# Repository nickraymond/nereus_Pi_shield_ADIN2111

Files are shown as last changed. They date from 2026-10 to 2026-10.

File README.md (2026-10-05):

# nereus_Pi_shield_ADIN2111

A Raspberry Pi Zero 2W shield built from a copy of the Sofar Bristlemouth mote:
ADIN2111 two-port 10BASE-T1L with PoDL, powered from the bus, 5 V for the Pi,
a 24 V payload port, and the Sofar mote's power path unchanged except the payload load switch (D17) (~20 W absolute
max, 890 mA per port inductor at 24 V; 50 W in a later revision). Potted.

Claude Code does the schematic capture, up to a design-review package. Nick
reviews, lays out, routes and brings up the board.

## Folders

```
nereus_Pi_shield_ADIN2111/   live KiCad 9 project — open the .kicad_pro
docs/                        spec, tracker, design log, power-path study
docs/design-review/          ERC, netlist, PDF and the review package
KiCAD_reference_designs/     BM mote 000639-AB, UrchinCam (read-only)
Archive/                     earlier iterations, junction fix (read-only)
pi-shield-checklist.html     shared visual view of docs/TRACKER.md (open in a browser)
```

## Working on it

- Agents: start with `CLAUDE.md`, then `/agent-entry`.
- People: `docs/TRACKER.md` shows where things stand; `docs/SPEC.md` says what
  we're building and why.
- Close KiCad before an agent edits the project.

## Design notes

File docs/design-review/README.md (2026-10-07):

# Design-review package — nereus Pi shield (ADIN2111)

**Board:** nereus_Pi_shield_ADIN2111 · **Part number:** PCB-000001-AA · **Rev:** AA
**Based on:** Sofar Bristlemouth mote 000639-AB (KiCad copy of the Altium design), PoDL / ADIN2111 front end and power
path kept as Sofar designed them (DESIGN D12). **Package assembled:** 2026-10-06 (Sprint S6).

## Status at a glance

| Check | Result | Where |
|---|---|---|
| ERC | **0 errors**, 494 warnings (cosmetic import leftovers: 481 off-grid, 11 duplicate net names, 2 dangling wire ends on Sofar's PoDL sheet). 18 errors excluded, each with its reason | `erc_justifications.csv`, DESIGN "ERC / net-check results" |
| Connectivity vs the mote's copper | **51/51** copper nets match; 0 opens, 0 shorts. Every net touching a new part is listed | `netcheck.md` |
| BOM | 51 lines; Sofar's part, our planned part (with the reason) and backups side by side | `bom.csv` |
| Footprints | all 43 `Vault` footprints have a type and a courtyard; pads identical to the mote board | `footprints.md` |
| Schematic | rev AA, all 7 sheets; the tidy (S6.d) changed positions and text only, no connection | `schematic.pdf` |
| Independent review | every change reviewed by a separate read-only QE session before merging | `qe/` |

## Read in this order

| # | What | File |
|---|---|---|
| 1 | **What changed from Sofar's mote, and why** (one row per change) | `sofar_brief.md` |
| 2 | The schematic, all sheets (rev AA) | `schematic.pdf` |
| 3 | Every schematic edit, sprint by sprint | `changelog.md` |
| 4 | Connectivity check: kept nets vs the mote's copper, and every new net with its pins | `netcheck.md` |
| 5 | Pi header pin map (`~{…}` = active low, drawn with an overbar, D30); ADIN power-up order and back-power cases | `../DESIGN.md` → "Pi header pin map", "ADIN power and boot" |
| 6 | Power budget: bus power, 5 V converter, Pi supply, payload port | `power_budget.md` |
| 7 | BOM: `bom.pdf` to read (one row per line: Sofar's part, planned part and why, backups, sourcing; changed lines highlighted); `bom.csv` is the data (Value = Sofar's part, Planned = what we'd build with); lifecycle and stock check; alternates and the planned-part table | `bom.pdf`, `bom.csv`, `bom_lifecycle.md`, `bom_alternates.md` |
| 8 | Footprint types and courtyards (source of each) | `footprints.md` |
| 9 | ERC exclusions and their reasons | `erc_justifications.csv` |
| 10 | Decision log (D1–D29) | `../DESIGN.md` → "Decision log" |
| 11 | Open questions and proposed values (below) | `../SOFAR_QUESTIONS.md`, `../SPEC.md` → "Open questions" |
| 12 | QE review reports, sprint by sprint | `qe/S2.md` … `qe/S6.md` |

Note on the BOM's Mfr column: it mixes Sofar's spellings (e.g. "Yageo / Phycomp", "Wurth Elektronik") with the names in
our lifecycle table ("Yageo", "Würth Elektronik"), because Sofar's fields were left untouched (QE S6.a N1).

## Open questions and proposed values

**For Sofar** (`../SOFAR_QUESTIONS.md`, to send — Nick):
- **Q6** How the PoDL bus should connect to the threaded inserts MP1–MP4 (the front-side copper arc on 000639-AB).
- **Q7** D1's source: ST SMA6F33A is obsolete; is the Vishay SMA6F33A-M3/H your preferred replacement? (Planned in the BOM.)
- **Q2** Is R11 fitted on production motes? (Context only: R11 is DNP on the shield, D17.)
- **The planned parts** (10 BOM lines, `bom.csv` Planned columns): LCSC-stocked equivalents of parts LCSC doesn't stock.
  Nothing is adopted without your review (D26/D27).

**For the design review** (`../SPEC.md` → "Open questions"; the bring-up items below are from there too):
- Effective capacitance of C56/C57 (GRM21BR61C226ME44, 22 µF 16 V 0805) at 5 V DC bias: unmeasured; TI SLUSEF4A Eq. 14
  wants ≥ 22 µF effective.
- U10's input capacitance copies U5's (2.2 µF + 100 nF); TI SLUSEF4A §9.2.2.6 suggests ≥ 4.7 µF, its own Figure 9-1 uses
  2.2 µF. Field-proven on U5; U10 draws more input current.
- ADIN2111 power at 2.4 V p-p: the power budget carries a 0.30 W allowance at U5's input (ADI: 77 mW typical at 1.0 V
  p-p, dual supply) until the full datasheet is read.
- Murata's product pages list "undersea equipment" among applications they don't warrant for these consumer/industrial
  MLCCs; this applies equally to the mote's existing Murata parts (C29, C32, C33, …).

**For Nick (bring-up):**
- U10/L6/L1 heat: ΔTj ≈ 42–57 °C at the 1 A Pi target, indicative only (TI's RθJA is for comparison; potted RθJA
  unknown). Measure T_top at bring-up: Tj ≈ T_top + 9.3 °C/W · P_U10 (`power_budget.md` §3).
- Whether the Pi's data-port USB VBUS also feeds its 5 V rail is unconfirmed (not shown in the Zero 2 W reduced
  schematic; primary source needed). Until then the D14 bench rule stands: never connect a USB 5 V source to a
  bridged board's Pi.

**For Nick (layout and release):**
- J1's socket part number (height, once the board spacing is known).
- pcbnew → Tools → Update Footprints from Library, to pick up the S6.c types and courtyards (check its keep-text options).
- Grounding of the mounting holes MTG1–4 (no net, as on the mote).
- Not done in the tidy (more than minor): moving J1 so every interconnect sits on the right of the Top-Level sheet.
- Optional layout notes from the S6.d QE review: the two 3V3 symbols beside R26/R27 (2.54 mm apart) draw as one bar;
  the ADIN_VDDIO symbols under R3/R5 point down; MP1–MP4 reference text overlaps their bodies; TP5/TP7 labels crowd.
  U2/U3's courtyard is tight (0.05 mm past the 0.9 mm body; Sofar's outline).

## Regenerate

Every command below runs **from the repository root** (the folder holding `tools/` and `nereus_Pi_shield_ADIN2111/`).
From anywhere else kicad-cli answers "Schematic file does not exist or is not accessible". Change into your checkout
first, for example:

```bash
cd ~/Documents/GitHub/nereus_Pi_shield_ADIN2111
```

```bash
tools/check.sh
```

ERC, netlist, PDF (`out/`), BOM (`bom.csv`), ERC exclusions check, mid-wire check and the net check (`netcheck.md`).
Expected: `ERC messages: 494  Errors 0  Warnings 494`, `ercexclude: 18 errors justified, 0 unjustified, 0 stale / 0
missing exclusions`, `midwire: 0`, `netcheck: 51/51 … 0 opens, 0 shorts`, exit 0.

`schematic.pdf` and `bom.pdf` here are reviewed snapshots, not rebuilt by `check.sh`: rebuild them after any schematic or
BOM change (`bom.pdf`'s header carries the build date).

```bash
python3 tools/bompdf.py
```

```bash
/Applications/KiCad/KiCad.app/Contents/MacOS/kicad-cli sch export pdf -o docs/design-review/schematic.pdf nereus_Pi_shield_ADIN2111/nereus_Pi_shield_ADIN2111.kicad_sch
```

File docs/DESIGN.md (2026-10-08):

# DESIGN.md — Architecture & Decisions (as-built)

*What the schematic is and why. Agents append; never silently rewrite history.*
*Last updated: 2026-10-04*

## Sheet hierarchy

```
nereus_Pi_shield_ADIN2111.kicad_sch     root
└── BM_Mote_1_Master                    Top-Level
    ├── BM_Mote_1_Power                 U5 3.3 V buck, U6 1.8 V
    ├── BM_Mote_1_ADIN2111              ADIN2111 + AP22913 switches
    ├── BM_Mote_1_PoDL                  L1/L2 PoDL magnetics, D1/D2 protection
    │   └── BM_Mote_1_PowerMon          INA232 + R8 shunt
    └── BM_Mote_1_Load                  U11 24 V payload switch (TPS26621, D18)

Not referenced by any sheet (files deleted in S1): BM_Mote_1_Processor, BM_Mote_1_USB
```

## Key designs

**Pi header pin map** *(names since S6.g, D30: `~{…}` = active low, drawn with an overbar; as built, S5.b: each signal pin has a short stub and a same-name label on the Top-Level sheet; every other GPIO pin has a no-connect flag)*

| Pi pin | GPIO | Signal |
|---|---|---|
| 19 / 21 / 23 / 24 | 10 / 9 / 11 / 8 | ADIN_MOSI / ADIN_MISO / ADIN_SCK / **~{ADIN_CS}** (SPI chip select, active low; was ADIN_NSS) |
| 22 | 25 | **~{ADIN_INT}** (interrupt, active low) |
| 18 | 24 | **~{ADIN_RST}** (reset, active low; no external pull: ADIN internal pull-up; the Pi must drive GPIO24 low to hold reset, see boot order) |
| 16 | 23 | ADIN_PWR (active high; **R43 100 kΩ pull-down**, beside the ADIN block's HW_EN pin since S6.g: ADIN off unless the Pi drives it high, D21) |
| 3 / 5 | 2 / 3 | I2C1_SDA / I2C1_SCL (**R27/R26 4.7 kΩ to shield 3V3**, plus the Pi's own 1.8 kΩ to Pi 3V3, D20) |
| 36 | 16 | **PAYLOAD_EN** (was SW_EN; **high = payload on**; R42 pull-down keeps it off, D18); TP19 test pad on this net (R10 removed, D22) |
| 38 | 20 | **~{PAYLOAD_FAULT}** (was SW_FLAGB; U11 FLT, open drain, R35 pull-up: low = fault) |
| 2 / 4 | — | `PI_5V`, joined to `5V_PI` by JP1 (bridged link; cut to isolate, D14) |
| 6, 9, 14, 20, 25, 30, 34, 39 | — | GND |
| 1, 17 | — | **unconnected** (Pi 3.3 V) |

Reserved: 26 (CE1), 29, 32, 33 (motor). Free: 40 (SW_PGOOD dropped, D18). Avoid: 27, 28 (HAT EEPROM), 8, 10 (console).
All 17 unused GPIO pins (7, 8, 10–13, 15, 26–29, 31–33, 35, 37, 40) carry no-connect flags; remove the flag when a pin is used.
Pull resistors on these nets: S5.c (D20, D21). None on MISO (SDO is the SPI_CFG0 strap, see below) or on RST.

**ADIN power and boot** *(S5.c; Sofar's circuit, unchanged)*

U2 (1V8 → ADIN_AVDD) and U3 (3V3 → ADIN_VDDIO), both AP22913, share one ON net, ADIN_PWR (TP8). Sofar's sheet note:
the load switches cut ADIN power for "<10mW mote operation". ADIN_VDDIO ≈ 3.32 V when on (U5: 0.6 V × (1 + 100/22.1);
U3 ≈ 56 mΩ), 0 V when off (U3 output discharge). The ADIN needs no supply order and holds itself in reset until its
supplies are good (ADIN2111 Rev. B Table 3 note, "Power-On Reset").

Hardware configuration straps, read at power-up / reset release (Table 8, Tables 18–22; all on ADIN_VDDIO or GND, so
only valid with the ADIN powered):

| ADIN pin | Chip default (internal pull) | Sofar's resistor (overrides) | Reads | Result |
|---|---|---|---|---|
| 19 P1_LED_0 / SPI_CFG1 | pull-up → 1 | R2 4.7 kΩ to GND | 0 | with SPI_CFG0 = 0: OPEN Alliance SPI with protection (Table 22) |
| 43 SDO / SPI_CFG0 | pull-down → 0 | none | 0 | (Pi GPIO9's default pull-down agrees) |
| 41 TEST_0 / P1_SWPD_EN | pull-down → 0 (port 1 asleep) | R6 4.7 kΩ to ADIN_VDDIO | 1 | port 1 active after reset, links up |
| 47 P2_LED_0 / P2_SWPD_EN | pull-up → 1 (port 2 active) | R4 4.7 kΩ to GND | 0 | port 2 in software power-down |
| 21 / 48 Px_LED_1 / Px_TX2P4_EN | pull-down → 0 (2.4 V p-p allowed) | R3 / R5 4.7 kΩ to ADIN_VDDIO | 1 | 1.0 V p-p only, locked (pins 21 / 48 also drive D9 / D10, D25). **Required**: AVDD is 1.8 V, and 2.4 V p-p needs 3.3 V AVDD_H "otherwise, the device cannot start up" |
| 39 INT | pull-up | R1 1.5 kΩ to ADIN_VDDIO | — | the datasheet requires 1.5 kΩ to VDDIO |
| 20 RESET | pull-up | none | — | may float; hold low > 10 µs to reset; < 1 µs pulses ignored |

**Boot order (Pi software, D21):**
1. Firmware, before the kernel: `config.txt` lines `gpio=24=op,dl` (drive ADIN_RST low) and `gpio=23=op,dh` (drive
   ADIN_PWR high). Firmware applies these a few seconds after power-up (the ADIN is held off by R43 until then), and the
   kernel or user space can still change the pins later
   (Raspberry Pi documentation, config.txt "GPIO control"). GPIO24 must be **driven** low: once ADIN_VDDIO is up, the
   ADIN's internal RESET pull-up fights the Pi's weak default pull-down (neither value is published), so the default
   alone doesn't hold reset (QE S5.c F1).
2. Wait ≥ 40 ms (supply ramp, Table 3).
3. Release ADIN_RST (drive GPIO24 high, or a > 10 µs low pulse later for a deliberate reset).
4. Wait for INT to go low. It asserts after any reset; SPI is accessible ≤ 90 ms after RESET is released ("Hardware Reset").
5. Configure over SPI.

Even if step 1 is missed, the ADIN's power-on reset resets it when ADIN_PWR comes up, and the straps read correctly
(Pi GPIO9's default pull-down agrees with SDO's). The software then issues a deliberate RST pulse after the SPI driver
loads.

**Rule:** never leave CS, RST, SCK or MOSI high while ADIN_PWR is off. The ADIN's SPI/RESET/LED pins are rated −0.3 V to
VDDIO + 0.3 V (Table 5), so a high pin back-powers the unpowered chip through its clamps. U3's reverse blocking keeps
this off the shield's 3V3, but not off ADIN_VDDIO. Power the ADIN early in boot, before the SPI driver loads (CS idles
high), with the `config.txt` lines in step 1, and keep it on while SPI0 is enabled (Option 1, Nick 2026-10-05; no series
resistors). If the ADIN is ever switched off at runtime, drive CS, RST, SCK and MOSI low first.

**Back-power cases** (Pi 3V3 and shield 3V3 are separate rails; they only differ when JP1 is cut):

| Case | Path | Size | Handling |
|---|---|---|---|
| Pi booting, ADIN off | GPIO8 (CE0) defaults to pull-up (BCM2835 §6.2) → ADIN CS clamp | weak internal pull (value not given in the BCM2835 manual): small | power the ADIN early (rule above) |
| Pi running, ADIN off | spidev idles CS high, driven | mA-level through the clamp | not allowed by the rule |
| Pi off, shield on | INT: R1 1.5 kΩ from ADIN_VDDIO into GPIO25 | ≈ 1.8 mA if the ADIN were on | R43 keeps the ADIN off when the Pi doesn't drive GPIO23 |
| Pi off, shield on | R26/R27 4.7 kΩ into GPIO2/3; R35 100 kΩ into GPIO20 | ≈ 0.6 mA / line; ≈ 33 µA | accepted (small); only with JP1 cut |
| Pi on, shield off | the Pi's 1.8 kΩ I²C pull-ups into U4 (INA232) | — | exists without R26/R27; only with JP1 cut |

**Sheet layout rule (Nick, 2026-10-06; revised 2026-10-07):** a connector is drawn beside the circuit that drives it,
wired to it: J5 (payload power) sits against the Load Switch block on the VBUS_OUT wire. Placement on the right of the
Top-Level sheet (PoDL inserts MP1–MP4) matters less than that.

**Label rules:** labels copied with a block get a new prefix (`3V3_*` → `5V_*`);
two local labels with the same name silently join their nets.

**Net-check method** (`tools/netcheck.py`, run by `tools/check.sh`):
- **Truth:** pad-to-net assignments in the mote board
  `KiCAD_reference_designs/20250409_BM_Mote_000639-AB/BM_Mote_000639-AB.kicad_pcb`
  (read-only).
- **Candidate:** the kicadsexpr netlist exported from our schematic.
- **Compare connectivity, not names** (the import renamed nets). Only parts
  present in both are compared; nodes are `REF.PIN` = `REF.PAD`.
- **Reports:** opens (a copper net split across schematic nets), shorts (a
  schematic net joining copper nets), unpaired pins/pads on shared parts,
  removed and new parts. Exit 0 only if there are no opens, shorts or unpaired pins.
- **Validated:** unit tests on fixtures; the TP22→VBUS open was confirmed by hand
  in both files; the untouched reference schematic shows 38 opens against its
  own copper, so the opens come from the import, not the tool.
- ERC reports aren't deterministic run to run (same violations, different
  example labels), so compare ERC by counts and types.
- Parts scheduled for deletion are listed in `docs/design-review/excluded_parts.txt`
  and treated as already removed.
- `tools/midwire.py` (also run by check.sh) flags any pin whose end sits mid-wire;
  KiCad needs the wire split there, a junction alone isn't enough (measured).
- Copper can't verify nets whose other end was a removed part: e.g. the ADIN SPI
  went to the STM32. Those are checked from the netlist: `ADIN_MISO/MOSI/SCK/NSS/RST/INT`
  each reach the Top-Level sheet from U1 (verified 2026-10-05), ready for S5.

## Decision log

| # | Date | Decision | Rationale |
|---|---|---|---|
| D1 | 2026-10-04 | Agents own schematic capture up to the design-review package; Nick owns review, board and bring-up | Clear boundary; the board is Nick's |
| D2 | 2026-10-04 | TRACKER.md is the single source of truth. `pi-shield-checklist.html` is the shared visual view of it: agents keep it in sync every PR, and finished work is marked in its data (`done`), not only in the browser (revised same day at Nick's request) | Nick and colleagues use the HTML; ticks stored only in a browser are invisible to agents and other viewers |
| D3 | 2026-10-04 | Live project folder is `nereus_Pi_shield_ADIN2111/` (renamed from `_002` in S0.1) | One stable name; git keeps the history |
| D4 | 2026-10-04 | 5 V for the Pi: copy of the LMR51430 (U5) set to 5 V, fed from VBUS | Reuses a proven block (checklist Option A) |
| D5 | 2026-10-04 | **Superseded by D14.** 5V_PI reaches Pi pins 2/4 through an open solder jumper | Must stay open whenever the Pi has its own USB power |
| D6 | 2026-10-04 | Plain 2×20 female socket header, no stacking header | Shield plugs onto the Pi's male pins |
| D7 | 2026-10-04 | **Superseded by D12 for this board.** Target ~50 W with two-winding PoDL inductors, one per port; selection in POWER_PATH.md | Commercial mote magnetics limit it to ~20 W |
| D8 | 2026-10-04 | **Superseded by D12 for this board.** Rating (P1): ~50 W **absolute max** = 2.083 A per port inductor at 24 V, defined like Sofar's 20 W. Margin comes from choosing larger magnetics (MSD1514-class, fit pending) | Same basis as the mote's rating; potting removes thermal headroom |
| D9 | 2026-10-04 | Electronics are potted. Sofar-vetted parts are kept as-is (including the C22/C23 electrolytics). Newly sourced parts: no aluminium electrolytics, no PPTCs, other risky parts flagged (SPEC constraint 8) | Vetted design is trusted; electrolytics vent or deform under pressure; PPTC trip behaviour changes when encapsulated |
| D10 | 2026-10-05 | Every PR gets an independent, read-only Quality Engineer review in a separate Code session, one standing session per sprint (never a sub-agent; `.claude/agents/quality-engineer.md`, Opus 5.5, high effort) before Nick's KiCad review; merge needs both | A second pair of eyes on every claim; QE never edits, so it can't collide with Nick or the design agent |
| D11 | 2026-10-05 | The shield provides I2C pull-ups on I2C1_SDA/SCL (S5), reusing the mote's R26/R27: 4.7 kΩ ERJ-2RKF4701X to 3V3 | Nick: the Pi needs them; the mote's pull-ups were on the removed STM32 sheet |
| D12 | 2026-10-05 | This first board keeps the Sofar mote's power path unchanged (exception: the payload load switch, D17): L1/L2 stay SRF1260-101M and every other path part stays as vetted. Rating = the mote's ~20 W absolute max, 890 mA per port inductor at 24 V (Sofar, More Power Delivery). 50 W (D7/D8, POWER_PATH.md) is deferred until after this board is in production | Nick: reduce technical risk on the first board and reuse Sofar's work, so the board is a new layout of proven hardware. The design has been in the field for years, and Nick already powers his cameras from the mote's power electronics, so it's known to work; no derating question goes to Sofar. The 50 W revision gets scoped with the future motor load |
| D13 | 2026-10-05 | 5 V for the Pi (S4.a): U10 LMR51430YDDCR, a copy of U5 with new refs above the mote board's highest. Changed from U5: R38 = 13.7 kΩ (5 V, TI's own example), output caps C56/C57 22 µF 16 V 0805 + C58 4.7 µF 10 V 0402 (U5's are 6.3 V). Kept: L6 = PA5432.822NLT 8.2 µH (same as L3), input caps, bootstrap cap, its own 1.82 MΩ/200 kΩ enable divider | Reuse the proven block (D4, D12). Ripple (16–32 V in, nominal L): 8.2 µH gives 12.7–15.6 % of 3 A at 5 V, below TI's 20–60 % guideline (§9.2.2.4) but above the 9.7–10.9 % the field-proven 3.3 V converter runs at; Nick chose it over 4.7 µH. TI Table 9-2 (1.1 MHz) suggests 3.3 µH for 5 V and 2.2 µH for 3.3 V, so L6 is 2.5× and U5's L3 3.7× TI's value; low ripple weakens the peak-current comparator's signal-to-noise (§9.2.2.4), so bring-up checks the SW node for jitter at full and light load. Output capacitance from TI Eq. 14 (≥ 22 µF effective at 1.1 MHz, 1.5 A step, 5 %). Vout 4.98 V nominal, 4.82–5.14 V worst case (VREF ±1.5 %, 1 % resistors). Own enable divider keeps the 5 V watchdog idea open |
| D14 | 2026-10-05 | The shield powers the Pi by default. JP1, a bridged link (project footprint `nereus:SolderJumper-2_R1210_Bridged_NetTie`: Sofar R11's 1210 pads joined by a 1.0 mm copper net tie, no BOM part), joins `5V_PI` to `PI_5V` (Pi pins 2/4). Battery- or USB-powered Pi: cut the bridge before potting; reconnect by fitting a 0 Ω 1210 (CRCW12100000Z0EA, as R11). Revises D5 | Nick: the usual case is the shield as the Pi's only supply; no DNP part wanted. Copper is repeatable at fab with no assembly step; a 0 Ω resistor fits the pads if a cut ever needs undoing. Bridge current rating checked in S4.c. **Known risk, accepted with a bench rule (QE S4.b F1; Nick re-confirmed 2026-10-05):** with JP1 bridged, any other 5 V on the Pi's rail is tied to 5V_PI. The Pi Zero 2 W's power micro-USB feeds its 5 V rail directly, as do header pins 2/4 (Raspberry Pi Zero 2 W reduced schematic, J1/J8); the data port isn't shown there (unconfirmed). With the shield unpowered, that 5 V back-feeds through L6 and U10's high-side MOSFET body diode onto VBUS (≈ 4.4 V on the bus side via L1, and on the payload port via R11 as captured, or through U9 when SW_EN has it on once R11 is DNP per D17); with the shield powered, the two supplies fight. Mitigation (Nick): procedure only — on a bridged board never connect a USB 5 V *source* to the Pi (charger, PC/laptop host, self-powered hub that back-feeds), shield powered or not; USB peripherals the Pi powers are fine (they count toward the S4.c budget). Hardware guard left for a later revision |
| D15 | 2026-10-05 | Continuous Pi load target ≤ 1 A at 5V_PI (Pi + its USB devices), short peaks above; generous copper at U10; measure U10's case temperature at bring-up (P-S4c-1) | U10's temperature is the binding limit: ≈ 42–57 °C junction rise at 1 A vs 90–121 °C at 2 A (indicative, `docs/design-review/power_budget.md` §3). Typical Pi + camera + GPIO ≈ 650 mA (RPi docs) |
| D16 | 2026-10-05 | R38 stays 13.7 kΩ: U10 at 4.98 V nominal, 4.82–5.14 V worst case (P-S4c-2) | Every corner inside USB's 4.75–5.25 V for the Pi's peripherals; no cable/fuse drop to the Pi's rail; the Zero range has no undervoltage detector (RPi docs). 13.5 kΩ (5.04 V) is the drop-in fix if bring-up shows 5V_PI < 4.75 V at J1 |
| D17 | 2026-10-05 | Payload port: switched by the Pi (SW_EN) and current-limited by the load switch (R34 → ≈ 0.74 A typical, FPF2700 datasheet), with **R11 DNP** (S5). As captured from Sofar, R11 (0 Ω across U9) was fitted, which bypassed U9 entirely. U9 FPF2700MX is obsolete, so S5 replaces it with a part JLC can source, matching the function (36 V class, ≈ 0.74 A limit, active-low ON, FLAGB/PGOOD) | Amends SPEC constraint 7 (Nick, 2026-10-05). Nick: payloads are small devices (e.g. another sensor to switch on), none runs near the limit; he wants the switch and limit active (QE S4.c F4 found R11 fitted). Digi-Key lists FPF2700MX as no longer manufactured (2026-10-05) |
| D18 | 2026-10-05 | U9 FPF2700MX → **U11 TI TPS26621DRCR** (JLC C1848341; TI status ACTIVE). R34 → 9.09 kΩ (I_LIM = 6.636/R = 0.73 A, SLVSDT4F Eq. 3; ≈ −6/+4 %); new R41 1 MΩ IN→UVLO and OVP→GND (UV/OV cut-off unused, Fig. 10-14); dVdT open (internal 24 V/660 µs ramp). SHDN is active low, so the SW_ON pull-up R32 becomes a **10 kΩ pull-down R42** (RMCF0402FT10K0): worst-case SHDN source current 10 µA → 0.1 V, below V(SHUTF) min 0.9 V; the Pi's 3.3 V high is above V(SHUTR) max 1.8 V (SLVSDT4F §7.5; 100 kΩ had no worst-case margin, QE S5.a F2). Payload off by default, Pi drives SW_EN high. No PGOOD: SW_PGOOD, R33, TP34 and the sheet pin removed (Pi pin 40 freed); FLT keeps SW_FLAGB. R11 DNP (D17). **RTN = GND** (with GND and the PowerPAD): reverse-input protection isn't used — VBUS is internal behind D1, and the FPF2700 had none (§12.1 allows it; §10.4's "don't" applies only when reverse protection is wanted). R_ON 478 mΩ vs FPF2700's 88 mΩ: ≈ 0.35 V drop and ≈ 0.25 W at 0.73 A. Hard short / output caps (closes QE S4.c N6): C_OUT ≥ 0.01 µF (ROC), start-up into a short is current-limited (Fig. 9-12), fast-trip 1.6 A typ / 220 ns, thermal shutdown 155 °C with 512 ms auto-retry, D3 is TI's recommended output Schottky (§11). Floating dVdT ramps at ≈ 36 V/ms, so a payload input capacitance above ≈ 20 µF charges in current limit (≈ C·V/0.73 A, e.g. 4.4 ms for 100 µF at 32 V, well inside tCL(dly) 512 ms); auto-retry only if thermal shutdown trips. New project symbol `nereus:TPS26621DRCR`; footprint `Package_SON:Texas_DRC0010J` (stock) | Nick: JLC-sourceable replacement for the obsolete part, payload switched and limited; the three sub-choices (part, pull-down, drop PGOOD) approved 2026-10-05. Tracked for Sofar in `docs/design-review/sofar_brief.md` |
| D19 | 2026-10-05 | Footprints from the mote come from a project library `mote.pretty`, nickname **`Vault`** (matching the board's `Vault:` IDs): the 43 footprints the schematic uses, extracted read-only from the reference board with KiCad's own pcbnew 9.0.6 (`tools/fpextract.py`; back-side instances flipped to the front, position/rotation zeroed, nets cleared). Every bare footprint field is now `Vault:<name>`; new parts keep their stock/`nereus` libraries | With IDs identical to the board's, Nick's F8 re-links by reference without replacing any kept footprint. `fpextract --verify` checks every board instance: pad numbers, sizes, pad-to-pad distances and exact pad centres after placing the library footprint like the instance, flipped for back-side ones (0 problems; it catches a moved, resized or mirrored pad set). **Expect ≈ 58 graphics-only "footprint doesn't match library" DRC warnings** (QE S4.d F1): the Altium import varies Fab/User-layer graphics and text between instances of one footprint, and Hole_M3's keepouts serialise differently; pads are identical. Don't run "Update Footprints from Library" on kept parts unless graphics-only changes are acceptable. The import also left no SMD/THT attributes and no courtyards (pre-existing, for layout/S6) |
| D20 | 2026-10-05 | I²C pull-ups **fitted**: R26 (I2C1_SCL) and R27 (I2C1_SDA) = Sofar's 4.7 kΩ ERJ-2RKF4701X to the shield's 3V3, same refs, footprint (`Vault:RESC1005X40X25LL05T05`) and fields as on the mote's Processor sheet, so netcheck verifies them against the copper. With the Pi's own pull-ups (Pi Zero 2 W reduced schematic: R23/R24 1.8 kΩ 1 % to the Pi's 3V3 on GPIO2/3) the bus sees ≈ 1.30 kΩ: ≥ R_P(min) 967 Ω at 3.3 V (V_OL ≤ 0.4 V at 3 mA, standard/fast mode; TI SLVA689 Table 1 / Eq. 1), ≈ 2.2 mA at V_OL. Rise time at 1.30 kΩ allows ≤ 272 pF (fast mode, SLVA689 Eq. 2) | Nick: the shield should work with another MCU on the bench, not only the Pi. Back-power with JP1 cut: ≈ 0.6 mA per line into an unpowered Pi (accepted) |
| D21 | 2026-10-05 | **R43 100 kΩ pull-down on ADIN_PWR** (RMCF0402FT100K, R21's part). AP22913 ON has no internal pull-down: input leakage ≤ 1 µA, so R43 holds ≤ 0.1 V, below V_IL 0.4 V (V_IN 1.4–3.6 V); the Pi's 3.3 V high clears V_IH 1.1 V at 33 µA (Diodes DS41203 Rev. 6-2). No resistor on ADIN_RST (the ADIN has an internal pull-up; floating is allowed, Rev. B Table 8) or MISO (SPI_CFG0 strap). CS/RST back-power handled in Pi software, not hardware (Option 1): boot order and rule in "ADIN power and boot" | The mote relied on STM32 firmware to drive ADIN_PWR; R43 keeps the ADIN off whenever the Pi is booting, absent or off, so its straps are read only on a deliberate power-up and INT can't feed an unpowered Pi. Option 1 chosen by Nick 2026-10-05 (Option 2, 1 kΩ series on CS/RST, not taken) |
| D22 | 2026-10-05 | **R10 removed**; TP19 tied straight to SW_EN. On the mote R10 (0 Ω) linked STM32 pin 19 (and, via R9, the mezzanine) to SW_ON, choosing the load-switch controller; R9 went with the mezzanine in S2 | Nick: the Pi header is the only controller; fewer parts, simpler to build. TP19 kept as a bench pad to probe or force SW_EN. **Layout:** route TP19 to SW_EN where R10's footprint was; netcheck can't check this (QE S5.c N1) |
| D23 | 2026-10-05 | **Payload power out on J5, JST GH 2-pin** SM02B-GHS-TB (LCSC C189893), stock footprint `Connector_JST:JST_GH_SM02B-GHS-TB_1x02-1MP_P1.25mm_Horizontal`: pin 1 VBUS_OUT, pin 2 GND (the UrchinCam's J4/J6 order: pin 1 power, pin 2 GND). Rated 1.0 A per contact with AWG #26, 50 V, −40…+105 °C (JST GH datasheet): ≥ the 890 mA requirement (D12) and above U11's ≈ 0.73 A limit; 50 V > the 16–32 V bus. Symbol copied from the UrchinCam into `nereus.kicad_sym` (`nereus:SM02B-GHS`); placed on the **right side of the Top-Level sheet, under the PoDL inserts MP1–MP4**, with a note. **Stock:** LCSC showed C189893 out of stock on 2026-10-06 (QE S5.d F1); recheck in S5.e. **Layout:** silkscreen "VBUS 16–32 V" next to J5 — the same GH 2-pin carries 5 V on the UrchinCam (J6), so a 5 V payload's cable would fit (QE S5.d N2) | On the mote, VBUS_OUT left through mezzanine P1 pins 14/16/18 (removed in S2), so the payload had no exit. Nick: GH series, part and footprint from his UrchinCam design; the 2-pin variant for now (4-pin with paired contacts considered); on the Top-Level sheet for awareness. Mate the cable before potting |
| D24 | 2026-10-06 | **Vault footprint fixes, 3D only** (pads unchanged, so D19's exact-copy check still holds: `fpextract --verify` 0 problems). (1) PoDL threaded inserts MP1–MP4 (Würth 78614015360, WA-SMSI M3; schematic MP1 BM1_P, MP2 BM1_N, MP3 BM2_P, MP4 BM2_N): the embedded model `FST-000629.STEP` had `opacity 0` (invisible); now 1. Model geometry: M3 bore Ø3.0, body Ø6.0 × **1.5 mm** above the board, Ø4.2 × 1.4 mm locating spigot into the Ø4.4 hole. (2) KiCad stock 3D models on footprints that had none: CAPC1608X100X20ML10 (C31) → C_0603_1608Metric; CAPC2013X145X50LL20T25 (C19, C27) → C_0805_2012Metric; CRCW08057R50FKEAHP (R15, R16) → R_0805_2012Metric; RESC1005X40X25LL05T10 (R22, R34, R40), …ML05T10 (R1) and …NL05T10 (R10's, unused, kept for a refit) → R_0402_1005Metric; RESC1608X60X55ML20T10 (R8) → R_0603_1608Metric. All offset 0, rotation 0. **Orientation:** all non-polarised (MLCCs, chip resistors), pads at ±x about the origin, stock models centred with the long axis on x (STEP extents), so model and pads line up. **Heights are generic** (QE S5.g N1): C_0805 1.25 mm vs the footprint's 1.45 mm class, C_0603 0.8 mm vs 1.0 mm; use datasheet heights for potting-depth checks. U2/U3 (AP22913 X1-WLB0909-4, 0.9 mm, 0.5 mm pitch) get **no model**: KiCad has none; footprint and pin map match the datasheet top view (A1 VOUT pin-1 top-left, A2 VIN, B1 GND, B2 ON). **Insert contact (no change, Sofar Q6):** on the mote the inserts sit on B.Cu with unnumbered, net-less pads; the bus reaches each insert position through a **front F.Cu C-shaped arc** on the bus track (~290°, 1.2 mm wide, radius 3.03 mm around the Ø4.4 hole), presumably under the screwed lug (no hardware in the files). So schematic pin 1 of MP1–MP4 has no matching pad, as on Sofar's files. How the new layout should make this contact (copy the ring, net the insert pad, or a ring pad in the footprint) is asked of Sofar first | Nick (2026-10-06): fix the inserts' invisible model; keep R10's footprint; stock models for the others, orientation checked; don't change the insert contact yet, ask Sofar (Q6). An earlier draft numbered the insert pad "1" on the wrong premise that the bus feed went through it (QE S5.g F1); reverted. **Confirmed by Nick in KiCad's 3D viewer (2026-10-06):** the insert model sits body-up on its pad with the spigot in the hole, and the stock models check out (the model is drawn on its Y axis, rotated −90° about X) |
| D25 | 2026-10-06 | **ADIN status LEDs** (ADIN sheet). ADIN_VDDIO → **JP2** (bridged net tie, JP1's footprint `nereus:SolderJumper-2_R1210_Bridged_NetTie`, not in BOM; cut to disable both) → net ADIN_LED_VDD → R44 1.5 kΩ → **D8 red KT-0603R** (Hubei KENTO, LCSC C2286) → GND: lit whenever the ADIN is powered. ADIN_LED_VDD → R45 1.5 kΩ → **D9 yellow-green KT-0603YG** (KENTO, C2289) → ADIN pin 21 (P1_LED_1), active low per ADIN2111 Rev. B Fig. 24, with R3 (4.7 kΩ to ADIN_VDDIO) as the recommended pull-up, so the P1_TX2P4_EN strap still reads high (1.0 V p-p, required with AVDD at 1.8 V). **Port 2 twin (Nick, 2026-10-06):** ADIN_LED_VDD → R46 1.5 kΩ → **D10 KT-0603YG** → ADIN pin 48 (P2_LED_1), with Sofar's R5 as its pull-up (P2_TX2P4_EN strap unchanged); port 2 is in software power-down after reset (R4 strap), so D10 stays dark until the Pi wakes port 2 and enables its LED_1. In a daisy chain D9 and D10 both blink (the internal switch forwards pass-through frames); as a leaf only the cabled port's LED does. Resistors reuse R1's RC0402FR-071K5L. Currents ≈ (3.3 − ~1.9) / 1.5 k ≈ 0.9 mA red, (3.3 − ~2.0 − ~0.1) / 1.5 k ≈ 0.8 mA green (pin sinks up to 8 mA, Table 1): ≈ 6 mW for D8 + D9; while D9 (or D10) is lit its pin also sinks R3's (R5's) ≈ 0.7 mA, so ≈ 1.5 mA at the pin (inside Table 1's 2 mA V_OL test point): ≈ 8 mW with port 1 activity, ≈ 13 mW with both ports active. The green is ≈ 10× dimmer (30–42 mcd vs 300 mcd at 20 mA, scaled linearly; indicative). The feed is ADIN_VDDIO, never the always-on 3V3 (an LED from 3V3 would back-power pins 21 / 48 with the ADIN off); cutting JP2 doesn't touch the straps. LED_1 is disabled by default: the Pi enables it over SPI (DIGIO_LED1_PINMUX, LED1_EN; polarity autosense sees R3 → active low; default function TXRX_ACTIVITY, Table 15). Symbols `Device:LED` (pin 1 K, pin 2 A), footprint `LED_SMD:LED_0603_1608Metric` (pad 1 = cathode); KENTO marks the cathode green (KT-0603R spec sheet). R3 and R5 were redrawn in the LED group (connections unchanged) and U1 pins 21 / 48 got stubs + labels `ADIN_P1_LED1` / `ADIN_P2_LED1` | Nick (2026-10-05/06): red "ADIN powered" + green link/activity, one shared cut jumper to save power, option (a) both 1.5 kΩ. Not pin 19 (P1_LED_0/SPI_CFG1: "use without LED" in OPEN Alliance mode). Not KT-0603G (3.1 V emerald green: too little headroom from 3.3 V). Open: visible after potting? (if not, cut JP2 before potting) |
| D26 | 2026-10-06 | **Sourcing policy for the first build (20 boards).** Critical parts are bought as specified through **JLC global sourcing**: U1, U2/U3, L3/L6, Y1, D1–D3, MP1–MP4, J5 (D1 via Sofar's listed second source Vishay SMA6F33A-M3/H, pending Sofar Q7). Passives keep the specified part on the schematic; generic, pin-compatible, LCSC-stocked alternates are recorded as hidden `ALT…` fields beside it (S5.h) as proposals for Sofar's design review, **at most 3 per part, the best by match and availability** (Nick, 2026-10-06: don't bog reviewers down; Sofar's own listed alternates, e.g. R8's 7, stay in their original fields, outside the BOM). Adopting an alternate for a Sofar part needs constraint 8 (and 7 for power-path parts) amended; bespoke PoDL/power-path parts (R8, R15/R16, C22/C23) are marked "Sofar review". **For the first build every flagged passive is also bought exact via JLC global sourcing** (or consigned) until an alternate is approved, so the order can be placed (**amended by D27**: the first build buys the planned parts after Sofar's review) | Nick: treat it as a design review so Sofar's engineers can weigh in; JLC buys the critical parts, we do the legwork on resistors and capacitors. QE S5.e F1: substitutions of Sofar parts are not allowed under constraints 7/8 without an amendment |
| D27 | 2026-10-06 | **Planned part per BOM line** (S5.i). Every purchased part carries hidden `PLANNED MPN/MFR/LCSC` + `PLANNED NOTE` (why): the part we intend to build with at JLC, beside Sofar's specified part (`Value`, unchanged), so Sofar reviews one diff column. 10 lines change (R34, R20/R39, R21/R35/R37/R43, C31, C17/C26, C21, C16/C18/C24/C25, C19/C27, R14/R18 to LCSC-stocked equivalents; D1 to Sofar's listed Vishay second source); J1 TBD; everything else planned as specified, with its LCSC number. R8 stays as specified: ROHM PMR03's 0.35 mm electrodes fit the UR73D1J pads (0.55 mm electrodes) but ROHM gives no land pattern and the pads reach 0.35 mm under its body. The **first build buys the planned parts after Sofar's review** (amends D26's "exact until approved"); ALT1/ALT2 stay as backups. View "Sofar review (planned parts)" = `bom.csv` | Nick: a single column for Sofar to check the diff, with the why; "your chance to replace the part with what we should use" |
| D28 | 2026-10-06 | **ERC clean by fix or justified exclusion** (S6.b). Title block: name = file name, rev AA, part number PCB-000001-AA (text variables + title-block rev). The 18 remaining errors (FID/MTG pins with no net on the mote board; regulator switch/bootstrap pins and inductor-fed rails the imported symbols type as power input; ADIN_VDDIO driven by U3's passive-typed VOUT) are KiCad ERC exclusions whose comment is the reason. Exclusion keys include the item's position, so `tools/ercexclude.py` regenerates them from `erc_justifications.csv` and `check.sh` fails if they go stale | Nick: S6 "ERC clean, or every remaining item justified"; Sofar's symbols and sheets left as they are (no PWR_FLAGs or pin-type edits) |
| D29 | 2026-10-06 | **Footprint type + courtyard for fab** (S6.c). All 43 `Vault` footprints get a type (KiCad stock conventions: `smd`; fiducial `smd exclude_from_bom`; test pad / mounting hole `exclude_from_pos_files exclude_from_bom`) and an F.CrtYd rectangle taken from Sofar's own outline where one exists (8 courtyard rectangles, 31 outer outlines on the Altium mechanical/User layers), else pads ∪ silk ∪ fab + 0.25 mm (4). Text inserts only; pads verified against the mote board. Board pick-up is Nick's (Update Footprints from Library). Record: `docs/design-review/footprints.md` | QE S4.d N3: JLC's SMD-only position file would drop untyped parts; no courtyard = no overlap DRC. Reuse Sofar's outlines before computing |
| D30 | 2026-10-07 | **Signal names show polarity** (S6.g). KiCad's overbar (`~{…}`) marks every active-low label: ~{ADIN_RST}, ~{ADIN_INT}, ~{ADIN_CS} (was ADIN_NSS), ~{ADIN_P1_LED1}, ~{ADIN_P2_LED1}. The payload switch's signals are named for what they do: SW_EN → **PAYLOAD_EN** (active high), SW_FLAGB → **~{PAYLOAD_FAULT}** (Load Switch sheet labels, hierarchical labels and sheet pins too; its internal SW_ON label joins PAYLOAD_EN). ADIN_PWR stays (active high). Pin connections unchanged | Nick: show active high / low on the schematic for debugging; "SW" clashed with the buck converters' SW (switch-node) pins; NSS/FLAGB already meant "not", so a bar on top would say it twice |
| D31 | 2026-10-07 | **Layout experiment 01 (S7)**: an agent (Fable 5.1, high effort) ports Sofar's mote copper onto the shield block by block, per `experiments/fable_layout_01/BRIEF.md`. **Scoped exception** to "no agent writes a `.kicad_pcb`" (CLAUDE.md, SPEC constraint 1, TRACKER rules 8/9): the run writes only its own board inside `experiments/fable_layout_01/` on branch `experiment/fable-layout-01`, never the live project, the reference designs or `Archive/`, and is never merged. **Mechanical envelope** (proposed as the target for the real layout): 46 × 65 mm (south edge may grow ≤ 2 mm), Pi Zero portrait under the shield (SD north, header east, camera south); 40-pin stacking header (socket below, tails up; the experiment's assumption: D6's plain socket stands until Nick picks J1); bus inserts MP1–MP4 down the west wall, port 2 north / port 1 south, 2 mm between rings and from the edge; PoDL inductor envelopes 15.5 × 15.5 mm + 2 mm (room for the 50 W MSD1514, POWER_PATH); payload J5 as Micro-Fit 3.0 2-pin right angle on the south edge facing south (**experiment only**: the live schematic keeps the JST GH until a separate change); 4 M3 housing holes outboard of the Pi's 4 M2.5 holes; status LEDs between the insert pairs; bottom-side parts ≤ 3 mm; Sofar's open items (R12/R13/R17/R19 fitted, plane slots and islands) copied as drawn. Later variant: OpenMV N6 in place of the Pi, same outline, camera looking out on the side opposite the inductors, staggered ≈ 4.2 mm east with L1 moved east | Nick: a bounded, known-good starting design should port better than a fresh layout; 20 W now, 50 W later, so the form factor is set for 50 W parts now; one housing for the Pi and N6 versions. Area check: top-side part envelopes fill 46 % of the usable top (Sofar's mote: 69 %), bottom 28 % (46 %); U1's 9.12 mm courtyard needs the west pocket between the insert pairs or the 2 mm growth |

## ERC / net-check results

| Date | Sprint | ERC errors / warnings | Net diff vs copper | Notes |
|---|---|---|---|---|
| 2026-10-04 | S0.1 | 90 / 578 before and after the rename | Netlist identical apart from the library path | Rename confirmed safe; not the S0.4 baseline |
| 2026-10-05 | S0.4 | 90 / 578 | 42/68 matched; **26 opens**, 0 shorts, 0 unpaired; 43 parts removed, 4 new | **Baseline.** Details in `docs/design-review/netcheck.md`. S1 target: 0 opens |
| 2026-10-05 | S1 | 65 / 590 | **53/53 matched, 0 opens, 0 shorts** (14 S2-deletion parts excluded); midwire 0 | Import fixed. Edits in `docs/design-review/changelog.md` |
| 2026-10-05 | S2 | 76 / 562 | 53/53, 0 opens, 0 shorts, **0 excluded**; J1 GND 8/8 on GND | Mezzanine gone, J1 placed. Errors −27 (12 TPs, 13 mezzanine labels, U5 VIN, U6 GND) / +38 (29 J1 pins, 8 I2C1/SCL/SDA labels now one-pin, J1.2) |
| 2026-10-05 | S3 | 76 / 562 | 53/53, 0 opens, 0 shorts, 0 excluded | No schematic change: power path kept as Sofar's (D12) |
| 2026-10-05 | S4.a | 78 / 629 | 53/53, 0 opens, 0 shorts, 0 excluded; 13 new parts; existing parts' connections identical | 5 V converter U10 (copy of U5): +2 errors (U10 CB/SW, like U5), +57 off-grid, +10 footprint links. New nets 5V_PI, 5V_Buck_SW, 5V_FB, 5V_UVLO, U10 CB; VBUS and GND gain only the new parts |
| 2026-10-05 | S4.b | 76 / 629 | 53/53, 0 opens, 0 shorts, 0 excluded; 1 new part (JP1); existing connections identical | JP1 bridged link 5V_PI → PI_5V (J1.2/J1.4), #FLG03 on PI_5V: −2 errors (J1 pin 2 not connected / not driven). midwire now sees J1's 40 pins (tool fix); still 0 |
| 2026-10-05 | S4.c | 76 / 629 | unchanged (docs only) | Power budget in `docs/design-review/power_budget.md`; D15 (Pi ≤ 1 A), D16 (R38 13.7 kΩ), D17 (payload switched/limited by U9, R11 DNP and U9 replacement in S5) |
| 2026-10-05 | S5.a | 74 / 626 | 50/50, 0 opens, 0 shorts, 0 excluded; kept parts' connections identical; U9/R32/R33/TP34 removed, U11/R41/R42 new | Load switch replaced (D18), R11 DNP: −2 errors (SW_PGOOD sheet pin, U9.8), −3 footprint-link warnings. Copper nets 53 → 50: three nets now hold only removed parts |
| 2026-10-05 | S4.d | 74 / 508 | 50/50, 0 opens, 0 shorts; netlist identical except 117 footprint fields (bare → `Vault:`) | Footprint library `Vault` (D19): −118 footprint-link warnings |
| 2026-10-05 | S5.b | 27 / 508 | 50/50, 0 opens, 0 shorts, 0 excluded; 11 nets each gain exactly one J1 pin, nothing else changes | Pi header wired: −29 pin_not_connected (28 J1 GPIO, SW_FLAGB sheet pin), −18 label_dangling (every one-pin I2C1/ADIN net now has the Pi pin). Net names: `Load Switch/SW_ON` → `SW_EN`, `Load Switch/SW_FLAGB` → `SW_FLAGB` (new top-level labels) |
| 2026-10-05 | S5.c | 27 / 508 | **51/51**, 0 opens, 0 shorts, 0 excluded; kept parts' connections identical except TP19 (D22). netcheck can't see TP19's move: its copper net is now TP19 alone, and copper SW_ON has no shared parts left | R26/R27 → I2C1_SCL/SDA + 3V3 (restoring their copper connections: copper nets 50 → 51), R43 ADIN_PWR → GND, R10 removed and TP19 moved onto SW_EN; nothing else changed. ERC counts and types unchanged |
| 2026-10-05 | S5.d | 27 / 508 | 51/51, 0 opens, 0 shorts, 0 excluded; J5 new | J5 added: VBUS_OUT + J5.1, GND + J5.2, nothing else. ERC counts and types unchanged |
| 2026-10-06 | S5.g | 27 / 508 | 51/51 (unchanged; library only) | 8 Vault footprints: 3D models only (D24), pads unchanged; `fpextract --verify` 0 problems |
| 2026-10-06 | S5.f | 27 / 504 | 51/51, 0 opens, 0 shorts, 0 excluded; R3 and R5 keep their connections | LEDs added (D25): new nets ADIN_LED_VDD, Net-(D8-A), Net-(D9-A), Net-(D10-A); the pin-21 / pin-48 nets are now named ADIN_P1_LED1 / ADIN_P2_LED1 and gain D9.K / D10.K; ADIN_VDDIO + JP2.1, GND + D8.K. ERC errors unchanged; warnings −4 (−3 each for the R3 and R5 groups now on grid, +1 each for the pin-21 / pin-48 stubs on U1's off-grid y) |
| 2026-10-06 | S5.e | 27 / 504 | unchanged (docs only) | Lifecycle + stock check of all 50 BOM parts (20 boards) → `docs/design-review/bom_lifecycle.md`; sourcing decisions open |
| 2026-10-06 | S5.h | 27 / 504 | 51/51, 0 opens, 0 shorts; netlist identical except 208 new hidden fields | BOM alternates (D26): `ALT…` + `SOURCING` fields on 24 flagged passives, `SOURCING` on the critical parts; tracked `bom.csv` from `tools/check.sh`. ERC items identical (only `multiple_net_names` cites a different copy of a repeated label; KiCad varies it run to run) |
| 2026-10-06 | S5.i | 27 / 504 | 51/51, 0 opens, 0 shorts; netlist identical except 428 new PLANNED fields and 19 SOURCING values | Planned parts (D27). ERC items identical with locations stripped |
| 2026-10-06 | S6.a | 27 / 504 | 51/51; netlist + 26 exclude_from_bom markers + MANUFACTURER fields only | BOM hygiene: TP/FID/MTG out of the BOM; Mfr filled; bom.csv 51 rows |
| 2026-10-06 | S6.b | **0** / 504 | 51/51; netlist: title-block revs + 3 text variables only | ERC clean (D28): 9 title-block errors fixed, 18 excluded with reasons; warnings item-for-item unchanged |
| 2026-10-06 | S6.c | 0 / 504 | 51/51 (unchanged; library only) | 43 Vault footprints: type + F.CrtYd added (D29); `fpextract --verify` 0 problems |
| 2026-10-06 | S6.d | 0 / 495 | 51/51; netlist identical (nets and pins) | Minor tidy: positions, text, notes, 9 dangling wire ends removed (warnings −9, no new items); #PWR34's exclusion key regenerated (reason unchanged) |
| 2026-10-06 | S6.e | 0 / 495 | 51/51; netlist identical except 5 Description values | Review package: README, schematic.pdf, new-nets table in netcheck.md; jumper descriptions fixed |
| 2026-10-07 | S6.g | 0 / 494 | 51/51; identical pin partition; 7 nets renamed (D30) | Presentation (Nick's list): blocks spaced with headers, title blocks, cover page; −3 warnings (2 off-grid wires of the old I²C runs, the SW_ON/SW_EN duplicate name), then +2 off-grid for the jogged stub on U1's off-grid pin 48 (QE N1 fix); 8 exclusion keys regenerated (moved parts), reasons unchanged |

**ERC errors after S6.b: 0** (D28). The 9 title-block `unresolved_variable` errors are fixed (text variables
`PCBPARTNAME` = nereus_Pi_shield_ADIN2111, `PCBPARTNUMBER` = PCB-000001-AA, `PROJECTREVISION` = AA; title-block rev AA on
all 7 sheets; Nick, 2026-10-06). The other 18 are KiCad ERC exclusions, each with its reason as the exclusion comment
(visible in KiCad's ERC dialog), generated from `docs/design-review/erc_justifications.csv` by `tools/ercexclude.py`:

| Type | # | What | Reason |
|---|---|---|---|
| pin_not_connected | 6 | FID1–6 hidden NC pin | fiducial copper mark, no net on the mote board |
| pin_not_connected | 4 | MTG1–4 pin | M3 plated hole, no net on the mote board |
| power_pin_not_driven | 1 | #PWR34 ADIN_VDDIO | driven by U3 VOUT, typed passive in the imported symbol |
| power_pin_not_driven | 5 | U5/U10 SW + CB, U6 SW | switch node / bootstrap, driven by the regulator itself |
| power_pin_not_driven | 2 | U6 VIN (3V3), VOS (1V8) | rails fed through inductors L3/L4 (passive pins) |

History: 27 errors after S5.b (pin_not_connected 10, power_pin_not_driven 8, unresolved_variable 9).
S2's PWR_FLAGs cleared U5 VIN (VBUS) and U6 GND.

Warnings (508) are cosmetic import leftovers: 485 off-grid endpoints (Altium
coordinates such as `…0.0022`; +2 in S2 where the trimmed I2C1 wires end on
off-grid label anchors; +57 in S4.a, the U10 copy keeps U5's off-grid offset),
0 footprint-library links (all 118 cleared in S4.d: every footprint field now
names a real library), 11 dangling wire ends
(all pre-existing), 12 duplicate net names (e.g. `PHY1_P`/`BM1_P` on the same wire).

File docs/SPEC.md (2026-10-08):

# SPEC.md — nereus_Pi_shield_ADIN2111

*What Nick wants. Stable reference — agents skim this; changes require Nick's approval.*
*Last updated: 2026-10-05*

## Goal

A Raspberry Pi Zero 2W shield made from a copy of the Sofar Bristlemouth mote
(000639-AB): ADIN2111 two-port 10BASE-T1L with PoDL, powered from the bus,
5 V for the Pi, a 24 V payload port, and **the mote's power path kept exactly
as Sofar built it (except the payload load switch, D17): ~20 W absolute max (890 mA
per port inductor at 24 V)**,
fully potted. This first board is a new layout of Sofar's vetted hardware; 50 W
waits for a later revision (DESIGN D12).
Done = a design-review package in `docs/design-review/` that Nick can review
with colleagues: ERC clean (or every item justified), kept nets matching the
mote's copper, every new net listed, schematic PDF, change log, BOM changes,
and open questions with datasheet citations. Nick owns layout from there.

## Background

The mote design was imported from Altium. The import left pins touching wire
midpoints unconnected; a 33-junction fix (`Archive/shield_junction_fix.zip`)
is applied. The STM32 processor and USB go away; the Pi drives the ADIN2111
over SPI. The commercial mote's PoDL magnetics limit it to ~20 W. Reaching
50 W means re-selecting the inductors and re-rating the whole power path; that
trade study is in `docs/POWER_PATH.md`, deferred until after this board is in
production (DESIGN D12).

## Inventory / environment

| Item | Location | Role |
|---|---|---|
| Live KiCad project | `nereus_Pi_shield_ADIN2111/` (renamed from `_002` in S0.1) | The design. The only thing agents edit. |
| Mote reference | `KiCAD_reference_designs/20250409_BM_Mote_000639-AB/` | Its `.kicad_pcb` copper is the truth for kept nets. Read-only. |
| UrchinCam | `KiCAD_reference_designs/UrchinCam-main/` | Prior art for a Pi shield. Read-only. |
| Archive | `Archive/` | Earlier iterations and the junction fix. Read-only. |
| KiCad 9.0.6 + kicad-cli | `/Applications/KiCad/KiCad.app/Contents/MacOS/kicad-cli` | ERC, netlist export, PDF export |
| Checklist | `pi-shield-checklist.html` | Shared visual view of TRACKER.md; agents keep it in sync. |
| Sofar 50 W/100 W guide | [Component Selection & Circuit Design Guide](https://manual.sofarocean.com/50W-100W-Bristlemouth-Mote-Component-Selection-Circuit-Design-Guide-f78b6124579340ba88ac8631a784dd88) | Inductor and power-path selection (from Evan) |
| Sofar BM power roadmap | [Bristlemouth Evolution — More Power Delivery](https://manual.sofarocean.com/bristlemouth-evolution-more-power-delivery) | Context, Jetpack and Dev Kit precedents (from Evan) |

## Confirmed facts (verified, with sources)

- kicad-cli 9.0.6 is installed at the path above. *(measured 2026-10-04)*
- PoDL magnetics today are L1 and L2, both Bourns SRF1260-101M.
  *(`BM_Mote_1_PoDL.kicad_sch`)*
- The 3.3 V buck is U5, an LMR51430YDDCR; the load switch is U11, a TPS26621DRCR
  (was U9 FPF2700MX, replaced in S5.a, D18); R34 is 9.09 kΩ (RC0402FR-079K09L, was
  374 kΩ); R11 is a 0 Ω 1210 jumper, DNP (D17); the R8 shunt is a UR73D1JTTD10L0F.
  *(live schematic sheets)*
- The commercial mote's absolute maximum BM current is 890 mA (~20 W),
  limited by its PoDL inductors, and it has no through-current protection.
  *(Sofar, More Power Delivery)*
- Bristlemouth v1 spec: a module draws ≤ 12 W from a nominal 24 V bus and must
  run from 16 V to 32 V. *(Sofar, More Power Delivery)*
- 50 W is 2.083 A at 24 V and 3.125 A at 16 V. *(arithmetic; matches the Sofar guide)*
- SRF1260-101M in series mode: 400 µH, Irms 0.892 A (40 °C rise), Isat 1.1 A
  (30 % drop), DCR 0.656 Ω max. That's where the mote's 20 W comes from.
  *(Bourns SRF1260 datasheet)*
- C22 and C23 are EEEFT1H470AP 47 µF/50 V aluminium electrolytics in the PoDL
  damping network. *(`BM_Mote_1_PoDL.kicad_sch`)*
- LMR51430YDDCR (U5, U10) is the 1.1 MHz PFM variant; VIN 4.5–36 V, absolute
  max 38 V; VREF 0.591 / 0.6 / 0.609 V; 70 ns minimum on-time; 5 V example uses
  RFBT 100 kΩ / RFBB 13.7 kΩ. *(TI LMR51430 datasheet SLUSEF4A, §1, §5, §7.1,
  §7.5, §9.2.2.2)*
- PA5432.822NLT (L3, L6): 8.2 µH ±20 %, Isat 8.4 A (~30 % drop), heating current
  8 A (ΔT ≈ 40 °C), DCR 24.0 / 26.4 mΩ typ/max, composite, −55 to +155 °C.
  *(Pulse P890.B, 01/22)*
- GRM21BR61C226ME44 (C56, C57): 22 µF ±20 %, 16 V, X5R, 0805; GRM155R61A475MEAA
  (C58): 4.7 µF ±20 %, 10 V, X5R, 0402; both in production. *(Murata product
  pages, read 2026-10-05)*
- RC0402FR-0713K7L (R38): Yageo 13.7 kΩ ±1 %, 1/16 W, 0402, thick film.
  *(Digi-Key product listing 311-13.7KLRCT-ND, 2026-10-05)*
- TI's own LMR51430 application circuit uses C_IN = 2.2 µF and, at 1.1 MHz,
  suggests L = 3.3 µH (5 V) / 2.2 µH (3.3 V) with 2 × 10 µF / 25 V output caps.
  *(SLUSEF4A Figure 9-1, Table 9-2)*
- *Historical (U9 removed in S5.a):* FPF2700: 2.8–36 V, 88 mΩ typical; R_SET (kΩ) = 277.5 / I_LIM(TYP) (A), ±20 %;
  short-circuit limit 0.75 × I_LIM; FPF2700 turns off after 0.5 ms blanking and
  retries after 127.5 ms; thermal shutdown 140 °C. With R34 = 374 kΩ, I_LIM ≈ 0.74 A
  typical. *(Fairchild FPF2700/1/2 datasheet Rev. 1.0.3, Eq. 1)*
- Pi Zero 2 W: recommended PSU 2 A, typical bare-board active 350 mA, Camera Module
  250 mA; all models require a 5.1 V supply; no low-voltage detector on the Zero range.
  *(Raspberry Pi documentation, "Power supply")* Input power 5 V DC 2.5 A; operating
  temperature −20 °C to +70 °C. *(Zero 2 W product brief, April 2024)*
- TPS26621DRCR (U11): 4.5–60 V (62 V abs max), 478 mΩ, current limit
  R_ILIM (kΩ) = 6.636 / I_LIM (A), I(OL) 0.757/0.80/0.827 A at 8.25 kΩ, auto-retry,
  FLT open drain, no PGOOD; SHDN low = shutdown (≈ 2 µA internal pull-up); dVdT may
  float (24 V/660 µs); UVLO to IN via ≥ 1 MΩ and OVP to RTN when unused; status ACTIVE.
  SHDN: I(SHDN) −2.4 µA typ / −10 µA max at 0.4 V, V(SHUTF) min 0.9 V, V(SHUTR) max 1.8 V;
  fast-trip 1.6 A typ / 220 ns; thermal shutdown 155 °C, retry 512 ms; §12.1 allows RTN,
  GND and PowerPAD together when reverse-input protection isn't needed (RTN = GND here).
  *(TI SLVSDT4F Rev. F; ti.com part page 2026-10-05)* JLC/LCSC C1848341.
- ADIN2111 (U1): no supply sequencing required; supply ramp ≤ 40 ms; internal power good 20–43 ms after the
  last supply; SPI active ≤ 50 ms (Table 3). Built-in power-on reset holds the chip in reset until supplies are
  good. RESET: active low, internal pull-up, may float, hold low > 10 µs, < 1 µs rejected; SPI accessible ≤ 90 ms
  after release. INT: open drain, active low, requires 1.5 kΩ to VDDIO; asserts after any reset. SPI, INT, LED and
  RESET pins rated −0.3 V to VDDIO + 0.3 V. Straps (internal pull): SPI_CFG1 pin 19 PU, SDO/SPI_CFG0 PD,
  P1_SWPD_EN pin 41 PD, P2_SWPD_EN pin 47 PU, Px_TX2P4_EN pins 21/48 PD; SPI_CFG1/0 = 0/0 → OPEN Alliance with
  protection (Table 22); 2.4 V p-p needs AVDD_H 3.3 V. VDDIO 1.71 V min (1.8/2.5/3.3 V typ); digital V_IL 0.8 V /
  V_IH 2.0 V at VDDIO 3.3 V; LED pins 8 mA at 3.3 V. *(ADIN2111 Rev. B datasheet, Tables 1, 3, 5, 8, 22,
  "Reset Operations"; PDF supplied by Nick, SHA-256 10b6521e7b7fabeaedf7afee6b15a058a923c72ed6e401ad4de53911201b2fba)*
- PoDL bus contact on the mote: threaded inserts MP1–MP4 (Würth 78614015360) sit on B.Cu with unnumbered,
  net-less pads (an SMD ring and the Ø4.4 NPTH); the bus nets reach each insert position through a front F.Cu arc
  on the bus track, C-shaped (~290°, not a closed ring), width 1.2 mm, radius 3.03 mm (copper ≈ 2.4–3.6 mm from centre): MP1 BM1_P, MP2 BM1_N, MP3 BM2_P
  (two arcs), MP4 BM2_N. Seven 0.6 mm vias of the bus net sit on r 3.0 mm under each arc and land inside the bottom ring
  pad (r 2.2–3.69 mm), so the insert is on the bus net through them; the inner planes stop 3.85 mm (MP2, MP4) to 4.78 mm (MP1, MP3) from each insert
  centre. *(reference .kicad_pcb, read 2026-10-06 (QE S5.g F1); vias and plane pullback measured 2026-10-07 with pcbnew,
  correcting the earlier "no vias within 3.5 mm")* Giving the pad a net in our footprint: Sofar Q6.
- AP22913 (U2, U3): ON active high, no internal pull-down; ON input leakage ≤ 1 µA; V_IH 1.1 V min; V_IL 0.4 V max
  (V_IN 1.4–3.6 V) / 0.6 V (3.6–5.5 V); output discharge when off; reverse-current blocking always active; R_ON
  56 mΩ typ at 3.3 V (X1-WLB0909-4 = "CN4": 0.9 × 0.9 mm, 0.5 mm ball pitch; top view A1 VOUT (pin-1 dot) and A2 VIN
  on the top row, B1 GND and B2 ON on the bottom row). *(Diodes DS41203 Rev. 6-2, p. 1 "Pin Assignments")*
- Pi Zero 2 W I²C1: R23/R24 1.8 kΩ 1 % pull-ups from GPIO2/GPIO3 to the Pi's 3V3. *(Raspberry Pi Zero 2 W reduced
  schematics, datasheets.raspberrypi.com/rpizero2/raspberry-pi-zero-2-w-reduced-schematics.pdf)*
- Pi GPIO reset-default pulls: GPIO0–8 pull up (incl. GPIO8 = CE0), GPIO9–27 pull down (incl. GPIO9 MISO,
  GPIO16, 20, 23, 24, 25). *(BCM2835 ARM Peripherals §6.2 p. 102; assumed to apply to the Zero 2 W's BCM2710A1 (in the RP3A0,
  product brief), not separately verified)*
- I²C standard/fast mode: V_OL ≤ 0.4 V at 3 mA sink, so R_P(min) = (3.3 − 0.4) / 3 mA = 967 Ω at 3.3 V; R_P(max) =
  t_r / (0.8473 · C_b) with t_r 1000 ns / 300 ns. *(TI SLVA689, Table 1 from the I²C specification; Eq. 1–2)*
- JST GH (1.25 mm): current rating 1.0 A AC/DC per contact (AWG #26), voltage rating 50 V AC/DC, −40 °C to +105 °C
  incl. temperature rise, contact resistance 30 mΩ max initial; wire AWG #30–#26. SM02B-GHS-TB is the 2-pin SMD
  right-angle header. *(JST GH connector datasheet, eGH.pdf)* JLC part C189893 for SM02B-GHS. *(Nick's UrchinCam BOM,
  UrchinCam_0v1_BOM_20260121.csv)* LCSC C189893 = SM02B-GHS-TB(LF)(SN), shown out of stock on 2026-10-06
  *(lcsc.com, QE S5.d)*; recheck in S5.e.
- Status LEDs (S5.f): Hubei KENTO KT-0603R, 0603 red, 615–630 nm, V_F 1.8–2.4 V at 20 mA, 300 mcd, LCSC C2286 (stock
  ≈ 2.6 M on 2026-10-06); KT-0603YG, 0603 yellow-green, 567–573 nm, V_F 2.0–2.2 V at 20 mA, 30–42 mcd, LCSC C2289
  (stock ≈ 24 k; JLC extended part). *(lcsc.com product pages, 2026-10-06; JLC part page for C2289)* KENTO marks the
  cathode with a green mark. *(KENTO KT-0603R specification, distributor copy rcscomponents.kiev.ua)* KiCad
  `Device:LED` pin 1 = K, pin 2 = A; `LED_SMD:LED_0603_1608Metric` pad 1 = cathode. *(KiCad 9.0.6 libraries)*
- There is no fuse, PTC or e-fuse anywhere in the schematic.
  *(live schematic sheets, 2026-10-04)*
- The Altium import breaks connectivity: the untouched reference mote
  schematic shows 38 opens against its own copper. Our project, with the
  junction fix, still shows 26. *(tools/netcheck.py, 2026-10-05)*
- In KiCad 9.0.6, a pin whose end sits mid-wire is unconnected, and a junction
  loaded from file at that point connects the pin but can disconnect a
  neighbouring pin on the same wire. Splitting the wire at the pin works.
  *(measured one junction at a time, 2026-10-05)*
- kicad-cli ERC output isn't deterministic: two runs on the same file can name
  different example labels for the same violation. Compare ERC by counts and
  types, and do net checks on the exported netlist. *(measured 2026-10-04)*

## Safety / hard constraints (non-negotiable)

1. Agents never write any `.kicad_pcb`. Reading it is fine (for net checks
   and footprint extraction). Board, layout and routing belong to Nick.
   *Exception (Nick, 2026-10-07, D31): a layout experiment writes its own board inside `experiments/<name>/`
   on its own branch; it never touches the live project, the reference designs or `Archive/`, and is never merged.*
2. KiCad stays closed while an agent edits project files. The agent confirms
   this with Nick before its first edit of each session.
3. Every net the design keeps must match the mote's copper, proven by a
   netlist diff, not by eye.
4. Never connect the Pi's 3.3 V pins (1, 17) to the shield's 3.3 V.
5. Every part value, pin number and rating carries a datasheet citation. No
   citation, no part: it goes in Open questions instead.
6. `KiCAD_reference_designs/` and `Archive/` are read-only.
7. The power path stays exactly as in the Sofar mote, except the payload load
   switch: R11 is DNP and U9 (obsolete) is replaced by a function-equivalent part,
   with R34/R33/R35 re-derived as needed (D17). L1/L2, D1–D3, R8, C22/C23/R15/R16
   etc. stay unchanged. *(Amended by Nick, 2026-10-05, QE S4.c F5.)* The rating is the mote's: ~20 W absolute max = 890 mA per port inductor at
   24 V *(Sofar, More Power Delivery)*; anything new on the bus (the S4 5 V
   converter, the payload connector) is checked against it. *(Nick, 2026-10-05; DESIGN D12)*
8. **The electronics are potted.** Parts kept from the Sofar mote design are
   vetted and stay as they are, unchanged (e.g. C22/C23). These rules apply
   only to **newly sourced** parts *(Nick, 2026-10-04)*:
   - **No aluminium electrolytic capacitors.** *(Nick, 2026-10-04)*
   - **No PPTC resettable fuses**; their trip behaviour changes when
     encapsulated. *(Sofar 50W/100W guide)*
   - Flag for Nick: any part with internal voids, vents or moving parts
     (trimmers, switches, relays); large MLCCs (1210 and up; prefer
     flexible-termination parts); ferrite magnetics (check vendor potting
     guidance).
   - Thermal ratings assume free air; potted parts need derating.
     *(Sofar 50W/100W guide)*

## Success criteria by sprint

See TRACKER.md — every sprint ends with a demo Nick can run.

## Non-goals (this project)

- Board outline, placement, routing, fabrication outputs (Nick); layout experiments in `experiments/` excepted (D31)
- Firmware or Pi software, beyond documenting the ADIN power-up order
- A 50 W power path on this board (deferred to a later revision, DESIGN D12)
- A 100 W variant; a Bristlemouth power-delivery protocol
- HAT ID EEPROM
- The shared nereus-lib (icebox)

## Open questions (flag, don't guess)

- Questions for Sofar (R11, R34/U9, mezzanine control, e-fuse, …) live in
  `docs/SOFAR_QUESTIONS.md`.
- ~~FPF2700 current limit~~ answered (Fairchild datasheet Rev. 1.0.3, supplied by Nick;
  power_budget §1): R34 = 374 kΩ → ≈ 0.74 A typical (0.59–0.89 A). As captured, R11 was
  fitted and bypassed U9; Nick: R11 DNP so the switch and limit work (D17, S5).
- ~~U9 (FPF2700MX) obsolete~~ done (S5.a, D18): replaced by TPS26621DRCR (U11). Still
  open: lifecycle-check every BOM part before S6. — done in S5.e (`docs/design-review/bom_lifecycle.md`); the sourcing
  decisions per flagged part and J1's part number (socket height) are open, for Nick.
- ~~R11's description field (Altium import) reads "RES SMD 205K OHM 1% 1/2W 1992" for a
  0 Ω CRCW1210 jumper: stale import data to clean in S6.~~ done in S6.e for all five CRCW1210 jumpers (R11–R13, R17, R19).
- Effective capacitance of C56/C57 (GRM21BR61C226ME44) at 5 V DC bias. Murata's
  SimSurfing tool needs its licence accepted first, so it's unmeasured; TI's
  Eq. 14 wants ≥ 22 µF effective (≈ 1.5 A step, 5 %). — S4.c / S6 (Nick or a
  datasheet curve)
- U10's input caps copy U5's 2.2 µF (C55) + 100 nF. TI's text suggests ≥ 4.7 µF
  (SLUSEF4A §9.2.2.6), though its own Figure 9-1 uses 2.2 µF; field-proven on
  U5, but U10 draws more input current. — S6 review
- ~~JP1 bridge current~~ answered (S4.c, `docs/design-review/power_budget.md` §4):
  IPC-2221, 1 oz assumed, 2.4 A at ΔT 10 °C / 3.2 A at 20 °C; 2 mV drop at 2.5 A.
- ~~Pi undervoltage threshold~~ answered (power_budget §5): the Zero range has **no**
  low-voltage detector (Raspberry Pi documentation, "Power supply warnings"); the
  bench check is 5V_PI ≥ 4.75 V at J1 (USB 2.0 VBUS minimum). R38 stays 13.7 kΩ
  (D16); 13.5 kΩ is the drop-in fix if the bench check fails.
- With JP1 bridged, the Pi must never also have a USB cable plugged in. Its power
  micro-USB feeds the 5 V rail directly (Raspberry Pi Zero 2 W reduced schematic,
  J1 → 5V); whether the data port's VBUS does too is unconfirmed (not shown in the
  reduced schematic). Failure modes: shield unpowered → USB 5 V back-feeds through L6
  and U10's high-side body diode onto VBUS (bus side via L1, payload port through U11 when SW_EN has it on; R11 is DNP);
  shield powered → two supplies fight. **Decided (Nick, 2026-10-05, D14): bench rule
  only** — never connect a USB 5 V source (charger, PC host, self-powered hub that
  back-feeds) to a bridged board's Pi, shield powered or not; Pi-powered USB
  peripherals are fine and count toward the S4.c budget. Open part: the data port's
  VBUS wiring (primary source).
- U10/L6/L1 heat (power_budget §3): ΔTj ≈ 42–57 °C at the D15 target (1 A), indicative
  only (TI's RθJA is for comparison; 25 °C efficiency). Potted RθJA unknown; measure
  T_top at bring-up (Tj ≈ T_top + 9.3 °C/W · P_U10).
- ADIN2111 power at 2.4 V p-p and the other 3.3 V loads: the budget uses a 0.30 W
  allowance at U5's input (ADI: 77 mW typical at 1.0 V p-p, dual supply) until the
  full datasheet is read. — S6
- Murata's product pages list "undersea equipment" among applications they
  don't warrant for these consumer/industrial MLCCs. Applies equally to the
  mote's existing Murata parts (C29, C32, C33, …). — note for S6 review
- ~~Bus power budget~~ done (power_budget §2): against the 12 W v1 module limit a 1 A
  Pi leaves ≈ 6.2 W for the payload; against 890 mA it leaves 645 mA at 24 V for
  payload + pass-through (VBUS behind L1's 0.656 Ω included).

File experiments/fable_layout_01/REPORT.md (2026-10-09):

# REPORT — layout experiment 01 (Fable port of the mote layout)

*Branch `experiment/fable-layout-01`, 2026-10-07/08; revised after QE rounds 1 and 2 (S7.b, 2026-10-08, `qe/S7b_round1.md`, `qe/S7b_round2.md`). Never merge. Everything here was produced by the scripts in
`tools/` (run `tools/build_all.sh` to rebuild the board from the schematic); the numbers below are read from the
check outputs in `out/`, not typed in. Board frame: KiCad coordinates = the brief's frame (Pi NW corner (0, 0).*

## 1. Result in one paragraph

The board is built, placed and routed: 138 footprints, every §3 position within 0.001 mm, every copied block
reproduced on the mote's geometry to within 0.001 mm (blockcheck: pads 242/242, tracks 641/744, arcs 4/4, vias 153/176, zones 6/6; copper items 930; **0 missing**; matched except
126 copied items trimmed after routing because KiCad's DRC called them dangling, listed in `out/m3/blockcheck.md`;
414 "extra" items = new routing inside the block regions), planes filled, 216 open connections brought down to **1**:
J1's pins 1/17, which the schematic puts on one no-connect net and which must stay open (SPEC constraint 4). The R8
shunt's Kelvin sense traces to U4 are copied whole and proven pad-to-pad by tracks alone (QE R2-F1). kicad-cli DRC
reports **111 errors: 110 in the table of Sofar-copied features below** (insert contact, transformer footprint,
courtyards) **and 1 declared item of the new copper** (1V8 0.225 mm from a port-1 bus-leg via, routed under the Default 0.15 mm rule, §6
#16), and **0 copper-defect warnings** (no dangling track or via, no hole-to-hole or co-located holes). The bus
nets' 0.35 mm clearance is a board design rule that kicad-cli enforces (§4; QE R2-F2). 3 of the 4 ADIN pairs are
within the mote's length, port 2's N is 2.1 mm over. The pass criteria of BRIEF §8 are scored in §9. The honest
headline: the port of Sofar's *blocks* worked very well; fitting Sofar's *arrangement* into this outline did not —
the blocks had to be split, and the ADIN pocket is the layout's weak spot.

## 2. Final board size and why

**46 × 65 mm, unchanged** (x −7.5…38.5, y 0…65, r 3 corners). Option (a) of §4 was used for U1: the ADIN block sits
in the west pocket, rotated 90°, so no growth was needed. One allowance: the ADIN block is 0.3 mm east of the brief's
pocket (U1's courtyard 1.79 mm from the L1 envelope instead of 2.0; its body 2.1 mm) because Sofar's U1 fan-out on the
west side needs 10.3 mm, not 10.0, to keep its copper 0.5 mm from the edge.

Stack: 6 copper layers in the mote's order and roles; a generic 1.6 mm build (35 µm ×6, prepreg 0.21 ×3, core 0.38
×2) written into the board file — an assumption (Sofar Q11).

## 3. Blocks: transforms and fidelity

Translate + rotate by multiples of 90° only, same side as the mote, proven by pads (`tools/blockcheck.py`,
`out/m3/blockcheck.md`). "Transform" is p' = R(rot)·(p − src) + dst with src = the anchor part's mote position.

| Block | Parts | Transform (mote mm → board mm, rotation) | Pads | Tracks | Arcs | Vias | Zones | Trimmed | Missing | Extra |
|---|---|---|---|---|---|---|---|---|---|---|
| RING_MP3 | MP1 | (176.001, 120.004) → (-1.81, 12.0), 0° | 0/0 | 0/0 | 1/1 | 7/7 | 0/0 | 0 | 0 | 0 |
| RING_MP4 | MP1 | (176.001, 120.004) → (-1.81, 21.4), 0° | 0/0 | 0/0 | 1/1 | 7/7 | 0/0 | 0 | 0 | 0 |
| RING_MP1 | MP1 | (176.001, 120.004) → (-1.81, 43.6), 0° | 0/0 | 0/0 | 1/1 | 7/7 | 0/0 | 0 | 0 | 0 |
| RING_MP2 | MP1 | (176.001, 120.004) → (-1.81, 53.0), 0° | 0/0 | 0/0 | 1/1 | 7/7 | 0/0 | 0 | 0 | 0 |
| ADIN | U1, U2, U3, Y1, C1, C2, C3, C4, C5, C6, C7, C8, C9, C10, C11, C12, C13, C14, R1, R2, R3, R4, R5, R6, TP1, TP2 | (154.001, 113.004) → (-1.4, 32.8), 90° | 103/103 | 234/267 | 0/0 | 50/50 | 2/2 | 33 | 0 | 241 |
| P1L | L1, D4, R12, R13, TP3, TP5, C17, D2 | (165.501, 108.754) → (12.74, 44.25), 90° | 16/16 | 37/48 | 0/0 | 12/19 | 0/0 | 18 | 0 | 18 |
| P1T | T1, C16, C18, C19, R14 | (161.601, 117.504) → (8.7, 28.4), 0° | 15/15 | 20/27 | 0/0 | 5/5 | 0/0 | 7 | 0 | 40 |
| P2L | L2, D5, R17, R19, TP7, TP13 | (131.679, 108.279) → (12.74, 16.75), 90° | 12/12 | 22/28 | 0/0 | 12/18 | 0/0 | 12 | 0 | 17 |
| P2T | T2, C24, C25, C27, R18 | (135.501, 117.504) → (16.0, 32.3), 180° | 15/15 | 33/34 | 0/0 | 5/6 | 0/0 | 2 | 0 | 19 |
| B33 | U5, C30, L3, C28, C29, R20, R21, R22, R23 | (140.501, 115.054) → (31.551, 17.704), 0° | 22/22 | 84/88 | 0/0 | 15/19 | 2/2 | 8 | 0 | 13 |
| B5V | U10, C55, L6, C53, C54, R39, R37, R40, R38 | (140.501, 115.054) → (31.551, 31.4), 0° | 22/22 | 85/88 | 0/0 | 14/19 | 2/2 | 8 | 0 | 19 |
| SENSE | U4, R8, R7, C15, TP22 | (146.351, 115.704) → (19.8, 15.0), 0° | 15/15 | 65/77 | 0/0 | 5/5 | 0/0 | 12 | 0 | 18 |
| DAMP3 | C23 | (146.001, 116.904) → (33.5, 40.0), 0° | 2/2 | 0/0 | 0/0 | 0/0 | 0/0 | 0 | 0 | 0 |
| DAMP1 | C21, C20, TP23 | (154.201, 119.204) → (8.9, 57.5), 90° | 5/5 | 8/8 | 0/0 | 0/0 | 0/0 | 0 | 0 | 2 |
| DAMP2 | C22 | (151.301, 103.604) → (33.9, 48.2), 0° | 2/2 | 17/36 | 0/0 | 7/7 | 0/0 | 19 | 0 | 7 |
| B18 | U6, L4, C32, C33, TP21 | (144.501, 110.329) → (20.7, 47.2), 90° | 13/13 | 36/43 | 0/0 | 0/0 | 0/0 | 7 | 0 | 20 |

Blocks as the brief listed them vs what was copied:

| Brief block | What happened | Why |
|---|---|---|
| SENSE (Kelvin) | R8 + U4 with Sofar's sense routing; the SENSE region has a third rect (Bottom only, mote x 143.6–144.4) for the west detour of the two 0.2032 mm Kelvin traces U4.1–R8.2 and U4.2–R8.1, which the first regions clipped (QE R2-F1); the traces and U4's sense pads are excluded from routing starts and stitching; `check_rules.py` proves both links pad-to-pad by tracks alone | the shunt is sensed at its pads, as on the mote |
| PORT1 / PORT2 | split: inductor + the bottom-side parts Sofar put under it (P1L/P2L) and the transformer cluster (P1T/P2T) | the transformer sits 9.6 mm from the inductor's centre on the mote, inside the 50 W envelope + 2 mm; the insert feeds are new routing anyway (the inserts moved) |
| SPINE | split: SENSE (R8, U4, R7, C15, TP22: Sofar's sense routing intact), DAMP1 (C21, C20, TP23), DAMP2 (C22), DAMP3 (C23); C17/D2 ride under L1, C26 moved out; D1, R15, R16 placed fresh | the mote's spine spans 22 × 21 mm across the whole board; no strip of this outline holds it |
| ADIN | whole, rotated 90°, in the west pocket | the brief's option (a) |
| BUCK3V3 | whole except C31 (B33) | with C31 the cell is 9.65 mm wide, the strip east of J1 is 8.9 |
| BUCK5V | B5V = the same cell copied again with parts mapped by function (U10, C55, L6, C53, C54, R39, R37, R40, R38) | D13; C56/C57/C58/TP38 beside it |
| BUCK1V8 | whole (B18), rotated 90°, east of L1 beside J1 | all bottom-side |
| LOAD | placed fresh around U11 (R34/R41 on the top beside it, R35 bottom) | the brief: U11 is new |
| Insert copper | Sofar's MP1 ring (arc r 3.03 × 1.2 mm, 290°, seven 0.6/0.254 vias at r 3.0) translated to each insert | §3 |

Copper **not** copied although inside a block's region: the ADIN pairs and T1/T2's pair stubs (new routing per §6),
Sofar's 2 mm BM1_N stub from L1 pad 2 toward the old insert (the inserts moved), and the big GND / VBUS / 3V3 / P_IN
planes (rebuilt on the new geometry, §4 below). **Trimmed after routing** (`tools/dangling.py`, every item recorded in
`blocks.json` "trimmed"): copper KiCad's DRC reports as dangling is shortened back to the last copper it joins (a
clipped stub keeps the part that carries a via or a pad) or deleted when nothing touches it: 23 vias deleted
(5V_PI 1, GND 20, VBUS 2: Sofar's pour-stitching vias, which had a pour on the mote and only a plane here), 74 track
segments deleted (14 mm, clipped stubs and the router's own tails), 90 shortened. Port 2's 2 mm BM2_N stub
(QE F1) is one of the shortened: it keeps the part under L2's pad 2 and Sofar's via.

## 4. Planes and routing

- **GND (In2):** near-solid, 0.5 mm from the edge, pulled back 4.8 mm from each insert; one 0.5 mm slot on the band
  side and one on the outer side of each inductor island (x −7.5…22.7; port 2 at y 6.5–7.0 / 26.2–26.7, port 1 at
  39.0–39.5 / 54.0–54.5) so each island joins the plane only on its east, far side. Mapping of the mote's two slots:
  the mote isolates the inductor + insert region from the plane on the transformer side and joins it on the far side;
  here "far" is east, toward J1. The port-1 slot sits 2.5 mm into L1's envelope so the port-2 pair (which crosses at
  y ≈ 38) does not cross it. The plane is one island (2,134 mm²) and passes between J1's pins: along x = 26.5
  (between the two pin columns) every sampled point from y 7 to 58 is copper; along each pin column the gaps between
  the pads are copper (345 and 351 of 2,551 sample points; the rest are the pads themselves). QE F2: the first M5 had
  the planes at 0.35 mm from everything, which closed these gaps.
- **PWR (In4):** VBUS = the strip east of J1 (full height), the whole west half from y 26 down, and port 2's east
  (x 16.8–23.2); P_IN island under port 2's west/centre (x 11–16.6, y 8–25.7; R8 straddles the boundary as on the mote);
  3V3 island at the 3.3 V buck output (x 33.4–38, y 8–23); the copied ADIN islands (priority 7); Sofar's two
  unconnected islands reproduced as 6 × 6.5 mm no-net islands between each port's inserts and inductor (Q10). VBUS is
  one island (1,534 mm²) and passes between J1's pins like GND. Plane clearance 0.25 mm (power class). **Bus rule
  (QE R2-F2):** `board/nereus_Pi_shield_ADIN2111.kicad_dru` — bus nets keep 0.35 mm from every other net (`A.NetClass ==
  'bus' && B.NetClass != 'bus'`); the `bus` netclass (priority 0, clearance 0.15) only names the four BM nets, so the
  P and N legs of one port keep Sofar's 0.2 mm spacing and T1/T2's pads 6/7 (0.24 apart) stay as drawn. The Python
  fill honours it (measured on a scratch copy: 0.351 mm to a BM via, 0.251 to a 1V8 via) and kicad-cli enforces it
  (with the rule and the committed copper: 0 clearance errors between bus and non-bus copper apart from the declared
  1V8 item, §6 #16). Inner planes stop 0.25 / 0.35 mm from the hole walls of the Pi standoffs and
  the M3 holes (QE N5): the brief's r 3.0 / 3.5 "both sides" is applied to the outer layers only.
- **Cross-class clearance in the router:** the brief's clearance is a property of both items, so the grid keeps a
  second map of copper *kinds* (bus / power-class / other): a 0.15 mm-class route keeps 0.35 from bus copper and 0.25
  from power-class copper, and a bus route keeps 0.35 from everything that is not a bus net and, as the `busleg` class, 0.35 from the opposite leg too (QE R3-F2; a leg may enter its own T1/T2 pad by an orthogonal step without the clearance test, since pad 7 sits 0.24 mm from pad 6). Power-class nets fall
  back to narrower widths at the same 0.25 clearance before the 0.15 "thin" last resort (declared, #11). Every
  plane net's lonely pads get their stitching via before the signals are routed (GND 25, VBUS 7, 3V3 4, P_IN 1).
- **5V_PI:** a bottom-side pour x 29.7–38, y 7.5–26.5 from L6 to JP1 (§6 "≥ 1.0 mm or a pour"), joined to the
  U10 cell by a 0.5 mm track where the cell's copper split it.
- **Bus feeds:** insert ring → inductor bus pad, 1.5 mm on Top, by hand (8 segments).
- **Everything else:** `tools/router.py`, a 0.1 mm grid A* on Top / Internal 1 / Internal 2 / Bottom with the brief's
  classes, per-class dilated obstacle maps, exact edge distance, fan-out at 0.15 mm where needed; GND pads stitched
  with a via within 1.2 mm; plane-net clusters stitched into their planes (69 vias, 37 of them before the signals, spots chosen inside the plane's
  *filled* copper deflated 0.15 mm, and never closer than 0.25 mm hole-to-hole to any other hole; QE F1). Two links
  laid by hand where the grid could not: U11 pin 7 → R34 and U11 pin 1 → a VBUS via. **U3's 3V3 escape** (QE F4):
  from Sofar's copied via at (−5.5, 38.65) west of U3, the router lays a 0.15 mm track on Internal 2 east to
  (2.5, 38.0) *before* the pocket's signals are routed (9.0 mm); the plane-leftovers step then joins it to the 3V3
  island by track. In the first M5 the lookup radius for that via was too small, so the escape was never laid — the
  "(2.5, 38.0) on Internal 2" of the old §7 did not exist; the QE's reading of the board was right.

## 5. DRC summary (kicad-cli, `--schematic-parity --severity-all`)

| Item | Count | Status |
|---|---|---|
| errors | 111 | 110 Sofar-copied features in the exclusion table below + 1 declared item of the new copper (1V8 vs the BM1_P leg via at (11.94, 43.88), 0.225 mm on Internal 2, routed under the Default 0.15 mm rule; §6 #16) |
| unconnected | 1 | J1 pins 1/17 on one no-connect net (must stay open, SPEC 4) |
| schematic parity | 4 | MP1–MP4 "no pad for pin 1": Sofar's insert footprint has no numbered pad (Q6) |
| courtyard overlaps | 12 | in the table |
| warnings | 258 | text_height 112, silk_over_copper 46, silk_overlap 44, padstack 38, lib_footprint_mismatch 8, silk_edge_clearance 4, text_thickness 4, nonmirrored_text_on_back_layer 2 — silk and text from the imported footprints, not reviewed. **Copper-defect warnings: 0** (track_dangling, via_dangling, hole_to_hole, holes_co_located; the first M5 had 50 / 23 / 14 / 3, QE F1) |

kicad-cli could not be given the exclusions: KiCad stores them keyed by the marker position, which the CLI's JSON
report does not contain (keys built from the items' positions are ignored; tested). They are therefore a reviewed
table, generated by `tools/drcexclude.py` from the table of reasons in the script, for Nick to apply in KiCad's DRC
dialog:

| Type | # | Reason |
|---|---|---|
| clearance | 1 | 1V8's only lane from the 1.8 V buck to U2 passes the port-1 bus legs at the Default 0.15 mm, not the bus rule's 0.35 (REPORT §6; the legs, not the feeds) |
| clearance | 2 | Sofar's transformer footprint: the copied vias of pads 3/4's nets sit beside the unnumbered no-net pads, as on the mote |
| clearance | 4 | Sofar's transformer footprint: two unnumbered no-net pads overlap pads 3/4 (identical on the mote board) |
| courtyards_overlap | 2 | BRIEF §3 positions: the M3 housing hole's ±4.25 mm courtyard overlaps the Pi standoff hole's courtyard by 0.25 mm (7 mm centres); screw head and standoff clear |
| courtyards_overlap | 10 | Sofar's placement inside a copied block (rigid, BRIEF rule 5); the courtyards were added in S6.c and overlap where Sofar packed parts tighter |
| hole_clearance | 36 | Sofar's insert contact copied as drawn: the ring pad vs the 7 via holes (28), the NPTH vs the ring pad (4) and the arc/vias vs the 4.4 mm hole (4), as on the mote (Sofar Q6) |
| padstack_invalid | 4 | Sofar's insert footprint (Altium import): the NPTH pad has no copper size; hole 4.4 mm (DESIGN D19/D24) |
| shorting_items | 28 | Sofar's insert contact copied as drawn (BRIEF §3): bus vias land in the insert's net-less ring pad (Sofar Q6) |
| shorting_items | 6 | Sofar's transformer footprint: tracks to pads 3/4 cross the unnumbered no-net pads, as on the mote |
| solder_mask_bridge | 8 | Sofar's insert contact copied as drawn: the ring pad's mask opening spans the bus vias (Sofar Q6) |
| solder_mask_bridge | 10 | Sofar's transformer footprint: the unnumbered no-net pads' mask openings touch pads 3/4, as on the mote |

kicad-cli DRC: 111 errors, 111 with a reason above, 0 without; 1 unconnected, 4 parity items (the 4 parity items are MP1–4 pin 1, Sofar Q6).

## 6. Deviations from the mote and the brief, and why

| # | Deviation | Why |
|---|---|---|
| 1 | Blocks split as in §3 | the fixed items leave three strips (8.9 mm east of J1, the 8 mm band, the 10 mm pocket); no whole block but ADIN fits |
| 2 | 2 mm envelope clearance applied to top-side parts only; bottom-side parts sit under the inductors as Sofar placed them | otherwise the port blocks could not be copied at all; the 50 W part is a top-side volume (for Nick to confirm) |
| 3 | ADIN block 0.3 mm east of the pocket (U1 courtyard 1.79 mm from the L1 envelope) | Sofar's U1 west fan-out |
| 4 | J5 stays the JST GH (no Molex, no schematic edit) | Nick, 2026-10-07 |
| 5 | JP1 on the bottom beside J1 pins 2/4 | no top-side room left in the strip; cut it before stacking |
| 6 | R35 on the bottom (south-west), R34/R41 on the top beside U11, R15 beside C22, C26 moved out of port 2 | fresh placements, moved to free U11's pins and the strip's bottom |
| 7 | LEDs in a column at the band's east end (x 21.5), not on the west wall | the pocket holds U1 (brief: "the LEDs move") |
| 8 | ADIN pair BM2_DATA_N 23.4 mm vs the mote's 21.3 (BM2_DATA_P 21.3, BM1 7.9 / 9.4 within) | the pair leaves U1's south pins and reaches T2 around U1's south-east; P took the inner lane |
| 9 | Pair tracks 0.15 mm (fan-out class) along their length, routed independently (not as a coupled pair); BM1_DATA_N and BM2_DATA_P run on Top only with 0 vias, the other two Top + Internal 1 with 2 vias as the mote (QE N1) | the router has no pair mode; fewer vias is no electrical loss |
| 10 | 10 new segments narrower than their class (`out/m5/rules.md`): 5V_PI links of 0.5 / 0.3 mm (pour + short links), one 0.15 mm VBUS link into U11 pin 1, 3 payload (VBUS_OUT) segments of 0.5 mm at U11's output instead of 0.6 (QE F5) | fallback classes where the full width found no path |
| 11 | 1 class-clearance item on new copper below the brief's 0.25 (≥ the 0.15 default, not a DRC error): payload VBUS_OUT vs ~{PAYLOAD_FAULT} on Top Layer at (34.10, 53.00) | U11's 0.5 mm pitch: the VBUS_OUT track leaving pad 10 passes pad 9 |
| 12 | Stitching vias everywhere instead of Sofar's via placement for GND | new geometry |
| 13 | The U1 fan-out's copied vias in the mote's DNC pads are kept as Sofar drew them | fidelity |
| 14 | 13 links routed whole at 0.15 mm (the fan-out width) instead of their 0.2 mm class (QE N2): 3V3 9.2 mm; ADIN_MOSI 35.1 mm; ADIN_PWR 4.3 mm; BM1_DATA_N 7.9 mm; BM1_DATA_P 9.4 mm; BM2_DATA_N 23.4 mm; BM2_DATA_P 21.3 mm; ISET 2.8 mm; Net-(U11-UVLO) 5.1 mm; PAYLOAD_EN 4.9 mm; ~{ADIN_CS} 39.8 mm; ~{ADIN_P2_LED1} 34.9 mm; ~{PAYLOAD_FAULT} 16.0 mm | the thin class was the only one that found a path (the ADIN pocket, U11's west side, the pairs per #9) |
| 15 | 126 copied copper items trimmed after routing (§3: clipped stubs, Sofar's pour-stitching vias) | KiCad's DRC calls them dangling here; every one is listed in `out/m3/blockcheck.md` and `blocks.json` |
| 16 | 1V8 (buck B18 → U2) passes the port-1 bus-leg via at (11.94, 43.88) at 0.225 mm on Internal 2 (routed under the Default 0.15 mm rule), not the bus rule's 0.35: 1 DRC error, in the exclusion table with this reason | at 0.35 there is no lane from the 1.8 V buck to the ADIN pocket (the router tried 0.35 first; the leg vias, not the feeds, are what it passes) |
| 17 | The bus rule is bus vs non-bus (§4): Sofar's copied P/N legs and T1/T2's pads 6/7 (0.24 mm apart) keep Sofar's spacing. New bus copper keeps 0.35 mm from the opposite leg as well (the `busleg` class, QE R3-F2), except the last 0.1 mm of a leg entering T1/T2 pad 6 or 7, which passes the neighbouring pad at Sofar's spacing (`check_rules.py` exempts only those pads) | the brief's bus class describes the insert feeds; Sofar's leg geometry is copied as drawn; a leg has to reach its pad |

## 7. Open after M5

1. BM2_DATA_N 2.1 mm over the mote's length (deviation 8).
2. J1 pins 1/17 (Pi 3V3) unconnected by design.
3. The §6 declarations: narrower fallback links (#10), 1 clearance item (#11), 13 thin links (#14), the 1V8 lane (#16).

(U3's 3V3 feed, open in the first M5, is closed: §4.)

## 8. What was hard, where I guessed, what I would do with more time

Rebuilding: `tools/build_all.sh` reproduces the board DRC-for-DRC but not byte-for-byte (the router's tie-breaking
depends on Python set order; QE N4). The committed board is the output of one run of M0–M3 and the M4 step from the
M3 snapshot (`START=m4`), followed by a second pass of `tools/dangling.py` after the "delete on the second flag" rule
was added (LOG, S7.b round 1).

- Hard: fitting rigid blocks into strips 8–9 mm wide; the ADIN pocket's exits; KiCad's silent re-netting of copper
  that lands on a pad of another net (blockcheck caught every case); the grid router's conservatism against
  off-grid copied vias (fixed by inflating pre-existing copper by half a cell diagonal, which then blocks the 0.15 mm
  threading between U1's 1.27 mm thermal vias).
- Guessed / interpreted: the envelope clearance for bottom-side parts (deviation 2); the GND slot mapping (§4); the
  no-net islands' size and place; the stackup; the pull-back applied to copper of other nets only; bottom-part
  heights from datasheet maxima (`heights.json`).
- With more time: a pair-aware router (route N and P together); rip-up that targets one lane, not a region (my
  rip-up rounds thrashed); a 0.05 mm grid near fine-pitch parts; a second look at the ADIN pocket — rotating the
  block 270° (port-2 pins north) or moving the LEDs' resistors would free the south strip; silk clean-up.

## 9. Pass criteria (BRIEF §8)

| # | Criterion | Result |
|---|---|---|
| 1 | DRC: 0 errors, 0 unconnected, 0 parity (exclusions with reasons) | **Partial**: 111 errors, all in the exclusion table with reasons (110 Sofar features + 1 declared 1V8 item; not applied: CLI limitation); 1 unconnected (J1's no-connect pair, by design); 4 parity items (Q6, documented); 0 copper-defect warnings; the bus rule enforced by kicad-cli |
| 2 | §3 positions ±0.05; J1 pin 1 at (25.23, 8.37) from the top | **Pass** (`check_fixed.py`: every position within 0.001; pins 1/2/39/40 proven) |
| 3 | §4 keep-outs, 2 mm around both envelopes, bottom ≤ 3 mm | **Pass with one allowance**: U1 1.79 mm (recorded); bottom parts ≤ 1.5 mm; holes clear (parts); inserts: no other-net copper within r 4.8 on any layer (`check_fixed.py`, QE F6) |
| 4 | blockcheck 100 % | **Pass with trimming declared**: 0 missing on every block; 126 copied items trimmed after routing (listed); 414 extra = new routing in the block regions (`out/m3/blockcheck.md`) |
| 5 | §6 widths on new routing; pairs no longer than the mote's; R8 sense identical; rings identical | **Partial**: feeds 1.5 mm, payload 0.6 (3 segments 0.5), pairs 3/4 within (BM2 N +2.1 mm), 10 fallback segments narrower than their class, 13 thin links, 1 clearance item (table 6), 1V8 at 0.225 from a bus-leg via (#16); R8/U4 Kelvin links pad-to-pad by tracks alone (U4.1 ↔ R8.2 (P_IN) yes, U4.2 ↔ R8.1 (VBUS) yes); rings 100 % |
| 6 | R35 on the bottom (south-west), R34/R41 on the top beside U11, R15 beside C22, C26 moved out of port 2 | fresh placements, moved to free U11's pins and the strip's bottom |
| 7 | LEDs in a column at the band's east end (x 21.5), not on the west wall | the pocket holds U1 (brief: "the LEDs move") |
| 8 | ADIN pair BM2_DATA_N 23.4 mm vs the mote's 21.3 (BM2_DATA_P 21.3, BM1 7.9 / 9.4 within) | the pair leaves U1's south pins and reaches T2 around U1's south-east; P took the inner lane |
| 9 | Pair tracks 0.15 mm (fan-out class) along their length, routed independently (not as a coupled pair); BM1_DATA_N and BM2_DATA_P run on Top only with 0 vias, the other two Top + Internal 1 with 2 vias as the mote (QE N1) | the router has no pair mode; fewer vias is no electrical loss |
| 10 | 10 new segments narrower than their class (`out/m5/rules.md`): 5V_PI links of 0.5 / 0.3 mm (pour + short links), one 0.15 mm VBUS link into U11 pin 1, 3 payload (VBUS_OUT) segments of 0.5 mm at U11's output instead of 0.6 (QE F5) | fallback classes where the full width found no path |
| 11 | 1 class-clearance item on new copper below the brief's 0.25 (≥ the 0.15 default, not a DRC error): payload VBUS_OUT vs ~{PAYLOAD_FAULT} on Top Layer at (34.10, 53.00) | U11's 0.5 mm pitch: the VBUS_OUT track leaving pad 10 passes pad 9 |
| 12 | Stitching vias everywhere instead of Sofar's via placement for GND | new geometry |
| 13 | The U1 fan-out's copied vias in the mote's DNC pads are kept as Sofar drew them | fidelity |
| 14 | 13 links routed whole at 0.15 mm (the fan-out width) instead of their 0.2 mm class (QE N2): 3V3 9.2 mm; ADIN_MOSI 35.1 mm; ADIN_PWR 4.3 mm; BM1_DATA_N 7.9 mm; BM1_DATA_P 9.4 mm; BM2_DATA_N 23.4 mm; BM2_DATA_P 21.3 mm; ISET 2.8 mm; Net-(U11-UVLO) 5.1 mm; PAYLOAD_EN 4.9 mm; ~{ADIN_CS} 39.8 mm; ~{ADIN_P2_LED1} 34.9 mm; ~{PAYLOAD_FAULT} 16.0 mm | the thin class was the only one that found a path (the ADIN pocket, U11's west side, the pairs per #9) |
| 15 | 126 copied copper items trimmed after routing (§3: clipped stubs, Sofar's pour-stitching vias) | KiCad's DRC calls them dangling here; every one is listed in `out/m3/blockcheck.md` and `blocks.json` |
| 16 | 1V8 (buck B18 → U2) passes the port-1 bus-leg via at (11.94, 43.88) at 0.225 mm on Internal 2 (routed under the Default 0.15 mm rule), not the bus rule's 0.35: 1 DRC error, in the exclusion table with this reason | at 0.35 there is no lane from the 1.8 V buck to the ADIN pocket (the router tried 0.35 first; the leg vias, not the feeds, are what it passes) |
| 17 | The bus rule is bus vs non-bus (§4): Sofar's copied P/N legs and T1/T2's pads 6/7 (0.24 mm apart) keep Sofar's spacing. New bus copper keeps 0.35 mm from the opposite leg as well (the `busleg` class, QE R3-F2), except the last 0.1 mm of a leg entering T1/T2 pad 6 or 7, which passes the neighbouring pad at Sofar's spacing (`check_rules.py` exempts only those pads) | the brief's bus class describes the insert feeds; Sofar's leg geometry is copied as drawn; a leg has to reach its pad |

## 10. Questions

**For Nick**
1. Deviation 2 (bottom parts under the envelopes) — acceptable for the 50 W part?
2. The 0.3 mm pocket allowance for U1, or should U1 sit 0.3 mm further west with Sofar's fan-out re-routed?
3. JP1 on the bottom (cut before stacking) — or drop JP1 to the top by moving C31 again?
4. Is the J1 3V3 pair's DRC item acceptable, or should the two pins be tied with a track (harmless, both are the Pi's rail)?
5. BM2_DATA_N: accept +2.1 mm, or re-route the pair by hand in KiCad?

**For Sofar** (add to `docs/SOFAR_QUESTIONS.md` if useful)
1. Q6: the insert contact — is the net-less ring pad + bus vias intentional, or should the pad carry the net?
2. Q9: R12/R13/R17/R19 across the inductor windings are copied fitted.
3. Q10: the two unconnected In4 islands — purpose? They are reproduced as floating copper here.
4. Q11: the stack-up (this board uses a generic 1.6 mm 6-layer build).
5. The GND slot past each inductor: what is it for, so the mapping in §4 can be checked?

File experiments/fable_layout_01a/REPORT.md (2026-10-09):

# REPORT — layout experiment 1.a (fit everything at the proper widths by moving blocks, then a JLCPCB DFM sweep)

*Branch `experiment/fable-layout-01a`, 2026-10-08. The board never goes into the live project (D31); the folder is what Nick merges
to track the record. QE: round 1 CHANGES REQUESTED, round 2 APPROVED WITH NITS, round 3 CHANGES REQUESTED (fixed), round 4
**APPROVED WITH NITS** (`qe/S7b_01a_round4.md`, nits fixed). Session 1 ran M0–M2 and stopped on Nick's instruction; session 2
brought **M2 to its bar** (QE round 2: APPROVED WITH NITS, `qe/S7b_01a_round2.md`); **session 2.b** (this report) did Nick's
wind-down list (LESSONS §3/§4) in order: JLCPCB's limits fetched and encoded first (**M3**, `DFM.md`), the board grown to
**49 × 68**, the inserts moved, U1 in the centre of the band tried against U1 in the pocket through M2 on scratch copies (OPTIONS
addendum), the router made to emit 45° runs as single segments with a pair-length margin, the SPI routed first on a reserved
Internal 2 lane, the cut jumpers on top at the north edge, then a rebuild from M0 with every check, the renders and the review
pages. Everything here was produced by the scripts in `tools/` (`tools/build_all.sh`, `VARIANT=pocket` by default); the numbers
are read from `out/m4/summary.json` and the check outputs in `out/m4/`, `out/m5/`, not typed in. Board frame: KiCad coordinates =
the brief's frame (Pi NW corner (0, 0), mm). The session-2.b record is LOG.md "Session 2.b"; the design review is
`out/review/index.html`, the before / after page `out/before_after/index.html`.*

## 1. Result in one paragraph

The board is **49 × 68 mm** (x −10.5 … 38.5, y 0 … 68; the width went west, the height south into the band between the inductor
envelopes, which is 11 mm now), the inserts 1.5 mm nearer the west wall, the port-1 side 2.5–3 mm south. **U1 stays in the west
pocket** (3 mm taller than before): the centre of the band, Nick's preferred answer, was tried first in eight routed trials and
cannot meet the pairs' bar with this pair emitter (§3, OPTIONS addendum A3: 9.7–10.0 mm for port 1 at the rotation that faces
the SPI toward J1; 19–47 mm at the mote's own rotation, where the swap figure finds no straight run). The routing is complete at
the brief's widths and clearances: **0 open links but J1's no-connect pair, 0 new segments below their class width, 0 links at
0.15 mm beyond a pad field, 0 class-clearance items**, the Kelvin links pad-to-pad by tracks, **all four pair legs within the
mote's length (9.39 / 8.77 / 19.93 / 20.61 mm vs 9.5 / 9.5 / 21.3 / 21.3)**, checked on the board for P–N clearance (0.15 mm), their
45° runs single segments (**15 / 15 / 24 / 24 segments per leg**, session 2: 25 / 25 / 40 / 40). The SPI goes from U1 straight east
to J1 on its Internal 2 lane, routed first: **31 / 32 / 38 / 39 mm** of new track (session 2: 66.5 / 67.6 down the west edge). DRC:
**109 errors, all Sofar-copied features with a reason each, 0 of new copper; 68 warnings**, none a copper defect. **DFM: 30 of 31
rows pass** against JLCPCB's published limits, the one fail declared (the 0.23–0.24 mm pads of U6, U2, U3 and U11, per footprint).
**No new via sits in a solder pad** (QE round 3 F1: the router forbids it; DFM row 30 is measured; 7 new vias in the inductors' and
C23's large pads are listed, QE round 4 N2). After the first rebuild Nick
asked for two more changes from the renders (OPTIONS A6): the fitted **20 W inductors' courtyards + 2 mm are the keep-out**, not the
50 W envelope (the band is 12.9 mm), and **U1 is 3 mm further from the west edge** (8.8 mm; Sofar's ~{ADIN_INT} via is inside the
board again, no hand via). 138 footprints, every §3 position within 0.001 mm, `check_fixed.py` 0 failures, blockcheck 0 missing /
128 trimmed (listed), 0 of Sofar's pad-to-pad paths cut. Board md5 23e5e8f939e6bf5e0c6b609e6c7ee14d (QE round 4: APPROVED WITH NITS; the nits are fixed
in this board: the stock SOT-23-THIN's '*' on B.Fab under U5 / U10 is mirrored now, `tools/dfm_fix.py` mirrors every back-layer
footprint text, and the DRC summary is run last, on the saved file; 68 warnings on a clean copy as well).

## 2. Final board size and stack

**49 × 68 mm** (Nick, 2026-10-08: 3 mm wider, 3 mm taller; supersedes the brief's 2 mm south allowance), r 3 corners. Six copper
layers in the mote's order with **JLCPCB's JLC06161H-3313 stackup** written into the board (DFM.md row 21: outer 1 oz, inner
0.5 oz, 3313 / 0.55 core / 2116 / 0.55 core / 3313, 1.538 mm of material, 1.6 mm nominal). Where the 3 + 3 mm went and why:
OPTIONS addendum A1 (the first trial with the width on the east gained nothing in the strip and failed on the west).

## 3. Block moves (OPTIONS §3 + addendum, as built; `VARIANT=pocket`)

| Block | session 2: dst, rot | 2.b: dst, rot | Why |
|---|---|---|---|
| frame | 46 × 65, x −7.5 … 38.5 | **49 × 68, x −10.5 … 38.5, y 0 … 68** | A1 |
| MP3 / MP4 / MP1 / MP2 (rings) | x −1.81; y 12.0 / 21.4 / 43.6 / 53.0 | **x −6.31; y 12.0 / 21.4 / 46.1 / 55.5** | 1.5 mm nearer the wall (A2); port 1 2.5 mm south (3 put MP2 2.91 mm from H3's keep-out) |
| MTG1–4 | (−3.5, 3.5) (34.5, 3.5) (−3.5, 61.5) (34.5, 61.5) | **(−6.5, 3.5) (34.5, 3.5) (−6.5, 64.5) (34.5, 64.5)** | with the corners; the MTG/H courtyard overlaps are gone |
| inductor keep-outs | 50 W envelope 15.5 × 15.5 + 2 mm: L2 y 9.0–24.5, L1 y 36.5–52.0 | **the SRF1260's courtyard 13.1 × 13.6 + 2 mm: L2 (6.19, 9.95, 19.29, 23.55), L1 (6.19, 40.45, 19.29, 54.05)**; L1 (12.74, 47.25) | Nick, 2026-10-08: only the 20 W inductors for this board (OPTIONS A6); L1's centre 3 mm south: the band y 25.55 … 38.45 |
| ADIN | (−1.7, 32.5), 90° | **(−1.7, 33.75), 90°** | 8.8 mm from the new west edge (Nick: "too close to the edge, move it east"); centred in the taller pocket (26.2 … 41.3); the mote's full region (107.5), Sofar's ~{ADIN_INT} via at x −7.2 is inside: no hand via |
| P1T (T1, C16, C18) | (6.7, 28.4) | **(6.7, 29.45)** | session 2's relation to U1 but 0.2 mm north: at the exact relation BM1_DATA_P came out 9.59 (trial 3) |
| P1C (C19, R14) | in P1T | **(8.95, 26.05)** | the mote's spot relative to T1, as its own rigid piece (the split exists for the centre variant) |
| P2T | (13.7, 32.5), 180° | **(13.7, 33.75), 180°** | session 2's relation to U1 |
| B18 | (19.0, 31.4), 90° | **(19.0, 32.9), 90°** | with U1's latitude |
| DAMP1 / D1 / R11 / TP36 / FID5 / FID6 / J5 | y 57.5 / 59.0 / 58.0 / 62.3 / 55.6 / 55.6 / 61.8 | **+3.0 mm** | with the south band |
| JP1 | (32.05, 9.45) top, strip's north end | **(20.4, 2.2) top, north band** | Nick: on top at an edge, no tall part beside (A4) |
| JP2 | (15.0, 4.3) bottom under the LEDs | **(12.5, 5.2) top, north band** | same |
| D10 / D8 / D9 | (11.6 / 15.0 / 18.4, 1.4) | **(8.1 / 11.5 / 14.9, 1.4)** | room for JP1 at the band's east end |
| R46 / R44 / R45 | (10.8 / 18.0 / 19.4, 4.2) bottom | **(8.1 / 11.5 / 14.9, 3.0) bottom** | under their LEDs |
| FID3 / FID4 (top), FID1 / FID2 (bottom) | (21.5 / 8.0, 2.5) | **(17.0, 5.3) / (7.8, 5.0)** | JLCPCB: pad edge ≥ 3.35 mm from the edge (DFM row 26) |
| R43 / TP8 | (7.5 / 9.8, 36.3) bottom | **(7.5 / 9.8, 37.8) bottom** | with U1's latitude |
| B5V, B33, DAMP3, DAMP2, SENSE, P2L, U11 cell, C56–C58, TP20/24/38, R26/R27, R15/R16, C26, the Pi holes, J1 | unchanged | unchanged | |
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

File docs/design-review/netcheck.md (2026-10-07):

# Net check — schematic vs mote copper

*Copper: `KiCAD_reference_designs/20250409_BM_Mote_000639-AB/BM_Mote_000639-AB.kicad_pcb` · Schematic netlist: `docs/design-review/out/netlist.net`*

Generated by `tools/netcheck.py`; don't edit by hand.

| Result | Count |
|---|---|
| Copper nets (2+ pins on shared parts) | 51 |
| Matched exactly | 51 |
| Opens (copper net split in schematic) | 0 |
| Shorts (schematic joins copper nets) | 0 |
| Schematic pins with no copper pad | 0 |
| Copper pads with no schematic pin | 0 |
| Parts only in copper (removed) | 60 |
| Parts only in schematic (new) | 31 |
| Parts excluded (scheduled for deletion) | 0 |

**Status: MATCH**

## Parts only in copper (removed)

C34, C35, C36, C37, C38, C39, C40, C41, C42, C43, C44, C45, C46, C47, C48, C51, C52, D6, D7, J3, J4, L5, P1, R9, R10, R24, R25, R28, R29, R30, R31, R32, R33, R36, TP4, TP6, TP9, TP10, TP11, TP12, TP14, TP15, TP16, TP17, TP18, TP25, TP26, TP27, TP28, TP29, TP30, TP31, TP32, TP33, TP34, TP37, U7, U8, U9, Y2

## Parts only in schematic (new)

C53, C54, C55, C56, C57, C58, D8, D9, D10, J1, J5, JP1, JP2, L6, MP1, MP2, MP3, MP4, R37, R38, R39, R40, R41, R42, R43, R44, R45, R46, TP38, U10, U11
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

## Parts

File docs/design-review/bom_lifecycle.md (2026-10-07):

# BOM lifecycle and stock check (S5.e)

*Checked 2026-10-06 against main `e62d974` (all parts on the schematic). Stock figures change daily: recheck before
ordering. Part of the S6 design-review package.*

**Scope:** 50 unique parts, 105 placements, from the exported netlist. Excluded: test points, fiducials, mounting holes,
R11 (DNP), JP1/JP2 (copper links, not in the BOM).

**Build size:** 20 boards (Nick). A part is flagged when LCSC stock is below 20 × its per-board quantity, when it has no
LCSC listing, when it has no real part number, or when it is not Active.

**Sources:**
- **Lifecycle:** Digi-Key "Product Status" unless marked. The TI parts are from ti.com. Most other manufacturer sites
  refused automated access (403, time-outs, JavaScript-only pages).
- **Stock:** lcsc.com product pages read on 2026-10-06.
- **JLC Basic/Extended:** the label on jlcpcb.com part pages. Almost everything is Extended, so expect a per-part-type
  setup fee.
- **Caveat:** "None found" means no LCSC listing turned up in web searches restricted to lcsc.com/jlcpcb.com. LCSC's own
  search can't be queried automatically, so it isn't proof the part is absent; confirm in a browser before deciding.
- **Method:** the research was split across four read-only research agents. The design agent spot-checked their
  results: the SMA6F33A obsolete status on Digi-Key, LMR51430YDDCR stock on LCSC, and D1/R8's second-source fields in
  the netlist.

## Summary

| Result | Parts |
|---|---|
| OK (Active, LCSC stock ≥ 20 boards) | 29 (the KENTO LEDs' lifecycle is unverified: no manufacturer page) |
| **Obsolete** | 1: D1 SMA6F33A (ST). Sofar's own fields name second sources |
| **No real part number** | 1: J1 (open decision: socket height) |
| **Low stock** | 1: U2/U3 AP22913CN4-7 (30 < 40) |
| **Out of stock at LCSC** | 6: J5, R21/R35/R37/R43, C17/C26, C21, C22/C23, C31 |
| **No LCSC listing found** | 12: U1, MP1–MP4, L3/L6, Y1, D2/D3, R34, C16/C18/C24/C25, C19/C27, R14/R18, R15/R16, R8, R20/R39 |

**Every flagged part except J1 is Active and in stock at Digi-Key or Mouser.** The issue is JLC/LCSC availability, not
lifecycle (apart from D1).

**Constraints (SPEC hard constraints 7 and 8):** every Sofar part stays exactly as specified. Buying the exact part
(JLC global sourcing or consigned) keeps both constraints. Substituting any Sofar part would need Nick to amend
constraint 8, and constraint 7 as well for power-path parts (D1–D3, R8, R15/R16, C22/C23, L1/L2 …). Only these may
change without an amendment:
- Sofar's own listed alternates (D1, R8).
- The parts we sourced ourselves (J1, J5, R34, the LEDs, …).

**Sourcing policy (Nick, 2026-10-06; DESIGN D26):**
- **Critical parts:** buy the exact part through **JLC global sourcing**. This covers U1, U2/U3, L3/L6, Y1, D1–D3,
  MP1–MP4 and J5.
- **Passives:** the specified part stays on the schematic. Pin-compatible, generic, LCSC-stocked alternates are recorded
  as hidden `ALT…` fields next to it (S5.h), as **proposals for Sofar's design review**.
- Adopting any alternate for a Sofar part is a later decision, made with Sofar, that needs a constraint amendment. The
  bespoke PoDL/power-path parts (R8, R15/R16, C22/C23) are flagged "Sofar review".
- **First build:** every flagged passive is also bought exact through JLC global sourcing (or consigned) until an
  alternate is approved, so the 20-board order can be placed.
- **Done in S5.h:** the alternates are now hidden symbol fields (`ALT1 MPN/MFR/LCSC`, `ALT2 MPN/MFR/LCSC`, `ALT NOTE`)
  on the 24 flagged passives, and `SOURCING` is set on those and on every critical part. `tools/check.sh` exports them
  to the tracked `docs/design-review/bom.csv`: Sofar's specified part stays in the `Value (MPN)` column, alternates sit
  beside it. Values and their LCSC check: `docs/design-review/bom_alternates.md`. In KiCad: Tools → Edit Symbol Fields.
- **Done in S6.a:** test points, fiducials and mounting holes are out of the BOM (`in_bom no`), and `MANUFACTURER` is
  filled from this table on the 75 BOM parts that had none (J1 open). `bom.csv` now lists only purchased parts (51 rows).
- **Done in S5.i (D27):** every purchased part has a planned part (`PLANNED MPN/MFR/LCSC` + `PLANNED NOTE`) right after
  the specified part: 10 lines change, the rest are planned as specified. The first build buys the planned parts after
  Sofar's review (amends the first-build rule above).

## Decisions needed (proposed, not applied; rows marked † need a constraint amendment)

| Part (refs) | Problem | Suggested route | Why |
|---|---|---|---|
| J1 Pi socket | no part number | choose height later (Nick); candidates ZHOURI C2977589 / Megastar C7499354, both 8.5 mm | open until the board-to-board spacing is known |
| D1 SMA6F33A (bus TVS) | ST part obsolete | Sofar's second source **Vishay SMA6F33A-M3/H** (same DO-221AC, 600 W, 33 V; Vishay datasheet 89458) via global sourcing | already Sofar-approved in the part fields |
| U1 ADIN2111BCPZ | no LCSC listing | global sourcing or consign (DK 120) | no equivalent part |
| MP1–MP4 Würth 78614015360 | no LCSC listing | JLC global sourcing (DK 7,835) | the LCSC insert found needs a footprint change; JLC lists taller Würth M3 inserts (3.0 / 4.0 mm) if a taller insert were acceptable |
| L3/L6 PA5432.822NLT | no LCSC listing | global sourcing or consign | vetted power-path inductor; XAL6060 is not a confirmed drop-in |
| Y1 ABM11W 25 MHz | no LCSC listing | JLC global sourcing (DK 87) | LCSC same-family crystals aren't drop-ins (one −20…+70 °C vs −40…+125 °C, one 8 pF load); others need an ADIN2111 crystal-spec check |
| C22/C23 EEEFT1H470AP | out of stock | global sourcing (DK 78,606) | a newly sourced replacement must be potting-safe, so not another electrolytic |
| U2/U3 AP22913CN4-7 | 30 in stock, need 40 | JLC global sourcing for all 40 (simplest), or LCSC 30 + DK balance | no drop-in |
| J5 SM02B-GHS-TB | out of stock | global sourcing (DK 10,839) | GH lookalikes' land patterns unchecked |
| R15/R16 CRCW08057R50FKEAHP | no LCSC listing | global sourcing (Sofar review) | pulse-proof PoDL damping part; Yageo SR0805 alternate† has unverified pulse rating and ±200 vs ±100 ppm/°C |
| D2/D3 RB058LAM-60TFTR | no LCSC listing | **JLC global sourcing** (policy). Alternate for review†: RB088LAM-60TFTR (same family/package, higher current) | constraint 7 (power path) |
| R8 UR73D1JTTD10L0F | no LCSC listing | one of Sofar's 7 listed alternates (no amendment needed; none found at LCSC) or global sourcing; ROHM/Vishay 10 mΩ 0603 for review† (Sofar review) | Sofar-approved list exists |
| Commodity R/C: R34, R20/R39, R14/R18, R21/R35/R37/R43, C16/C18/C24/C25, C19/C27, C17/C26, C21, C31 | no listing / out of stock | specified parts stay; LCSC alternates recorded as `ALT…` fields (S5.h) for Sofar review† (R34 is ours: no amendment) | value-for-value; R21 group's UNI-ROYAL part is JLC Basic |

**Watch items (no action now):**
- L1/L2 SRF1260-101M: LCSC 137 (thin margin). Bourns PCN IC25029 changes assembly only, not EOL.
- T1/T2 Würth 74930000: LCSC 295; Digi-Key has 0, with a 37-week lead time.
- C30/C55 UMK107BBJ225KA-T has been renamed MSASU168BB5225KTNA01 by Taiyo Yuden.
- KYOCERA AVX is renumbering its MLCCs (distributor notice).
- L4's footprint is named DFE201612C, but the part is the E series; the land patterns haven't been compared.
- D4/D5: LCSC also lists a same-named ElecSuper part. Order the Bourns one.
- The KENTO LEDs have no published lifecycle.

## Full table

| MPN | Mfr | Refs | Qty / 20 boards | Lifecycle | LCSC | LCSC stock | JLC | Status | Notes / alternates |
|---|---|---|---|---|---|---|---|---|---|
| Raspberry_Pi_2_3 | — | J1 | 1 / 20 | — | — | — | — | NO MPN | Generic 2×20 female socket footprint only; part to choose (height open). Candidates: ZHOURI 2.54-2*20 C2977589 (32,515; 8.5 mm insulator; Ext), Megastar ZX-PM2.54-2-20PY C7499354 (10,148; 8.5 mm, gold; Ext). UrchinCam's Amphenol 95157-440LF is a male SMD header: not usable |
| SM02B-GHS-TB | JST | J5 | 1 / 20 | Active (DK) | C189893 | 0 (out of stock) | Ext | OUT OF STOCK | DK 10,839. LCSC GH-type lookalikes (land pattern unchecked): HCTL HC-GH-2PWT C2845397 (1,400), JUSHUO GH125-S02DCA-00 C2886765 (10,670) |
| 78614015360 | Würth Elektronik | MP1, MP2, MP3, MP4 | 4 / 80 | Active (DK) | none found | — | — | NO LCSC LISTING | DK 7,835 (M3, 1.5 mm, OD 6.0). Würth 9774015360R has the same dimensions (no LCSC). LCSC Sinhoo SMTSO3015CTJ C2915632 is Ø5.56 mm: needs a footprint change |
| ERJ-2RKF4701X | Panasonic | R2, R3, R4, R5, R6, R26, R27 | 7 / 140 | Active (DK) | C400631 | 184,700 | Ext | OK |  |
| RMCF0402FT100K | Stackpole | R21, R35, R37, R43 | 4 / 80 | Active (DK; AEC-Q200) | C7055151 | 0 (out of stock) | — | OUT OF STOCK | UNI-ROYAL 0402WGF1003TCE C25741 (2,432,700; **JLC Basic**); Yageo RC0402FR-07100KL C60491 (8,367,900). Same value/tol/power/TCR; AEC-Q200 not stated |
| CL05A104KA5NNNC | Samsung | C1, C3, C9, C10, C11, C12, C13, C14, C15, C28, C53 | 11 / 220 | Active (DK) | C100072 | 2,632,100 | Ext | OK |  |
| CL05A105KP5NNNC | Samsung | C2, C4 | 2 / 40 | Active (DK) | C14445 | 924,800 | Ext | OK |  |
| CC0402KRX5R6BB684 | Yageo | C5, C6 | 2 / 40 | Active (DK) | C113784 | 142,800 | Ext (probable) | OK |  |
| CC0402JRNPO9BN150 | Yageo | C7, C8 | 2 / 40 | Active (DK) | C106997 | 2,229,300 | Ext | OK |  |
| KT-0603R | Hubei KENTO | D8 | 1 / 20 | unverified (no mfr page) | C2286 | 2,601,000 | Basic | OK (lifecycle unverified) |  |
| KT-0603YG | Hubei KENTO | D9, D10 | 2 / 40 | unverified (no mfr page) | C2289 | 24,100 | Ext (probable) | OK (lifecycle unverified) |  |
| RC0402FR-071K5L | Yageo | R1, R44, R45, R46 | 4 / 80 | Active (DK) | C114759 | 1,002,200 | Ext | OK |  |
| ADIN2111BCPZ | Analog Devices | U1 | 1 / 20 | Active (DK) | none found | — | — | NO LCSC LISTING | DK 120 (tray; -R7 reel also listed). No equivalent: buy/consign or JLC global sourcing |
| AP22913CN4-7 | Diodes Inc. | U2, U3 | 2 / 40 | Active (DK) | C2150198 | 30 | Ext | LOW STOCK (30 < 40) | DK 52,413. No LCSC drop-in. LCSC 30 + DK balance, consigned |
| ABM11W-25.0000MHZ-6-K1Z-T3 | Abracon | Y1 | 1 / 20 | Active (DK) | none found | — | — | NO LCSC LISTING | DK 87. LCSC 25 MHz 6 pF 2016 alternates, need an ADIN2111 crystal-spec check: TKD SX20Y025000B61T002 C20623595 (11,920; −30…+85 °C), Murata XRCGB25M000F3A00R0 C467842 (6,140; ±35/±35 ppm) |
| GRM188R72A104KA35D | Murata | C20, C29, C49, C50, C54 | 5 / 100 | Active (DK) | C77058 | 49,730 | Ext | OK |  |
| RB058LAM-60TFTR | ROHM | D2, D3 | 2 / 40 | Active (DK) | none found | — | — | NO LCSC LISTING | ROHM RB088LAM-60TFTR C5336606 (5,135; same SOD-128, 60 V, 5 A); RB058LAM100TR C962680 (115; higher V_F) |
| RC0402FR-079K09L | Yageo | R34 | 1 / 20 | Active (DK) | none found | — | — | NO LCSC LISTING | Yageo AC0402FR-079K09L C227284 (7,700; same series, automotive); UNI-ROYAL 0402WGF9091TCE C11549 (4,100) |
| RC0402FR-071ML | Yageo | R41 | 1 / 20 | Active (DK) | C138033 | 1,826,500 | Ext | OK |  |
| RMCF0402FT10K0 | Stackpole | R42 | 1 / 20 | Active (DK) | C6111655 | 3,900 | Ext | OK |  |
| TPS26621DRCR | Texas Instruments | U11 | 1 / 20 | ACTIVE (TI, family page) | C1848341 | 8,038 | Ext | OK |  |
| 08051C474KAT2A | KYOCERA AVX | C16, C18, C24, C25 | 4 / 80 | Active (DK) | none found | — | — | NO LCSC LISTING | Yageo CC0805KKX7R0BB474 C596323 (250,730); AVX 08051C474K4Z2A C597303 (750). AVX MLCC part-number migration (distributor notice, Oct 2026) |
| C2012X7S2A105K125AB | TDK | C17, C26 | 2 / 40 | Active (DK) | C2182292 | 0 (out of stock) | Ext | OUT OF STOCK | TDK C2012X7S2A105KT000N C342785 (10,140); Murata GCM21BC72A105KE36L C126585 (23,540) |
| C0805C102MDRACTU | KEMET | C19, C27 | 2 / 40 | Active (DK) | none found | — | — | NO LCSC LISTING | KEMET C0805C102KDRACTU C2167549 (3,715; ±10%); Walsin 0805B102K102CT C303890 (182,650) |
| CL32B106KBJNNNE | Samsung | C21 | 1 / 20 | Active (DK; DK 0, 61 wk) | C138687 | 0 (out of stock) | Ext | OUT OF STOCK | FH 1210B106K500NT C116808 (17,642); Taiyo Yuden UMK325AB7106KM-T C386167 (5,670) |
| EEEFT1H470AP | Panasonic | C22, C23 | 2 / 40 | Active (DK; DK 78,606) | C92059 | 0 (out of stock) | Ext | OUT OF STOCK | Aluminium electrolytic (bus input). A newly sourced replacement must be potting-safe (SPEC constraint): keep this part via global sourcing, or redesign. Substitutes not assessed |
| SMA6F33A | STMicroelectronics | D1 | 1 / 20 | **Obsolete** (DK: "Obsolete and no longer manufactured") | none found | — | — | OBSOLETE | Sofar's fields already list second sources: Vishay **SMA6F33A-M3/H** (MPN1) and ST SMA6F33AY (MPN2; RS "intend to remove"). No LCSC listing found for either. DK subs: ST SMA6J33A-TR (SMA pkg), Littelfuse SMA6L33A |
| CDSOD323-T36SC | Bourns | D4, D5 | 2 / 40 | Active (DK) | C911382 | 2,674 | Ext | OK | LCSC C22363665 is an ElecSuper part with the same name: not Bourns |
| SRF1260-101M | Bourns | L1, L2 | 2 / 40 | Active (DK) | C6496096 | 137 | Ext | OK (thin margin) | Bourns PCN IC25029 (assembly/glue change from DC 2540; not EOL) |
| CRCW12100000Z0EA | Vishay Dale | R12, R13, R17, R19 | 4 / 80 | Active (DK) | C844880 | 6,990 | Ext | OK |  |
| RR0510P-101-D | Susumu | R14, R18 | 2 / 40 | Active (DK) | none found | — | — | NO LCSC LISTING | Yageo RT0402BRD07100RL C705627 (326,300; 0.1 %, 25 ppm thin film); Panasonic ERA2AEB101X C445575 (3,280; AEC-Q200) |
| CRCW08057R50FKEAHP | Vishay Dale | R15, R16 | 2 / 40 | Active (DK) | none found | — | — | NO LCSC LISTING | Pulse-proof 0.5 W 0805 (PoDL damping). Yageo SR0805FR-477R5L C873769 (8,360; 0.5 W; pulse rating/AEC not verified) |
| 74930000 | Würth Elektronik | T1, T2 | 2 / 40 | Active (DK) | C4354923 | 295 | Ext | OK | DK 0, 37-week lead time |
| RC0402JR-0710KL | Yageo | R7 | 1 / 20 | Active (DK) | C60489 | 12,252,700 | Ext | OK |  |
| UR73D1JTTD10L0F | KOA Speer | R8 | 1 / 20 | Active (DK) | none found | — | — | NO LCSC LISTING | Sofar's fields list 7 approved 10 mΩ 0603 alternates (e.g. Murata MFL0603R0100FA, Panasonic ERJ-3LWFR010V, Stackpole CSRF0603FT10L0); LCSC options found: ROHM PMR03EZPFU10L0 C308571 (1,390), Vishay WSLP0603R0100FEA C5334451 (4,990); land patterns to check |
| INA232AIDDFR | Texas Instruments | U4 | 1 / 20 | ACTIVE (TI) | C5447660 | 14,958 | Ext | OK |  |
| UMK107BBJ225KA-T | Taiyo Yuden | C30, C55 | 2 / 40 | Renamed: MSASU168BB5225KTNA01 "Mass Production (Preferred)" (Taiyo Yuden) | C268016 | 122,670 | Ext | OK | Record the new part number |
| C1608X5R0J226M080AC | TDK | C31 | 1 / 20 | Active (DK; DK 0 until 2027-01) | C2167532 | 0 (out of stock) | Ext | OUT OF STOCK | Samsung CL10A226MQ8NRNC C59461 (5.27 M; Basic per mirror only); Murata GRM188R60J226MEA0D C77042 (77,150). Thickness vs 1.0 mm footprint not checked |
| GRJ155R60J106ME11D | Murata | C32 | 1 / 20 | Active (DK) | C469527 | 28,390 | Ext | OK |  |
| GRM155R60J475ME87D | Murata | C33 | 1 / 20 | Active (DK) | C76996 | 128,840 | Ext | OK |  |
| GRM21BR61C226ME44L | Murata | C56, C57 | 2 / 40 | Active (DK) | C86817 | 5,305 | Ext | OK |  |
| GRM155R61A475MEAAD | Murata | C58 | 1 / 20 | Active (DK) | C335105 | 179,780 | Ext | OK |  |
| PA5432.822NLT | Pulse (YAGEO group) | L3, L6 | 2 / 40 | Active (DK) | none found | — | — | NO LCSC LISTING | Twin PM5432.822NLT C17666871 out of stock. Coilcraft XAL6060-822MEC C19191627 (655; Isat 8.4 A; footprint and rated current to check). Bourns SRP6060FA-8R2M C2045598 (17: not enough) |
| DFE201612E-2R2M=P2 | Murata | L4 | 1 / 20 | Active (DK) | C337893 | 13,455 | Ext | OK | Footprint named DFE201612C; land pattern vs the E series not compared |
| CRCW04021M82FKED | Vishay Dale | R20, R39 | 2 / 40 | Active (DK) | none found | — | — | NO LCSC LISTING | RALEC RTT021824FTH C166520 (7,500; same 1.82 MΩ 1 % 100 ppm 62.5 mW 50 V 0402) |
| RC0402FR-07200KL | Yageo | R22, R40 | 2 / 40 | Active (DK) | C114763 | 3,014,900 | Ext | OK |  |
| RC0402FR-0722K1L | Yageo | R23 | 1 / 20 | Active (DK) | C163478 | 1,779,100 | Ext | OK |  |
| RC0402FR-0713K7L | Yageo | R38 | 1 / 20 | Active (DK) | C274888 | 290,500 | Ext | OK |  |
| LMR51430YDDCR | Texas Instruments | U5, U10 | 2 / 40 | ACTIVE (TI) | C5210749 | 7,155 | Ext | OK |  |
| TPS62840YBGR | Texas Instruments | U6 | 1 / 20 | ACTIVE (TI) | C2071139 | 3,630 | Ext | OK |  |

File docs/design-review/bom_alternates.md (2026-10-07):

# BOM alternates plan (S5.h) — ready to execute

*Plan approved by Nick 2026-10-06 (DESIGN D26). Alternates below were checked by the design agent against their
lcsc.com product pages on 2026-10-06. Recheck stock before ordering. Nothing here changes a connection: the specified
parts stay; only hidden fields are added.*

**Executed in S5.h (2026-10-06, branch `sprint/5h-bom-fields`)** as below, with one change to the export: a `${DNP}`
column and `--group-by 'Value,${DNP}'`, because grouping by Value alone merged R11 (DNP) into the row of the fitted
R12/R13/R17/R19 and marked all five DNP. Result: `docs/design-review/bom.csv`; changes in `changelog.md`.

**Cap (Nick, 2026-10-06; D26):** at most 3 alternates per part, the best by match and availability. This plan uses at most 2. Sofar's own
listed alternates (R8's `MANUFACTURERPARTNUMBER1–7`, D1's second sources) stay in their original fields, outside `bom.csv`.

## Planned parts (S5.i, D27)

The part we intend to build with, per BOM line, in hidden `PLANNED MPN/MFR/LCSC` + `PLANNED NOTE` fields. Unchanged
lines are planned as specified with their LCSC number (from `bom_lifecycle.md`); J1 is TBD. Changed lines:

| Refs | Your part | Planned part (LCSC) | Why |
|---|---|---|---|
| R34 | RC0402FR-079K09L | YAGEO AC0402FR-079K09L (C227284) | same YAGEO thick-film family; ours (D18) |
| R20, R39 | CRCW04021M82FKED | RALEC RTT021824FTH (C166520) | only stocked 1.82 MΩ ±1 % match |
| R21, R35, R37, R43 | RMCF0402FT100K | UNI-ROYAL 0402WGF1003TCE (C25741) | JLC Basic; AEC-Q200 not stated |
| C31 | C1608X5R0J226M080AC | Samsung CL10A226MQ8NRNC (C59461) | same spec; yours out of stock |
| C17, C26 | C2012X7S2A105K125AB | TDK C2012X7S2A105KT000N (C342785) | TDK C2012 series, same spec per LCSC (thickness not confirmed) |
| C21 | CL32B106KBJNNNE | Taiyo Yuden UMK325AB7106KM-T (C386167) | same spec, Taiyo Yuden; FH (more stock) kept as backup |
| C16, C18, C24, C25 | 08051C474KAT2A | YAGEO CC0805KKX7R0BB474 (C596323) | same spec, stock for 80 |
| C19, C27 | C0805C102MDRACTU | KEMET C0805C102KDRACTU (C2167549) | same series, ±10 % (tighter) |
| R14, R18 | RR0510P-101-D | YAGEO RT0402BRD07100RL (C705627) | ±0.1 % ±25 ppm thin film (tighter) |
| D1 | SMA6F33A (ST, obsolete) | Vishay SMA6F33A-M3/H (global sourcing) | your listed second source (Q7) |

Kept as specified (Sofar review): **R8** — ROHM PMR03EZPFU10L0 (ALT1) electrodes b = 0.35 ± 0.15 mm (ROHM datasheet
Rev.PMR03-IA-012E) sit inside R8's pads (1.1 × 1.1 mm at ±0.65 mm), which were drawn for the UR73D1J 10 mΩ's
0.55 ± 0.1 mm electrodes (KOA UR73 catalog, 11/17/24); ROHM gives no land pattern. Sources:
https://fscdn.rohm.com/en/products/databook/datasheet/passive/resistor/chip_resistor/pmr03-e.pdf and
https://www.koaspeer.com/pdfs/UR73.pdf (both read 2026-10-06), and the pads reach 0.35 mm under its body, so
not adopted. **C22/C23** no potting-safe like-for-like part; **R15/R16** no alternate with a stated pulse rating.

## What to do

1. **On each flagged passive**, add these hidden symbol fields with `schedit.set_properties` (it adds missing fields
   hidden at the symbol origin):
   - `ALT1 MPN`, `ALT1 MFR`, `ALT1 LCSC`
   - `ALT2 MPN`, `ALT2 MFR`, `ALT2 LCSC`
   - `ALT NOTE`
   - `SOURCING`: "JLC global sourcing (first build) until an ALT is approved (D26)"
2. **On each critical part**, add `SOURCING` only (values below).
3. **BOM export.** Add to `tools/check.sh` a tracked export `docs/design-review/bom.csv`:
   ```
   kicad-cli sch export bom \
     --fields 'Reference,Value,Footprint,${QUANTITY},MANUFACTURER,LCSC,SOURCING,ALT1 MPN,ALT1 MFR,ALT1 LCSC,ALT2 MPN,ALT2 MFR,ALT2 LCSC,ALT NOTE' \
     --labels 'Refs,Value (MPN),Footprint,Qty,Mfr,LCSC,Sourcing,Alt1 MPN,Alt1 Mfr,Alt1 LCSC,Alt2 MPN,Alt2 Mfr,Alt2 LCSC,Alt note' \
     --group-by Value
   ```
4. **Checks.** ERC 27/504 and netcheck 51/51 must be unchanged. The netlist diff must show fields only: identical nets,
   values and footprints.
5. **Docs.** Point `bom_lifecycle.md` at the fields and `bom.csv`. Add a note to the Sofar brief that the alternates are
   proposals for their review. Update TRACKER, the viewer, the changelog and DEV_LOG.
6. **Review.** QE, then Nick's look (Tools → Edit Symbol Fields shows the columns).

Part locations: R34/R35/D3 Load; R20/R21/R37/R39/C31/L3/L6 Power; R8 PowerMon; C16–C27/R14–R18/D1/D2 PoDL;
U1/U2/U3/Y1 ADIN2111; R43/MP1–MP4/J5/J1 Master.

## Flagged passives — alternates (verified 2026-10-06)

Group key: **A** ordinary passives, **B** power path (constraint 7), **C** PoDL front end. Adopting an alternate for a
Sofar part needs a constraint amendment after Sofar's review (D26). R34, R39, R43 and R35's group copies are our own
parts.

| Refs | Specified | ALT1 (LCSC, stock) | ALT2 (LCSC, stock) | ALT NOTE |
|---|---|---|---|---|
| R34 (A) | RC0402FR-079K09L 9.09 kΩ 1 % 0402 | YAGEO AC0402FR-079K09L (C227284, 7,700) | UNI-ROYAL 0402WGF9091TCE (C11549, 4,100) | 9.09 kΩ ±1 % 62.5 mW 50 V ±100 ppm thick film; our part (D18), no amendment |
| R20, R39 (A) | CRCW04021M82FKED 1.82 MΩ 1 % 0402 | RALEC RTT021824FTH (C166520, 7,500) | — (UNI-ROYAL/YAGEO equivalents out of stock) | 1.82 MΩ ±1 % 62.5 mW 50 V ±100 ppm |
| R21, R35, R37, R43 (A) | RMCF0402FT100K 100 kΩ 1 % 0402 | UNI-ROYAL 0402WGF1003TCE (C25741, 2.4 M; **JLC Basic**) | YAGEO RC0402FR-07100KL (C60491, 8.4 M) | 100 kΩ ±1 % 62.5 mW 50 V ±100 ppm; AEC-Q200 not stated (Stackpole is) |
| C31 (A) | C1608X5R0J226M080AC 22 µF 6.3 V X5R 0603 | Samsung CL10A226MQ8NRNC (C59461, 5.3 M) | Murata GRM188R60J226MEA0D (C77042, 77 k) | 22 µF ±20 % 6.3 V X5R 0603 |
| R8 (B) | UR73D1JTTD10L0F 10 mΩ 1 % 0603 | ROHM PMR03EZPFU10L0 (C308571, 1,390) | Vishay WSLP0603R0100FEA (C5334451, 4,990) | **Sofar review**: power-path current sense. Sofar's own 7 listed alternates (fields MANUFACTURERPARTNUMBER1–7) not found at LCSC; check land pattern |
| C17, C26 (B) | C2012X7S2A105K125AB 1 µF 100 V X7S 0805 | TDK C2012X7S2A105KT000N (C342785, 10,140) | Murata GCM21BC72A105KE36L (C126585, 23,540) | 1 µF ±10 % 100 V X7S 0805; power path: Sofar review |
| C21 (B) | CL32B106KBJNNNE 10 µF 50 V X7R 1210 | FH 1210B106K500NT (C116808, 17,644) | Taiyo Yuden UMK325AB7106KM-T (C386167, 5,670) | 10 µF ±10 % 50 V X7R 1210; power path: Sofar review |
| C22, C23 (B) | EEEFT1H470AP 47 µF 50 V Al electrolytic | — | — | **Sofar review**: bus damping; a newly sourced replacement must be potting-safe (constraint 8), so no like-for-like alternate; JLC global sourcing (DK 78,606) |
| R15, R16 (B) | CRCW08057R50FKEAHP 7.5 Ω 0.5 W pulse-proof 0805 | YAGEO SR0805FR-477R5L (C873769, 8,340) | — | **Sofar review**: 7.5 Ω ±1 % 0.5 W, ±200 vs ±100 ppm/°C, pulse rating not stated |
| C16, C18, C24, C25 (C) | 08051C474KAT2A 470 nF 100 V X7R 0805 | YAGEO CC0805KKX7R0BB474 (C596323, 250,730) | KYOCERA AVX 08051C474K4Z2A (C597303, 750) | 470 nF ±10 % 100 V X7R 0805; PoDL front end: Sofar review |
| C19, C27 (C) | C0805C102MDRACTU 1 nF 1 kV X7R ±20 % 0805 | KEMET C0805C102KDRACTU (C2167549, 3,715) | Walsin 0805B102K102CT (C303890, 182,650) | 1 nF 1 kV X7R 0805, ±10 % (tighter); PoDL front end: Sofar review |
| R14, R18 (C) | RR0510P-101-D 100 Ω 0.5 % 25 ppm thin film 0402 | YAGEO RT0402BRD07100RL (C705627, 326,300) | Panasonic ERA2AEB101X (C445575, 3,280; AEC-Q200) | 100 Ω ±0.1 % ±25 ppm thin film 0402 (tighter); PoDL front end: Sofar review |

## Critical parts — `SOURCING` only

| Refs | `SOURCING` value |
|---|---|
| U1 ADIN2111BCPZ | JLC global sourcing (D26); no LCSC listing, DK 120 |
| U2, U3 AP22913CN4-7 | JLC global sourcing, all 40 (LCSC has 30) (D26) |
| L3, L6 PA5432.822NLT | JLC global sourcing (D26); no LCSC listing |
| Y1 ABM11W-25.0000MHZ-6-K1Z-T3 | JLC global sourcing (D26); no LCSC listing, DK 87 |
| D1 SMA6F33A | JLC global sourcing of Sofar's second source Vishay SMA6F33A-M3/H (ST part obsolete; Sofar Q7) (D26) |
| D2, D3 RB058LAM-60TFTR | JLC global sourcing (D26); no LCSC listing |
| MP1–MP4 Würth 78614015360 | JLC global sourcing (D26); no LCSC listing, DK 7,835 |
| J5 SM02B-GHS-TB | JLC global sourcing (D26); LCSC C189893 out of stock, DK 10,839 |
| J1 (no MPN yet) | Part not chosen: 2×20 2.54 mm female TH socket, height open (Nick). Candidates ZHOURI 2.54-2*20 C2977589, Megastar ZX-PM2.54-2-20PY C7499354 (both 8.5 mm) |

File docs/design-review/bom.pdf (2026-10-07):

# nereus_Pi_shield_ADIN2111 — BOM for review

PCB-000001-AA rev AA · from docs/design-review/bom.csv · 2026-10-07 · 51 lines, 105 fitted parts per board (+ 1 DNP) · 11 lines where the planned part differs from Sofar's (for Sofar's review; nothing adopted before it, D26/D27)

Refs | Qty | Sofar's part (specified) | Planned part | Why (planned note) | Backups (Alt1 / Alt2) | Sourcing | Footprint
C1, C3, C9-C15, C28, C53 | 11 | CL05A104KA5NNNC Samsung | CL05A104KA5NNNC Samsung LCSC C100072 | As specified; in LCSC stock (checked 2026-10-06) | | | FP-CL278-IPC_C
C2, C4 | 2 | CL05A105KP5NNNC Samsung | CL05A105KP5NNNC Samsung LCSC C14445 | As specified; in LCSC stock (checked 2026-10-06) | | | FP-CL511-IPC_C
C5, C6 | 2 | CC0402KRX5R6BB684 YAGEO | CC0402KRX5R6BB684 Yageo LCSC C113784 | As specified; in LCSC stock (checked 2026-10-06) | | | FP-CC0402-MFG
C7, C8 | 2 | CC0402JRNPO9BN150 Yageo | CC0402JRNPO9BN150 Yageo LCSC C106997 | As specified; in LCSC stock (checked 2026-10-06) | | | FP-CC0402-0_55-IPC_B
C16, C18, C24, C25 | 4 | 08051C474KAT2A KYOCERA AVX | CC0805KKX7R0BB474 YAGEO LCSC C596323 | Same spec, 470 nF ±10 % 100 V X7R 0805, largest LCSC stock (250,730 vs the AVX ALT2's 750, 2026-10-06); specified AVX has no LCSC listing; PoDL front end: Sofar review | CC0805KKX7R0BB474 (YAGEO, C596323) 08051C474K4Z2A (KYOCERA AVX, C597303) 470 nF ±10 % 100 V X7R 0805; PoDL front end: Sofar review | Planned part from LCSC once Sofar approves it (D27); until then the specified part via JLC global sourcing | FP-0805-L_2_01_0_2-W_1_25-MFG
C17, C26 | 2 | C2012X7S2A105K125AB TDK | C2012X7S2A105KT000N TDK LCSC C342785 | TDK C2012 series, same 1 µF ±10 % 100 V X7S 0805 per LCSC (thickness not confirmed: K125AB is 1.25 mm, KT000N doesn't state it); specified number out of stock at LCSC; power path: Sofar review | C2012X7S2A105KT000N (TDK, C342785) GCM21BC72A105KE36L (Murata, C126585) 1 µF ±10 % 100 V X7S 0805; power path: Sofar review | Planned part from LCSC once Sofar approves it (D27); until then the specified part via JLC global sourcing | FP-C2012-125-0_2-MFG
C19, C27 | 2 | C0805C102MDRACTU Kemet | C0805C102KDRACTU KEMET LCSC C2167549 | Same KEMET series, ±10 % instead of ±20 % (tighter); 1 nF 1 kV X7R 0805; specified ±20 % part has no LCSC listing; PoDL front end: Sofar review | C0805C102KDRACTU (KEMET, C2167549) 0805B102K102CT (Walsin, C303890) 1 nF 1 kV X7R 0805, ±10 % (tighter); PoDL front end: Sofar review | Planned part from LCSC once Sofar approves it (D27); until then the specified part via JLC global sourcing | CAPC2013X145X50LL20T25
C20, C29, C49, C50, C54 | 5 | GRM188R72A104KA35D Murata | GRM188R72A104KA35D Murata LCSC C77058 | As specified; in LCSC stock (checked 2026-10-06) | | | FP-GRM188-0_1-e0_2_0_5-IPC_B
C21 | 1 | CL32B106KBJNNNE Samsung | UMK325AB7106KM-T Taiyo Yuden LCSC C386167 | 10 µF ±10 % 50 V X7R 1210 from Taiyo Yuden, an established MLCC maker, for the power path (FH ALT1 has more stock, kept as backup); specified Samsung out of stock at LCSC and DK; Sofar review | 1210B106K500NT (FH, C116808) UMK325AB7106KM-T (Taiyo Yuden, C386167) 10 µF ±10 % 50 V X7R 1210; power path: Sofar review | Planned part from LCSC once Sofar approves it (D27); until then the specified part via JLC global sourcing | FP-CL32-IPC_C
C22, C23 | 2 | EEEFT1H470AP Panasonic | EEEFT1H470AP Panasonic LCSC C92059 | As specified (Sofar review): no potting-safe like-for-like alternate (constraint 8); LCSC listing out of stock: JLC global sourcing | | JLC global sourcing (first build) until an ALT is approved (D26) | FP-FTD-MFG
C30, C55 | 2 | UMK107BBJ225KA-T Taiyo Yuden | UMK107BBJ225KA-T Taiyo Yuden LCSC C268016 | As specified; in LCSC stock (checked 2026-10-06); Taiyo Yuden now lists it as MSASU168BB5225KTNA01 | | | FP-0603-L_1_6_0_2-W_0_8_0-MFG
C31 | 1 | C1608X5R0J226M080AC TDK | CL10A226MQ8NRNC Samsung LCSC C59461 | Same spec, 22 µF ±20 % 6.3 V X5R 0603; specified TDK out of stock at LCSC (and DK until 2027-01) | CL10A226MQ8NRNC (Samsung, C59461) GRM188R60J226MEA0D (Murata, C77042) 22 µF ±20 % 6.3 V X5R 0603 | Planned part from LCSC once Sofar approves it (D27); until then the specified part via JLC global sourcing | CAPC1608X100X20ML10
C32 | 1 | GRJ155R60J106ME11D Murata | GRJ155R60J106ME11D Murata LCSC C469527 | As specified; in LCSC stock (checked 2026-10-06) | | | FP-GRJ155-0_2-MFG
C33 | 1 | GRM155R60J475ME87D Murata

GRM155R60J475ME87D
Murata
As specified; in LCSC stock (checked 2026-10-06) | FP-GRM155-0_15-MFG

C32 | 1 | GRJ155R60J106ME11D Murata

GRJ155R60J106ME11D
Murata
As specified; in LCSC stock (checked 2026-10-06) | FP-GRJ155-0_2-MFG
C33 | 1 | GRM155R60J475ME87D Murata | GRM155R60J475ME87D Murata | As specified; in LCSC stock (checked 2026-10-06) | | FP-GRM155-0_15-MFG
C56, C57 | 2 | GRM21BR61C226ME44L Murata | GRM21BR61C226ME44L Murata LCSC C86817 | As specified; in LCSC stock (checked 2026-10-06) | | C_0805_2012Metric
C58 | 1 | GRM155R61A475MEAAD Murata | GRM155R61A475MEAAD Murata LCSC C335105 | As specified; in LCSC stock (checked 2026-10-06) | | C_0402_1005Metric
D1 | 1 | SMA6F33A STMicroelectronics | SMA6F33A-M3/H Vishay | Sofar's own listed second source (their MANUFACTURERPARTNUMBER1); ST SMA6F33A is obsolete (DK); no LCSC listing found (2026-10-06): JLC global sourcing; Sofar Q7 | JLC global sourcing of Sofar's second source Vishay SMA6F33A-M3/H (ST part obsolete; Sofar Q7) (D26) | SMA6F33A-Footprint-1
D2, D3 | 2 | RB058LAM-60TFTR ROHM | RB058LAM-60TFTR ROHM | As specified; JLC global sourcing (D26): no LCSC listing | JLC global sourcing (D26); no LCSC listing | FP-PMDTM-MFG
D4, D5 | 2 | CDSOD323-T36SC Bourns Inc. | CDSOD323-T36SC Bourns LCSC C911382 | As specified; in LCSC stock (checked 2026-10-06) | | FP-SOD-323-MFG
D8 | 1 | KT-0603R Hubei KENTO Elec | KT-0603R Hubei KENTO LCSC C2286 | As specified; in LCSC stock (checked 2026-10-06) | | LED_0603_1608Metric
D9, D10 | 2 | KT-0603YG Hubei KENTO Elec | KT-0603YG Hubei KENTO LCSC C2289 | As specified; in LCSC stock (checked 2026-10-06) | | LED_0603_1608Metric
J1 | 1 | Raspberry_Pi_2_3 | TBD | Part not chosen: 2×20 2.54 mm female TH socket, height open (Nick) | Part not chosen: 2×20 2.54 mm female TH socket, height open (Nick). Candidates ZHOURI 2.54-2*20 C2977589, Megastar ZX-PM2.54-2-20PY C7499354 (both 8.5 mm) | PinSocket_2x20_P2.54mm_Vertic al
J5 | 1 | SM02B-GHS-TB JST | SM02B-GHS-TB JST LCSC C189893 | As specified; LCSC listing out of stock (2026-10-06): JLC global sourcing | JLC global sourcing (D26); LCSC C189893 out of stock, DK 10,839 | JST_GH_SM02B-GHS-TB_1x02-1MP_P1.25mm_Horizont al
L1, L2 | 2 | SRF1260-101M Bourns | SRF1260-101M Bourns LCSC C6496096 | As specified; in LCSC stock (checked 2026-10-06) (thin margin) | | SRF1260-101M-Footprint-1
L3, L6 | 2 | PA5432.822NLT Pulse (YAGEO group) | PA5432.822NLT Pulse (YAGEO group) | As specified; JLC global sourcing (D26): no LCSC listing | JLC global sourcing (D26); no LCSC listing | FP-PA5432_472NLT-MFG
L4 | 1 | DFE201612E-2R2M=P2 Murata | DFE201612E-2R2M=P2 Murata LCSC C337893 | As specified; in LCSC stock (checked 2026-10-06) | | FP-DFE201612C-MFG
MP1-MP4 | 4 | 78614015360 Wurth Elektronik | 78614015360 Würth Elektronik | As specified; JLC global sourcing (D26): no LCSC listing | JLC global sourcing (D26); no LCSC listing, DK 7,835 | 78614015360-Footprint-2
R1, R44-R46 | 4 | RC0402FR-071K5L Yageo / Phycomp | RC0402FR-071K5L Yageo LCSC C114759 | As specified; in LCSC stock (checked 2026-10-06) | | RESC1005X40X25ML05T10
R2-R6, R26, R27 | 7 | ERJ-2RKF4701X Panasonic | ERJ-2RKF4701X Panasonic LCSC C400631 | As specified; in LCSC stock (checked 2026-10-06) | | RESC1005X40X25LL05T05
R7 | 1 | RC0402JR-0710KL Yageo | RC0402JR-0710KL Yageo | As specified; in LCSC stock (checked 2026-10-06) | | FP-RC0402-0_4-IPC_C
R8 | 1 | UR73D1JTTD10L0F KOA Speer

UR73D1JTTD10L0F
KOA Speer

As specified (Sofar review), JLC global sourcing: no LCSC listing. ROHM PMR03 (ALT1) electrodes (b 0.35 mm, datasheet Rev.PMR03-IA-012E) sit

PMR03EZPFU10L0 (ROHM, C308571) WSLP0603R0100FEA (Vishay,
C5334451)

JLC global sourcing (first build) until an ALT is
approved (D26)

RESC1608X60X55ML20T10

R7 | 1 | RC0402JR-0710KL Yageo

RC0402JR-0710KL
Yageo
As specified; in LCSC stock (checked 2026-10-06) | FP-RC0402-0_4-IPC_C
R8 | 1 | UR73D1JTTD10L0F KOA Speer | UR73D1JTTD10L0F KOA Speer | As specified (Sofar review), JLC global sourcing: no LCSC listing. ROHM PMR03 (ALT1) electrodes (b 0.35 mm, datasheet Rev.PMR03-IA-012E) sit inside these pads, which were drawn for the UR73D1J's 0.55 mm electrodes and reach 0.35 mm under the PMR03 body; ROHM gives no land pattern, so not adopted | PMR03EZPFU10L0 (ROHM, C308571) WSLP0603R0100FEA (Vishay, C5334451) Sofar review: power-path current sense; check land pattern | JLC global sourcing (first build) until an ALT is approved (D26) | RESC1608X60X55ML20T10
R11 (DNP) | 1 | CRCW12100000Z0EA Vishay Dale | CRCW12100000Z0EA Vishay Dale LCSC C844880 | As specified; DNP (not fitted) | | | FP-CRCW1210-e3-IPC_B
R12, R13, R17, R19 | 4 | CRCW12100000Z0EA Vishay Dale | CRCW12100000Z0EA Vishay Dale LCSC C844880 | As specified; in LCSC stock (checked 2026-10-06) | | | FP-CRCW1210-e3-IPC_B
R14, R18 | 2 | RR0510P-101-D Susumu | RT0402BRD07100RL YAGEO LCSC C705627 | 100 Ω thin film 0402, ±0.1 % ±25 ppm (tighter than the specified ±0.5 %); specified Susumu has no LCSC listing; PoDL front end: Sofar review | RT0402BRD07100RL (YAGEO, C705627) ERA2AEB101X (Panasonic, C445575) 100 Ω ±0.1 % ±25 ppm thin film 0402 (tighter); ALT2 AEC-Q200; PoDL front end: Sofar review | Planned part from LCSC once Sofar approves it (D27); until then the specified part via JLC global sourcing | FP-RR0510-IPC_B
R15, R16 | 2 | CRCW08057R50FKEAHP Vishay | CRCW08057R50FKEAHP Vishay Dale | As specified (Sofar review): the only stocked alternate (YAGEO SR0805, ALT1) has no stated pulse rating and ±200 vs ±100 ppm/°C; JLC global sourcing: no LCSC listing | SR0805FR-477R5L (YAGEO, C873769) Sofar review: 7.5 Ω ±1 % 0.5 W, ±200 vs ±100 ppm/°C, pulse rating not stated | JLC global sourcing (first build) until an ALT is approved (D26) | CRCW08057R50FKEAHP-Footprint-1
R20, R39 | 2 | CRCW04021M82FKED Vishay Dale | RTT021824FTH RALEC LCSC C166520 | Only stocked LCSC match: 1.82 MΩ ±1 % 62.5 mW 50 V ±100 ppm 0402; specified Vishay part has no LCSC listing | RTT021824FTH (RALEC, C166520) 1.82 MΩ ±1 % 62.5 mW 50 V ±100 ppm | Planned part from LCSC once Sofar approves it (D27); until then the specified part via JLC global sourcing | FP-CRCW0402-e3-MFG
R21, R35, R37, R43 | 4 | RMCF0402FT100K Stackpole | 0402WGF1003TCE UNI-ROYAL LCSC C25741 | JLC Basic part (no extended-part fee), ample LCSC stock; 100 kΩ ±1 % 62.5 mW 50 V ±100 ppm 0402; specified Stackpole is out of stock at LCSC and is AEC-Q200, this one doesn't state it | 0402WGF1003TCE (UNI-ROYAL, C25741) RC0402FR-07100KL (YAGEO, C60491) 100 kΩ ±1 % 62.5 mW 50 V ±100 ppm; ALT1 is JLC Basic; AEC-Q200 not stated (Stackpole is) | Planned part from LCSC once Sofar approves it (D27); until then the specified part via JLC global sourcing | FP-RMCF0402-IPC_C
R22, R40 | 2 | RC0402FR-07200KL Yageo / Phycomp | RC0402FR-07200KL Yageo LCSC C114763 | As specified; in LCSC stock (checked 2026-10-06) | | | RESC1005X40X25LL05T10
R23 | 1 | RC0402FR-0722K1L Yageo | RC0402FR-0722K1L Yageo LCSC C163478 | As specified; in LCSC stock (checked 2026-10-06) | | | FP-RC0402-0_4-IPC_B
R34 | 1 | RC0402FR-079K09L Yageo / Phycomp | AC0402FR-079K09L YAGEO LCSC C227284 | Same YAGEO 0402 thick-film family, 9.09 kΩ ±1 % 62.5 mW 50 V ±100 ppm; specified part has no LCSC listing; our part (D18), no amendment needed | AC0402FR-079K09L (YAGEO, C227284) 0402WGF9091TCE (UNI-ROYAL, C11549) 9.09 kΩ ±1 % 62.5 mW 50 V ±100 ppm thick film; our part (D18), no amendment | Planned part from LCSC once Sofar approves it (D27); until then the specified part via JLC global sourcing | RESC1005X40X25LL05T10
R38 | 1 | RC0402FR-0713K7L Yageo | RC0402FR-0713K7L Yageo LCSC C274888 | As specified; in LCSC stock (checked 2026-10-06) | | | FP-RC0402-0_4-IPC_B
R41 | 1 | RC0402FR-071ML Yageo | RC0402FR-071ML Yageo LCSC C138033 | As specified; in LCSC stock (checked 2026-10-06) | | | R_0402_1005Metric
R42 | 1 | RMCF0402FT10K0 Stackpole | RMCF0402FT10K0 Stackpole LCSC C6111655 | As specified; in LCSC stock (checked 2026-10-06) | | | FP-RMCF0402-IPC_C
T1, T2 | 2 | 74930000 Würth Elektronik | 74930000 Würth Elektronik | As specified; in LCSC stock (checked 2026-10-06) | | | FP-74930000-MFG
U1 | 1 | ADIN2111BCPZ Analog Devices | ADIN2111BCPZ Analog Devices | As specified; JLC global sourcing (D26): no LCSC listing | | JLC global sourcing (D26); no LCSC listing, DK 120 | ADIN2111BCPZ-Footprint-1

U1 | 1 | ADIN2111BCPZ Analog Devices | ADIN2111BCPZ Analog Devices | As specified; JLC global sourcing (D26): no LCSC listing | JLC global sourcing (D26); no LCSC listing, DK 120 | ADIN2111BCPZ-Footprint-1
U2, U3 | 2 | AP22913CN4-7 Diodes Inc. | AP22913CN4-7 Diodes Inc. LCSC C2150198 | As specified; LCSC has 30 of the 40 needed (2026-10-06): JLC global sourcing for the rest | JLC global sourcing, all 40 (LCSC has 30) (D26) | AP22913CN4-7-Footprint-1
U4 | 1 | INA232AIDDFR Texas Instruments | INA232AIDDFR Texas Instruments LCSC C5447660 | As specified; in LCSC stock (checked 2026-10-06) | | INA232AIDDFR-Footprint-1
U5, U10 | 2 | LMR51430YDDCR Texas Instruments | LMR51430YDDCR Texas Instruments LCSC C5210749 | As specified; in LCSC stock (checked 2026-10-06) | | SOT-23-THIN-6_DDC_TEX
U6 | 1 | TPS62840YBGR Texas Instruments | TPS62840YBGR Texas Instruments LCSC C2071139 | As specified; in LCSC stock (checked 2026-10-06) | | FP-YBG0006-MFG
U11 | 1 | TPS26621DRCR Texas Instruments | TPS26621DRCR Texas Instruments LCSC C1848341 | As specified; in LCSC stock (checked 2026-10-06) | | Texas_DRC0010J
Y1 | 1 | ABM11W-25.0000MHZ-6-K1Z-T3 Abracon | ABM11W-25.0000MHZ-6-K1Z-T3 Abracon | As specified; JLC global sourcing (D26): no LCSC listing | JLC global sourcing (D26); no LCSC listing, DK 87 | FP-ABM11W-MFG

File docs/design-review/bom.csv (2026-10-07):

Refs | Qty | Value (MPN) | Mfr | Planned MPN | Planned Mfr | Planned LCSC | Planned note | DNP | Sourcing | Alt1 MPN | Alt1 Mfr | Alt1 LCSC | Alt2 MPN | Alt2 Mfr | Alt2 LCSC | Alt note | Footprint
C1,C3,C9-C15,C28,C53 | 11 | CL05A104KA5NNNC | Samsung | CL05A104KA5NNNC | Samsung | C100072 | As specified; in LCSC stock (checked 2026-10-06) |  |  |  |  |  |  |  |  |  | Vault:FP-CL278-IPC_C
C2,C4 | 2 | CL05A105KP5NNNC | Samsung | CL05A105KP5NNNC | Samsung | C14445 | As specified; in LCSC stock (checked 2026-10-06) |  |  |  |  |  |  |  |  |  | Vault:FP-CL511-IPC_C
C5,C6 | 2 | CC0402KRX5R6BB684 | YAGEO | CC0402KRX5R6BB684 | Yageo | C113784 | As specified; in LCSC stock (checked 2026-10-06) |  |  |  |  |  |  |  |  |  | Vault:FP-CC0402-MFG
C7,C8 | 2 | CC0402JRNPO9BN150 | Yageo | CC0402JRNPO9BN150 | Yageo | C106997 | As specified; in LCSC stock (checked 2026-10-06) |  |  |  |  |  |  |  |  |  | Vault:FP-CC0402-0_55-IPC_B
C16,C18,C24,C25 | 4 | 08051C474KAT2A | KYOCERA AVX | CC0805KKX7R0BB474 | YAGEO | C596323 | Same spec, 470 nF ±10 % 100 V X7R 0805, largest LCSC stock (250,730 vs the AVX ALT2's 750, 2026-10-06); specified AVX has no LCSC listing; PoDL front end: Sofar review |  | Planned part from LCSC once Sofar approves it (D27); until then the specified part via JLC global sourcing | CC0805KKX7R0BB474 | YAGEO | C596323 | 08051C474K4Z2A | KYOCERA AVX | C597303 | 470 nF ±10 % 100 V X7R 0805; PoDL front end: Sofar review | Vault:FP-0805-L_2_01_0_2-W_1_25-MFG
C17,C26 | 2 | C2012X7S2A105K125AB | TDK | C2012X7S2A105KT000N | TDK | C342785 | TDK C2012 series, same 1 µF ±10 % 100 V X7S 0805 per LCSC (thickness not confirmed: K125AB is 1.25 mm, KT000N doesn't state it); specified number out of stock at LCSC; power path: Sofar review |  | Planned part from LCSC once Sofar approves it (D27); until then the specified part via JLC global sourcing | C2012X7S2A105KT000N | TDK | C342785 | GCM21BC72A105KE36L | Murata | C126585 | 1 µF ±10 % 100 V X7S 0805; power path: Sofar review | Vault:FP-C2012-125-0_2-MFG
C19,C27 | 2 | C0805C102MDRACTU | Kemet | C0805C102KDRACTU | KEMET | C2167549 | Same KEMET series, ±10 % instead of ±20 % (tighter); 1 nF 1 kV X7R 0805; specified ±20 % part has no LCSC listing; PoDL front end: Sofar review |  | Planned part from LCSC once Sofar approves it (D27); until then the specified part via JLC global sourcing | C0805C102KDRACTU | KEMET | C2167549 | 0805B102K102CT | Walsin | C303890 | 1 nF 1 kV X7R 0805, ±10 % (tighter); PoDL front end: Sofar review | Vault:CAPC2013X145X50LL20T25
C20,C29,C49,C50,C54 | 5 | GRM188R72A104KA35D | Murata | GRM188R72A104KA35D | Murata | C77058 | As specified; in LCSC stock (checked 2026-10-06) |  |  |  |  |  |  |  |  |  | Vault:FP-GRM188-0_1-e0_2_0_5-IPC_B
C21 | 1 | CL32B106KBJNNNE | Samsung | UMK325AB7106KM-T | Taiyo Yuden | C386167 | 10 µF ±10 % 50 V X7R 1210 from Taiyo Yuden, an established MLCC maker, for the power path (FH ALT1 has more stock, kept as backup); specified Samsung out of stock at LCSC and DK; Sofar review |  | Planned part from LCSC once Sofar approves it (D27); until then the specified part via JLC global sourcing | 1210B106K500NT | FH | C116808 | UMK325AB7106KM-T | Taiyo Yuden | C386167 | 10 µF ±10 % 50 V X7R 1210; power path: Sofar review | Vault:FP-CL32-IPC_C
C22,C23 | 2 | EEEFT1H470AP | Panasonic | EEEFT1H470AP | Panasonic | C92059 | As specified (Sofar review): no potting-safe like-for-like alternate (constraint 8); LCSC listing out of stock: JLC global sourcing |  | JLC global sourcing (first build) until an ALT is approved (D26) |  |  |  |  |  |  | Sofar review: bus damping; a newly sourced replacement must be potting-safe (constraint 8), so no like-for-like alternate; JLC global sourcing | Vault:FP-FTD-MFG
C30,C55 | 2 | UMK107BBJ225KA-T | Taiyo Yuden | UMK107BBJ225KA-T | Taiyo Yuden | C268016 | As specified; in LCSC stock (checked 2026-10-06); Taiyo Yuden now lists it as MSASU168BB5225KTNA01 |  |  |  |  |  |  |  |  |  | Vault:FP-0603-L_1_6_0_2-W_0_8_0-MFG
C31 | 1 | C1608X5R0J226M080AC | TDK | CL10A226MQ8NRNC | Samsung | C59461 | Same spec, 22 µF ±20 % 6.3 V X5R 0603; specified TDK out of stock at LCSC (and DK until 2027-01) |  | Planned part from LCSC once Sofar approves it (D27); until then the specified part via JLC global sourcing | CL10A226MQ8NRNC | Samsung | C59461 | GRM188R60J226MEA0D | Murata | C77042 | 22 µF ±20 % 6.3 V X5R 0603 | Vault:CAPC1608X100X20ML10
C32 | 1 | GRJ155R60J106ME11D | Murata | GRJ155R60J106ME11D | Murata | C469527 | As specified; in LCSC stock (checked 2026-10-06) |  |  |  |  |  |  |  |  |  | Vault:FP-GRJ155-0_2-MFG
C33 | 1 | GRM155R60J475ME87D | Murata | GRM155R60J475ME87D | Murata | C76996 | As specified; in LCSC stock (checked 2026-10-06) |  |  |  |  |  |  |  |  |  | Vault:FP-GRM155-0_15-MFG
C56,C57 | 2 | GRM21BR61C226ME44L | Murata | GRM21BR61C226ME44L | Murata | C86817 | As specified; in LCSC stock (checked 2026-10-06) |  |  |  |  |  |  |  |  |  | Capacitor_SMD:C_0805_2012Metric
C58 | 1 | GRM155R61A475MEAAD | Murata | GRM155R61A475MEAAD | Murata | C335105 | As specified; in LCSC stock (checked 2026-10-06) |  |  |  |  |  |  |  |  |  | Capacitor_SMD:C_0402_1005Metric
D1 | 1 | SMA6F33A | STMicroelectronics | SMA6F33A-M3/H | Vishay |  | Sofar's own listed second source (their MANUFACTURERPARTNUMBER1); ST SMA6F33A is obsolete (DK); no LCSC listing found (2026-10-06): JLC global sourcing; Sofar Q7 |  | JLC global sourcing of Sofar's second source Vishay SMA6F33A-M3/H (ST part obsolete; Sofar Q7) (D26) |  |  |  |  |  |  |  | Vault:SMA6F33A-Footprint-1
D2,D3 | 2 | RB058LAM-60TFTR | ROHM | RB058LAM-60TFTR | ROHM |  | As specified; JLC global sourcing (D26): no LCSC listing |  | JLC global sourcing (D26); no LCSC listing |  |  |  |  |  |  |  | Vault:FP-PMDTM-MFG
D4,D5 | 2 | CDSOD323-T36SC | Bourns Inc. | CDSOD323-T36SC | Bourns | C911382 | As specified; in LCSC stock (checked 2026-10-06) |  |  |  |  |  |  |  |  |  | Vault:FP-SOD-323-MFG
D8 | 1 | KT-0603R | Hubei KENTO Elec | KT-0603R | Hubei KENTO | C2286 | As specified; in LCSC stock (checked 2026-10-06) |  |  |  |  |  |  |  |  |  | LED_SMD:LED_0603_1608Metric
D9,D10 | 2 | KT-0603YG | Hubei KENTO Elec | KT-0603YG | Hubei KENTO | C2289 | As specified; in LCSC stock (checked 2026-10-06) |  |  |  |  |  |  |  |  |  | LED_SMD:LED_0603_1608Metric
J1 | 1 | Raspberry_Pi_2_3 |  | TBD |  |  | Part not chosen: 2×20 2.54 mm female TH socket, height open (Nick) |  | Part not chosen: 2×20 2.54 mm female TH socket, height open (Nick). Candidates ZHOURI 2.54-2*20 C2977589, Megastar ZX-PM2.54-2-20PY C7499354 (both 8.5 mm) |  |  |  |  |  |  |  | Connector_PinSocket_2.54mm:PinSocket_2x20_P2.54mm_Vertical
J5 | 1 | SM02B-GHS-TB | JST | SM02B-GHS-TB | JST | C189893 | As specified; LCSC listing out of stock (2026-10-06): JLC global sourcing |  | JLC global sourcing (D26); LCSC C189893 out of stock, DK 10,839 |  |  |  |  |  |  |  | Connector_JST:JST_GH_SM02B-GHS-TB_1x02-1MP_P1.25mm_Horizontal
L1,L2 | 2 | SRF1260-101M | Bourns | SRF1260-101M | Bourns | C6496096 | As specified; in LCSC stock (checked 2026-10-06) (thin margin) |  |  |  |  |  |  |  |  |  | Vault:SRF1260-101M-Footprint-1
L3,L6 | 2 | PA5432.822NLT | Pulse (YAGEO group) | PA5432.822NLT | Pulse (YAGEO group) |  | As specified; JLC global sourcing (D26): no LCSC listing |  | JLC global sourcing (D26); no LCSC listing |  |  |  |  |  |  |  | Vault:FP-PA5432_472NLT-MFG
L4 | 1 | DFE201612E-2R2M=P2 | Murata | DFE201612E-2R2M=P2 | Murata | C337893 | As specified; in LCSC stock (checked 2026-10-06) |  |  |  |  |  |  |  |  |  | Vault:FP-DFE201612C-MFG
MP1-MP4 | 4 | 78614015360 | Wurth Elektronik | 78614015360 | Würth Elektronik |  | As specified; JLC global sourcing (D26): no LCSC listing |  | JLC global sourcing (D26); no LCSC listing, DK 7,835 |  |  |  |  |  |  |  | Vault:78614015360-Footprint-2
R1,R44-R46 | 4 | RC0402FR-071K5L | Yageo / Phycomp | RC0402FR-071K5L | Yageo | C114759 | As specified; in LCSC stock (checked 2026-10-06) |  |  |  |  |  |  |  |  |  | Vault:RESC1005X40X25ML05T10
R2-R6,R26,R27 | 7 | ERJ-2RKF4701X | Panasonic | ERJ-2RKF4701X | Panasonic | C400631 | As specified; in LCSC stock (checked 2026-10-06) |  |  |  |  |  |  |  |  |  | Vault:RESC1005X40X25LL05T05
R7 | 1 | RC0402JR-0710KL | Yageo | RC0402JR-0710KL | Yageo | C60489 | As specified; in LCSC stock (checked 2026-10-06) |  |  |  |  |  |  |  |  |  | Vault:FP-RC0402-0_4-IPC_C
R8 | 1 | UR73D1JTTD10L0F | KOA Speer | UR73D1JTTD10L0F | KOA Speer |  | As specified (Sofar review), JLC global sourcing: no LCSC listing. ROHM PMR03 (ALT1) electrodes (b 0.35 mm, datasheet Rev.PMR03-IA-012E) sit inside these pads, which were drawn for the UR73D1J's 0.55 mm electrodes and reach 0.35 mm under the PMR03 body; ROHM gives no land pattern, so not adopted |  | JLC global sourcing (first build) until an ALT is approved (D26) | PMR03EZPFU10L0 | ROHM | C308571 | WSLP0603R0100FEA | Vishay | C5334451 | Sofar review: power-path current sense; check land pattern | Vault:RESC1608X60X55ML20T10
R11 | 1 | CRCW12100000Z0EA | Vishay Dale | CRCW12100000Z0EA | Vishay Dale | C844880 | As specified; DNP (not fitted) | DNP |  |  |  |  |  |  |  |  | Vault:FP-CRCW1210-e3-IPC_B
R12,R13,R17,R19 | 4 | CRCW12100000Z0EA | Vishay Dale | CRCW12100000Z0EA | Vishay Dale | C844880 | As specified; in LCSC stock (checked 2026-10-06) |  |  |  |  |  |  |  |  |  | Vault:FP-CRCW1210-e3-IPC_B
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

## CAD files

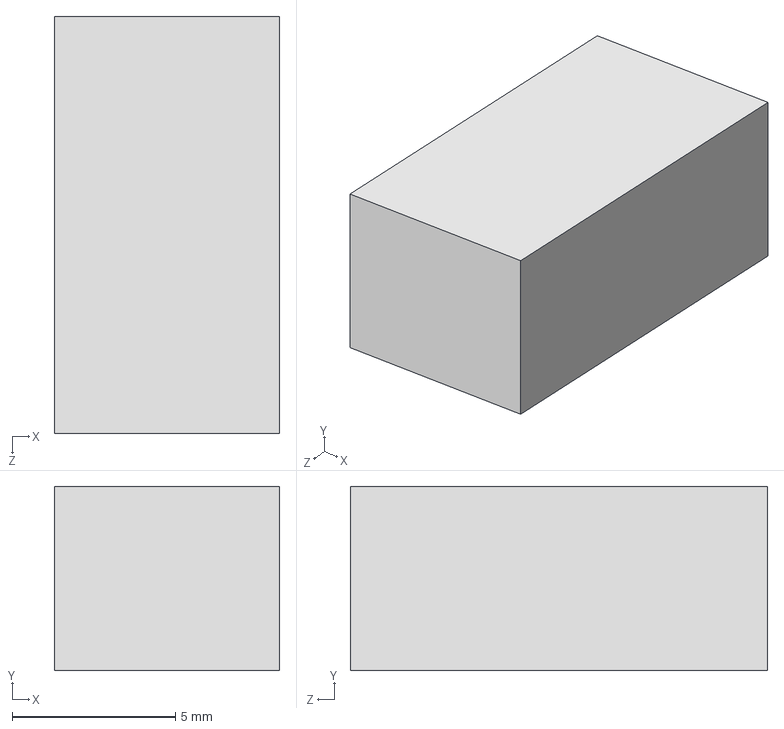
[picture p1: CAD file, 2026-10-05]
KiCAD_reference_designs/UrchinCam-main/UrchinCam_Expander_PCBA_01/3Dmodels/Ethernet_Magnetics_TS8121CMHF.STEP
6.90 x 5.65 x 12.8 mm

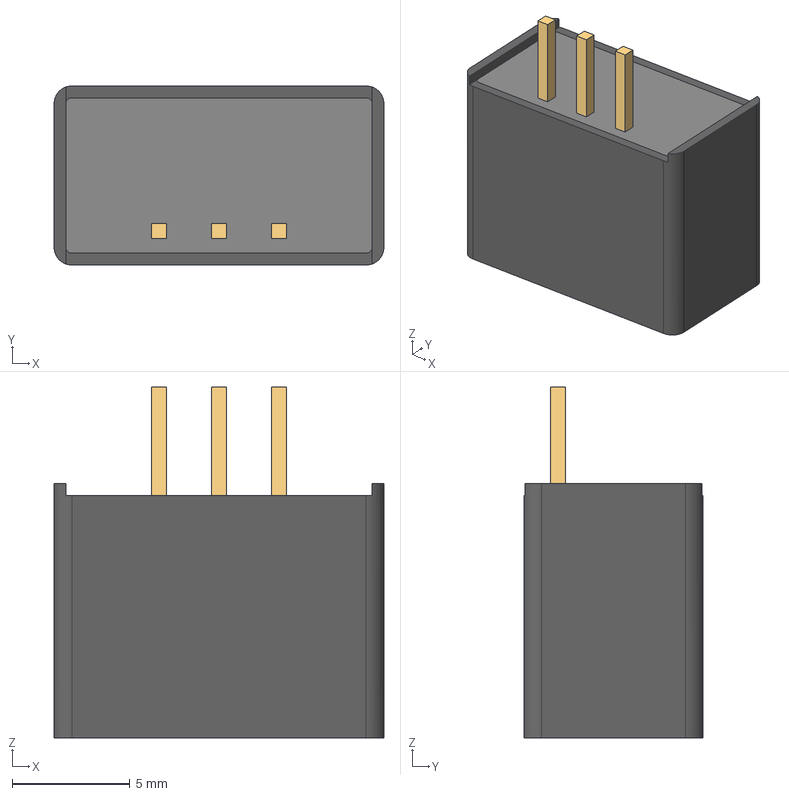
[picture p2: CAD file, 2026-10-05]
KiCAD_reference_designs/UrchinCam-main/UrchinCam_Expander_PCBA_01/3Dmodels/tsr3n_3d-drawing.stp
14.0 x 7.60 x 14.9 mm
CASE-00
膠-00
PIN-00 x 3

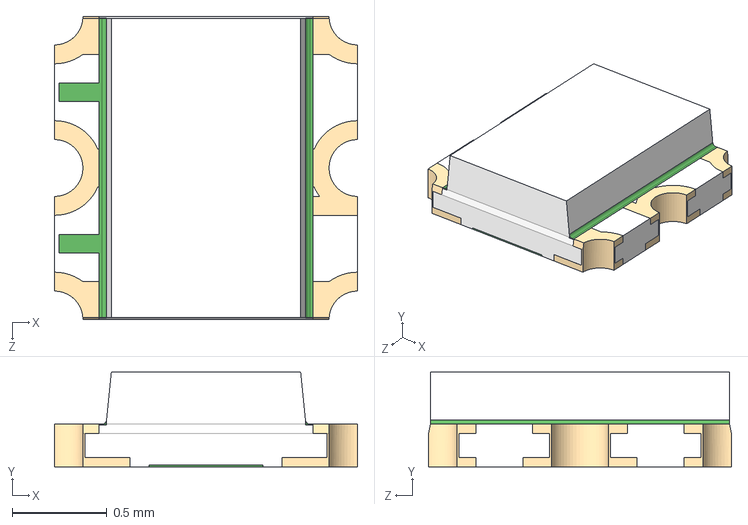
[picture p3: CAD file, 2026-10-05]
KiCAD_reference_designs/UrchinCam-main/UrchinCam_Expander_PCBA_01/3Dmodels/4T--3DModel-STEP-56544.STEP
1.60 x 0.5 x 1.60 mm

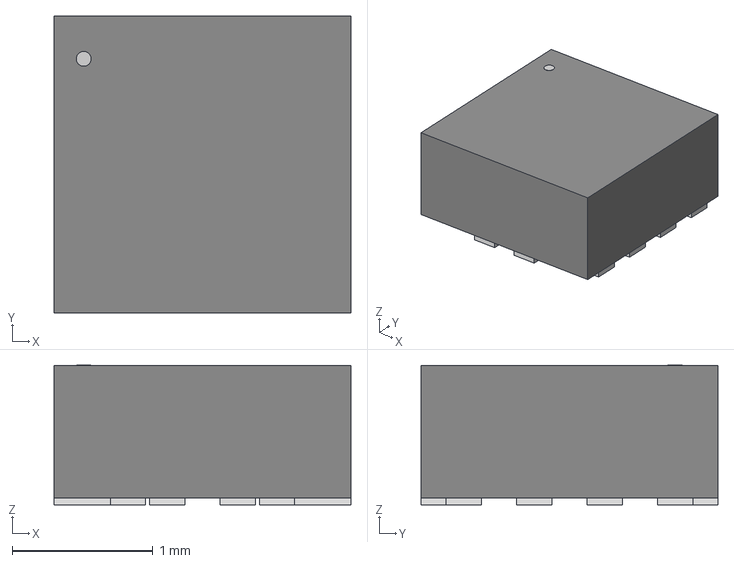
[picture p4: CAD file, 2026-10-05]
KiCAD_reference_designs/UrchinCam-main/UrchinCam_Expander_PCBA_01/3Dmodels/IC12_MP6550_MNP.step
2.11 x 2.11 x 0.993 mm

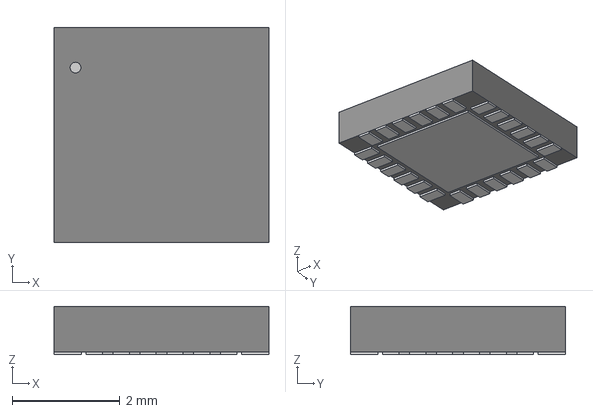
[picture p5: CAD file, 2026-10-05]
KiCAD_reference_designs/UrchinCam-main/UrchinCam_Expander_PCBA_01/3Dmodels/RTL8152B-VB-CG_RTK.step
3.99 x 3.99 x 0.892 mm

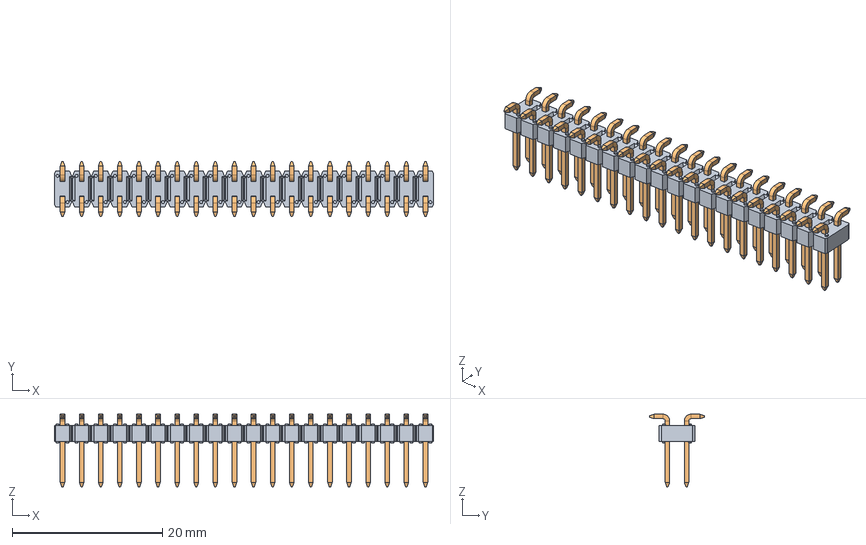
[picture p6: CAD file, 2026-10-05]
KiCAD_reference_designs/UrchinCam-main/UrchinCam_Expander_PCBA_01/3Dmodels/95278_y01_40_asm.stp
50.4 x 7.29 x 9.66 mm
77310_YXXSMT x 40

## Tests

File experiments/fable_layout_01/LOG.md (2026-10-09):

# LOG — layout experiment 01

*One entry per milestone, newest last. Board frame = KiCad board coordinates (mm): the Pi Zero's north-west corner is
(0, 0), x east, y south (BRIEF §2), so KiCad shows the brief's numbers directly.*

## M0 — workspace, schematic copy, board from the netlist (2026-10-07)

- Branch `experiment/fable-layout-01` from `main` (a5f812c). Copied `nereus_Pi_shield_ADIN2111/` (7 sheets, .kicad_pro,
  lib tables, 2 .kicad_sym, mote.pretty, nereus.pretty) into `board/`, without the old `.kicad_pcb`.
- **No schematic edit.** The brief's one allowed edit (J5 → Molex Micro-Fit) was made and then reverted on Nick's
  instruction (2026-10-07: "use the JST footprint like in the schematic, not the molex in the brief"), so `board/`
  holds the live schematic unchanged: J5 = SM02B-GHS-TB, `Connector_JST:JST_GH_SM02B-GHS-TB_1x02-1MP_P1.25mm_Horizontal`.
  ERC on the copy: `ERC messages: 494  Errors 0  Warnings 494`, the same as the live project. Netlist: 134
  components, 109 nets.
- `tools/build_board.py` (pcbnew): new board, 6 copper layers with the mote's names and roles (Top Layer, Internal 1,
  GND Plane [power], Internal 2, PWR Plane [power], 6 Bottom Layer), 1.6 mm. Every netlist component gets its footprint
  from `Vault` / `nereus` / the stock KiCad 9 libraries, its schematic path, DNP (R11) and exclude-from-BOM flags, and
  every numbered pad its net (the only numbered pads without a schematic node are J5's two mechanical tab pads `MP`, which carry no net). H1–H4 `MountingHole_2.7mm_M2.5` added as
  board-only footprints at the §3 positions. 138 footprints. Parts parked on a grid at x ≥ 70 mm for now.
- Board rules in the `.kicad_pro` (plain JSON edit): min track 0.15, via 0.45 / drill 0.20 (BRIEF §6: the mote's own
  0.45 vias and 0.254 drills must pass), hole clearance 0.25, edge clearance 0.5; one netclass `Default` 0.2 / 0.2 /
  via 0.6–0.3 (Sofar's values; the imported duplicate "All Nets" class dropped). The brief's larger widths and
  clearances for **new** routing are enforced by the experiment's own check script (M4), so that Sofar's copied
  0.2 mm copper is not flagged by DRC.
- Check: `kicad-cli pcb drc --schematic-parity --severity-all` → `out/m0/drc_summary.txt`. Parity: **no missing or
  extra footprints**; 4 `net_conflict` warnings "No pad found for pin 1" on MP1–MP4 — Sofar's insert footprint has no
  numbered pad (SPEC fact, Sofar Q6), expected and carried as a known item. The 272 other items are the parked grid
  (overlaps, no outline yet) and the usual import leftovers; they are M1/M2's job.
- Render: `out/m0/render_top.png` (parked grid).
- Stackup: pcbnew's Python has no stackup API; a standard 6-layer 1.6 mm build is written into the board file's setup
  in M1 and noted as an assumption (Sofar Q11).

## M1 — outline, J1, holes, inserts with Sofar's ring copper, J5, envelopes (2026-10-07)

- **Pipeline:** `tools/build_all.sh [m1|m2|…]` rebuilds the board from the schematic every time (M0 build, then
  `m1_fixed.py`, `m2_place.py`, …). No script edits a board in place: a first attempt at an idempotent M1 (remove the
  previous run's items, redraw) crashed KiCad's Python (segfault in `board.Remove`, crash report from Nick 22:39), so
  the pipeline is the only way the board changes. Milestone outputs: `out/m<n>/` (DRC summary, renders, layer SVGs).
- **Frame:** board coordinates = the brief's frame (Pi NW corner (0,0), x east, y south); aux origin at (0,0).
- **Outline** 46 × 65 mm, r 3 corners, on Edge.Cuts (x −7.5…38.5, y 0…65). **Stackup** written into the board file:
  generic 6-layer 1.6 mm (35 µm copper ×6, FR4 prepreg 0.21 ×3, core 0.38 ×2; assumption, Sofar Q11).
- **J1** flipped to the bottom, orientation 180 (KiCad mirrors a flipped footprint's local y; the 180 puts pin 2 east and
  the pins south). Proven by pads: pin 1 (25.230, 8.370), pin 2 (27.770, 8.370), pin 39 (25.230, 56.630), pin 40
  (27.770, 56.630), seen from the top.
- **Holes:** H1–H4 (board-only, M2.5) and MTG1–MTG4 (Vault Hole_M3) at the §3 positions. The M3 silk circle (r 4.0)
  is clipped to the arcs that lie ≥ 0.3 mm inside the outline (per instance). MTG courtyards (±4.25) cross the outline
  at the corners and overlap H1/H3's courtyard by 0.25 mm (both positions are the brief's): 2 `courtyards_overlap`
  errors to exclude with that reason in M5.
- **Inserts:** MP1–MP4 at x −1.81, y 12.0 / 21.4 / 43.6 / 53.0, bottom side, Sofar's footprint orientation (176°).
  Their contact copper is **Sofar's MP1 ring copied by translation** (blocks RING_MP1…4 in `blocks.json`, via
  `tools/motecopy.py`): one C arc r 3.03 mm, 1.2 mm wide, 290°, on Top Layer, gap facing the west edge, plus seven
  0.6/0.254 mm vias at r 3.0 mm, on the insert's bus net (BM2_P, BM2_N, BM1_P, BM1_N north → south). The import's
  zero-size NPTH pad on the insert footprint is given its drill size (4.4 mm) on the four board instances
  (`padstack_invalid` on the mote; 4 `lib_footprint_mismatch` warnings as a result). Insert pull-back: four rule
  areas r 4.8 mm "no copper pour" on all six copper layers (tracks allowed, so the bus feed can enter the ring).
- **J5** (JST GH, per Nick) at (15.0, 61.8), rotation 0: housing front 0.75 mm inside the south edge, tab copper 0.5 mm
  from it, centred at x 15.0 between the Pi's south holes.
- **Envelopes:** L1/L2 centred in their 15.5 × 15.5 envelopes at (12.74, 44.25) / (12.74, 16.75), top side, Sofar's
  90° for now (M2 may rotate the port blocks); envelope rectangles on Eco1.User, +2 mm clearance on Eco2.User.
- **Check:** `tools/check_fixed.py` → every §3 position within 0.001 mm, J1 pins proven, rings verified (arc
  radius/width/angle/net, 7 vias 0.6/0.254), keep-outs clear (holes are not "parts"; 122 parts still parked). 0 failures.
- **DRC** (`out/m1/drc_summary.txt`): on placed items the only errors are the insert contact as Sofar drew it
  (28 `shorting_items`: bus via in the net-less insert pad; 36 `hole_clearance`: arc/vias 0.23 mm from the 4.4 mm
  hole, as on the mote; 8 `solder_mask_bridge`) and the 2 MTG/H courtyard overlaps; the rest is the parked grid.
  Parity unchanged (MP1–4 pin 1, Q6).
- **Renders:** `out/m1/render_top.png`, `render_bottom.png`, `out/m1/layers/*.svg`.

## M2 — all parts placed; blocks rigid, transforms in blocks.json (2026-10-07)

- **Where the brief's blocks could not stay whole** (the fixed items leave three strips: the band between the inductor
  envelopes, 8.0 mm tall; the strip east of J1, 8.9 mm wide; the west pocket, 10.0 mm wide):
  - PORT1/PORT2: the transformer cluster sits 9.6 mm from the inductor's centre on the mote, inside the 50 W envelope +
    2 mm, so each port is two rigid pieces: **P1L/P2L** = inductor + the bottom-side parts Sofar put under it (D4, R12,
    R13, TP3, TP5 + C17, D2 under L1; D5, R17, R19, TP7, TP13 + C26 under L2) and **P1T/P2T** = T1/T2 with C16, C18,
    C19, R14 / C24, C25, C27, R18, in the band. The inductor–transformer copper becomes new routing (M4).
  - BUCK3V3: the U5 cell (U5, C30, L3, the bottom-side C28, C29, R20–R23, its pours and In3 GND patch) is 8.55 mm wide
    and fits the strip; the output cap **C31** is placed beside it (with C31 the cell is 9.65 mm). **B5V** is the same
    cell copied again with its parts mapped by function (U10, C55, L6, C53, C54, R39, R37, R40, R38; checked by nets);
    C56/C57/C58/TP38 placed on the bottom under L6.
  - SPINE: **SENSE** = R8 + U4 + R7 + C15 + TP22 with C23 above them (Sofar's sense routing stays), rotated 90 in the
    strip; **DAMP1** = C21 + R16 (+ C20, TP23) in the south-west pocket; **DAMP2** = C22 in the strip with R15 beside it
    (R15 would have landed under J1 or off the edge); D1 in the south-east pocket; C17/D2 and C26 ride under L1/L2.
  - ADIN: whole, in the west pocket (option (a)), **rotated 90** so port 1's data pins face north toward T1 (≈ 5 mm) and
    port 2's face south (T2 reached under the band, ≈ 18 mm); U1's courtyard x −6.3…2.9 stays west of the envelope
    clearance line (2.99) and ≥ 4.8 mm from both inserts. U2 ends 4.95 mm from MP1 (the tightest spot).
  - BUCK1V8 (**B18**, all bottom) under the band east of T2; LOAD placed fresh around U11 at the strip's south end.
- **Interpretation recorded (for Nick):** the 2 mm envelope clearance is applied to top-side parts; bottom-side parts
  may sit under an inductor as Sofar placed them (the 50 W part is a top-side volume). Without this the port blocks
  could not be copied at all.
- Fresh parts: LEDs D10/D8/D9 north→south in a column at the band's east end (x 20.3) with JP2 and R44–R46 under them;
  JP1 on the bottom beside J1 pins 2/4 (no room on top: cut before stacking); R26/R27, TP20, TP24 bottom east of J1;
  D1 (SE pocket), fiducials FID3/4/5 top and FID1/2/6 bottom at (8, 2.5), (21.5, 2.5), (15, 56).
- Heights: `heights.json` (datasheet maxima per footprint; J1 exempt as the stacking socket). Every bottom part ≤ 1.5 mm.
- Checks: `check_fixed.py --heights` 0 failures (positions, keep-outs, envelope clearance, heights); DRC
  `out/m2/drc_summary.txt`: **courtyard overlaps 12** = the 2 MTG/H pairs (M1) + **10 pairs inside Sofar's own blocks**
  (U4/C15, U4/R7, TP22/R8, TP5/R13, R12/D2, C10/TP1, C4/C12, TP21/U6, U5/C30, U10/C55): Sofar's placement with the
  courtyards S6.c added; copying rigidly keeps them (to exclude with that reason). 4 clearance errors are T1/T2's
  unnumbered footprint pads lying on pads 3/4 (Sofar's footprint, as on the mote). Default netclass clearance set to the
  brief's 0.15 mm for signals (§6); larger classes are enforced on new routing by script (M4).
- Renders: `out/m2/render_top.png`, `render_bottom.png`.

## M3 — block copper copied; blockcheck 100 % (2026-10-07)

- `tools/m3_copy.py` copies every block's tracks, vias and island pours with the block transform through
  `motecopy.select` (one selection rule shared with the checker): copper on the block's pad nets inside its region
  rect(s), tracks crossing a rect boundary clipped at it (the stub is where new routing continues), zones only when
  wholly inside (ADIN_VDDIO / ADIN_AVDD islands under U1; the U5 cell's switch-node pour, its In3 GND patch and the
  3V3 output pour clipped at the strip edge). The big GND / VBUS / 3V3 / P_IN planes are M4's. Nets mapped by pad.
- `tools/blockcheck.py` → `out/m3/blockcheck.md`: **1,064 items, 0 missing, 0 extra** within 0.001 mm (pads 385/385,
  tracks 660/660, arcs 4/4, vias 207/207, zones 6/6). The ring blocks copied in M1 are checked the same way.
- What the checker caught on the way: KiCad silently re-nets a copied via or track that lands on a pad of another net
  (it reports the item on the pad's net), so three fresh parts that sat on copied copper (R15, C57, TP24) showed up as
  "missing" with the wrong net; they were moved to spots proven free against the copied vias. B5V's rows were sat on
  B33's clipped stubs the same way; the strip stack is B33 7.8–20.25, C31 beside U5, B5V 21.5–33.95, SENSE 35.5–43.0,
  DAMP2 43.3–52.1, U11 row 52.3–56.3 (y, mm).
- Regions were tightened so clipped stubs stay ≥ 0.5 mm from the east edge (B33/B5V x ≤ 146.4 mote, SENSE y ≤ 120.2,
  DAMP2 y ≤ 107.0) and P2T's bus-leg stubs no longer reach the LED column (x ≥ 133.0).
- B18 rotated 90 east of L1 beside J1 (its 1V8 copper hit D2 under L1); LEDs at x 21.5 with JP2/R44–R46 under them.
- DRC `out/m3/drc_summary.txt`: unconnected 216 (M4); errors only in the known groups: insert contact (28 shorting,
  36 hole-clearance, 8 mask-bridge, 4 padstack), T1/T2's unnumbered pads (4 clearance, 6 shorting, 10 mask-bridge,
  as on the mote), courtyards 12 (10 Sofar intra-block + 2 MTG/H).
- Renders: `out/m3/render_top.png`, `render_bottom.png`, `out/m3/layers/*.svg`.

## M4 — planes, routing, zone fill (2026-10-08)

- **Planes** (`tools/m4_route.py planes()`): GND on In2 (0.5 mm from the edge) with one 0.5 mm slot past each
  inductor on the band side and one on the outer side (port 2: y 6.5–7.0 and 26.2–26.7; port 1: 39.0–39.5 and
  54.0–54.5, x −7.5…22.7), so each inductor island joins the plane only on its east (far) side; the insert pull-backs
  (r 4.8, M1) cut both planes. PWR plane In4 split: VBUS (the strip east of J1, the whole west half from y 26 down, and
  port 2's east x 16.8–23.2), P_IN island under port 2's east half (x 11–16.6, y 8–25.7; R8 straddles the boundary),
  a 3V3 island at the 3.3 V buck output (x 33.4–38, y 8–23), the copied ADIN_AVDD / ADIN_VDDIO islands (priority 7)
  and Sofar's two no-net islands (NoConnect_P2 / _P1, 6 × 6.5 mm between each port's inserts and its inductor, Q10).
  5V_PI is a bottom-side pour x 29.7–38, y 7.5–26.5 from L6's output to JP1 (BRIEF §6 "≥ 1.0 mm or a pour").
- **Router** (`tools/router.py`, pure Python, no numpy in KiCad's Python): 0.1 mm grid, four routing layers (Top,
  Internal 1, Internal 2, Bottom), through vias; every existing copper item stamped with its net and dilated per class
  (strict halos, pre-existing copper inflated by half a cell diagonal so off-grid vias and pads keep their clearance);
  exact board-edge distance map; A* per cluster pair from the whole copper cluster (copied stubs count), 8-way except
  the 0.15 mm fan-out class (orthogonal only). Classes (§6): bus 1.0/0.35, power 0.5/0.25, Pi 5 V 1.0/0.25, payload
  0.6/0.25, rail 0.3/0.15, signal 0.2/0.15, fan-out 0.15/0.15; fallbacks to the next class are logged.
- **Order:** insert feeds by hand (1.5 mm, Top, ring → inductor bus pad); the ADIN pairs on Top + Internal 1 (inner
  pin first); two hand-laid 0.15 mm links (U11 pin 7 → R34, U11 pin 1 → a via into the VBUS plane) and U3's 3V3 escape
  on Internal 2 between Sofar's vias; GND pads given a via within 1.2 mm (except in the ADIN pocket); U11's west-side
  signals; the rest short-first; then stitching vias from every plane-net cluster into its plane (up to 16 spots
  tried); plane leftovers by track; zone fill; split pour islands joined and refilled.
- **Result** (`out/m4/routing.json`, `drc_summary.txt`): 216 open connections → **2**: U3's 3V3 (its hand-laid escape
  reaches (2.5, 38.0) on Internal 2 but no path continues: the pocket's south exit is shared with the port-2 pair,
  1V8 and ADIN_PWR) and J1 pins 1/17, which the schematic puts on one no-connect net (`unconnected-(J1-3V3-Pad1)`, the
  Pi's 3V3: SPEC constraint 4, left open on purpose). 72 stitching vias. ADIN pairs: BM1 7.9 / 9.4 mm (≤ 9.5), BM2
  21.3 / **23.4** mm (≤ 21.3: N is 2.1 mm over; P/N skew 2.1 mm vs the mote's 3.0). DRC errors are only the known
  groups (insert contact 92, T1/T2 footprint pads 22, courtyards 12) — see M5 exclusions; blockcheck still 0 missing.
- **What did not work, kept in the script behind flags:** rip-up rounds (RIPUP_ROUNDS) thrashed; routing the pocket's
  nets first or stitching before the signals each boxed a different net in. The ADIN pocket (U1 rotated into the
  10 mm west pocket) has three exits — the one-track lane along the west edge, the strip north of the pins and the
  strip south of U2/U3 — for ten nets; this is the layout's weak spot (REPORT).
- Placement changes made for routing (all in `tools/m2_place.py`): T1 at (8.7, 28.4), T2 at (16.0, 32.3), the ADIN
  block 0.3 mm east (allowance recorded), U11's group 1 mm east with R34/R41 on the top beside it, R35 bottom at
  (17.5, 58.5), D3/C50 under U11's thermal-pad side, R15 beside C22, R26/R27/TP24/TP20/C56–C58/TP38 in via-free spots.
- Renders: `out/m4/render_top.png`, `render_bottom.png`, `out/m4/layers/*.svg`.

## S7.b round 4 — QE APPROVED WITH NITS (2026-10-08)

QE report: `qe/S7b_round4.md` (posted on PR #30). R3-F1 and R3-F2 verified; every claimed number reproduced;
bus-vs-bus probe at 0.35 lists only Sofar's P1T/P2T geometry. Two nits fixed in REPORT.md: the 1V8 item's measured
gap is 0.225 mm (it was routed under the Default 0.15 mm rule), and the stray period in §1. The experiment is now
ready for Nick's KiCad review; never merge (BRIEF). Open for Nick (all declared): BM2_DATA_N +2.1 mm; the 1V8 lane
past the BM1_P leg via (one DRC error with a reason); bottom parts under the inductor envelopes (#2); U1 1.79 mm
from the L1 envelope (#3); 10 narrow fallback segments, 13 thin links; the DRC exclusions to apply by hand in KiCad.

## S7.b round 3 — report restored; new bus legs at 0.35 from the opposite leg (2026-10-08)

QE report: `qe/S7b_round3.md` (posted on PR #30). Board fixes of round 2 verified; CHANGES REQUESTED for the report.

- **R3-F1 (MAJOR, report):** my round-2 report script anchored a replacement on the first "| 10 |" in the file,
  which was the exclusion table's "courtyards_overlap | 10" row, and cut everything up to deviation #12: the tail
  of §5's exclusion table, the §6 heading and deviations #1–#9 were gone. Restored by splicing: the exclusion table
  verbatim from `out/m5/drc_exclusions.md`, §6 #1–#9 and #12/#13 from 0903d87's REPORT (round-2 wording), the rest
  regenerated from the fresh outputs. Two intermediate commits (60e14d6 and the one before) briefly carried a
  duplicated §7–§9 from the same kind of splice error; 554d934 is clean (headings 1–10 once, rows 1–17). The script
  now anchors on headings and is idempotent.
- **R3-F2 (MINOR):** new bus copper now keeps 0.35 mm from the opposite leg too: the data legs use a `busleg`
  class (0.2 / 0.35); `Grid.route` gains `soft` goal cells — the destination PAD's own cells may be entered by an
  orthogonal step without the clearance test, because T1/T2 pad 7 sits 0.24 mm from pad 6 and a leg has to reach its
  pad. A first version exempted every goal cell including diagonal steps and produced one real Default-clearance
  error (a 3V3 plane-leftover track clipping a GND via at (2.7, 38.5)); restricted to pad cells + orthogonal steps it
  is gone. `check_rules.py` now checks new bus items against other bus nets at 0.35 as well, exempting only T1/T2's
  pads. All four legs routed with `busleg` (no fallback used); rules.md: 1 class-clearance item (VBUS_OUT past U11
  pad 9).
- Result (M3 snapshot + `START=m4` after the last edit, commit 835f1a8): DRC 111 errors (110 Sofar + 1 declared
  1V8), 258 warnings, 0 copper-defect warnings, 1 unconnected (J1), 4 parity; blockcheck 0 missing / 126 trimmed /
  414 extra; check_fixed 0 failures; pairs 9.4 / 7.9 / 21.3 / 23.4; Kelvin both yes; stitch vias 69 (37 pre-stitched).

## S7.b round 2 — QE R2-F1 (Kelvin sense) and R2-F2 (bus rule) fixed (2026-10-08)

QE report: `qe/S7b_round2.md` (posted on PR #30). Round-1 items all verified; two new MAJORs, both real.

- **R2-F1 Kelvin sense.** On the mote, U4.1–R8.2 (P_IN) and U4.2–R8.1 (VBUS) are dedicated 0.2032 mm Bottom traces
  that detour west to mote x 143.68, outside SENSE's region (x ≥ 144.4); the copy clipped them and the cleanup then
  trimmed the halves, so U4 sensed the planes. Fix: a third SENSE region rect [143.6, 115.2, 144.4, 118.5] on Bottom
  only (nothing else of the block's nets is in it; on the shield it lands at x 17.05–17.85 where P2L has no Bottom
  copper); the Kelvin traces and U4 pads 1/2 are `Grid.exclude_ids` (no route starts or ends on them, no stitching via
  beside them); `check_rules.py` gains a pad-to-pad track-only connectivity check (both yes). blockcheck's SENSE row:
  tracks 77 expected (was 75).
- **R2-F2 bus clearance.** The netclass had no priority, so KiCad ignored it — the §4 claim was false (my probe had
  measured a refilled scratch copy, not the committed fill). Tried first: priority 0 with clearance 0.35 → 76 extra
  errors, 20 of them Sofar's own P/N legs (0.2 apart) and T1/T2 pads 6/7 (0.24), plus 41 of my routes at 0.15–0.33.
  Chosen: `board/nereus_Pi_shield_ADIN2111.kicad_dru` with one rule, bus nets 0.35 from non-bus nets; the netclass
  (priority 0, clearance 0.15) only names the nets. Verified on a scratch copy of 0903d87: the Python fill gives
  0.351 to a BM via / 0.251 to a 1V8 via, kicad-cli DRC with the rule flagged 41 copper items (none zones).
  Router: a first attempt stamped all bus copper 0.2 mm larger — it also kept P from N and three bus legs failed
  (T pads 6/7 cannot be left at 0.35 from each other). Replaced by a kind map (`Grid.dilk`: bits bus / power-class /
  other, radii 4–10 cells): non-bus routes keep 0.35 from bus copper and 0.25 from power-class copper, bus routes
  keep 0.35 from non-bus copper; power-class fallbacks (`power_n` 0.3, `power_t` 0.2) keep 0.25, `thin` stays the
  declared last resort. Grid build 112 → 264 s.
- **1V8:** with the rule there is no lane from the 1.8 V buck (B18) to U2 in the ADIN pocket at 0.35 from the port-1
  leg vias (tried: routing it first; still no path). It is routed right after the hand links with a last resort that
  keeps the Default 0.15 from bus copper (`route_net(..., bus_exempt_ok=True)`, `Grid.bus_exempt`): one DRC error,
  1V8 vs the copied BM1_P leg via at (11.94, 43.88) on Internal 2, in the exclusion table with this reason
  (REPORT §6 #16).
- **VBUS at U11** (C49.1 ↔ R16.2) was boxed in by the signals once they kept 0.25 from power copper: every plane
  net's lonely pads are now pre-stitched before the signals (GND 25, VBUS 7, 3V3 4, P_IN 1 vias).
- `check_rules.py`: bus-vs-bus exempt from the 0.35 check (the rule is bus vs non-bus); power-class and bus
  clearance on vias too. `drcexclude.py`: rules for T1/T2 pads 6/7 (unused now: bus-bus is 0.15) and the 1V8 item.
- Result (board from M0–M3 + `START=m4` after the last edit): DRC 111 errors (110 Sofar + 1 declared), 258 warnings
  (silk/text/padstack/lib), 0 copper-defect warnings, 1 unconnected (J1 by design), 4 parity; blockcheck 0 missing /
  130 trimmed; check_fixed 0 failures (inserts clear); pairs 9.4 / 7.9 / 21.3 / 23.4; rules: 10 narrower segments,
  13 thin links, 1 clearance item (VBUS_OUT past U11 pad 9), Kelvin both links yes.
- R2-F3 / R2-N1: §1 reworded (matched except the trimmed stubs; totals tidy).
- Nick had KiCad open on the worktree during a rebuild; closed without saving on request (the pipeline writes the
  board file).
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

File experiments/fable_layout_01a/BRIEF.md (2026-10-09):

# Layout experiment 1.a — fit everything at the proper widths by moving blocks, then a JLCPCB DFM sweep

*Brief for an autonomous layout agent (Fable 5.1, high effort). Owner: Nick Buemond. Written 2026-10-08 after
experiment 01 closed (QE approved with nits, PR #30, never merged). This is an **experiment**: its board is never
merged into the live project. The questions it answers: can an agent, by re-placing blocks (same side, rigid) and a
better routing tactic, reach a board with every new track at its class width and clearance, 0 open connections and
no routing exceptions — and then make it manufacturable at JLCPCB by a documented DFM sweep — without Nick editing
a trace?*

---

## 0. Hard rules (unchanged from experiment 01, read first)

1. **Write only inside `experiments/fable_layout_01a/`**, on the branch `experiment/fable-layout-01a` (created from
   `experiment/fable-layout-01`, so experiment 01's record sits beside you, read only). Never modify
   `experiments/fable_layout_01/`, `nereus_Pi_shield_ADIN2111/` (the live project), `KiCAD_reference_designs/` or
   `Archive/`, and never touch `main`. This is the one place an agent may write a `.kicad_pcb` (DESIGN D31).
2. **KiCad stays closed.** Work through KiCad 9's bundled Python (`pcbnew`) and `kicad-cli`:
   `PY=/Applications/KiCad/KiCad.app/Contents/Frameworks/Python.framework/Versions/Current/bin/python3`,
   `K=/Applications/KiCad/KiCad.app/Contents/MacOS/kicad-cli`.
3. **Trust artifacts, not exit codes.** Every step ends with a check you ran on the output files and a render you looked at.
4. **Don't change the circuit.** Pin connections come from the schematic. No schematic edit at all (J5 stays the JST GH,
   Nick 2026-10-07).
5. **Copied blocks are rigid.** Translate and rotate (multiples of 90°) only. Never mirror and never move a block or a
   part to the other side of the board. Moving a block is allowed and expected in this experiment.
6. **Never invent a fact.** A dimension, rating or manufacturing limit you can't find in a file, a datasheet or the
   manufacturer's published page goes in `REPORT.md` as an open question.
7. **Stop and report** (in `REPORT.md`, then commit) if the board would have to grow more than allowed in §2, or a hard
   rule would have to break.
8. **Nick is hands-off.** He will not edit traces and will not answer questions mid-run. Write your options review
   (M0), choose, and continue; he reads the record afterwards.

## 1. Starting point

`experiments/fable_layout_01a/` starts as a copy of experiment 01's `tools/`, `board/` (schematic copy, libraries,
`.kicad_pro` with the design rules and the `bus` netclass, `.kicad_dru` with the bus rule, and 01's final board),
`blocks.json` and `heights.json`. Everything in experiment 01's `BRIEF.md` §1–§6 (inputs, frame, fixed placements,
keep-outs, blocks, routing classes) still applies, except where this brief says otherwise. Read 01's `REPORT.md`,
`LOG.md` and the four QE reports in `experiments/fable_layout_01/qe/` before touching anything: they are the record
of what worked, what did not, and why.

The pipeline is `tools/build_all.sh` (M0 netlist → board → M1 fixed items → M2 placement → M3 block copper → M4 planes,
routing, dangling cleanup; `START=m4` reruns the routing from the M3 snapshot). Keep it the only way the board changes.
Change the scripts as you need; keep every check (`check_fixed.py`, `blockcheck.py`, `check_rules.py`, `drcexclude.py`,
`drc_summary.py`, `dangling.py`) running and honest.

## 2. Board

As experiment 01 §2: 46 × 65 mm, x −7.5 … 38.5, y 0 … 65, r 3, 6 layers in the mote's order. **Allowed growth:** the
south edge may move up to 2.0 mm south (46 × 67). Report the final size. Prefer no growth.
*Superseded 2026-10-08 (Nick, LESSONS.md §3, session 2.b): the board is **49 × 68** (3 mm wider, 3 mm taller); where the growth
went and why is OPTIONS.md addendum A1 (x −10.5 … 38.5, y 0 … 68).*

## 3. Open questions from experiment 01 — review them first (M0)

Experiment 01 ended with these declared deviations (its `REPORT.md` §6, §7, §10). Your first deliverable is
`OPTIONS.md`: for each question, the options, what each would move or change, what it frees, its risk, and your
recommendation with the reason. Then act on your recommendations.

| # | Open item (01) | What Nick wants reviewed |
|---|---|---|
| Q1 | BM2_DATA_N 23.4 mm vs the mote's 21.3 | T2's and/or the ADIN block's placement and rotation (270°: port-2 pins north?), a pair-aware route, both pairs over unbroken GND |
| Q2 | 1V8 passes a port-1 bus-leg via at 0.225 mm (bus rule 0.35); one DRC error with a reason | move the 1.8 V buck block (B18), or give 1V8 another lane; no exception in this experiment |
| Q3 | 10 new segments narrower than their class (5V_PI, VBUS stitching links, VBUS_OUT at U11) and 13 links routed at 0.15 mm instead of 0.2 | placement that leaves room: U11's cell, the ADIN pocket's exits, the strip east of J1; no fallback widths in the final board |
| Q4 | Bottom-side parts under the inductor envelopes (01 deviation #2) | state the assumption (the 50 W envelope is a top-side volume) and offer the alternative placement that keeps the bottom clear under both envelopes, with its cost |
| Q5 | U1 0.3 mm east of the pocket (courtyard 1.79 mm from the L1 envelope) | a placement that restores 2.0 mm, or a documented reason it cannot |
| Q6 | JP1 on the bottom beside J1; LEDs in a column at the band's east end | whether the new placement can put JP1 on top. **LEDs (Nick, 2026-10-08): can D8/D9/D10 move safely to the centre of the north edge** (the band between the Pi's north standoff holes, y < 7, so that another board stacked on top of this one still leaves them visible from the edge)? Keep their footprints (no part change; a side-view LED would be a schematic/BOM change for Nick to decide later); place them as close to the north edge as the edge clearance, H1/H2's keep-outs and L2's envelope clearance allow, light facing up and unobstructed northward; say what their resistors R44–R46 and the LED_VDD routing cost. If it is not safe, say why and give the nearest placement that is |
| Q7 | DRC exclusions must be applied by hand (kicad-cli cannot store them) | try once more to write exclusions KiCad accepts (marker position = KiCad's own, from a `kicad-cli pcb drc --format json` run in a scratch copy opened and re-saved by `pcbnew`), else keep the table |

Not for this experiment: tying J1's 3V3 pins (circuit), the stacking-header part choice, Sofar's open questions.

## 4. The new tactic

You choose it and justify it in `OPTIONS.md`. Candidates the 01 report named: rotate the ADIN block 270° so the
port-2 pins face north; move the LED resistors out of the band's east end; move B18 (1.8 V buck) to free the 1V8 lane;
plan the ADIN pocket's exits (west-wall lane, north and south strips, under U1) net by net before routing; a
pair-aware router (route P and N together); a 0.05 mm grid near U1; rip-up that targets one lane. Blocks may move
anywhere on their own side; the fixed items of 01 §3 do not move.

## 5. Routing rules

As experiment 01 §6, now as **pass criteria, not defaults**: every new segment at or above its class width and at or
above its class clearance; the bus nets 0.35 mm from every other net (the `.kicad_dru` rule stays active); the data
legs 0.2 mm; the ADIN pairs no longer than the mote's and on unbroken GND; R8's Kelvin links to U4 pad-to-pad by tracks
alone; insert rings and the pull-backs as 01. The 0.15 mm fan-out width is allowed only inside a part's pad field
(≤ 2 mm of track per net). No "declared" narrower links and no clearance exceptions in the final board.

## 6. DFM sweep for JLCPCB (after the routing is clean)

Once M2 holds, review the board as a fabrication house would and make it manufacturable at **JLCPCB** (6-layer,
1.6 mm, their standard process) without Nick editing a trace. Rules:

- **Every limit comes from JLCPCB's published capabilities**, fetched during the run (their PCB capabilities page
  and their 6-layer stackup table), quoted with the URL and the date read in `DFM.md`. Never type a limit from memory;
  if a value cannot be found, say so and use the brief's own figure.
- **Encode every limit in the design rules** (`.kicad_pro` design-rule constraints, netclasses, or `.kicad_dru`
  rules) so `kicad-cli pcb drc` checks it, then run DRC. A limit that is not enforced by DRC is checked by a script
  you write, and `DFM.md` says which.
- `DFM.md`: one row per item — the JLC limit, its source, the board's measured worst case (with where), pass/fail,
  and what you changed. Items to cover at least: minimum trace width and spacing (outer and inner layers); minimum
  via drill, via diameter and annular ring; hole-to-hole and hole-to-copper (same net and different net); copper to
  board edge (the brief's 0.5 mm stays; note JLC's figure); minimum drill and NPTH handling; solder-mask slivers and
  mask-to-copper expansion; silkscreen line width, text height and silk over pads (01's 258 warnings are mostly
  this: clean them up or clip them); courtyards; the stackup — replace 01's "generic 1.6 mm build" with JLC's
  actual 6-layer stackup (copper weights, prepreg and core thicknesses) written into the board, and say what that
  does to the pairs and to the planes' capacitance (Sofar Q11 is open; this is the board's own choice, not Sofar's
  answer); copper balance per layer; outer-layer **GND pours** with stitching vias where the review recommends them
  (state why and where, and what they do to the pairs and the bus feeds); thermal relief vs solid connections on
  the heavy pads (bus feeds, buck inductors, U10's heat); fiducials (FID1–6) placement for assembly; test points
  clear of parts; a `BOM` / `CPL` readiness note (footprint rotations vs JLC's library convention) if assembly at
  JLC is in reach, else say so.
- Keep every pass criterion of §5 while doing it: a DFM fix that breaks a width, a clearance or a pair length is not
  a fix.

## 7. Milestones

| | Milestone | Done when |
|---|---|---|
| M0 | `OPTIONS.md` committed: the §3 review, the chosen tactic, the planned block moves (which blocks, where, why) | Nick can read it; nothing on the board changed yet |
| M1 | Placement: blocks moved per M0, fixed items proven, keep-outs, heights | `check_fixed.py` 0 failures, courtyards 0 overlaps, renders |
| M2 | Block copper copied, planes, routing, cleanup | DRC: 0 unconnected but J1's no-connect pair; errors only Sofar's copied features (01's table) with reasons; 0 copper-defect warnings; `check_rules.py` 0 items below class, 0 clearance items, 0 thin links beyond fan-out, pairs within, Kelvin yes |
| M3 | DFM sweep (§6): `DFM.md`, limits in the design rules, fixes applied, DRC re-run | every `DFM.md` row pass, or fail with a reason Nick can act on; §5 still holds; renders |
| M4 | `REPORT.md` with the §8 table of 01 plus §5 and §6 of this brief, renders, draft PR `EXPERIMENT (do not merge): fable layout 1.a` | QE review requested (docs/PROMPTS.md §5: a separate QE session; save its reports in `qe/`; fix and resend until it approves) |

Commit after each milestone with renders in `out/` and an entry in `LOG.md`. If M2 or M3 cannot reach its bar, finish,
report exactly what is short and why (in numbers), and still open the draft PR: a documented shortfall is a result.

## 8. Report

As 01 §9, plus: the block moves (old → new transform per block), the tactic and what it bought in numbers (open links,
segments below class, thin links, clearance items, pair lengths, DRC) compared with experiment 01's final table, the
DFM table's summary, and what you would do next.

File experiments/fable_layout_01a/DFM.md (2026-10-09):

# DFM — JLCPCB 6-layer, layout experiment 1.a (stage m4)

*Step 1 of session 2.b (LESSONS §4): the limits were fetched and encoded before any board edit, and this table was first run on session 2's final board (b22752f, md5 de2e14fb…): see 'History' at the end for that result. The 'What 2.b changed' column is kept in `tools/dfm.py` (CHANGES).*

*Generated by `tools/dfm.py check m4` on the board as it is (md5 see HANDOFF). Every JLCPCB limit was read from the cited page on 2026-10-08: the capabilities page `https://jlcpcb.com/capabilities/pcb-capabilities`, the stackup page `https://jlcpcb.com/impedance`, the assembly page `https://jlcpcb.com/capabilities/pcb-assembly-capabilities`, the fiducial article `https://jlcpcb.com/blog/fiducial-marks`. The limits are written into `board/*.kicad_pro` (design_settings.rules) and `board/*.kicad_dru` by `tools/dfm.py rules`; a limit DRC cannot express is measured by this script (column 'enforced by'). 'Board rule' is the value the DRC runs with: where the brief or the mote is stricter than JLCPCB, the stricter value stays.*

| # | Item | JLCPCB limit (quoted) | Source, date | Enforced by | Measured worst case (where) | Pass | What 2.b changed |
|---|---|---|---|---|---|---|---|
| 1 | Min. trace width, outer layers (1 oz) | Multilayer 1 oz: 0.09 / 0.09 mm (3.5 / 3.5 mil) track width / spacing | jlcpcb.com/capabilities/pcb-capabilities, 2026-10-08 | board min_track_width 0.15 (BRIEF §5: 0.15 only inside a pad field, else the class width); stricter than JLC | 0.150 mm, ADIN_PWR on 6 Bottom Layer at (-1.15, 39.30) | pass | nothing: the brief's class widths (0.2 signal, 0.15 only in a pad field) stand |
| 2 | Min. trace width, inner layers (0.5 oz) | the same multilayer table: 0.09 / 0.09 mm (JLC lists no separate 0.5 oz inner figure) | jlcpcb.com/capabilities/pcb-capabilities, 2026-10-08 | board min_track_width 0.15; stricter than JLC | 0.200 mm, 5V_PI on Internal 1 at (29.67, 20.51) | pass | nothing |
| 3 | Min. spacing, outer and inner | Multilayer 1 oz: 0.09 / 0.09 mm; pad to track 0.1 mm; SMD pad to pad 0.15 mm | jlcpcb.com/capabilities/pcb-capabilities, 2026-10-08 | board min_clearance 0.09 (JLC) under the Default netclass 0.15 and the bus rule 0.35; DRC clearance | DRC clearance items: 7 (all in the exclusion table: Sofar's T1/T2 pads 6/7 at 0.24, the no-net pads, the BM1_N stub vs Sofar's via) | pass | min_clearance 0.09 written (JLC); the netclass 0.15 and the bus rule 0.35 govern |
| 4 | Same-net track spacing | 0.25 mm | jlcpcb.com/capabilities/pcb-capabilities, 2026-10-08 | no DRC constraint for same-net gaps: measured here (tracks of one net on one layer that neither touch nor keep 0.25) | 0 gap(s) of 0.03–0.25 mm between parallel runs of one net | pass | measured (parallel runs of one net 0.03–0.25 mm apart); the count in the row is the board's (session 2's board had 1: Sofar's bus leg at T1 pad 6) |
| 5 | Min. via drill | Multilayer: 0.15 mm hole size (preferred min. via hole size 0.2 mm); drill 0.15–6.3 mm | jlcpcb.com/capabilities/pcb-capabilities, 2026-10-08 | board min_through_hole_diameter 0.2 (the preferred figure; the mote's smallest drill); DRC drill_out_of_range | 0.200 mm (265 vias; drills {0.3: 99, 0.2: 131, 0.254: 28, 0.25: 7}) | pass | min_through_hole_diameter 0.2 written (JLC's preferred figure) |
| 6 | Min. via diameter | Multilayer: 0.25 mm via diameter | jlcpcb.com/capabilities/pcb-capabilities, 2026-10-08 | board min_via_diameter 0.45 (the mote's smallest via); stricter than JLC | 0.450 mm (diameters {0.6: 127, 0.45: 131, 0.5: 7}) | pass | nothing: 0.45 stands |
| 7 | Via annular ring | (0.25 − 0.15) / 2 = 0.05 mm follows from the min. via 0.15 / 0.25 | jlcpcb.com/capabilities/pcb-capabilities, 2026-10-08 | board min_via_annular_width 0.1 (the mote's 0.45/0.2 and 0.6/0.3 vias give 0.125 / 0.15); stricter than JLC | 0.125 mm at (29.67, 20.51) | pass | nothing: 0.1 stands |
| 8 | PTH annular ring (component holes) | Multilayer 1 oz: recommended 0.20 mm or above; absolute minimum 0.15 mm | jlcpcb.com/capabilities/pcb-capabilities, 2026-10-08 | .kicad_dru: annular_width min 0.15 for through-hole pads; DRC annular_width | 0.350 mm at J1.1 (44 PTH pads) | pass | .kicad_dru rule added (0.15) |
| 9 | Hole to hole, via–via | Via hole-to-hole spacing 0.2 mm | jlcpcb.com/capabilities/pcb-capabilities, 2026-10-08 | board min_hole_to_hole 0.25 (the mote's); stricter than JLC | 0.283 mm between vias at (20.90, 60.90) / (21.40, 61.20); via–pad 0.640 mm (J1.34) | pass | nothing: 0.25 stands |
| 10 | Hole to hole, pad–pad | Pad hole-to-hole spacing 0.45 mm | jlcpcb.com/capabilities/pcb-capabilities, 2026-10-08 | .kicad_dru: hole_to_hole min 0.45 when both items are pads | 1.540 mm between J1.1 and J1.2 | pass | .kicad_dru rule added (0.45, pad vs pad) |
| 11 | Via hole to copper | Via hole to track 0.2 mm; inner layer via hole to copper clearance 0.2 mm | jlcpcb.com/capabilities/pcb-capabilities, 2026-10-08 | board min_hole_clearance 0.25; stricter than JLC | outer 0.275 (via (2.50, 31.90) vs via [~{ADIN_P1_LED1}] on Top Layer); inner 0.275 (via (2.50, 31.90) vs via [~{ADIN_P1_LED1}] on Internal 1) | pass | nothing: 0.25 stands |
| 12 | PTH hole to copper | PTH to track 0.28 mm (0.35 mm recommended); inner layer PTH pad hole to copper clearance 0.3 mm | jlcpcb.com/capabilities/pcb-capabilities, 2026-10-08 | .kicad_dru: hole_clearance min 0.28 (outer) / 0.3 (inner) for through-hole pads | outer 0.578 (J1.19 (25.23, 31.23) vs via [ADIN_PWR] on Top Layer); inner 0.300 (MTG3.0 (-6.50, 64.50) vs zone GND on GND Plane) | pass | .kicad_dru rules added (0.28 outer / 0.3 inner); the inner planes' clearance 0.25 → 0.3 (the M3 housing holes' pads were 7 DRC items) |
| 13 | NPTH hole to copper | NPTH to track 0.2 mm | jlcpcb.com/capabilities/pcb-capabilities, 2026-10-08 | board min_hole_clearance 0.25; stricter than JLC | outer 0.230 (MP2.- (-6.31, 55.50) vs arc [BM1_N] on Top Layer); inner 0.250 (H2.- (26.50, 3.50) vs zone GND on GND Plane) | pass | the bus feeds start 3.31 mm from the insert centre (a 3.0 start put the 1.5 mm track's round end 0.05 mm from the Ø4.4 hole) |
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

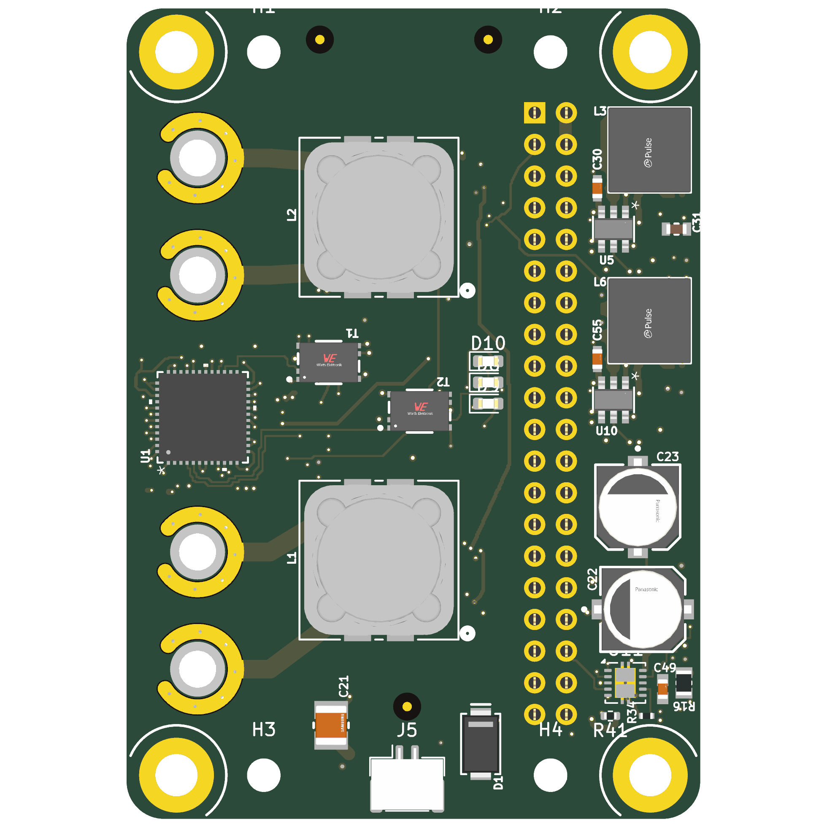
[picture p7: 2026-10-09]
experiments/fable_layout_01/out/m5/render_top.png

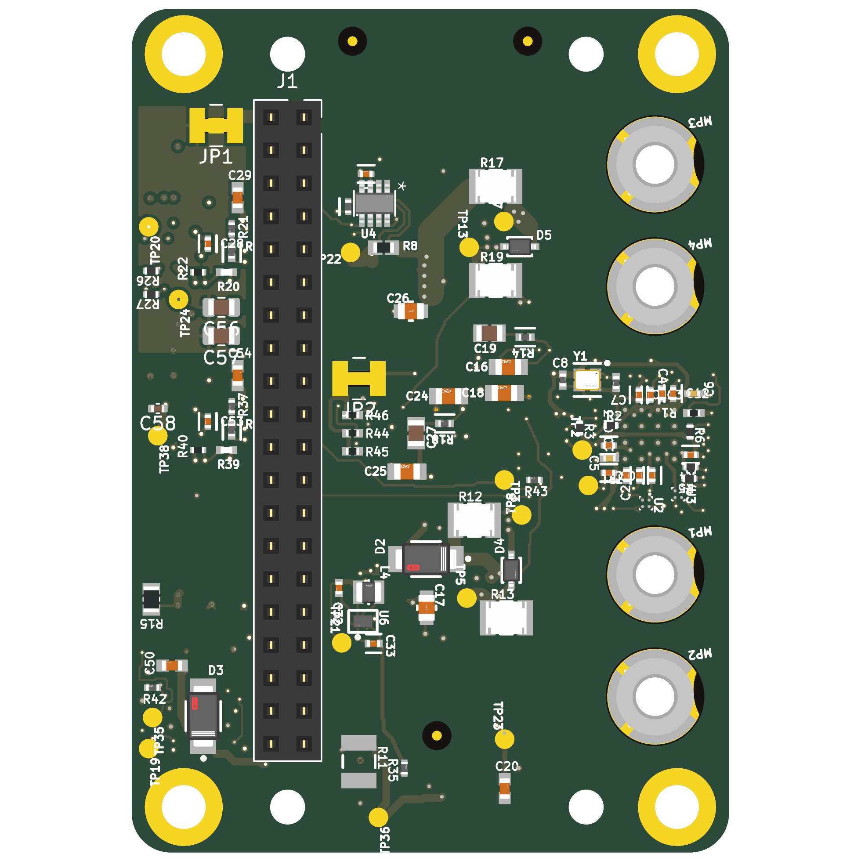
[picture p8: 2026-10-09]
experiments/fable_layout_01/out/m4/render_bottom.png

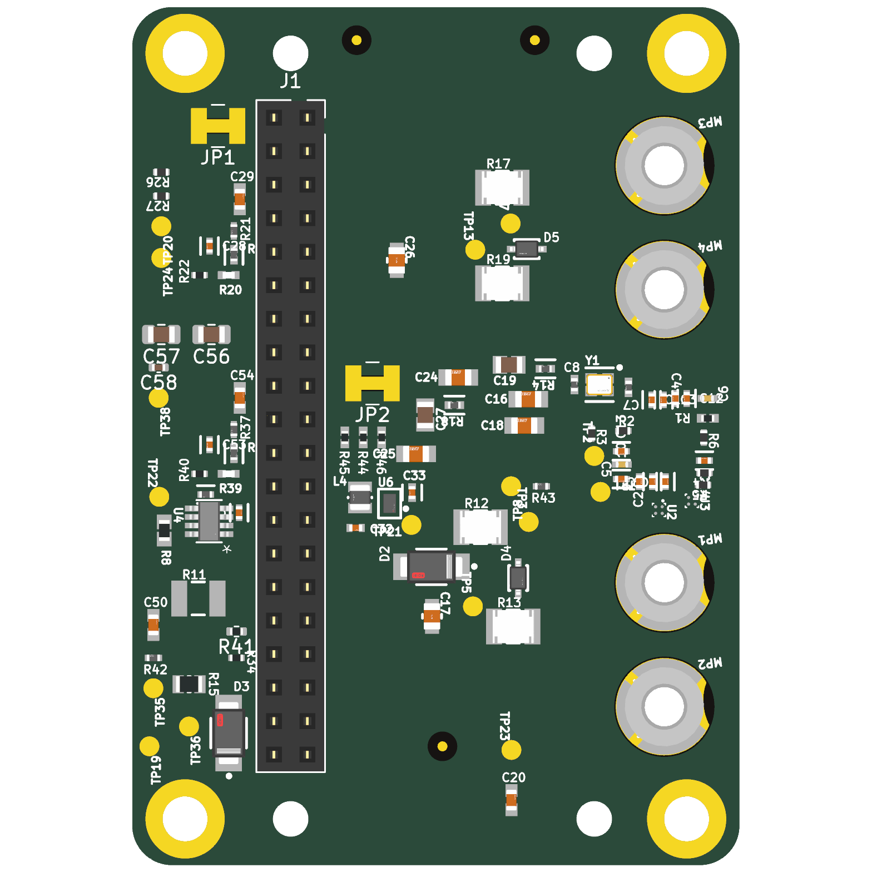
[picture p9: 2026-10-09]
experiments/fable_layout_01/out/m2/render_bottom.png

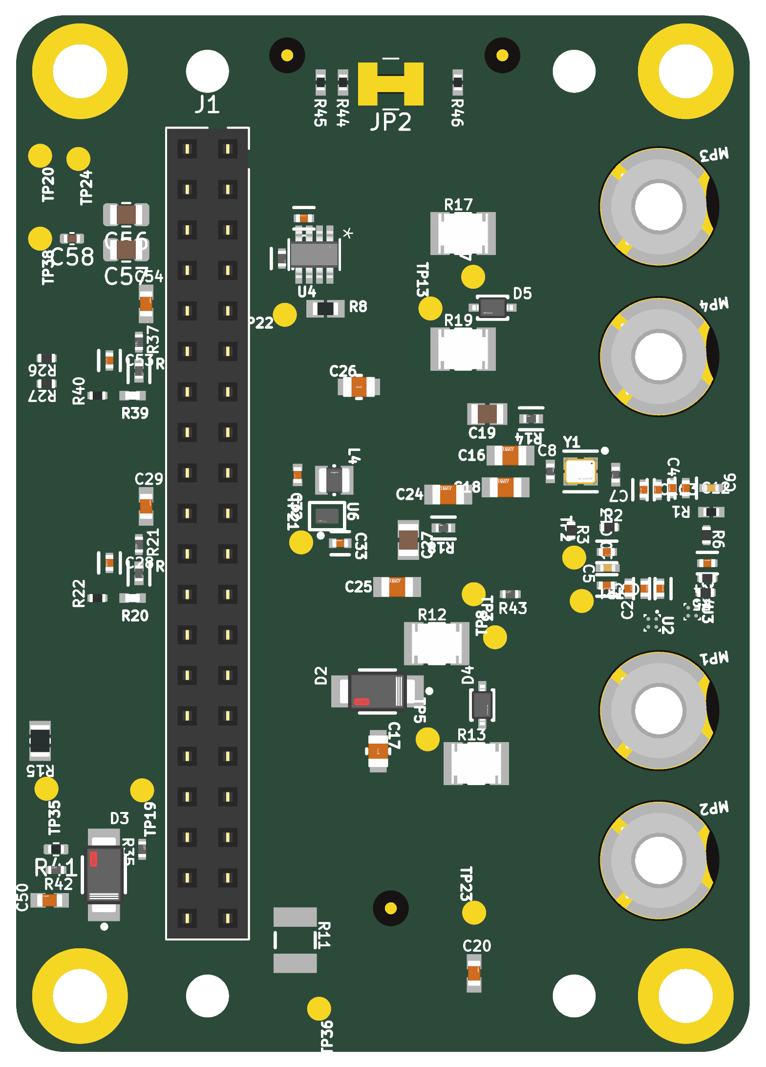
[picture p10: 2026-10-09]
experiments/fable_layout_01a/out/m1/render_bottom.png

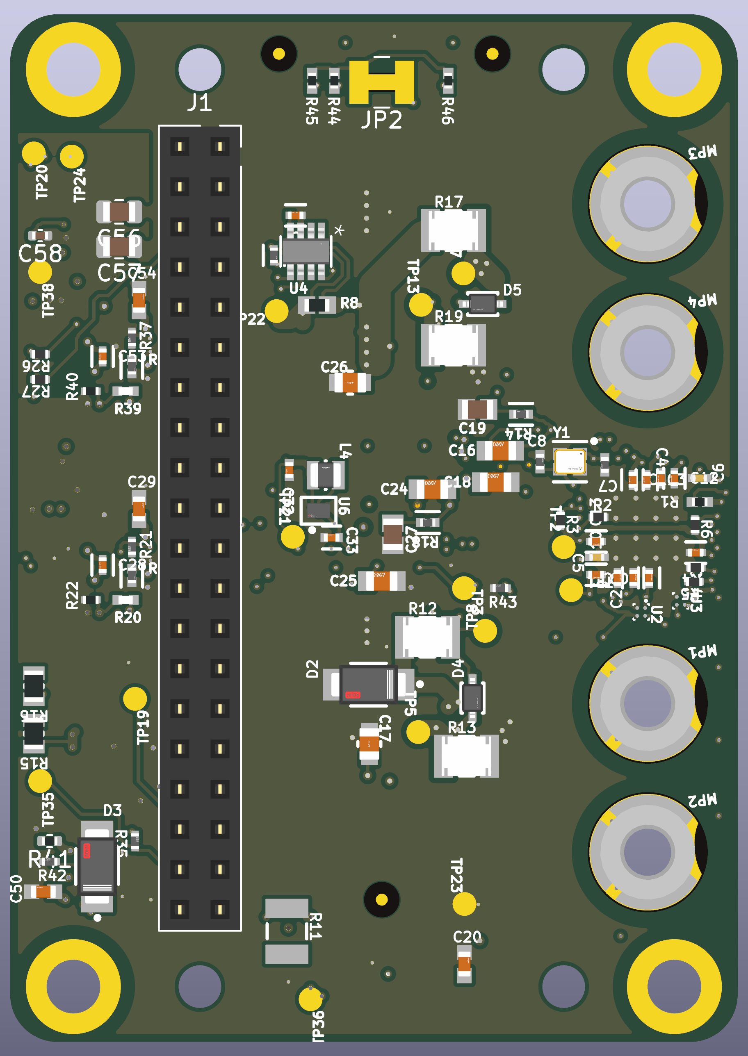
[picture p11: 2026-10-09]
experiments/fable_layout_01a/out/review/render_bottom.png

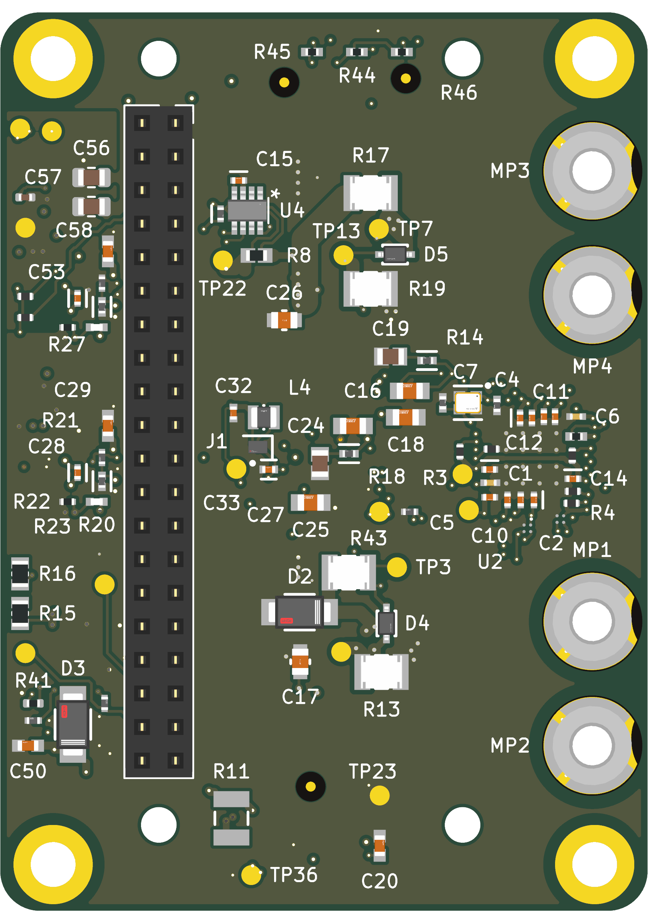
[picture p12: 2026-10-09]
experiments/fable_layout_01a/out/m4/render_bottom.png

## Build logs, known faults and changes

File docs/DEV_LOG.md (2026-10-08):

# DEV_LOG.md — Session Log

*Newest entries on top. One entry per working session. Short: what changed,
what broke, what's next.*

---

## Entry template

```
## YYYY-MM-DD — Sprint Sn — <one-line summary>
**Branch:** sprint/n-slug
**Files touched:** <sheets / docs>
**ERC:** <n errors / n warnings>  ·  **Net diff:** <clean | n changed — intended?>
**Done:**  <bullets>
**Broke/surprised us:** <bullets or "nothing">
**Next:** <the single next bite>
```

---

## 2026-10-07 — Sprint S7.a — Layout experiment brief (Fable port of the mote layout)

**Branch:** sprint/7a-layout-experiment-brief
**Files touched:** experiments/fable_layout_01/ (BRIEF, KICKOFF, tools/render_layers.py); CLAUDE.md, SPEC (constraint 1,
insert-contact fact, non-goals), TRACKER (rules 8/9, S6.g QE done, S7), DESIGN D31, SOFAR_QUESTIONS (Q6 reworded, Q9–Q12),
viewer
**ERC:** 0 / 494 (no schematic change)  ·  **Net diff:** none
**Done:**
- Read Sofar's board layer by layer (pcbnew, read only): stack, block placement, routing by net class; published a
  walkthrough page and a Sofar layout-questions page (one copper render per question; Notion text + PNGs for Nick)
- Nick's envelope for the shield, worked out with scale drawings: inserts on the west wall, 50 W inductor room, Micro-Fit
  payload facing south, M3 housing holes, 46 × 65 mm; OpenMV N6 overlay (later variant, staggered 4.2 mm east)
- Area check against Sofar's density: fits overall; U1's 9.12 mm courtyard doesn't fit the 8 mm band between the
  inductors, so the brief offers the west pocket or 2 mm of growth
**Broke/surprised us:**
- R12/R13/R17/R19 (fitted) sit across L1/L2's windings (Bourns pinout 1–3, 2–4): asked Sofar (Q9)
- SPEC said "no vias within 3.5 mm" of the inserts; there are seven at r 3.0 mm inside the ring pad. Corrected
- Four inserts in a row along the south edge don't fit a 31.5 mm board (copper Ø7.4 each); moved to the west wall
**Next:** QE review of S7.a; then Nick starts the Fable session

---

## 2026-10-07 — Sprint S6.g — Presentation clean-up (Nick's list)

**Branch:** sprint/6g-presentation
**Files touched:** all 7 sheets; .kicad_pro (exclusion keys); schematic.pdf; DESIGN (D30), changelog, README, sofar_brief,
TRACKER, viewer
**ERC:** 0 / 494 (was 0 / 495)  ·  **Net diff:** identical pin partition, 7 nets renamed — intended
**Done:**
- Nick's KiCad look (S6.f) produced an 8-item list; he discarded his own KiCad edits and asked for them fresh
- Asked: what ADIN_PWR/R43 do (Pi GPIO23 → U2/U3 ON; R43 keeps the ADIN off while the Pi boots or is absent, D21);
  active-high/low marking → KiCad overbar; names PAYLOAD_EN / ~{PAYLOAD_FAULT}, ~{ADIN_CS}; no signal table for now
- New helpers (scratch): move_block / move_where (shift items wholly in a region; stretch wires only along their axis,
  else refuse), label renames, title blocks, text/rect adders
**Broke/surprised us:**
- My label-rename pattern first matched nothing while the sheet-pin rename did: the pin-partition check caught the split
  nets at once. A text insert landed at the top of a sub-sheet (no sheet_instances block): KiCad loaded an empty sheet;
  inserts now go before the file's closing bracket
- KiCad JSON/SVG: the cover's 2 render images were ~8 MB of the file
- QE round 1 APPROVED WITH NITS (P2_LED1 overbar vs pin 47's wire; 1V8 header on its wire; licence note → Sofar Q8 drafted)
- Nick, after his KiCad look: J5 wired beside the Load Switch (connector with its switch beats "interconnects on the right");
  R11 note as an open / fitted summary; headers for J1 and the Load Switch; Power sheet title removed
- QE round 2 APPROVED WITH NITS: ~{PAYLOAD_FAULT}'s overbar touched the PAYLOAD_EN wire; jogged like ~{ADIN_P2_LED1}
**Next:** Nick's look in KiCad; merge #28; then S6 complete

---

## 2026-10-07 — Sprint S6.f — Author + BOM PDF

**Branch:** sprint/6f-author
**Files touched:** .kicad_pro (AUTHOR); bom.pdf + schematic.pdf; tools/bompdf.py, tools/html2pdf.js; README, TRACKER, viewer,
changelog
**ERC:** 0 / 495 (unchanged)  ·  **Net diff:** none
**Done:**
- Nick: author is Nick Buemond; he wants the KiCad project, the changes and a BOM PDF to review
- BOM PDF from bom.csv, one row per line, changed lines highlighted
**Broke/surprised us:**
- No HTML/RTF → PDF filter on macOS (cupsfilter); AppKit's print operation via JavaScript for Automation works, and
  needs absolute column widths (percentages are ignored)
**Next:** QE review; Nick's review of the package and the KiCad project; S6 complete

---

## 2026-10-06 — Sprint S6.e — Review package (overnight run, bite 5 of 5)

**Branch:** sprint/6e-review-package
**Files touched:** README.md + schematic.pdf (new, design-review); tools/netcheck.py (+ test), netcheck.md; R11–R13/R17/R19
Description; SPEC, DESIGN, changelog, TRACKER, viewer
**ERC:** 0 / 495 (unchanged)  ·  **Net diff:** 5 Description values — intended
**Done:**
- S6.d merged (PR #25) after QE (rendered base vs head; redundant junction removed)
- netcheck now lists every new net with its pins; package README ties the whole review together
- SPEC's S6 cleanup: the five CRCW1210 jumpers' wrong "205K" Description
**Broke/surprised us:**
- The S6 QE's sends arrive late or in bursts: its S6.b/S6.c reports landed after they were already acted on from its transcript
- QE APPROVED WITH NITS: 4 open SPEC items added to the README, MP1–MP4 wording, Description source, U11 note; merged
**Next:** Nick's demo of the package; then S6 is complete

---

## 2026-10-06 — Sprint S6.d — Minor schematic tidy (overnight run, bite 4 of 5)

**Branch:** sprint/6d-tidy
**Files touched:** BM_Mote_1_Master.kicad_sch, BM_Mote_1_ADIN2111.kicad_sch, .kicad_pro (one exclusion key); DESIGN,
changelog, TRACKER, viewer
**ERC:** 0 / 495 (was 0 / 504)  ·  **Net diff:** none (nets and pins identical)
**Done:**
- S6.c merged (PR #24) after QE (footprints.md "Used by" fixed)
- Rendered every sheet (SVG → region crops via Quick Look) and listed only clear readability issues
- I²C pull-ups onto J1's stubs; LED columns even with pull-ups under their LEDs; overlapping text/notes fixed; stale note
  updated; dead stub + dangling lead-ins removed
**Broke/surprised us:**
- kicad-cli JSON also scales wire lengths by 100: the "0.2 mm" dangling wires were 20–40 mm lead-ins on Top-Level
- Sofar's ADIN_VDDIO bar symbol points down at rotation 0 (opposite to KiCad's stock symbols); field angle 90 keeps text
  horizontal on a 270° symbol; Sofar's resistors show a RESISTANCE field (Value hidden)
- Moving #PWR34 made its exclusion stale exactly as designed: check.sh failed until `ercexclude.py --write`
- QE APPROVED WITH NITS after rendering base vs head; redundant TP8 junction removed
**Next:** S6.e (review package)

---

## 2026-10-06 — Sprint S6.c — Footprint types and courtyards (overnight run, bite 3 of 5)

**Branch:** sprint/6c-footprints
**Files touched:** mote.pretty (43 footprints, inserts only); tools/fpattrs.py (+ test); footprints.md (new); DESIGN (D29),
changelog, TRACKER, viewer
**ERC:** 0 / 504 (unchanged)  ·  **Net diff:** none (library only)
**Done:**
- S6.b merged (PR #23) after QE round 2
- Type + F.CrtYd on all 43 Vault footprints; courtyards from Sofar's outlines first (39), computed for 4
**Broke/surprised us:**
- A pads+fab courtyard came out smaller than the body (SRF1260 6.1 × 13.5 mm vs a 12.5 mm body): these Altium footprints
  draw the body on User layers, not Fab. Rule changed to use Sofar's User-layer outline first
- KiCad's writer (FootprintSave) regenerates every uuid and drops default-valued fields (the S5.g `opacity 1`), so the
  change is written as text inserts and re-read with pcbnew; BOX2I.Merge didn't behave through SWIG: plain min/max
- QE sends from the S6 session get queued, not delivered: read its verdicts from its transcript
- QE APPROVED WITH NITS: footprints.md "Used by" was wrong on 5 rows (regex ran across netlist components), regenerated
**Next:** S6.d (minor schematic tidy)

---

## 2026-10-06 — Sprint S6.b — ERC clean or justified (overnight run, bite 2 of 5)

**Branch:** sprint/6b-erc
**Files touched:** .kicad_pro (text variables, exclusions); 7 sheet title blocks; tools/ercexclude.py (+ test), check.sh;
erc_justifications.csv (new); DESIGN (D28), changelog, TRACKER, viewer
**ERC:** **0** / 504 (was 27 / 504)  ·  **Net diff:** title-block revs + text variables — intended
**Done:**
- S6.a QE APPROVED WITH NITS, merged (PR #22); report started `docs/design-review/qe/S6.md`
- Title block from Nick: rev AA, PCB-000001-AA, name = file name
- KiCad 9 exclusion key format taken from the 9.0 source (sch_marker.cpp SerializeToString) and confirmed empirically
  on a scratch copy: only the variant with the sheet path in both path slots is accepted
- Reasons sourced: FID/MTG have no net on the mote copper; U3 VOUT is passive-typed; switch/bootstrap and inductor nets
**Broke/surprised us:**
- kicad-cli JSON positions are in 100 mm units (229.87 mm prints 2.2987)
- `--severity-exclusions` still omits excluded items from the JSON in 9.0.6, so the tool runs ERC on a copy with the
  exclusions cleared
- Exclusion keys carry the item's position: S6.d moves must be followed by `ercexclude.py --write` (check.sh catches it)
- QE round 1 CHANGES REQUESTED (read from its transcript: its send was queued, never delivered): F1 the tool exited 0 on
  unjustified errors; F2 MTG grounding stays Nick's; N1 two-item errors. Fixed
**Next:** QE round 2; then S6.c (footprint attributes, library only)

---

## 2026-10-06 — Sprint S6.a — BOM hygiene (overnight run, bite 1 of 5)

**Branch:** sprint/6a-bom-hygiene
**Files touched:** six sheet files (flags + MANUFACTURER); bom.csv; bom_lifecycle, changelog, DESIGN, TRACKER, viewer
**ERC:** 27 / 504 (unchanged)  ·  **Net diff:** 26 exclude_from_bom markers + MANUFACTURER fields — intended
**Done:**
- S5.i merged (PR #21) on Nick's instruction; S5 complete except J1's part number
- Nick: run S6.a–e overnight, QE-approved before each next bite; fresh S6 QE session started from a task chip
- Title block values from Nick: name = file name, rev AA, part number PCB-000001-AA (for S6.b)
- TP/FID/MTG out of the BOM; MANUFACTURER filled from the lifecycle table on the 75 parts without one
**Broke/surprised us:**
- First pass treated Sofar's MANUFACTURER1 as D1's maker; it belongs to their *second source* (Vishay). Redone with
  MANUFACTURER as the only BOM field: D1 = STMicroelectronics, U5/U10 = Texas Instruments (Sofar's MFR_NAME agrees)
**Next:** QE review; then S6.b (ERC)

---

## 2026-10-06 — Sprint S5.i — Planned part per BOM line (D27)

**Branch:** sprint/5i-planned-parts
**Files touched:** six sheet files (fields only); .kicad_pro (view); tools/check.sh; bom.csv; DESIGN (D27), bom_alternates,
bom_lifecycle, sofar_brief, changelog, TRACKER, viewer
**ERC:** 27 / 504 (unchanged)  ·  **Net diff:** 428 new PLANNED fields + 19 SOURCING values — intended
**Done:**
- S5.h merged (PR #20, `1acef25`) after Nick's look; KiCad's close-time .kicad_pro rewrite discarded first
- Nick: one "planned part" column, with the why, as the single diff for Sofar. Decisions: Value stays Sofar's; first build
  buys planned parts after Sofar's review; ALT1/ALT2 stay as backups
- 10 changed lines from the S5.h alternates; every other part planned as specified with its S5.e LCSC number
- R8: compared ROHM PMR03 (b 0.35 mm) and KOA UR73D1J (b 0.55 mm) against R8's pads; no ROHM land pattern → kept
- check.sh now exports bom.csv from the KiCad preset (one definition); unknown preset fails loudly with a restore hint
**Broke/surprised us:**
- Five more parts (U11, R41, C56–C58) had the 4-tab Footprint line; the guard stopped after one sheet, restored, re-run
  with the same whitespace normalisation as J1
- No LCSC listing for D1's Vishay second source; TDK KT000N vs K125AB: same spec per LCSC, thickness not confirmed
- QE round 1: **APPROVED WITH NITS** (F1 two notes overstated stock; N1 TDK claim; N2 D26 → D27; N3 "tier-1"), fixed
**Next:** merged on Nick's instruction; S6.a plan (BOM hygiene), with a fresh S6 QE session

---

## 2026-10-06 — Sprint S5.h — BOM alternates as hidden fields + tracked BOM

**Branch:** sprint/5h-bom-fields
**Files touched:** six sheet files (fields only); tools/check.sh; docs/design-review/bom.csv (new); bom_alternates,
bom_lifecycle, sofar_brief, changelog, DESIGN, TRACKER, viewer
**ERC:** 27 / 504 (unchanged)  ·  **Net diff:** 208 new hidden fields, nothing else — intended
**Done:**
- Executed `bom_alternates.md` as planned: 8 fields on each of the 24 flagged passives, `SOURCING` on 15 critical refs
  (U1 on both units). Nick: Sofar's listed parts stay the primary column, alternates beside them; that is the layout
- Structural compare against HEAD: every existing property unchanged and in order, every new field hidden
**Broke/surprised us:**
- `--group-by Value` alone merged R11 (DNP) with the fitted R12/R13/R17/R19 and marked all five DNP; caught in a
  scratch export before editing, now grouped by Value + `${DNP}`
- J1's Footprint property was indented 4 tabs (import leftover, like JP1) and tripped `set_properties`' guard; the
  first run had already written two sheets, so I restored them and reran with that line re-indented
- ERC reports differ between runs on the *same* file: `multiple_net_names` cites whichever copy of a repeated label
  KiCad picks. Compare ERC with coordinates stripped
- `Mfr`/`LCSC` columns are mostly blank: only 30 of 291 symbols have `MANUFACTURER`, 5 have `LCSC` (S6 harmonisation)
- QE round 1: **APPROVED WITH NITS** (undeclared note-text tweaks, TP/FID/MTG rows in bom.csv → S6, viewer label), fixed
- Nick: at most 3 alternates per part (ours ≤ 2); R8's 7 Sofar fields stay as Sofar's data, its ALT NOTE no longer cites them
- Nick's first look: the fields existed but KiCad shows new fields only once their columns are enabled, and his enabled
  columns landed after Footprint/Datasheet. Added the view "Sofar review (alternates)" to the `.kicad_pro` (preset + the
  dialog's opening view); `kicad-cli --preset` export = bom.csv cell for cell. Closing KiCad had rewritten the `.kicad_pro`
  with all 186 imported field names; discarded, the preset written on the committed file
- Nick's look: fields present; KiCad 9 (macOS) draws the fields-table header blank with these columns, though its Export
  has the headers and equals bom.csv cell for cell, so bom.csv is the review table. KiCad's close-time .kicad_pro rewrite discarded
- Nick asked for a **Planned part** column (+ a why note) as the single diff for Sofar → S5.i, decisions recorded in TRACKER
**Next:** merge #20; S5.i (planned parts); then S6

---

## 2026-10-06 — Session handoff — S5.h planned, ready for a new session

**Branch:** sprint/5h-bom-alternates (handoff docs only)
**Files touched:** docs/design-review/bom_alternates.md (new); TRACKER, viewer, DEV_LOG
**ERC:** 27 / 504 (unchanged)  ·  **Net diff:** none
**Done:**
- S5.e closed: QE approved (round 2), Nick approved, PR #18 merged (`f5b2279`)
- S5.h fully specified for the next session: field names, every alternate's MPN/LCSC/stock (checked on lcsc.com
  today), `SOURCING` values for the critical parts, the BOM export command, and the expected checks
- Nick asked to wind this session down; the handoff PR merged at his instruction without a QE round (plan only,
  no design change)
**State for the next agent:**
- main is green (ERC 27/504, netcheck 51/51, midwire 0)
- S5 standing QE session `local_fad7e722-e717-4a71-88c9-020652d9d441`: its sends to the design session get paused after
  ~10 messages; read its transcript if no report arrives
- Sofar questions still to send (Nick): Q2, Q6 (PoDL insert contact), Q7 (D1 source)
- J1's part number waits on the board spacing (Nick)
**Next:** S5.h, then S6

---

## 2026-10-06 — Sprint S5.e — BOM lifecycle + stock check (all parts, 20 boards)

**Branch:** sprint/5e-bom-lifecycle
**Files touched:** docs/design-review/bom_lifecycle.md (new); DESIGN, SPEC, SOFAR_QUESTIONS (Q7), TRACKER, viewer
**ERC:** 27 / 504 (unchanged)  ·  **Net diff:** none (docs only)
**Done:**
- S5.f closed: Nick's look OK, PR #17 merged (`e62d974`); S5.e run last with every part on the schematic (Nick)
- 50 unique parts / 105 placements; four read-only research agents in parallel; Nick set the build to 20 boards mid-run
- Spot-checks: SMA6F33A obsolete (Digi-Key), LMR51430YDDCR stock (LCSC), second-source fields in the netlist
- Found Sofar's own second sources in the part fields: D1 (Vishay SMA6F33A-M3/H, ST SMA6F33AY), R8 (7 alternates)
**Broke/surprised us:**
- 21 of 50 flagged, but only D1 for lifecycle: the rest is LCSC not stocking Sofar's exact parts (all Active at DK)
- UrchinCam's 2×20 header (Amphenol 95157-440LF) is a male SMD header, not a usable socket for J1
- LCSC search can't be read automatically: "no listing found" is not proof; Nick to confirm the key ones in a browser
**Next:** QE review; Nick's review + sourcing decisions; then S6

---

## 2026-10-06 — Sprint S5.f — ADIN status LEDs

**Branch:** sprint/5f-adin-leds
**Files touched:** BM_Mote_1_ADIN2111.kicad_sch; DESIGN (D25), SPEC, sofar_brief, TRACKER, viewer, changelog
**ERC:** 27 / 506 (was 27/508)  ·  **Net diff:** LED nets + pin-21 net renamed — intended
**Done:**
- S5.d and S5.g closed: Nick's look OK (J5 moved right, 3D models checked), PRs #15/#16 merged (`c9aa575`, `94bc4b8`)
- Nick: lifecycle check only once every part is on the schematic → S5.f before S5.e
- D8 red (ADIN powered) + D9 yellow-green (pin 21 link/activity), R44/R45 1.5 kΩ, JP2 cut-to-disable (option a)
- Parts from LCSC with stock; KENTO's spec sheet gives the cathode mark (green), matching pad 1 / pin K
**Broke/surprised us:**
- R3 touched U1 pin 21 directly, leaving nowhere clean to tap: moved R3 into the LED group, stub + label on pin 21
- The mid-wire junction quirk again: R45 came up unconnected until the wire was split at the junction
- JP1's Footprint property is indented 4 tabs (S4.b leftover; KiCad doesn't care) and tripped set_properties' guard;
  normalised on the JP2 copy only
- Rotated LED field text collided with the label: fields set horizontal
**Next:** Nick's KiCad look; then S5.e (lifecycle + stock, all parts)
- QE round 1: **APPROVED WITH NITS** (off-grid accounting −3/+1; ≈ 8 mW with R3's current while D9 is lit), fixed
- Nick: add the port-2 twin → D10 + R46 on ADIN pin 48 (R5 moved like R3, stub + label); D10 joins the ADIN_LED_VDD
  wire directly; note reflowed to stay inside the sheet

---

## 2026-10-06 — Sprint S5.g — Footprint library 3D fixes (PoDL insert model, stock models)

**Branch:** sprint/5g-footprint-fixes (stacked on S5.d)
**Files touched:** mote.pretty (8 footprints, 3D only); DESIGN (D24), SPEC, SOFAR_QUESTIONS (Q6), TRACKER, viewer, changelog
**ERC:** 27 / 508 (unchanged)  ·  **Net diff:** none (library only)
**Done:**
- Nick: the mote's bus attaches with threaded inserts; found them as MP1–MP4 (Würth 78614015360) on BM1±/BM2±
- Insert model was present but opacity 0 → now visible; geometry settles the "1.5 mm": M3, 6 mm × 1.5 mm body
- Stock 3D models on 7 footprints (+ R10's spare); orientation checked numerically (non-polarised, pads and model on x)
**Broke/surprised us:**
- I numbered the insert pad "1" thinking the bus fed through it. QE round 1 (CHANGES REQUESTED) found the real contact:
  a front-side C-shaped copper arc on the bus track (presumably under the screwed lug); the back insert pads are net-less. Nick: don't jump
  to layout details; ask Sofar (Q6). Pad change and the fpextract exception reverted
- KiCad has no 0.9 mm, 0.5 mm-pitch 4-ball model, so U2/U3 stay without one
- The insert model's up/down depends on KiCad's rotation sign, not confirmable offline → Nick checked in the 3D viewer:
  body-up, models check out
**Next:** QE round 2; Nick's KiCad look (incl. the 3D check)
---

## 2026-10-06 — Sprint S5.d — Payload connector J5 (JST GH 2-pin)

**Branch:** sprint/5d-payload-connector
**Files touched:** BM_Mote_1_Master.kicad_sch; nereus.kicad_sym (SM02B-GHS); DESIGN (D23), SPEC, sofar_brief, TRACKER, viewer, changelog
**ERC:** 27 / 508 (unchanged)  ·  **Net diff:** J5 on VBUS_OUT / GND — intended
**Done:**
- S5.c closed: Nick's KiCad look OK, PR #14 merged (`d5bc13b`)
- Traced VBUS_OUT on the mote copper: it left through mezzanine P1 pins 14/16/18, gone since S2
- Nick: JST GH, the 2-pin variant, part and footprint from his UrchinCam (J4/J6), shown on the Top-Level sheet
- Found while answering the bus question: the PoDL threaded inserts MP1–MP4 (Würth 78614015360, M3) have an
  invisible 3D model (opacity 0) and an unnumbered copper pad, so a new layout wouldn't put the bus nets on them —
  fixed next in S5.g
**Broke/surprised us:**
- First placement: the note crossed the VBUS_OUT wire and the value touched GND; re-placed after the render
- Nick's look: move J5 to the right with the inserts (interconnects live there), drop the UrchinCam reference from the
  note, update the stale "Molex 2-pin" bus note. My first move broke the sheet: re.sub turned the note's `\n` escapes
  into real newlines inside a quoted string, KiCad couldn't parse it (ERC 4, empty netlist). Caught by check.sh, fixed;
  netlist identical after the move
**Next:** Nick's KiCad look; S5.g footprint fixes
- QE round 1: **APPROVED WITH NITS** — C189893 out of stock on LCSC today (recorded, recheck in S5.e); MP pad wording;
  layout silkscreen "VBUS 16–32 V" next to J5 so a 5 V GH cable isn't plugged in

---

## 2026-10-05 — Sprint S5.c — I²C pull-ups, ADIN_PWR pull-down, R10 removed, ADIN boot order

**Branch:** sprint/5c-pullups
**Files touched:** BM_Mote_1_Master.kicad_sch; tools/schedit.py (clone_symbol) + test; DESIGN (D20–D22, "ADIN power and boot"), SPEC, SOFAR_QUESTIONS, sofar_brief, TRACKER, viewer, changelog
**ERC:** 27 / 508 (unchanged)  ·  **Net diff:** R26/R27/R43 added, R10 removed, TP19 → SW_EN — intended
**Done:**
- S5.b closed: Nick's KiCad look OK, PR #13 merged (`31bc0f3`)
- Read Sofar's reference sheets (Nick: answer from the mote design first): the ADIN load switches exist for
  "<10mW mote operation"; every strap checked against the ADIN2111 Rev. B datasheet Nick supplied
- Citations: Pi Zero 2 W schematic (1.8 kΩ I²C pull-ups to Pi 3V3), BCM2835 §6.2 (GPIO reset pulls; Zero 2 W =
  BCM2710A1 per product brief), AP22913 DS41203 (no ON pull-down), TI SLVA689 (I²C R_P(min) 967 Ω)
- Nick chose Option 1 (software boot order, no CS/RST series resistors); R10 removed (Pi is the only controller)
**Broke/surprised us:**
- git's default diff showed ~7,500 changed lines for ~1,450 added; `--diff-algorithm=patience` shows the real
  +1665/−214 (two Altium symbols with ~35 fields each)
- NXP's I²C spec download returns 404 to scripts; cited TI SLVA689's table of the spec values instead
**Next:** Nick's KiCad look; then S5.d payload connector
- QE round 1: **APPROVED WITH NITS**. F1 (minor): the Pi's default pull-down doesn't hold ADIN RESET once the
  ADIN is powered (it fights the internal pull-up) → boot order now drives GPIO24 low / GPIO23 high from config.txt;
  nits: TP19's move isn't visible to netcheck (layout note added), Q4 state key, duplicate import

---

## 2026-10-05 — Sprint S5.b — Pi header wired

**Branch:** sprint/5b-pi-header-wiring
**Files touched:** BM_Mote_1_Master.kicad_sch; tools/schedit.py (180° labels) + test; DESIGN, TRACKER, viewer, changelog
**ERC:** 27 / 508 (was 74/508)  ·  **Net diff:** 11 nets each + one J1 pin — intended
**Done:**
- S4 closed: Nick's KiCad look OK, PR #12 merged (`9949b37`); S4 QE session archived (Nick)
- J1: 11 signal pins stubbed and labelled per the pin map, 17 unused GPIO pins no-connect flagged
- SW_EN label on the R10.1 / sheet-pin wire; SW_FLAGB sheet pin stubbed and labelled
**Broke/surprised us:**
- All 18 label_dangling errors cleared, including the sub-sheet hierarchical labels: KiCad reported each as
  "not connected" because its net held one pin, not because it was unwired
- One multiple_net_names line cites a different example label; count and type unchanged (ERC text varies run to run, QE N2)
**Next:** QE review (standing S5 session), then Nick's KiCad look; then S5.c pull-ups + sequencing
- QE round 1: **APPROVED WITH NITS** (DEV_LOG separator and wording, fixed); carry-over risk for S5.c: CE0
  (GPIO8) defaults high and can back-power the ADIN through its IO clamps while ADIN_VDDIO is off

---

## 2026-10-05 — Sprint S4.d — Footprints findable (library `Vault`); S5.a closed

**Branch:** sprint/4d-footprints
**Files touched:** new mote.pretty (43 footprints) + fp-lib-table entry; footprint fields on all sheets; tools/fpextract.py (+ test_fpextract.py); docs/design-review/vault_footprints.txt; DESIGN (D19), TRACKER, viewer, changelog
**ERC:** 74 / 508 (was 74/626)  ·  **Net diff:** identical except 117 footprint fields
**Done:**
- S5.a closed: Nick's KiCad look OK (asked the QE about the R11 cross / page contents), PR #11 merged (`10d64d0`)
- Extracted only the footprints the schematic uses (Nick: keep only what we use) with KiCad's own pcbnew
  (bundled Python 3.9), library nickname `Vault` = the board's prefix, so F8 re-links without replacing
- Verifier compares every board instance; negative test (moved pad, widened pad) is caught
**Broke/surprised us:**
- My first verifier rotated the wrong way (KiCad's y axis points down) and compared front-layer pad sizes
  on flipped parts (the mezzanine standoff has different front/back pads): 22 false alarms, fixed and proven
  with a deliberate-corruption test
- `pcbnew.FootprintSave` can't guess the library type of an empty folder; used PCB_IO_KICAD_SEXPR directly
- QE round 1: APPROVED WITH NITS (placed-pad check on all 150 instances, 10 nm). Expect ≈ 58 graphics-only
  library-mismatch DRC warnings (Altium import); verifier now catches a mirrored library; Value = footprint name;
  SMD/THT attributes + courtyards missing since import → S6/layout item
- QE round 2: **APPROVED**, no findings. Its report didn't arrive: the session-message tool pauses a session's
  sends after 10 messages without user input; Nick noticed nothing was running and I read it from the transcript
**Next:** Nick's KiCad look, merge; S4 then done.

---

## 2026-10-05 — Sprint S5.a — Payload load switch: U9 → TPS26621, R11 DNP; S4.c closed

**Branch:** sprint/5a-u9-replacement
**Files touched:** BM_Mote_1_Load.kicad_sch, BM_Mote_1_Master.kicad_sch; new nereus.kicad_sym + sym-lib-table entry; SPEC, DESIGN (D18), TRACKER (+rule: Sofar brief), viewer, changelog, CLAUDE.md; new docs/design-review/sofar_brief.md
**ERC:** 74 / 626 (was 76/629)  ·  **Net diff:** 50/50; kept parts identical; U9/R32/R33/TP34 out, U11/R41/R42 in
**Done:**
- S4.c closed: Nick approved PR #10, merged (`1f906bc`)
- Part search: TI TPS26621DRCR (JLC C1848341 via LCSC listing; TI ACTIVE; SLVSDT4F Rev. F read). Nick approved
  it plus the R42 pull-down (SHDN active low) and dropping PGOOD
- Symbol drawn from TI's pin table with pins on U9's old wire ends, so most wiring stayed; R11 DNP
- Started `docs/design-review/sofar_brief.md` (Nick: a tight mote-vs-shield table for Sofar, ships with the
  board); TRACKER rule 6 now requires a row for every deviation
**Broke/surprised us:**
- TI's product summary claimed PGOOD variants; the datasheet pinout has none (FLT only)
- JLC's parts page renders only with the browser pane visible; found the part via LCSC search results
- Quick Look (qlmanage) hung; rendered the schematic PDF page via PDFKit instead
- R11's description field says "205K OHM" (Altium import junk) — S6 cleanup
- QE round 1 (fresh S5 session): CHANGES REQUESTED. F1 MAJOR: R34's PART NUMBER field still said 374 kΩ
  (set_properties only changed what I named). F2 MAJOR: R42 100 kΩ had no worst-case SHDN margin (I used the
  typical 2 µA; max is 10 µA) → 10 kΩ. Also RTN = GND recorded (§12.1), QE N6 closed, stale SPEC/DESIGN U9
  lines, footprint-link accounting, R41 fields harmonised, sofar_brief row 5 detail
- QE round 2: **APPROVED WITH NITS**; N5 (current-limit start wording) fixed
**Next:** Nick's KiCad look, merge; then S4.d (footprints).

---

## 2026-10-05 — Sprint S4.c — Power budget (docs only); S4.b closed

**Branch:** sprint/4c-power-budget
**Files touched:** docs/design-review/power_budget.md (new); SPEC open questions, TRACKER, DESIGN results row, viewer, changelog
**ERC:** 76 / 629 (unchanged)  ·  **Net diff:** none (docs only)
**Done:**
- S4.b closed: Nick's KiCad look OK, PR #9 merged (`11914fb`)
- Budget from primary sources: RPi docs (Zero 2 W: 2 A PSU, 350 mA typical; **no undervoltage
  detector on the Zero range**; all models want 5.1 V), RPi product brief (5 V 2.5 A), TI SLUSEF4A
  Fig 7-2 efficiency, Pulse P890.B, ADI product page (ADIN2111 77 mW typ), IPC-2221
- Findings: U10's temperature is the binding limit (≈ 42–57 °C rise at 1 A, 90–121 °C at 2 A), not the
  bus; JP1 bridge fine (2.4 A at 10 °C rise). Proposals for Nick: P-S4c-1 Pi load ≤ 1 A continuous;
  P-S4c-2 keep R38 13.7 kΩ (USB-range corners)
- Split S4: footprints become S4.d (library named `Vault` to match the board's IDs)
**Broke/surprised us:** analog.com and onsemi datasheets wouldn't download (timeouts / landing page);
ADIN2111 2.4 V p-p power and the FPF2700 limit stay open (0.30 W allowance used for the 3.3 V domain)
- Nick decided D15 (Pi ≤ 1 A) and D16 (R38 13.7 kΩ); Nick found the FPF2700 datasheet (Fairchild
  Rev. 1.0.3): R34 sets ≈ 0.74 A typical, so Sofar Q3 is answered
- QE round 1: CHANGES REQUESTED. F1 MAJOR: I'd missed Bristlemouth v1's 12 W per-module limit (already
  in SPEC) — with a 1 A Pi the payload gets ≈ 6.2 W, and U9's 0.74 A limit doesn't enforce that →
  P-S4c-3 for Nick. Also L1's 0.656 Ω drop/heat, thermal caveats + ψJT bench check, camera figures,
  13.5 kΩ option, footprint count wording, Fig 7-2 legend note
- Nick asked for a lifecycle check: **FPF2700MX (U9) is obsolete** (Digi-Key). Captured in S5 (replace with a
  JLC-sourceable part) plus a whole-BOM lifecycle check before S6
- Nick: payloads are small devices, keep Sofar's payload port (D17); U9 needs a JLC-sourceable replacement (S5)
- QE round 2: CHANGES REQUESTED. F4 MAJOR: R11 (0 Ω across U9) is fitted in our files (and on the mote board),
  so U9 was bypassed — D17's premise was wrong. Nick: R11 DNP so the switch and limit work (S5). N6: U9
  replacement must handle output caps / hard shorts up to 32 V
- QE round 3: CHANGES REQUESTED. F5 MAJOR: D17 contradicted SPEC hard constraint 7 (no power-path part
  changes, naming U9/R34/R11). Nick explicitly amended constraint 7: payload load switch excepted (R11 DNP,
  U9 replaced, R34/R33/R35 re-derived); everything else stays Sofar's. N7 D14 wording, N8 viewer line
- QE round 4: **APPROVED WITH NITS**; N9 (three summary lines missing the D17 exception) fixed
**Next:** Nick's review, merge; then the U9 replacement + R11 DNP, and S4.d (footprints).

---

## 2026-10-05 — Sprint S4.b — Shield powers the Pi through bridged link JP1; S4.a closed

**Branch:** sprint/4b-pi-5v-jumper
**Files touched:** BM_Mote_1_Master.kicad_sch; new nereus.pretty (SolderJumper-2_R1210_Bridged_NetTie) + fp-lib-table; tools/midwire.py (+ test); SPEC, DESIGN (D14, D5 superseded), TRACKER, viewer, changelog
**ERC:** 76 errors / 629 warnings (was 78/629)  ·  **Net diff:** 53/53; existing connections identical; new net PI_5V
**Done:**
- S4.a closed: Nick's KiCad look OK, PR #8 merged (`b394edb`)
- Design discussion with Nick: solder jumper vs 0 Ω resistor vs bridged link. Nick's call: the shield
  powers the Pi by default, no DNP part; pads that fit a 0 Ω resistor. → JP1 bridged net tie on R11's
  1210 pads (D14, revises D5's "open by default")
- Found and fixed a tool bug: J1's pins were invisible to midwire/bbox_clear (symbol name ends in `_2_3`)
**Broke/surprised us:**
- First JP1 layout (vertical, close to J1) put rotated text on top of J1's value and the PWR_FLAG;
  caught in the render, re-laid out horizontally higher up. A label part-way along a wire left the
  wire's end dangling (+1 ERC warning); moved the label to the end
- QE round 1 (same S4 session): CHANGES REQUESTED. F1 MAJOR: D14 missed the USB back-feed path
  (Pi USB 5 V → L6 → U10 high-side body diode → VBUS/bus/payload). Checked the Pi Zero 2 W reduced
  schematic (power USB feeds 5V directly; data port not shown). Nick chose a bench rule over a hardware
  guard: no USB 5 V source on a bridged board, shield powered or not. F2–F6 fixed (note cites D14,
  demo line, footprint renamed SolderJumper-2_R1210_Bridged_NetTie, dead code, cut guidance)
- QE round 2 (same session): **APPROVED**, no findings
**Next:** Nick's KiCad look, merge; then S4.c (power budget incl. USB peripherals, bridge current,
footprints, U10 thermal).

---

## 2026-10-05 — Sprint S4.a — 5 V converter for the Pi (copy of U5); S3 closed

**Branch:** sprint/4-5v-converter
**Files touched:** BM_Mote_1_Power.kicad_sch, BM_Mote_1_Master.kicad_sch; tools/schedit.py (copy_block, set_properties; 12 tests); SPEC, DESIGN (D13), TRACKER, viewer, changelog, qe/S4.md
**ERC:** 78 errors / 629 warnings (was 76/562)  ·  **Net diff:** 53/53, 0 opens, 0 shorts; existing parts identical; 5 new nets
**Done:**
- S3 closed: Nick approved PR #7, merged (`09af9d8`); S3 QE session archived
- U10 block copied from U5 with `copy_block`; R38 13.7 kΩ, C56/C57 22 µF 16 V, C58 4.7 µF 10 V;
  L6 = same 8.2 µH as L3 (Nick). Values from TI SLUSEF4A and Pulse P890.B (read, cited in SPEC)
- 5V_PI to the Top-Level sheet via a new sheet pin + TP38
- Visual check of both sheets (SVG render)
**Broke/surprised us:**
- First placement of the 5V_PI wire ran across TP23/TP24's graphics on the Top-Level sheet
  (bbox_clear only checks pins, wire ends, labels and symbol origins, not bodies or text).
  Caught in the render; moved TP23/TP24 + their GND symbols 7.62 mm down (same connections)
- Murata's DC-bias tool needs a licence accepted, so the 22 µF parts' effective capacitance at
  5 V is an open question rather than a number; the Yageo datasheet link triggered a download
  prompt in Nick's browser pane (read via fetch instead)
- QE round 1 (fresh S4 session, report sent to me directly): CHANGES REQUESTED. F1 MAJOR: my
  `set_properties` silently skipped values containing `\"`, leaving stale 0603 size fields on
  C56/C57. Fixed the regex, made it refuse partial parses, added a test. Also F2 thermal item
  scheduled (S4.c), demo line, D13 ripple basis/Vout band/TI Table 9-2, R38 citation, C58 nudged.
  Report: `qe/S4.md`
- QE round 2 (same session): **APPROVED WITH NITS**; N1–N3 fixed (report typo, C58 10V text, bench item)
**Next:** Nick's KiCad look, merge; then S4.b (jumper to Pi pins 2/4).

---

## 2026-10-05 — Sprint S3 — Keep Sofar's power path for this board (D12)

**Branch:** sprint/3-power-path
**Files touched:** SPEC, DESIGN (D12; D7/D8 superseded), POWER_PATH (deferred banner), SOFAR_QUESTIONS (Q1, Q5 deferred), TRACKER, checklist viewer, README, CLAUDE.md, /agent-entry, PROMPTS §5, quality-engineer.md, qe/S3.md; no schematic change
**ERC:** 76 errors / 562 warnings (unchanged)  ·  **Net diff:** 53/53, 0 opens, 0 shorts (unchanged)
**Done:**
- Nick chose S3 next, then decided to cut risk on the first board: keep the mote's power path
  exactly as Sofar built it, rated ~20 W absolute max (890 mA per port inductor at 24 V). The
  design has years in the field and already powers Nick's cameras
- 50 W deferred to a later spin, scoped with the future motor load; the S3 inductor/e-fuse
  work moved to the TRACKER Icebox with its evidence kept in POWER_PATH.md
- S4 power budget and the S5 payload connector now check against 890 mA
- QE round 1 (fresh S3 session): CHANGES REQUESTED, schematic side all clean. I'd missed the
  README headline (still ~50 W) and left Sofar Q1 (e-fuse, worded for 50 W) as "send now"
  while its work moved to the Icebox. Fixed: README matches SPEC; Q1 deferred like Q5; Q3
  wording, POWER_PATH S3 references and the TRACKER demo line fixed. Report: `qe/S3.md`
- Process (Nick): the QE sends its report straight to the design session when done; Nick
  doesn't relay. Written into TRACKER rule 3.4, `quality-engineer.md` and PROMPTS §5
- QE round 2 (same session, report sent to me directly): **APPROVED WITH NITS**; all 5 fixed
  (PR body, process wiring, DEV_LOG layout, TRACKER demo line, qe/S3.md wording)
**Broke/surprised us:** nothing in the design. I proposed asking Sofar whether 20 W holds
when potted; Nick declined (field-proven), so no Q6
**Next:** Nick's docs review, merge; then S4 (5 V converter).

---

## 2026-10-05 — Sprint S2 — Mezzanine removed, Pi header J1 placed

**Branch:** sprint/2-pi-header
**Files touched:** BM_Mote_1_Master.kicad_sch; tools/schedit.py (new, 7 tests); exclusion list emptied; docs
**ERC:** 76 errors / 562 warnings (was 65/590)  ·  **Net diff:** 53/53, 0 opens, 0 shorts, 0 excluded
**Done:**
- Deleted P1, R9, 12 TPs, 14 mezzanine labels, 5 orphan power symbols, 2 NCs, 69 wires, 12 junctions
- Placed J1 (stock KiCad Pi header + 2×20 socket footprint), GND + PWR_FLAG, NC on 3V3, VBUS PWR_FLAG
- Verified: all 277 kept pins keep identical connections; J1's 8 GND pins on GND; visual check of the sheet (SVG render)
**Broke/surprised us:**
- First deletion pass trimmed the wire under the I2C1 labels (they sat part-way along a stub
  to P1), leaving them unnamed. Caught by the before/after net-name diff; schedit now shortens
  such wires instead of deleting them (test added)
- The mote's I2C pull-ups (R26/R27) were on the STM32 sheet, so the shield now has none.
  Nick decided the shield adds them (D11, S5 task)
- ERC errors rose, not fell: −27 (12 TPs, 13 mezzanine labels, U5 VIN, U6 GND) / +38 (29 J1 pins,
  8 I2C1/SCL/SDA labels now one-pin, J1.2)
- QE round 1 (separate session): CHANGES REQUESTED — my ERC owner table was hand-filtered and
  missed FID1–6, the SW_FLAGB/SW_PGOOD sheet pins and #PWR34 (also undercounted in S1). Fixed
  with `tools/ercsum.py`; also deleted a stale MEZZANINE text box. Report: `docs/design-review/qe/S2.md`
- QE round 2 (fresh session): APPROVED WITH NITS. N1: my F1 fix claimed SW_FLAGB/SW_PGOOD
  "lost P1" — false (copper: they never reached P1). Lesson: a fix to the docs is still a claim;
  check it against copper/netlist before writing it. All N1–N7 fixed; ercsum hardened
- Process: one standing QE session per sprint (Nick)
- QE round 3 (same standing session): **APPROVED**; 2 nits (R1 log wording, R2 TRACKER date) fixed
- Nick's KiCad look OK, via the worktree `open` command (his earlier S0/S1 looks had opened the
  stale main checkout; this look also confirmed S1's R8 junctions). PR #5 merged (`5885820`)
- Close-out slip: my close-out script failed on one HTML text match, but the chained git commands
  still committed and merged TRACKER alone. This follow-up PR syncs the viewer and DEV_LOG
**Next:** S2 done. Choose S3 (50 W power path) or S4 (5 V converter); fresh QE session for it.

## 2026-10-05 — Sprint S1 — Altium import fixed: 53/53 nets match the copper

**Branch:** sprint/1-import-fix
**Files touched:** ADIN2111, Load, Master, PoDL, PowerMon sheets; Processor/USB sheets deleted; tools/midwire.py (new); netcheck exclusions; docs
**ERC:** 65 errors / 590 warnings (was 90/578)  ·  **Net diff:** 53/53 matched, 0 opens, 0 shorts (14 S2 parts excluded)
**Done (Nick away; worked through the S1 checklist unattended, as Nick asked):**
- Exclusion list for S2 deletions (P1, R9, 12 TPs), approved by Nick
- 21 pins sat mid-wire (Altium connects them, KiCad doesn't): wire split + junction at each, via `tools/midwire.py --fix`
- Orphan Processor/USB sheets deleted; 65 `#PWR?` numbered `#PWR01`–`#PWR65`
- ADIN_VDDIO label verified correct, not changed; ADIN SPI/INT/RST verified to reach the Top-Level sheet
- Every remaining ERC error assigned to a sprint (DESIGN.md); edit log in `docs/design-review/changelog.md`
**Broke/surprised us:**
- The 33-junction zip had never been applied to the live project. Applied wholesale it
  fixed 4 nets but broke others (U9.1, U4.1/2, U1.39, U1.18/46, T1.6). Tested one junction
  at a time: each connects its pin but knocks a neighbour off the same wire. Splitting the
  wire is clean. The zip's 33 locations were right; the method wasn't
- The "65 duplicate references" never showed in kicad-cli ERC, because the CLI numbers `#PWR?` in its own report
- kicad-cli PDF size: `du` reported disk blocks; check.sh now prints real bytes
**Next:** S1 demo passed and KiCad look OK (Nick, 2026-10-05) → S1 done. Next: S2, mezzanine → Pi header (plan nibble).

## 2026-10-05 — Sprint S0 — Net check built; baseline recorded

**Branch:** sprint/0-net-check
**Files touched:** tools/ (new), .gitignore, docs/design-review/netcheck.md, docs/*, checklist HTML
**ERC:** 90 errors / 578 warnings  ·  **Net diff:** 42/68 matched, 26 opens, 0 shorts
**Done:**
- `tools/netcheck.py` (stdlib, 5 unit tests) compares schematic connectivity
  with the mote copper; `tools/check.sh` runs ERC + netlist + PDF + netcheck
- Baseline in DESIGN.md; every open listed in `docs/design-review/netcheck.md`
**Broke/surprised us:**
- The junction fix isn't complete: 26 copper nets are still split, mostly
  single pins on wire midpoints (TP20/21/22, C13/C14, D4/D5 pin 1, R1 pin 1, …)
- The untouched reference schematic has 38 opens against its own copper, so
  this is import damage
- The probe's 48/74 became 42/68 in the tool: same opens, minus 6 trivially
  matched single-pin nets
**Next:** S0 demo passed (Nick, 2026-10-05) → S0 done. Next: S1, fixing the 26 opens (plan nibble).

## 2026-10-04 — Sprint S0 — Project renamed, junk untracked, rating defined

**Branch:** sprint/0-repo-baseline
**Files touched:** project folder (rename only), 58 files untracked, docs/*
**ERC:** 90 errors / 578 warnings, the same before and after  ·  **Net diff:** clean (library path only)
**Done:**
- S0.1: `_002` → `nereus_Pi_shield_ADIN2111/`; the stray `.kicad_pro` was byte-identical
- S0.2: `git rm --cached` for everything `.gitignore` covers
- Recorded Nick's decisions: ~50 W absolute max at 24 V (D8); potted, so newly
  sourced parts can't be electrolytics or PPTCs, while vetted Sofar parts stay
  as-is (D9, SPEC constraint 8)
- Bourns SRF1260 datasheet figures added to POWER_PATH; this explains the mote's 20 W
- New `docs/SOFAR_QUESTIONS.md` (Q1 e-fuse, Q2–Q4 moved from SPEC, Q5 MSD1514/damping)
- `pi-shield-checklist.html` rebuilt to mirror TRACKER: S0–S6, Sofar questions,
  status panel; finished work marked "✓ in repo" in the data (D2 revised;
  TRACKER rule 6 now requires syncing it every PR)
**Broke/surprised us:**
- kicad-cli ERC names different example labels from run to run; compare counts, not text
- No fuse or e-fuse anywhere on the through path (Nick remembered one; asked Sofar, Q1)
- The FPF2700 datasheet link on onsemi is dead
**Next:** S0.3, the net-check method.

## 2026-10-04 — Pre-work — Docs fitted to the KiCad project

**Branch:** claude/kicad-docs-setup-19be00
**Files touched:** CLAUDE.md, README.md, .gitignore, docs/*, .claude/skills/*, checklist banner
**ERC:** not run (no schematic edits)  ·  **Net diff:** n/a
**Done:**
- Templates filled for schematic capture; sprint ladder S0–S6 built from the
  checklist, plus the new S3 (50 W power path)
- `docs/POWER_PATH.md` seeded from Evan's two Sofar references
- `/agent-entry` and `/capture-task` skills added
**Broke/surprised us:**
- Live PoDL inductors are SRF1260-101M (~20 W), so 50 W touches the whole power path
- The Processor and USB sheets are orphan files, not part of the hierarchy
- MSD1514 (Sofar's 50 W pick) is 15.5 × 15.5 × 14.2 mm, which is tight on a Pi Zero board
**Next:** S0.1, plan nibble — Nick gate.

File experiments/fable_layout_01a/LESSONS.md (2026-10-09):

# LESSONS — layout experiment 1.a, sessions 1 and 2 (2026-10-08)

*Written at the wind-down of session 2 for Nick's review and for session 2.b. The numbers are from `out/m4/`,
`out/before_after/` and the two QE reports in `qe/`. The before/after page (`out/before_after/index.html`) and the
design review (`out/review/index.html`) are the pictures behind this text.*

## 1. What the experiment answered

- **Can an agent reach the brief's bar by moving blocks and routing at the class widths?** Yes for everything the
  brief measures: 0 open links but J1's no-connect pair, 0 new segments below class, 0 thin links beyond a pad field,
  0 class-clearance items, 0 DRC errors of new copper (111 errors, all Sofar's copied features with reasons), 0
  dangling copper, pairs 9.46 / 8.80 / 17.98 / 18.62 mm against 9.5 / 9.5 / 21.3 / 21.3, Kelvin by track, blocks
  rigid and complete. QE round 2: APPROVED WITH NITS.
- **Did it produce a board a person would sign?** Not yet. Two things a reviewer sees at once are not in the brief's
  bar: the 45° runs are 0.1 mm-grid staircases (25–40 segments per pair leg), and two SPI nets (ADIN_MISO, ~{ADIN_CS})
  detour 25 mm down the west edge past the inserts instead of running straight under U1 to J1's SPI pins. Both are
  router behaviour, not placement, and both are fixable (§4).
- **Nothing moved between the start and the end of session 2.** 138 footprints in the same positions; all change
  is copper. The before/after page shows the measured items getting better and the SPI nets getting longer.

## 2. What cost the most time, and why

1. **A pair emitter that was never checked on the board.** Session 1's `commit_pair` passed its blank-board unit
   test and shipped two P–N shorts at the transformer pads, hidden by an exclusion pattern that matched any item
   touching a T pad. Lesson: every emitter's output is checked on the real board with pcbnew shapes before it is kept
   (`pair_check`), the exclusion classifier must name the specific items it excuses, and a unit test on a blank board
   proves geometry, not placement. Session 2's real-board test found five further defects the blank board could not.
2. **Figures that interact.** A straight via pair followed by a swap, with a turn between them, put vias 0.48 mm apart
   although each figure alone was clean, and a spacing counter in the A* state let the path loop back over its own
   vias. Lesson: a layer change is a macro with straight runs on both sides, the first steps after it continue
   straight, and only one mid-route figure (the swap) is placed by the search; the layer changes at the ends are
   fixed geometry (vias straight out of the pins, a via pair beside the pads' approach), as Sofar's mote has them.
3. **Conservative cell maps.** The 0.1 mm grid carries a 0.07 mm margin and assumes a 0.3 mm drill; it rejected the
   pins' vias and stubs that clear by 0.2 mm. Lesson: fixed geometry is checked exactly (`seg_free_exact`,
   `hole_free_exact`, `via_free_exact` with the class's real sizes); the maps are for the search, not the verdict.
4. **The pocket's exits.** U1 sits in a 10 × 12.6 mm pocket between the insert keep-outs; its south exit (x −4 … 3,
   y 37.4 … 38.8) must carry the port-2 pair, U2/U3's fan-out vias and four Internal 2 corridors. Each fix there moved
   something else (three routing rebuilds went to this one spot), and the SPI finally left by the west edge. Lesson:
   reserve corridors before routing (the SPI lane under U1 to J1, the fan-out vias) instead of letting the shortest
   path win net by net; and give the pocket room (Nick's decision, §3).
5. **Stale snapshots.** Pours and patches are created in the M3 step; a `START=m4` rerun restored the old snapshot and
   a routing rebuild was spent on a pour that was not there. Lesson is written into `build_all.sh`'s comment and
   HANDOFF: anything in `make_planes` needs `START=m2`.
6. **Autonomous iteration without pictures.** Nick could not tell from the log whether the board was getting better
   or worse. Lesson: render the regions after every rebuild (`tools/review_views.py`, `tools/before_after.py`) and
   put the mote's copper beside ours; the numbers alone do not show a 25 mm detour.

## 3. Nick's decisions at the wind-down (2026-10-08)

- **Board 3 mm wider and 3 mm taller** (49 × 68). The brief's growth allowance (2 mm south) is superseded; the frame,
  `geom.OUTLINE`, the fixed positions and the keep-outs move with it in 2.b.
- **Inserts 1–2 mm closer to the west wall.** Measured on the mote: the corner inserts' centres sit 3.5 mm from the
  edge (MP1/MP3; MP2/MP4 7.0 mm), so their Ø7.4 ring copper reaches the outline there. Ours sit 5.69 mm from the edge
  (copper to edge 2.0 mm). With the brief's 0.5 mm copper-to-edge rule the centre can come to 4.19 mm from the edge
  (a 1.5 mm shift); 2 mm needs the edge clearance relaxed to 0 at the rings, as the mote. 2.b decides after fetching
  JLCPCB's figure. Sofar's keep-out radius (4.8 mm, no other-net copper) is unchanged by the shift.
- **SPI is critical** (it is how the Pi talks to the ADIN). The SPI nets go straight from U1 to J1's SPI pins on a
  reserved Internal 2 lane, routed first; no edge detour. Length matching is **not** required (§5).
- **JLCPCB's design rules before any further edit.** M3's DFM fetch moves to the front of 2.b: every limit from
  JLCPCB's published pages, cited in `DFM.md`, encoded in the design rules, DRC re-run, before the board changes.
- **Routing style:** straight lines and 45° angles, collinear steps merged, no back-and-forth; the staircases are
  removed in the emitter, not by hand.
- **"The ADIN should be in the middle of the board"** (Nick, at the wind-down). Experiment 01 put U1 in the west pocket
  only because its 9.12 mm courtyard did not fit the 8.0 mm band between the two inductor envelopes (01 BRIEF §2 /
  DEV_LOG 2026-10-07). With 3 mm more height spent on that band it becomes ≈ 11 mm, U1 fits between the ports as on
  the mote (each transformer beside its own inductor, port 1 south, port 2 north), the pairs get shorter and
  symmetric, the SPI runs straight east to J1 with no pocket exit, and the pocket's crowding (§2.4) disappears. The
  cost: the ADIN block's bottom-side parts (U2, U3, Y1, the decoupling) go under the band, where the T1/T2 clusters and
  B18 sit today, and the 1V8 / 3V3 / PWR corridors re-plan. Nick's reasons: central to everything it talks to (both
  inductors / transformers, the header), and **away from the board edge, where strain and deflection concentrate**:
  a 48-pin 0.5 mm-pitch QFN is the part on this board most sensitive to flex, and the west pocket puts it between the
  housing hole, the inserts and the free edge. 2.b evaluates the centre first, as M0 did, with a trial placement
  through M2 on a scratch copy (centre vs pocket, numbers side by side); the centre is the preferred answer unless
  the trial shows it cannot meet the bar.

- **Cut jumpers visible and reachable.** JP1 (5 V to the Pi) and JP2 (the LED supply) go on the top side near a
  board edge with no tall part beside them, so a user can see them and cut them. Today JP1 is on top at the strip's
  north end between L6 (an inductor) and J1; JP2 is on the bottom under the LEDs. 2.b places both at an edge on top
  and says what their nets' routing costs.

## 4. What 2.b has to do, in order

1. Fetch and encode JLCPCB's limits (BRIEF §6 list) into `.kicad_pro` / `.kicad_dru`; `DFM.md` with URL + date per
   row; DRC on the current board to see what the real rules say about it before anything moves.
2. Grow the board to 49 × 68 and move the inserts west (decide the shift from the fetched edge rule); re-derive the
   fixed items and keep-outs (`geom.py`, `m1_fixed.py`, `check_fixed.py`) and prove them. Write an OPTIONS addendum:
   U1 in the centre of the widened band vs U1 in the pocket, each tried through M2 on a scratch copy, with the pair
   lengths, the SPI lengths, the pocket/band occupancy and the courtyard result side by side; recommend; Nick decides.
3. Router: emit 45° runs as single segments (merge collinear steps in `Grid.polyline` and in `commit_pair`), keep the
   pair lengths under the limits (BM1_DATA_P has 0.04 mm of margin today; the wider pocket should give more).
4. Reserve corridors before routing: an Internal 2 SPI lane under U1 to J1 pins 19/21/23 (+ ~{CS} 24), the fan-out
   vias, then the pairs, then the rest; the SPI must not use the west edge.
5. Rebuild from M1 (the placement changes), full checks, renders, the review pages, QE round 3, Nick's review.

## 5. SPI length matching (Nick's question)

Not needed. The ADIN2111's SPI clock is in the tens of MHz (the exact maximum is the datasheet's figure, to be
quoted in 2.b, not typed here); even at 25 MHz a 25 mm difference between two traces is about 0.15 ns of skew against
a 40 ns clock period, under 1 % of a bit. What matters for SPI on this board: keep SCK, MOSI, MISO and ~{CS} short
and on one reference plane (the GND plane In2 is next to Internal 1; Internal 2 sits between the GND and PWR planes,
both fine), keep them 0.35 mm from the bus nets and away from the 10BASE-T1L pairs (they share no layer with the pairs
when SPI is on Internal 2), and do not run them along a board edge, which is what the detour did. Equal length is a
requirement for the Ethernet pairs' P and N legs, not for SPI; the pairs are within 0.7 mm of each other here, which
at 7.5 MBaud is irrelevant too, but the brief holds them to the mote's lengths and they meet it.

## 6. Things to keep (they work)

`tools/test_pair.py` (18 cases + the real board), `pair_check`, the fan-out-first step, the protected mote pad-to-pad
items, the hand-via mechanism with its proof, the exact checks for fixed geometry, the DRC exclusion table with one
reason per item, the review and before/after page generators, the pipeline's snapshots and restarts.

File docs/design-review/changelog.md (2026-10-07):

# Schematic change log

*Every edit to the live schematic, newest sprint first. Part of the S6 design-review package.*

## S6.g — Presentation clean-up (Nick's list, 2026-10-07, branch `sprint/6g-presentation`)

Positions, text, graphics and label names only (D30); pin connections identical (checked as a pin partition).

| # | Sheet | Change |
|---|---|---|
| 1 | Top-Level | VBUS_OUT symbol beside TP36 / the Load Switch block (was ~85 mm away on a long wire) |
| 2 | Top-Level | I2C1_SDA/SCL page-long runs to the PoDL block removed; both ends already labelled, short labelled stubs at the PoDL pins |
| 3 | Top-Level | R43 (ADIN_PWR pull-down) + GND moved beside the ADIN block's HW_EN pin, hanging from TP8's junction; its separate ADIN_PWR label removed |
| 4 | Top-Level | J5 moved beside the Load Switch block and wired to its VBUS_OUT wire (mirrored, pins facing right): J5.1 → the VBUS_OUT wire (junction with the VBUS_OUT symbol, TP36 and the block), J5.2 → GND below; its own VBUS_OUT symbol (#PWR80) and leads on the right removed; note underneath (Nick: keep the connector with the switch that powers it) |
| 5 | Cover | the two mote renders and the old sheet-index image replaced by a grey "Pi shield renders: TBD (after layout)" box and a text index of the 7 real sheets; DIMENSIONS → TBD (cover file 8 MB → 0.4 MB) |
| 6 | ADIN | U1B + U2/U3 supplies block and the status-LED block moved apart from U1A, each with a header |
| 7 | Power | 3V3 (U5), 1V8 (U6) and 5V (U10) converters spread out, each with a header; the 1V8 feed wire stretched along its axis |
| 8 | all | KiCad title block filled on every sheet (date, rev AA, `${PCBPARTNAME} · ${PCBPARTNUMBER}`, author, "Derived from Sofar mote 000639-AB"); the Altium overlay texts (${TITLE}, ${PCBPARTNUMBER}, ${REVISION}, ${AUTHOR}, sheet numbers) that ran off the page removed. Cover revision table kept inside the page: AA · 2026-10-07 · NB · "First release, derived from Sofar mote 000639-AB"; licence note and CC logo moved clear of the title block |
| 9 | Top-Level, Load, ADIN | names (D30): ADIN_RST/INT → ~{ADIN_RST}/~{ADIN_INT}; ADIN_NSS → ~{ADIN_CS}; SW_EN (+ Load's SW_ON) → PAYLOAD_EN; SW_FLAGB → ~{PAYLOAD_FAULT} (labels, hierarchical labels, sheet pins); ADIN_P1/P2_LED1 → ~{…} |
| — | Top-Level | R11 note rewritten as an open / fitted summary (Nick): "R11 (0 Ω, DNP): bypass for payload switch U11. When open (as built): payload on only when the Pi sets PAYLOAD_EN; U11 limits it to ~0.73 A and flags faults on PAYLOAD_FAULT (active low). When fitted: payload always on at bus voltage (VBUS); no switching, no current limit, no fault flag." Box widened |
| — | Power | sheet title "Buck Converters - 3V3, 1V8, 5V" removed: the three converter headers replace it (Nick) |
| — | Top-Level | headers in the style of the other blocks (Nick): "RASPBERRY PI - 40-PIN HEADER" under J1, "LOAD SWITCH - PAYLOAD POWER" under the Load Switch block |
| — | ADIN, Power | QE nits: ~{ADIN_P2_LED1} label dropped 2.54 mm on a jogged stub (its overbar touched pin 47's wire); 1V8 header 2.54 mm right (it sat on the feed wire) |
| — | Top-Level | QE round-2 nit: ~{PAYLOAD_FAULT} label dropped 2.54 mm on a jogged stub (its overbar touched the PAYLOAD_EN wire) |
| — | .kicad_pro | 8 ERC exclusion keys regenerated (U5/U10/U6 and #PWR34 moved); the 18 reasons unchanged |

**Verified:** same pin partition (109 nets), 7 renamed as above; ERC 495 → 492 → **494**/0 errors (−2 off-grid wires of the
old I²C runs, −1 SW_ON/SW_EN duplicate name; the 1V8 feed wire re-measured; then +2 off-grid for the jogged pin-48 stub, since
U1's pin 48 sits off-grid in Sofar's symbol); ercexclude 18/0/0/0; netcheck 51/51;
midwire 0; every sheet rendered and checked.

## S6.f — Author + BOM PDF (2026-10-07, branch `sprint/6f-author`)

| Change | Where |
|---|---|
| Text variable `AUTHOR` "=ProjectAuthor" (Altium placeholder) → "Nick Buemond" (Nick): every title block | `.kicad_pro` |
| `docs/design-review/bom.pdf`: review PDF of `bom.csv` (A3 landscape; changed lines highlighted) | `tools/bompdf.py` + `tools/html2pdf.js` (AppKit print to PDF via osascript) |
| `docs/design-review/schematic.pdf` re-exported (title blocks show the author) | docs |

**Verified:** netlist identical; ERC 495/0/495; ercexclude 18/0/0/0; netcheck 51/51; midwire 0; all 7 title blocks render
"Nick Buemond" (SVG export).

## S6.e — Review package (2026-10-06, branch `sprint/6e-review-package`)

| Change | Where |
|---|---|
| Description "RES SMD 205K OHM 1% 1/2W 1992" (Altium import, wrong) → "RES SMD 0 OHM JUMPER 1210" | R11 (Top-Level), R12, R13, R17, R19 (PoDL): CRCW12100000Z0EA is Vishay's 0 Ω jumper (MPN code "0000Z0"; `bom_lifecycle.md` S5.e row; the symbols' own RESISTANCE field "0mR"). Field text only, same part |
| `netcheck.md` gains "Schematic nets with new parts": every net touching a part with no pins on the mote's copper (new parts, plus MP1–MP4 with unnumbered insert pads), with all its pins (unconnected single pins collapsed into one row) | `tools/netcheck.py` (+ test) |
| Package index `docs/design-review/README.md`; reviewed snapshot `docs/design-review/schematic.pdf` (rev AA) | docs |

**Verified:** netlist identical except the 5 Description values; ERC 495/0/495; ercexclude 18/0/0/0; netcheck 51/51;
midwire 0; tool tests OK.

## S6.d — Minor schematic tidy (2026-10-06, branch `sprint/6d-tidy`)

Nick: small readability fixes on Sofar's design, no overhaul. Positions, text and dead wires only.

| Sheet | Change |
|---|---|
| Top-Level | R27 / R26 moved onto J1's I2C1_SDA / I2C1_SCL stubs (wire from the stub label straight into each resistor, then 3V3); their floating copies' labels and wires removed; text on one line above (R27) / below (R26) |
| Top-Level | dead `3V3` stub removed (#PWR06, 3 wires, 1 junction: no pins on it) |
| Top-Level | ADIN_MISO/MOSI/SCK/NSS/RST/INT wires start at their labels (were 25 mm dangling lead-ins from x 269.24); dead ADIN_PWR lead-in left of TP8 removed, and the junction there (now redundant; QE N2) |
| Top-Level | note "Processor + onboard logic runs off 3V3, and ADIN AVDD off 1V8." → "Shield logic runs off 3V3; ADIN AVDD runs off 1V8." (box 12.7 → 7.62 mm tall) |
| Top-Level | bus note: Sofar's 3 lines at the J5 note's font size (2.286 → 1.27 mm), box 19.05 → 8.89 mm: no longer wraps to 5 lines |
| ADIN | D10 + R46 moved to an even 17.78 mm pitch (x 388.62 → 358.14); R3 / R5 rotated vertical under D9 / D10 (pin 1 on the cathode node), ADIN_VDDIO symbols (#PWR49 / #PWR34) below them; R5's separate ADIN_P2_LED1 label + wire removed (R5 now on the node) |
| ADIN | ADIN_LED_VDD label moved off the D9 junction (x 327.66 → 342.9; wire split moved with it) |
| ADIN | R4 / R6 text off their pins: R6 in R2's layout; R4 on one line above its wire (the ADIN_P2_LED1 stub label is below) |
| ADIN | "Set for 1Vp-p comms." note widened 27.94 → 33.02 mm (it wrapped into the SWPD note below) |
| .kicad_pro | #PWR34's ERC exclusion key regenerated (`ercexclude.py --write`): position 198.12 → 200.66 mm, reason unchanged |

**Verified:** nets identical (all 109, same pins) after every step; ERC 504/0/504 → **495/0/495**: the 9 removed items are
all `unconnected_wire_endpoint` (the dead stub and lead-ins), no item added; ercexclude 18/0/0/0 (only #PWR34's key
changed); netcheck 51/51; midwire 0. Each change checked in a rendered SVG. Not done (more than minor): J1 moved to the
right of the sheet; Sofar's 2 PoDL wire ends.

## S6.c — Footprint types and courtyards (2026-10-06, branch `sprint/6c-footprints`)

Library `mote.pretty` (`Vault`) only, D29; no schematic or pad change. 43 footprints: one `(attr …)` line and four F.CrtYd
`fp_line`s each, inserted as text (0 lines removed). Per-footprint type, courtyard size and source:
`docs/design-review/footprints.md`. New `tools/fpattrs.py` (+ `test_fpattrs.py`). `nereus.pretty`'s jumper already had both.

**Verified:** `fpextract --verify` 0 problems (pads identical to the mote board); every written file re-loaded with pcbnew
(type and 4 courtyard lines read back); a second run changes nothing; `check.sh` unchanged (504/0/504, 51/51, midwire 0).

## S6.b — ERC clean or justified (2026-10-06, branch `sprint/6b-erc`)

| Change | Where |
|---|---|
| Title block rev `=ProjectRevision` (Altium placeholder) → `AA` | all 7 sheets (`title_block`) |
| Text variables `PCBPARTNAME` = nereus_Pi_shield_ADIN2111, `PCBPARTNUMBER` = PCB-000001-AA, `PROJECTREVISION` = AA (Nick) | `.kicad_pro` `text_variables` |
| 18 ERC exclusions, comment = reason (FID1–6, MTG1–4, #PWR34, U5/U10 SW+CB, U6 SW/VIN/VOS) | `.kicad_pro` `erc.erc_exclusions`, from `docs/design-review/erc_justifications.csv` |
| New `tools/ercexclude.py` (+ `test_ercexclude.py`): regenerates / checks the exclusions; `check.sh` runs the check | tools |

**Verified:** ERC 531 / 27 / 504 → **504 / 0 / 504**; the 504 warnings item-for-item unchanged. Netlist: the 7 revs and 3
text variables only; nets identical. netcheck 51/51; midwire 0. A deliberately stale exclusion makes `check.sh` exit 1
with ERC 1 error. Title blocks render "Rev: AA" and PCB-000001-AA on every sheet (SVG export). Still showing:
"=ProjectAuthor" (needs a name from Nick; set to Nick Buemond in S6.f).

## S6.a — BOM hygiene (2026-10-06, branch `sprint/6a-bom-hygiene`)

Six sheet files (root untouched); flags and one field only. No connection, value or footprint changed.

| Change | Refs |
|---|---|
| `(in_bom yes)` → `(in_bom no)`: bare copper pads and holes, not purchased | TP1–3, TP5, TP7, TP8, TP13, TP19–24, TP35, TP36, TP38; FID1–6; MTG1–4 (26) |
| + `MANUFACTURER` (hidden), from `bom_lifecycle.md`'s Mfr column (S5.e, Digi-Key-checked) | the 75 BOM parts (76 blocks, U1 ×2) with no `MANUFACTURER`; J1 has no part yet. Sofar's `MFR_NAME` (U5/U10), `MANUFACTURER1` (D1: its *second source*, Vishay) and `MANUFACTURER 1` (R15/R16) untouched; D1's `MANUFACTURER` = STMicroelectronics (its specified part) |

**Verified:** structural compare against `main`: 26 `in_bom` flips, 76 appended hidden `MANUFACTURER` fields, nothing else.
Netlist: + 26 `exclude_from_bom` markers and the new `MANUFACTURER` fields only. ERC 531 / 27 / 504, items identical
with locations stripped (one `multiple_net_names` item names VBUS or 5V_Buck_Input as the second label from run to run on
the unchanged base too). netcheck 51/51; midwire 0. `bom.csv` 51 rows (TP/FID/MTG rows gone), `Mfr` blank only on J1.

## S5.i — Planned part per BOM line (2026-10-06, branch `sprint/5i-planned-parts`)

Six sheet files (root sheet untouched); fields only (D27). No connection, value or footprint changed.

| Change | Refs |
|---|---|
| + `PLANNED MPN`, `PLANNED MFR`, `PLANNED LCSC`, `PLANNED NOTE` (hidden) | all 106 purchased parts (U1 on both units); not TP/FID/MTG or JP1/JP2 |
| `SOURCING` → "Planned part from LCSC once Sofar approves it (D27); until then the specified part via JLC global sourcing" | the 19 parts on the 9 changed passive lines |
| `Footprint` property line re-indented 4 → 2 tabs (whitespace only) | U11, R41, C56, C57, C58 (S4/S5 leftovers; `set_properties` refuses a symbol with an unparsed property) |
| `.kicad_pro`: view renamed "Sofar review (planned parts)": Refs, Qty, Value (MPN), Mfr, **Planned MPN/Mfr/LCSC, Planned note**, DNP, Sourcing, Alt1/Alt2, Alt note, Footprint (the specified part's LCSC column dropped: Planned LCSC replaces it) | `bom_presets` + `bom_settings` |
| `tools/check.sh` exports `bom.csv` with `--preset "Sofar review (planned parts)"` (one definition for the view and the file; fails with a restore hint if KiCad dropped the preset) | — |

**Verified:** 428 fields added (107 blocks × 4); a structural compare against `main` finds every other existing
property unchanged and in order, nothing outside symbol blocks changed, every new field hidden. Netlist: the only removed
lines are the 19 old `SOURCING` values; all other lines added are the new fields. ERC 531 / 27 / 504, items identical
with locations stripped; netcheck 51/51; midwire 0. `bom.csv` (54 rows) reproducible; 11 rows where Planned ≠ Value
(the 10 changes + J1 TBD).

## S5.h — BOM alternates as hidden fields (2026-10-06, branch `sprint/5h-bom-fields`)

Six sheet files (the root `nereus_Pi_shield_ADIN2111.kicad_sch` untouched); fields only (D26, `docs/design-review/bom_alternates.md`). No connection, value or
footprint changed. Every new field is hidden, at the symbol origin.

| Change | Refs |
|---|---|
| + `ALT1 MPN`, `ALT1 MFR`, `ALT1 LCSC`, `ALT2 MPN`, `ALT2 MFR`, `ALT2 LCSC`, `ALT NOTE`, `SOURCING` ("JLC global sourcing (first build) until an ALT is approved (D26)") | 24 flagged passives: R34 (Load); R20, R39, R21, R37, C31 (Power); R35 (Load); R43 (Master); R8 (PowerMon); C16–C19, C21–C27, R14–R16, R18 (PoDL) — values per `bom_alternates.md`; empty where it lists no alternate (R20/R39 and R15/R16 ALT2, C22/C23 both) |
| + `SOURCING` only | U1 (both units), U2, U3, Y1 (ADIN2111); L3, L6 (Power); D1, D2 (PoDL); D3 (Load); MP1–MP4, J5, J1 (Master) |
| J1 `Footprint` property line re-indented 4 → 2 tabs | whitespace only (import leftover, like JP1 in S5.f); `set_properties` refuses a symbol with an unparsed property |
| `tools/check.sh` exports `docs/design-review/bom.csv` (tracked) | `Value (MPN)` = the specified part, then Mfr, LCSC, Sourcing, Alt1/Alt2 MPN/Mfr/LCSC, Alt note; grouped by Value and DNP |

| `.kicad_pro`: Symbol Fields Table view **"Sofar review (alternates)"** (`bom_presets`), also the view the dialog opens with (`bom_settings`, was "Default Editing") | Refs, Qty, Value (MPN), Mfr, LCSC, DNP, Sourcing, Alt1/Alt2 MPN/Mfr/LCSC, Alt note, Footprint; grouped by Value + DNP; BOM-excluded parts (JP1/JP2) hidden. `kicad-cli sch export bom --preset "Sofar review (alternates)"` gives the same 54 groups as `bom.csv`, every cell equal. Added after Nick's look: new fields need their columns switched on, and the ones he enabled landed after the wide Footprint/Datasheet columns |

Field text follows `bom_alternates.md` except: C22/C23 `ALT NOTE` leaves out the plan's "(DK 78,606)" (stock figures drift; it stays in
the plan); R8 `ALT NOTE` is "Sofar review: power-path current sense; check land pattern" (Nick: at most 3 alternates per part; R8's
7 Sofar fields `MANUFACTURERPARTNUMBER1–7` stay untouched, outside bom.csv).

**Verified:** 208 fields added (24 × 8 + 16 SOURCING blocks); a structural compare against `HEAD` finds every existing
property of every symbol unchanged and in order, nothing outside symbol blocks changed, and every new field hidden.
Netlist diff: 0 lines removed; all 414 added lines are the new fields (component `property` + libpart `field`). ERC
531 / 27 / 504, item-for-item identical to the baseline apart from which copy of a repeated label `multiple_net_names`
cites (KiCad's choice varies between runs on the same file); netcheck 51/51; midwire 0.

## S5.f — ADIN status LEDs (2026-10-06, branch `sprint/5f-adin-leds`)

ADIN sheet (`BM_Mote_1_ADIN2111.kicad_sch`), D25:

| Change | Detail |
|---|---|
| **JP2** | clone of JP1 (`Jumper:SolderJumper_2_Bridged`, `nereus:SolderJumper-2_R1210_Bridged_NetTie`, not in BOM); ADIN_VDDIO (#PWR82) → JP2 → net ADIN_LED_VDD |
| **R44, R45** | clones of R1 (RC0402FR-071K5L 1.5 kΩ) |
| **D8** | `Device:LED`, KT-0603R red (C2286), `LED_SMD:LED_0603_1608Metric`; ADIN_LED_VDD → R44 → D8 → GND (#PWR83) |
| **D9** | `Device:LED`, KT-0603YG yellow-green (C2289); ADIN_LED_VDD → R45 → D9 → label ADIN_P1_LED1 |
| **R46, D10** (port 2, added at Nick's request) | R1 clone + KT-0603YG; ADIN_LED_VDD → R46 → D10 → label ADIN_P2_LED1 |
| **R5 moved** (with #PWR34 and their wire) | same shift as R3, into the LED group; connections unchanged |
| U1 pin 48 | 5.08 mm stub + label ADIN_P2_LED1 |
| **R3 moved** (with #PWR49 and their wire) | from beside U1 into the LED group, onto the grid; connections unchanged (pin 21 net and ADIN_VDDIO) |
| U1 pin 21 | 5.08 mm stub + label ADIN_P1_LED1 (R3 used to touch the pin directly) |
| Note | LED functions, Pi enable, strap, cut JP2 |

**Verified:** netlist diff = the pin-21 / pin-48 nets renamed ADIN_P1_LED1 / ADIN_P2_LED1 with + D9.1 / D10.1; ADIN_VDDIO
+ JP2.1; GND + D8.1; new nets ADIN_LED_VDD (JP2.2, R44.2, R45.2, R46.2), Net-(D8-A), Net-(D9-A), Net-(D10-A); nothing
else. ERC 27/508 → 27/504 (off-grid −3 each for the R3 and R5 groups on grid, +1 each for the two stubs on U1's off-grid y); netcheck 51/51; midwire 0. The mid-wire junction quirk (SPEC) bit once:
the ADIN_LED_VDD wire is split at the junction and at the label.

## S5.g — Footprint library 3D fixes (2026-10-06, branch `sprint/5g-footprint-fixes`)

Library `mote.pretty` (`Vault`) only, D24; no schematic change, no pad change:

| Footprint | Change |
|---|---|
| 78614015360-Footprint-2 (MP1–MP4, PoDL inserts) | model `FST-000629.STEP` opacity 0 → 1 (pads untouched: contact question → Sofar Q6) |
| CAPC1608X100X20ML10 (C31) | + `Capacitor_SMD.3dshapes/C_0603_1608Metric.step` |
| CAPC2013X145X50LL20T25 (C19, C27) | + `Capacitor_SMD.3dshapes/C_0805_2012Metric.step` |
| CRCW08057R50FKEAHP-Footprint-1 (R15, R16) | + `Resistor_SMD.3dshapes/R_0805_2012Metric.step` |
| RESC1005X40X25LL05T10 (R22, R34, R40), RESC1005X40X25ML05T10 (R1), RESC1005X40X25NL05T10 (R10's, unused) | + `Resistor_SMD.3dshapes/R_0402_1005Metric.step` |
| RESC1608X60X55ML20T10 (R8) | + `Resistor_SMD.3dshapes/R_0603_1608Metric.step` |

**Verified:** `fpextract --verify` 0 problems (pads identical to the board); all 8 footprints load in pcbnew with their
model at opacity 1; ERC/netcheck unchanged. A first draft also renumbered the insert pad and taught fpextract about it;
both reverted after QE S5.g F1 (the bus contact is a front copper ring) and Nick's call to ask Sofar first.

## S5.d — Payload connector J5 (2026-10-06, branch `sprint/5d-payload-connector`)

Top-Level sheet: **J5** JST GH SM02B-GHS-TB (LCSC C189893), footprint
`Connector_JST:JST_GH_SM02B-GHS-TB_1x02-1MP_P1.25mm_Horizontal`; pin 1 → VBUS_OUT symbol (#PWR80), pin 2 → GND
(#PWR81); note text below it. Placed on the right side under MP1–MP4, pins on the inserts' column (Nick: interconnects
live on the right; moved after his first look, netlist identical). Sofar's stale note "Bristlemouth Bus: Molex 2-pin"
now reads "Bristlemouth bus: M3 threaded inserts MP1-MP4" (the Molex was replaced by the inserts, Nick). Symbol `nereus:SM02B-GHS` copied from the UrchinCam schematic into `nereus.kicad_sym`
(name changed from `Connectors:SM02B-GHS`, otherwise verbatim). **Verified:** netlist diff = VBUS_OUT + J5.1, GND +
J5.2, nothing else; ERC 27/508 unchanged; netcheck 51/51; midwire 0; the footprint's pads are 1, 2 and two "MP" mounting
pads (no symbol pin, so no net, as on the UrchinCam).

## S5.c — Pull-ups, ADIN power-up, R10 removed (2026-10-05, branch `sprint/5c-pullups`)

Top-Level sheet (`BM_Mote_1_Master.kicad_sch`), D20–D22:

| Change | Detail |
|---|---|
| **R27** I2C1_SDA → 3V3, **R26** I2C1_SCL → 3V3 | 4.7 kΩ ERJ-2RKF4701X, `Vault:RESC1005X40X25LL05T05`; placed right of J1 (labels + 3V3 symbols #PWR77/#PWR78). Cloned from R3 (same part and symbol), fields set to the mote's R26/R27 (Processor sheet) except SHEET = Top-Level |
| **R43** ADIN_PWR → GND | 100 kΩ RMCF0402FT100K, cloned from R21 (all fields); left of J1 (ADIN_PWR label, GND #PWR79) |
| **R10 removed** | Symbol and its now-unused lib symbol deleted; a wire joins the SW_EN corner to TP19's wire. **Layout:** route TP19 to SW_EN where R10's footprint was; netcheck can't see this (TP19's copper net is now TP19 alone) |

**Verified:** netlist diff = R26/R27/R43 added on exactly those nets, R10 gone, TP19 moved from `Net-(R10-Pad2)` to
SW_EN, nothing else; netcheck 50/50 → **51/51** (R26/R27 restore copper connections), 0 opens/shorts; ERC 27/508,
counts and types unchanged; midwire 0. Tool: `schedit.clone_symbol` (place a copy of a part from another sheet, all
fields kept) + test.

## S5.b — Pi header wired (2026-10-05, branch `sprint/5b-pi-header-wiring`)

Top-Level sheet (`BM_Mote_1_Master.kicad_sch`), pin map in DESIGN.md:

| Change | Detail |
|---|---|
| 11 J1 signal pins | 2.54 mm stub + same-name local label: 3 I2C1_SDA, 5 I2C1_SCL, 19 ADIN_MOSI, 21 ADIN_MISO, 23 ADIN_SCK, 24 ADIN_NSS (right side); 16 ADIN_PWR, 18 ADIN_RST, 22 ADIN_INT, 36 SW_EN, 38 SW_FLAGB (left side, labels read leftward) |
| 17 unused J1 GPIO pins | no-connect flags: 7, 8, 10, 11, 12, 13, 15, 26, 27, 28, 29, 31, 32, 33, 35, 37, 40. Pins 1/17 (Pi 3V3) keep theirs; 5 V and GND unchanged |
| SW_EN | label at the corner of the existing wire from the Load Switch SW_EN sheet pin to R10.1 |
| SW_FLAGB | 2.54 mm stub + label on the Load Switch sheet pin (unconnected on this sheet since import) |

**Verified:** netlist diff = exactly one J1 pin added to each of the 11 nets (ADIN_INT/MISO/MOSI/NSS/PWR/RST/SCK,
I2C1_SDA/SCL, SW_EN, SW_FLAGB), the 11 one-pin `unconnected-(J1-…)` nets gone, nothing else; two nets renamed by the
new top-level labels (`Load Switch/SW_ON` → `SW_EN`, `Load Switch/SW_FLAGB` → `SW_FLAGB`). ERC 74/508 → 27/508
(−29 pin_not_connected, −18 label_dangling); netcheck 50/50; midwire 0. Tool: `schedit.add_label` writes 180° labels
right-justified, as KiCad does.

## S4.d — Footprints findable (2026-10-05, branch `sprint/4d-footprints`)

New project library `nereus_Pi_shield_ADIN2111/mote.pretty`, registered in the project
`fp-lib-table` as **`Vault`**: the 43 footprints the schematic uses
(`docs/design-review/vault_footprints.txt`), extracted from the reference mote board
with KiCad 9.0.6's pcbnew (`tools/fpextract.py`; the board is only read). 24 came from
a front-side instance, 19 were flipped from the back. All schematic footprint fields
without a library (117 parts, 118 fields counting U1's two units) now read `Vault:<name>`.
No other field, value or connection changed. **Verified:** `fpextract --verify` 0
problems over every board instance (pad centres compared after placing the library
footprint like each instance, flipped for back-side ones; a mirrored library is caught); netlist identical except the footprint fields;
ERC 74/626 → 74/508 (the 118 footprint-link warnings gone); netcheck 50/50; all 43
load in `kicad-cli fp export svg`.

## S5.a — Payload load switch: U9 → U11 TPS26621, R11 DNP (2026-10-05, branch `sprint/5a-u9-replacement`)

Load Switch sheet (`BM_Mote_1_Load.kicad_sch`), D18:

| Change | Detail |
|---|---|
| U9 FPF2700MX removed | Obsolete (Digi-Key) |
| **U11 TPS26621DRCR** added at (226.06, 149.68) | New project symbol `nereus:TPS26621DRCR` (new `nereus.kicad_sym` + sym-lib-table entry); stock footprint `Package_SON:Texas_DRC0010J`; LCSC C1848341. Pins placed on U9's old wire ends: IN/ILIM/SHDN/RTN left, OUT/dVdT/FLT/OVP right, GND/EP down to the GND rail |
| R34 | 374 kΩ → **9.09 kΩ RC0402FR-079K09L** (0.73 A); Value and PART NUMBER fields both updated |
| **R41** 1 MΩ (stock `Device:R`, 0402; Value/PART NUMBER RC0402FR-071ML, RESISTANCE 1MR shown) | IN → UVLO, tapping the VIN riser (split + junction) |
| dVdT | no-connect flag (floating = internal ramp) |
| R32 → **R42**, its 3V3 symbol → GND (#PWR76) | Pull-down instead of pull-up (SHDN active low); **10 kΩ RMCF0402FT10K0** (QE round 1: 100 kΩ had no worst-case margin) |
| R33, TP34, label + hierarchical label SW_PGOOD, #PWR65, 4 wires, 1 junction removed | No PGOOD on TPS26621 |
| Note text | "Ilim (R34 9.09k): typ 0.73A, −6/+4 %, TPS26621 D18" |

Top-Level sheet: **R11 DNP**; SW_PGOOD pin removed from the Load Switch sheet symbol.
**Verified:** kept parts' connections identical; new nets only `Net-(U11-UVLO)` and the
floating dVdT; VBUS + R41.1, U11.1; VBUS_OUT + U11.10; GND + R42.2, U11.3/5/6/11;
SW_ON + R42.1, U11.4; SW_FLAGB + U11.9; ISET + U11.7. ERC 76/629 → 74/626; netcheck
50/50, 0 opens, 0 shorts.

## S4.c — Power budget (2026-10-05, branch `sprint/4c-power-budget`)

No schematic edit. New `docs/design-review/power_budget.md`. `tools/check.sh`: ERC 76/629,
netcheck 53/53, same as S4.b.

## S4.b — Shield powers the Pi through JP1 (2026-10-05, branch `sprint/4b-pi-5v-jumper`)

Top-Level sheet (`BM_Mote_1_Master.kicad_sch`), above J1 (DESIGN D14):

| Added | Detail |
|---|---|
| JP1 `Jumper:SolderJumper_2_Bridged` (KiCad 9.0.6 stock) at (120.65, 40.64) | Not in BOM. Pin 2 → `5V_PI` label; pin 1 → J1 pin 2 (5V, pin 4 stacked) |
| Net `PI_5V` | label on the tap to #FLG03 (PWR_FLAG); J1.2, J1.4, JP1.1 |
| Text note | "JP1 bridged as built … cut … refit a 0R 1210 (CRCW12100000Z0EA)" |
| Footprint `nereus:SolderJumper-2_R1210_Bridged_NetTie` (new `nereus.pretty` + project `fp-lib-table`) | Pads from the mote's R11 (1.2049 × 2.7062 mm at ±1.45065 mm, read from the reference board), 1.0 mm F.Cu bridge, net tie "1, 2", mask opened over the bridge, no paste, excluded from BOM and position files. Loads in kicad-cli (`fp export svg`) |

Tool: `midwire.lib_pins` skipped any library symbol whose name ends in `_<n>_<n>`
(`Raspberry_Pi_2_3`), so J1's pins were invisible to midwire, the island graph and
`bbox_clear`. Fixed and tested; midwire still 0 with J1's 40 pins included.
**Verified:** existing connections identical; `PI_5V` = J1.2, J1.4, JP1.1; `5V_PI`
gains JP1.2; ERC −2 errors (J1 pin 2), warnings unchanged. netcheck 53/53.

## S4.a — 5 V converter for the Pi (2026-10-05, branch `sprint/4-5v-converter`)

Power sheet (`BM_Mote_1_Power.kicad_sch`): the U5 block copied 76.2 mm down with
`tools/schedit.py copy_block` (new refs, renamed labels, fresh uuids), then values
set (DESIGN D13). Top-Level sheet: new sheet pin and test point.

| Added | Copy of | Value / change |
|---|---|---|
| U10 | U5 | LMR51430YDDCR (same) |
| L6 | L3 | PA5432.822NLT 8.2 µH (same) |
| R37, **R38** | R21, R23 | 100 kΩ (same); **13.7 kΩ RC0402FR-0713K7L** (was 22.1 kΩ) → 4.98 V |
| R39, R40 | R20, R22 | 1.82 MΩ / 200 kΩ enable divider (same) |
| C53, C54, C55 | C28, C29, C30 | bootstrap 100 nF 25 V; input 100 nF 100 V, 2.2 µF 50 V (same) |
| **C56, C57** | C31 | **22 µF 16 V X5R 0805 GRM21BR61C226ME44L** (was 22 µF 6.3 V 0603); C57 is an extra one; stock KiCad footprint `C_0805_2012Metric` |
| **C58** | C33 | **4.7 µF 10 V X5R 0402 GRM155R61A475MEAAD** (was 6.3 V); `C_0402_1005Metric` |
| #PWR68–#PWR75 | GND symbols | for the copied parts |
| Labels | `3V3_Buck_Input/SW/UVLO/FB` | → `5V_*`; VBUS hierarchical label reused |
| Hierarchical label `5V_PI` + sheet pin | `3V3` | Power Regulators sheet pin at (353.06, 198.12) on the Top-Level sheet |
| TP38 | TP20 | test point on `5V_PI`, with a `5V_PI` label for S4.b |

After QE round 1: C58 and its GND symbol sit one grid (2.54 mm) right of the first
placement, at x = 254, with its 10 V rating shown; stale hidden 0603 size fields
removed from C56/C57 (`set_properties` had skipped values containing `\"`).

Also: TP23/TP24 and their GND symbols (#PWR01, #PWR03) moved 7.62 mm down on the
Top-Level sheet to clear the new wire (placement only, same connections); sheet
title now "Buck Converters - 3V3, 1V8, 5V". **Verified:** every existing part's
pin-to-net grouping identical; new nets exactly `5V_PI` (C56.2, C57.2, C58.1,
L6.2, R37.1, TP38.1), `5V_Buck_SW`, `5V_FB`, `5V_UVLO`, `Net-(U10-CB)`; VBUS and
GND gain only the new parts. netcheck 53/53.

## S3 — Power path kept as Sofar's (2026-10-05, branch `sprint/3-power-path`)

No schematic edit. Nick decided this board keeps the mote's power path unchanged
(DESIGN D12), so L1/L2 (SRF1260-101M) and every other power-path part stay as
imported. `tools/check.sh`: ERC 76/562, netcheck 53/53, same as S2.

## S2 — Mezzanine (P1) → Pi header (2026-10-05, branch `sprint/2-pi-header`)

All edits on the Top-Level sheet (`BM_Mote_1_Master.kicad_sch`), made with `tools/schedit.py`.

### S2.1 Mezzanine deleted

| Removed | Items |
|---|---|
| Parts | P1 (DF17 30-pin mezzanine, 2 units), R9 (0 Ω, MZ_ADC_EXTRA → R10), TP4, 6, 9, 10, 11, 12, 14, 15, 16, 17, 18, 33 |
| Labels | BM_INT, BOOT, I2C_MUX_RST, IOEXP_INT, LPUART1_RX, LPUART1_TX, MCU_RESET, MZ_ADC_EXTRA, MZ_BM_CS, MZ_BM_MISO, MZ_BM_MOSI-TX3, MZ_BM_SCK-RX3, PAYLOAD_DE_CTS, PAYLOAD_RE_RTS |
| Power symbols that fed only P1 | #PWR04, #PWR07, #PWR11, #PWR13 (GND); #PWR12 (3V3 to the mezzanine) |
| Other | 2 no-connect flags on P1; 69 wires; 12 junctions left with < 3 connections |

Kept: R10 and TP19 (still on SW_ON), the I2C1_* and ADIN_* labels, the VBUS_OUT
wiring to R11/TP36. Wire stubs that ran to P1 were trimmed back to the label
or junction on them. **Verified:** all 277 kept pins have exactly the same
connections before and after; the only nets that disappeared are the 14
mezzanine nets. The netcheck exclusion list is now empty.

### S2.2 Pi header placed

| Added | Detail |
|---|---|
| J1 `Connector:Raspberry_Pi_2_3` at (121.92, 88.9) | Footprint `Connector_PinSocket_2.54mm:PinSocket_2x20_P2.54mm_Vertical`; symbol copied from KiCad 9.0.6's library |
| #PWR66 GND (+ junction) | At J1's stacked GND pins: 6, 9, 14, 20, 25, 30, 34, 39 → GND |
| No-connect flag at (127, 55.88) | J1 pins 1 and 17 (Pi 3V3) stay unconnected, never tied to the shield's 3V3 |
| #FLG01 PWR_FLAG on GND, #PWR67 VBUS + #FLG02 PWR_FLAG | Tells ERC these nets have a source |

J1 pins 2/4 (5V) are left for S4; the 28 GPIO pins for S5.

### S2.3 QE round 1 fixes

- Deleted the stale `MEZZANINE` text box (section header of the old mezzanine area, (115.57–181.61, 175.26)). Netlist and ERC unchanged.
- ERC accounting corrected (see DESIGN.md); new `tools/ercsum.py` builds those tables.

### S2 result

| Check | Before S2 | After S2 |
|---|---|---|
| netcheck | 53/53, 14 parts excluded | **53/53, 0 opens, 0 shorts, 0 excluded** |
| ERC errors / warnings | 65 / 590 | 76 / 562: −27 (12 TPs, 13 mezzanine labels, U5 VIN, U6 GND) / +38 (29 J1 pins, 8 I2C1/SCL/SDA labels now one-pin, J1.2) |
| J1 GND pins on GND | — | 8/8 (netlist) |

## S1 — Fix the Altium import (2026-10-05, branch `sprint/1-import-fix`)

### S1.1 Pins that sat mid-wire, now connected (21 locations)

Altium connects a pin that touches a wire anywhere along it; KiCad only
connects at wire ends, so the import left these pins unconnected. At each
location the wire was split at the pin end and a junction added
(`tools/midwire.py --fix`). Result: netcheck went from 39/53 matched with
14 opens to 53/53 matched with 0 opens and 0 shorts.

| Sheet | Location (mm) | Pins now connected |
|---|---|---|
| ADIN2111 | (124.46, 73.4822) | R1.1 |
| ADIN2111 | (215.9, 228.4222) | C13.1 |
| ADIN2111 | (226.06, 228.4222) | C14.1 |
| Load | (152.4, 134.4422) | C49.1 |
| Load | (261.62, 164.9222) | R33.1, TP34.1 |
| Load | (271.78, 134.4422) | C50.1 |
| Load | (279.4, 172.5422) | TP35.1, R35.1 |
| Load | (292.1, 134.4422) | D3.1 |
| Master | (124.46, 205.74) | TP36.1 |
| Master | (292.1, 119.38) | TP8.1 |
| Master | (304.8, 187.96) | TP22.1 |
| Master | (368.3, 185.42) | TP20.1 |
| Master | (378.46, 190.5) | TP21.1 |
| Master | (472.44, 104.14) | TP3.1 |
| Master | (472.44, 106.68) | TP5.1 |
| Master | (472.44, 121.92) | TP7.1 |
| Master | (472.44, 124.46) | TP13.1 |
| PoDL | (43.18, 63.3222) | D4.1 |
| PoDL | (43.18, 175.0822) | D5.1 |
| PowerMon | (177.8, 149.6822) | R8.2 |
| PowerMon | (177.8, 159.8422) | R8.1 |

**Why not the original junction fix?** `Archive/shield_junction_fix.zip`
marks the same 33 locations (these 21 plus 12 on parts S2 deletes) with
junctions only. It had never been applied to the live project. Tested one
junction at a time in KiCad 9.0.6, each one connects its pin but most also
disconnect a neighbouring pin on the same wire (e.g. the C49.1 junction drops
U9.1 off VBUS). Splitting the wire at the pin connects it with no side effects.

### S1.2 Orphan sheet files deleted

`BM_Mote_1_Processor.kicad_sch` and `BM_Mote_1_USB.kicad_sch` were not
referenced by any sheet or by the project file. Deleting them changed neither
the ERC counts nor the netlist.

### S1.3 Power symbols numbered

All 65 power symbols had the same reference, `#PWR?`, in both the
property and the instance record (the checklist's "65 duplicate references").
They are now `#PWR01`–`#PWR65` in hierarchy order (Master 01–17, Power 18–27,
ADIN2111 28–50, PoDL 51–57, PowerMon 58, Load 59–65). ERC counts and the
netlist are unchanged.

### S1.4 ADIN_VDDIO label — verified, not changed

The plain label `ADIN_VDDIO` on the ADIN2111 sheet sits on the C13/C14 wire,
and the netlist has one `ADIN_VDDIO` net holding U3.A1 (switch output),
U1.18/U1.46, the R1/R3/R5/R6 pull-ups, TP2, C13 and C14, matching the copper.
The checklist's goal (pull-ups powered from ADIN_VDDIO) is met, so the label
was left as it is.

### S1 result

| Check | Before S1 | After S1 |
|---|---|---|
| netcheck (excl. S2 deletions) | 39/53 matched, 14 opens | **53/53, 0 opens, 0 shorts** |
| Pins mid-wire (kept parts) | 21 | **0** |
| ERC errors / warnings | 90 / 578 | 65 / 590 |
| Unnumbered power symbols | 65 | 0 |

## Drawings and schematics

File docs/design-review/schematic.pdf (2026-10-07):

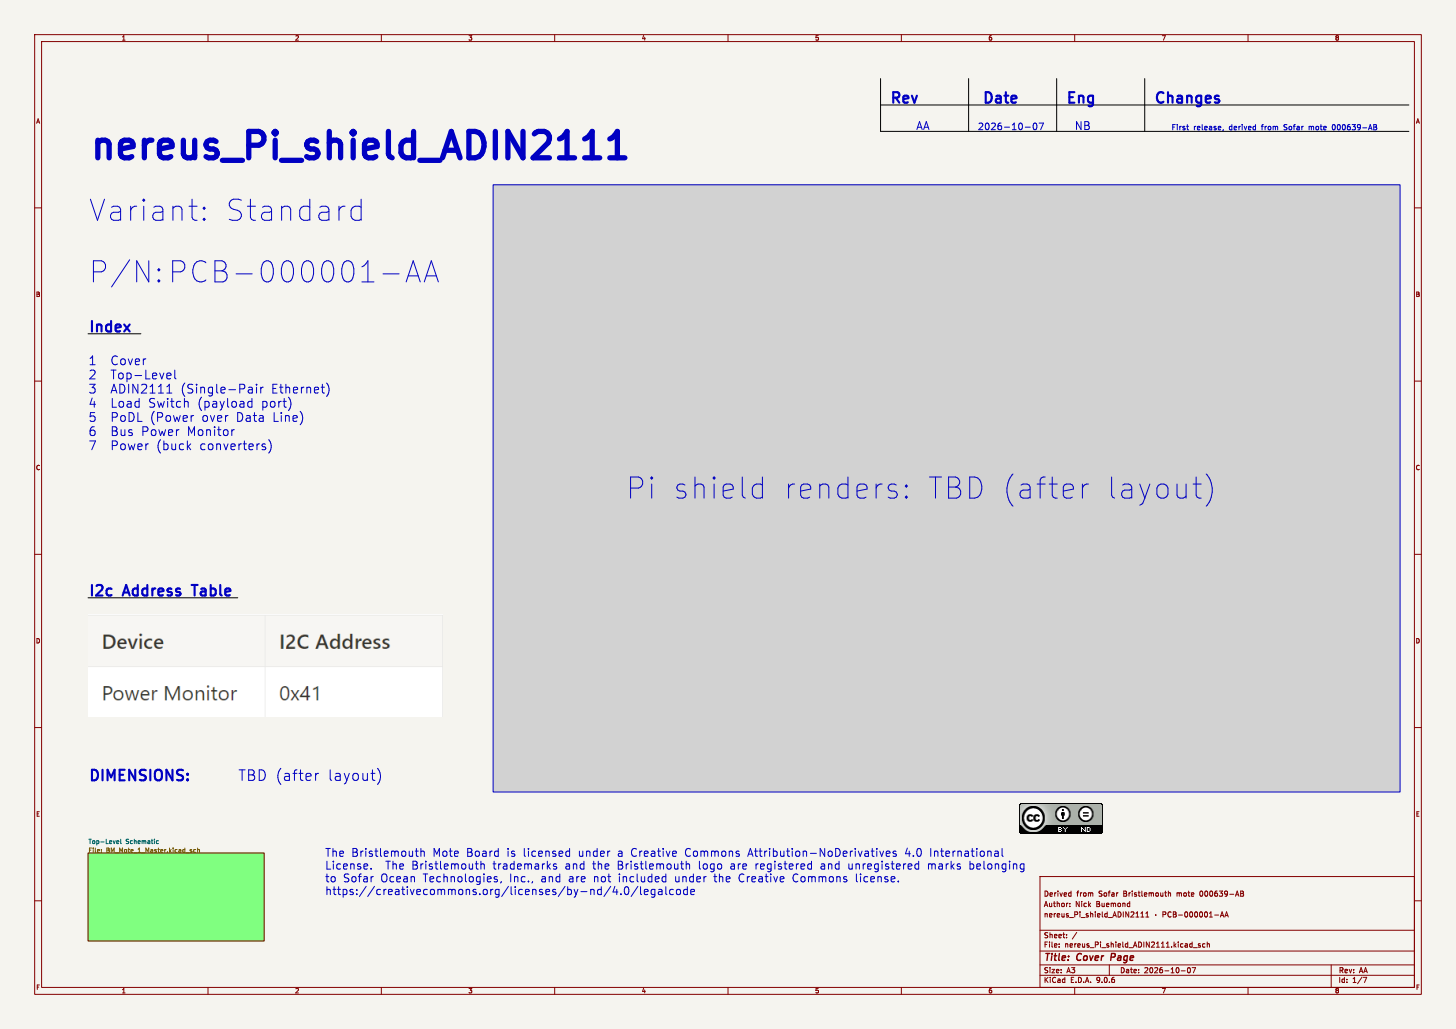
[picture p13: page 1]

First release, derived from Sofar mote 000639-AB Changes

1 Cover
2 Top-Level
4 Load Switch (payload port)
5 PoDL (Power over Data Line)
6 Bus Power Monitor
7 Power (buck converters)

Pi shield renders: TBD (after layout)

https://creativecommons.org/licenses/by-nd/4.0/legalcode

Id: 1/7 Title: Cover Page

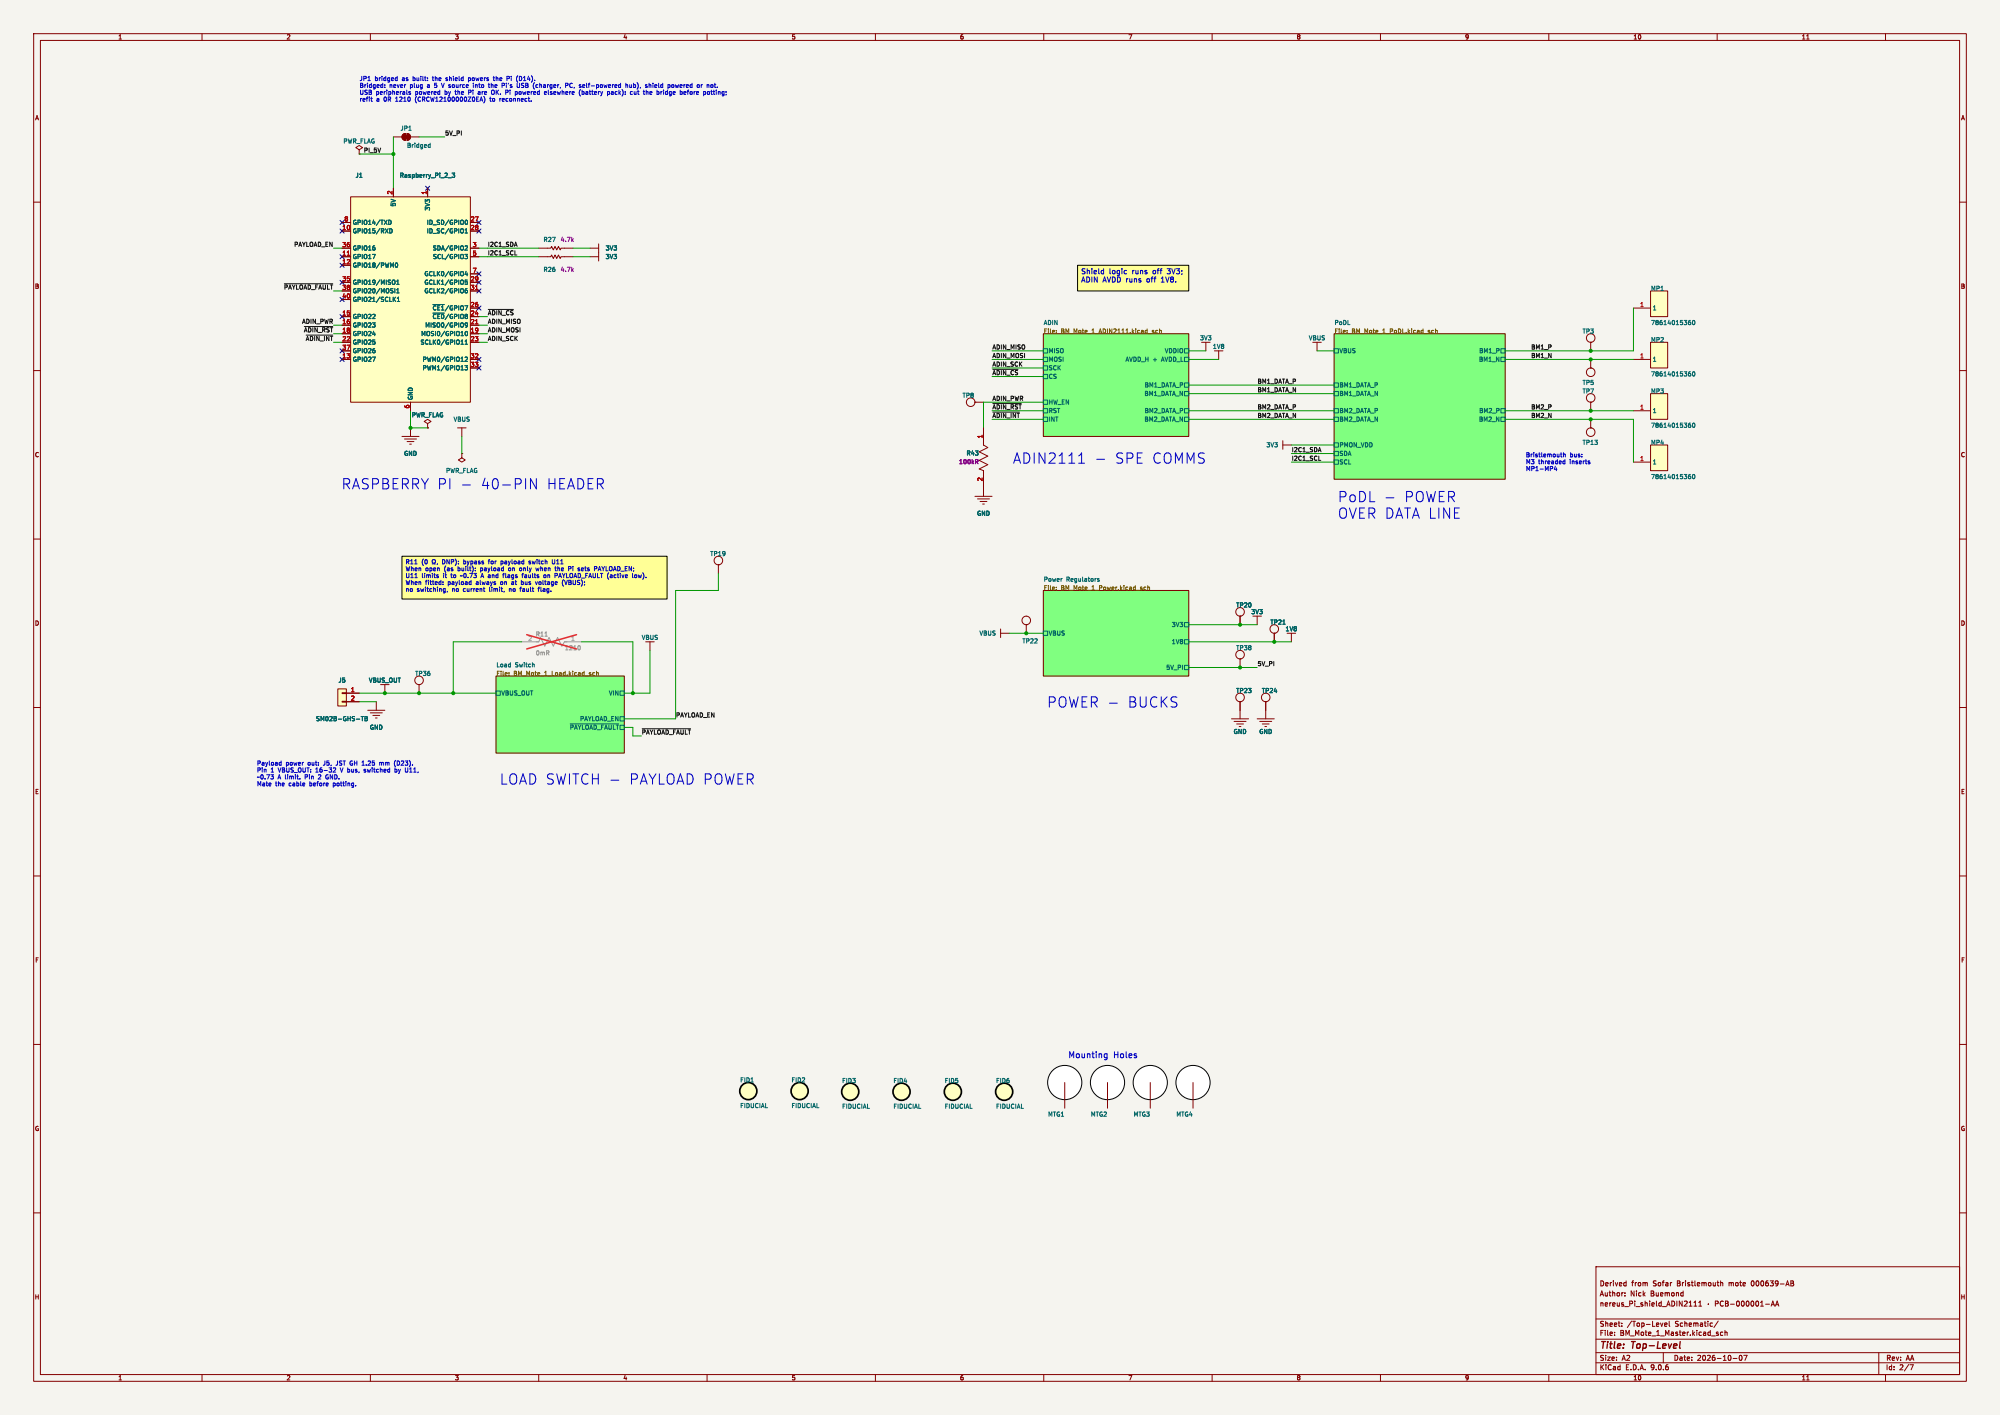
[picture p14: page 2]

JP1 bridged as built: the shield powers the Pi (D14).

Power Regulators File: BM_Mote_1_Power.kicad_sch MISO MOSI SCK CS
AVDD_H + AVDD_L RST

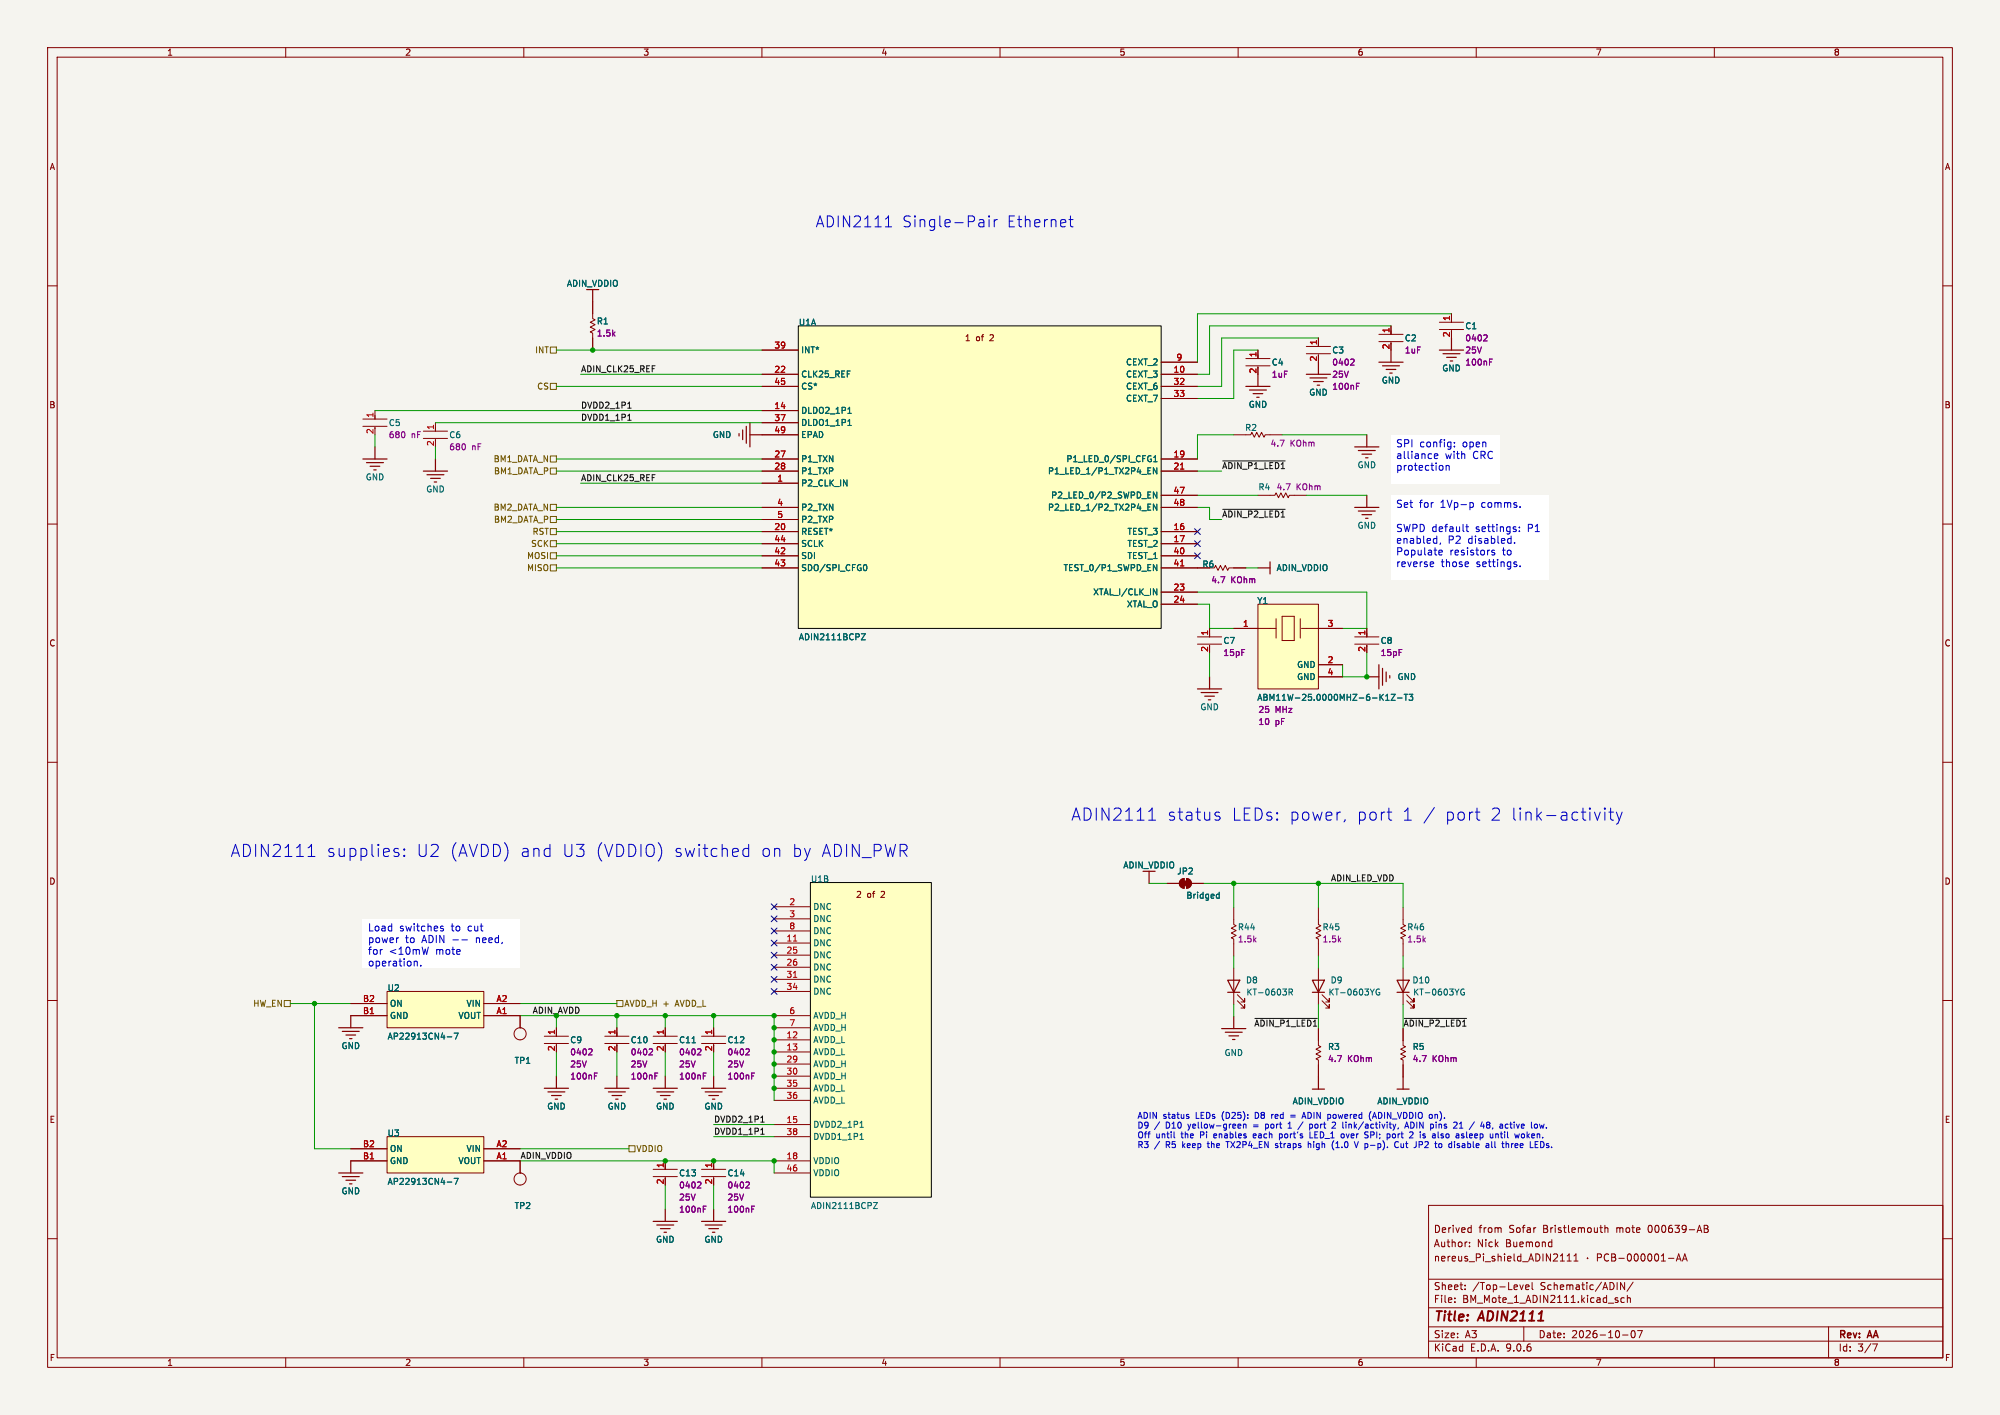
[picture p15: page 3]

ADIN2111 supplies: U2 (AVDD) and U3 (VDDIO) switched on by ADIN_PWR

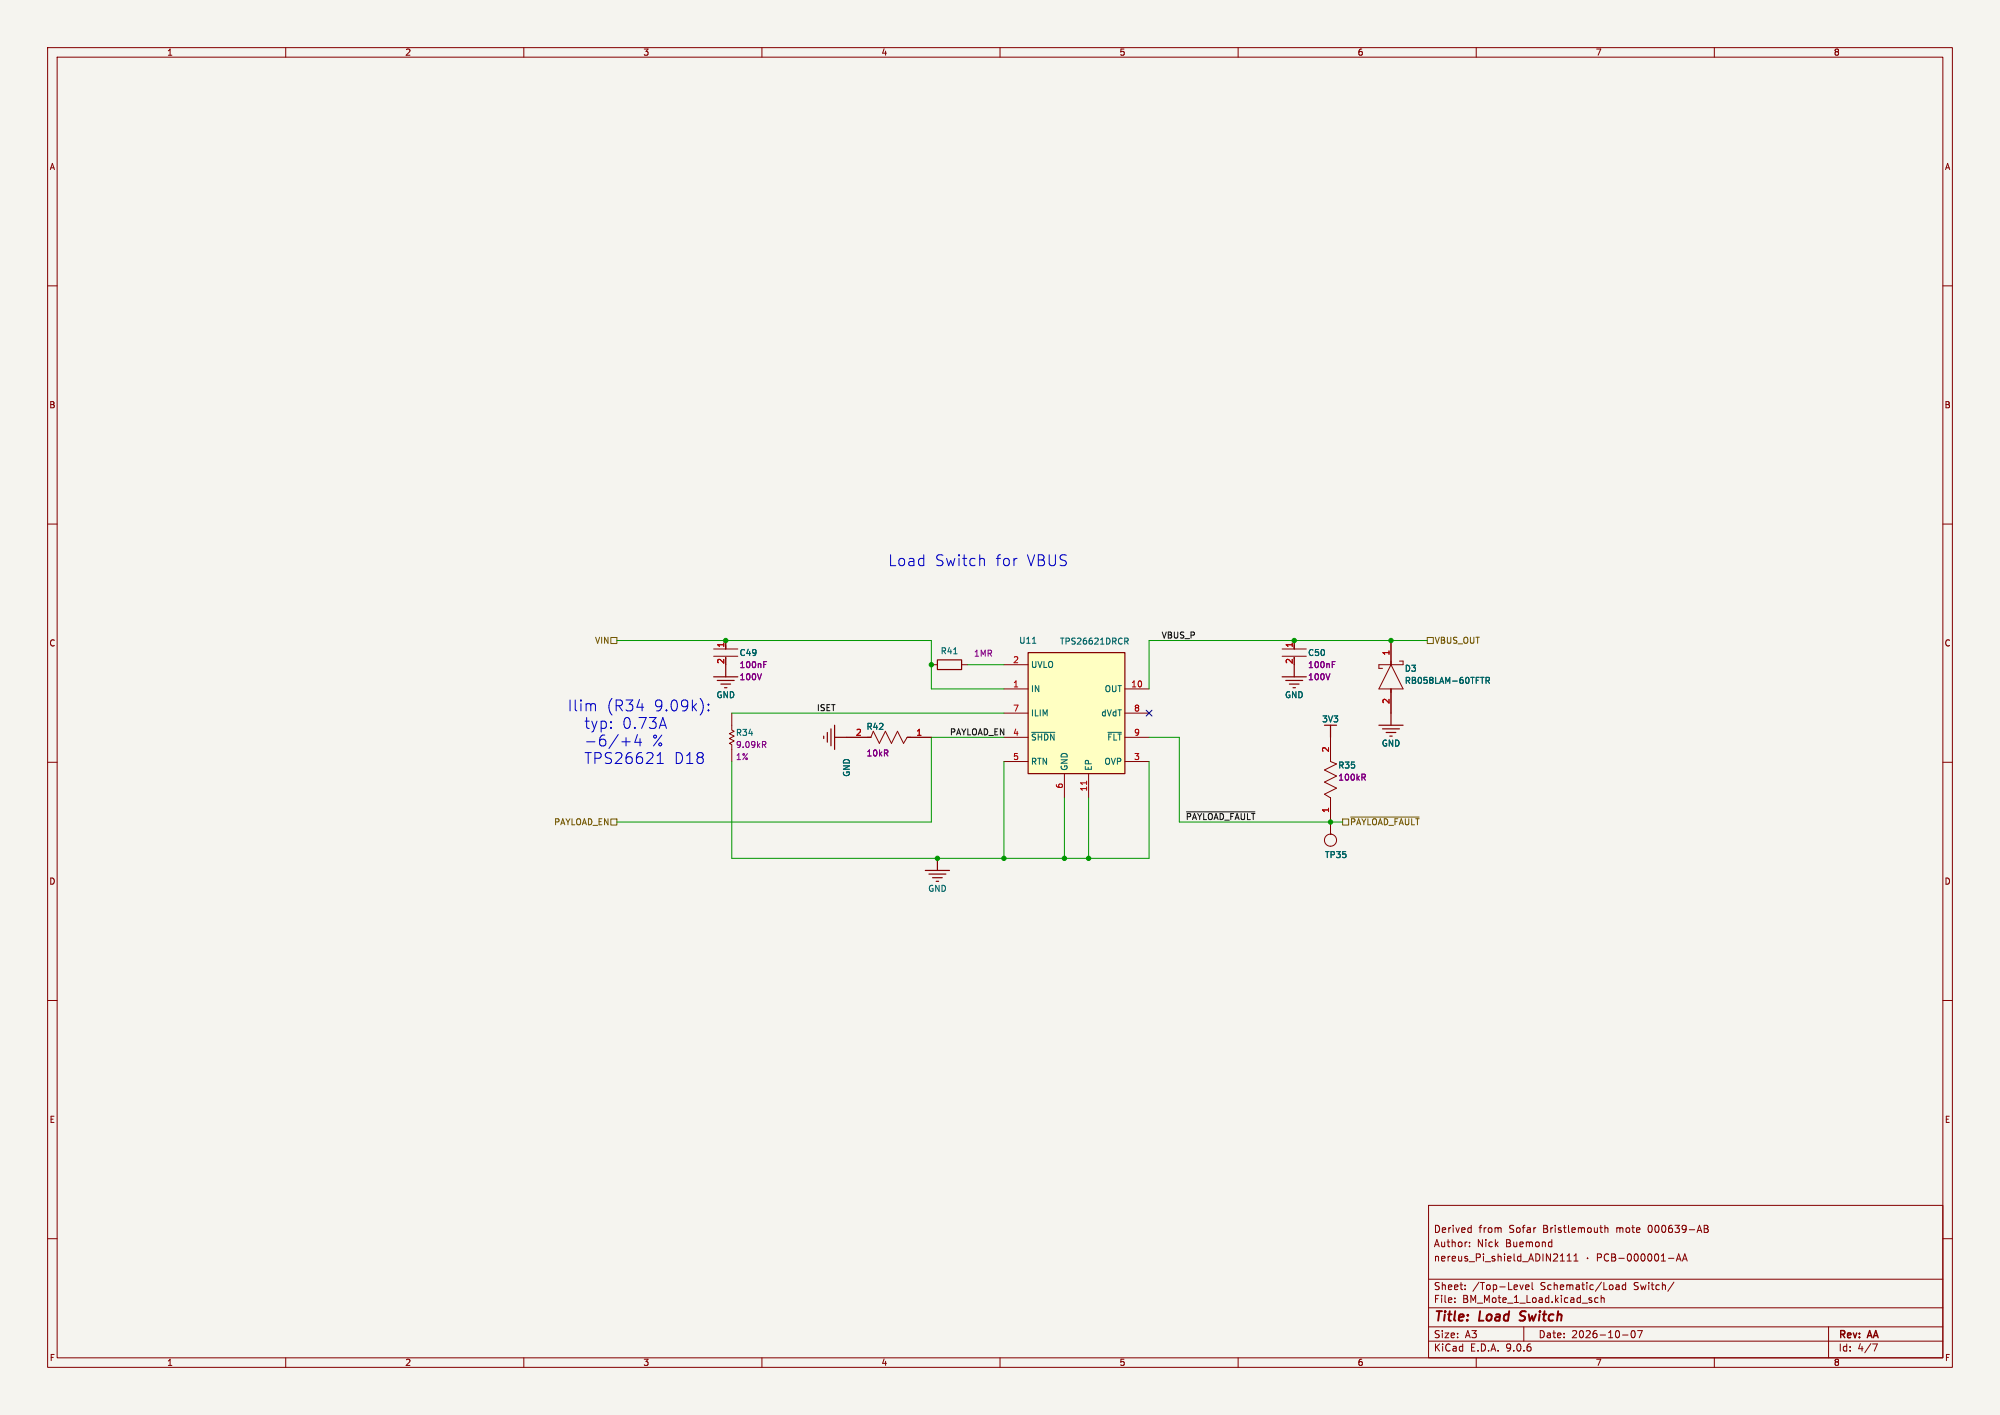
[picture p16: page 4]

Id: 4/7 Title: Load Switch

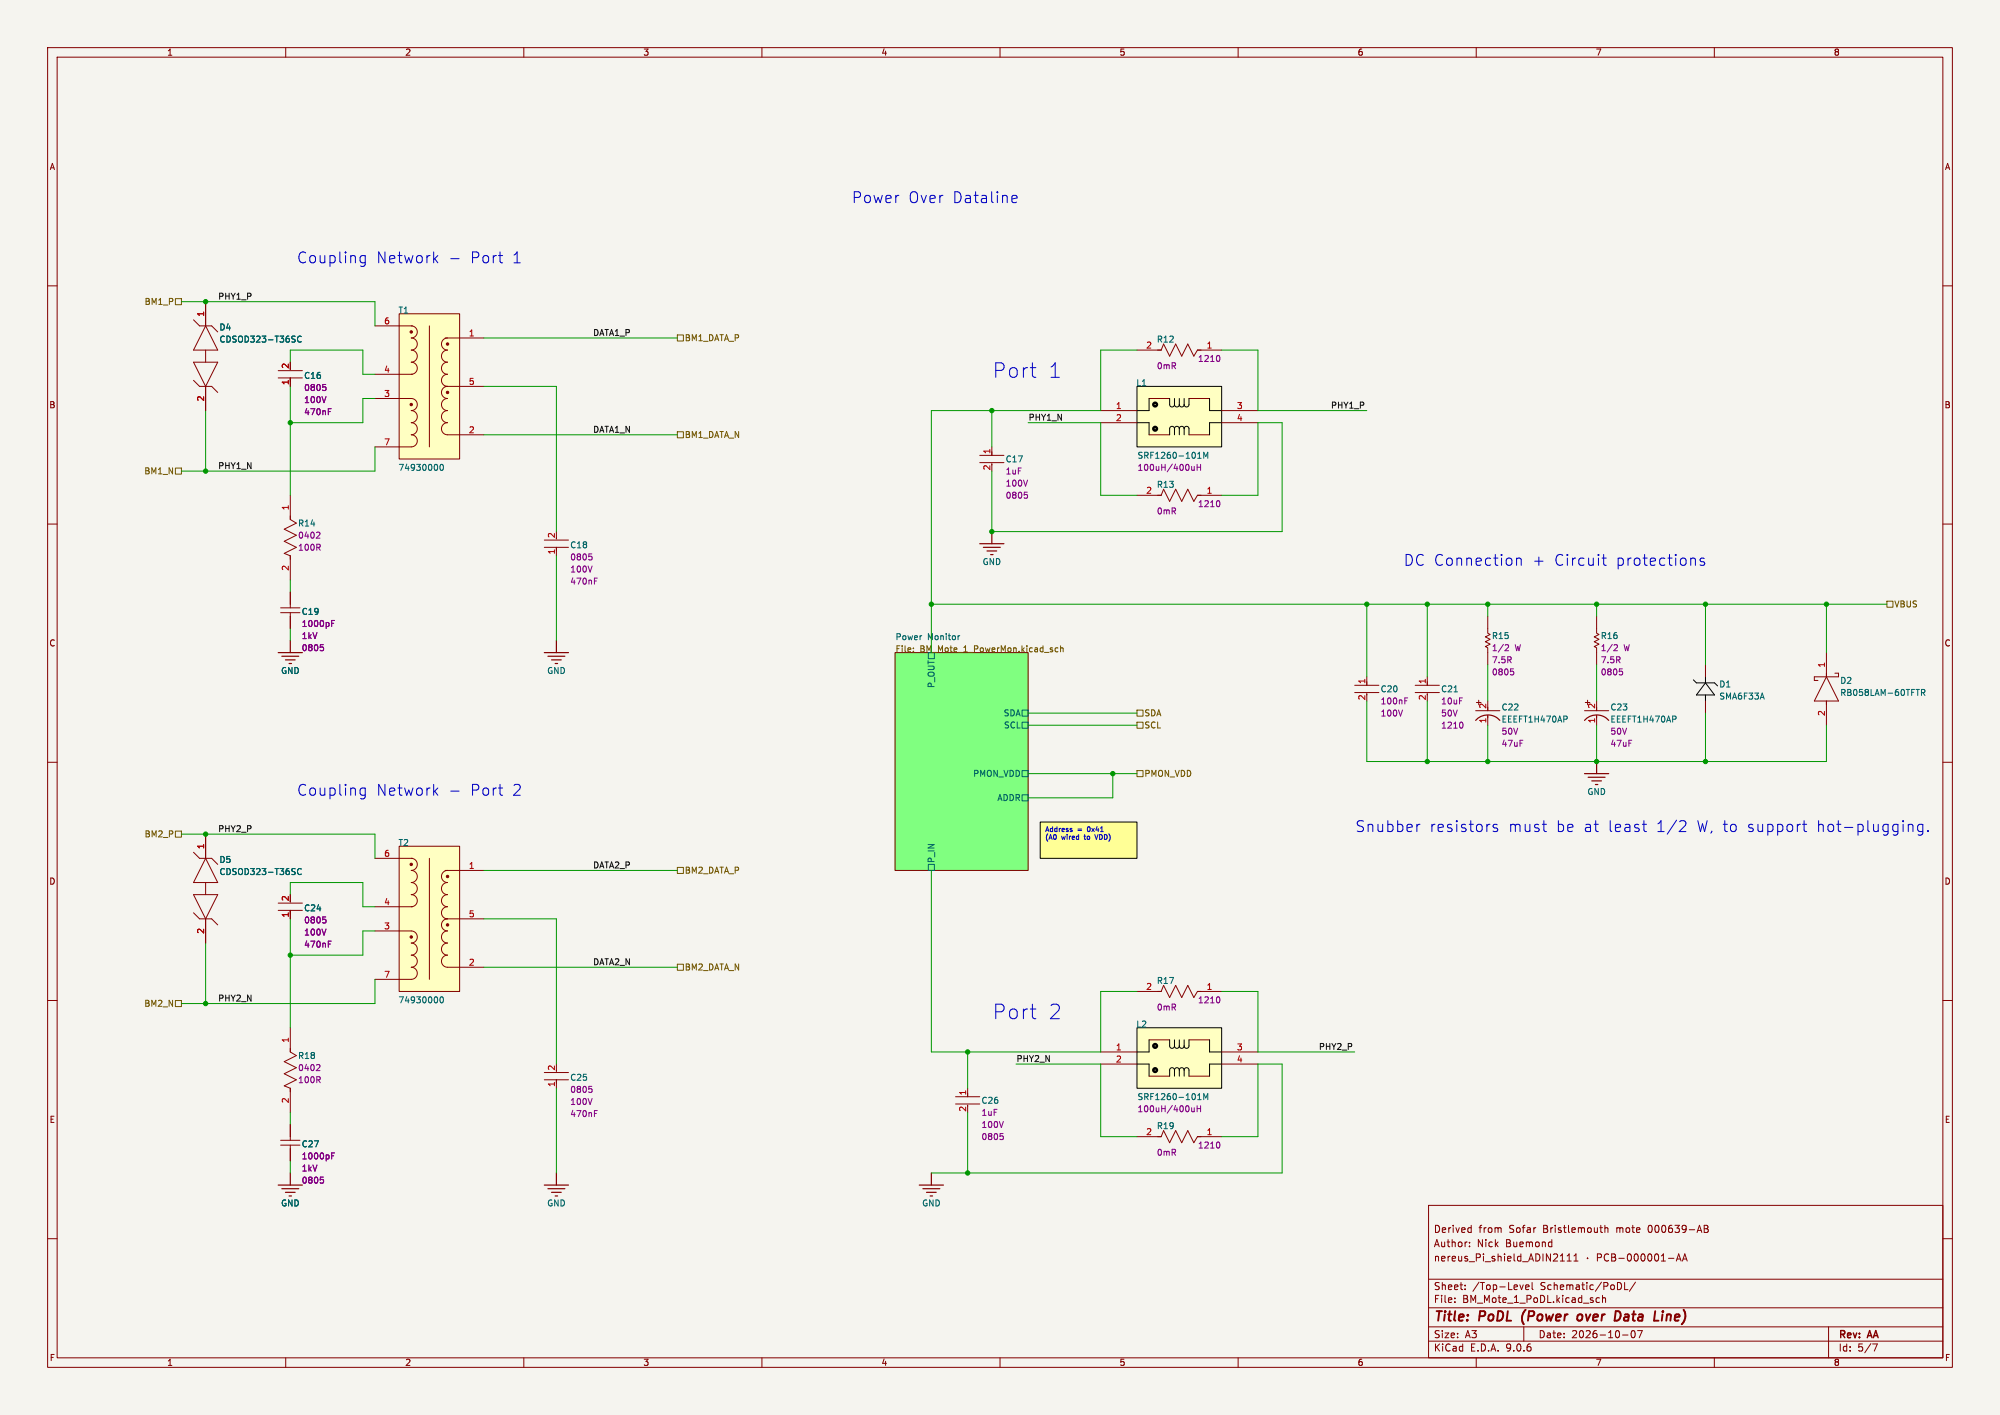
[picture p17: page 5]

Power Monitor File: BM_Mote_1_PowerMon.kicad_sch GND

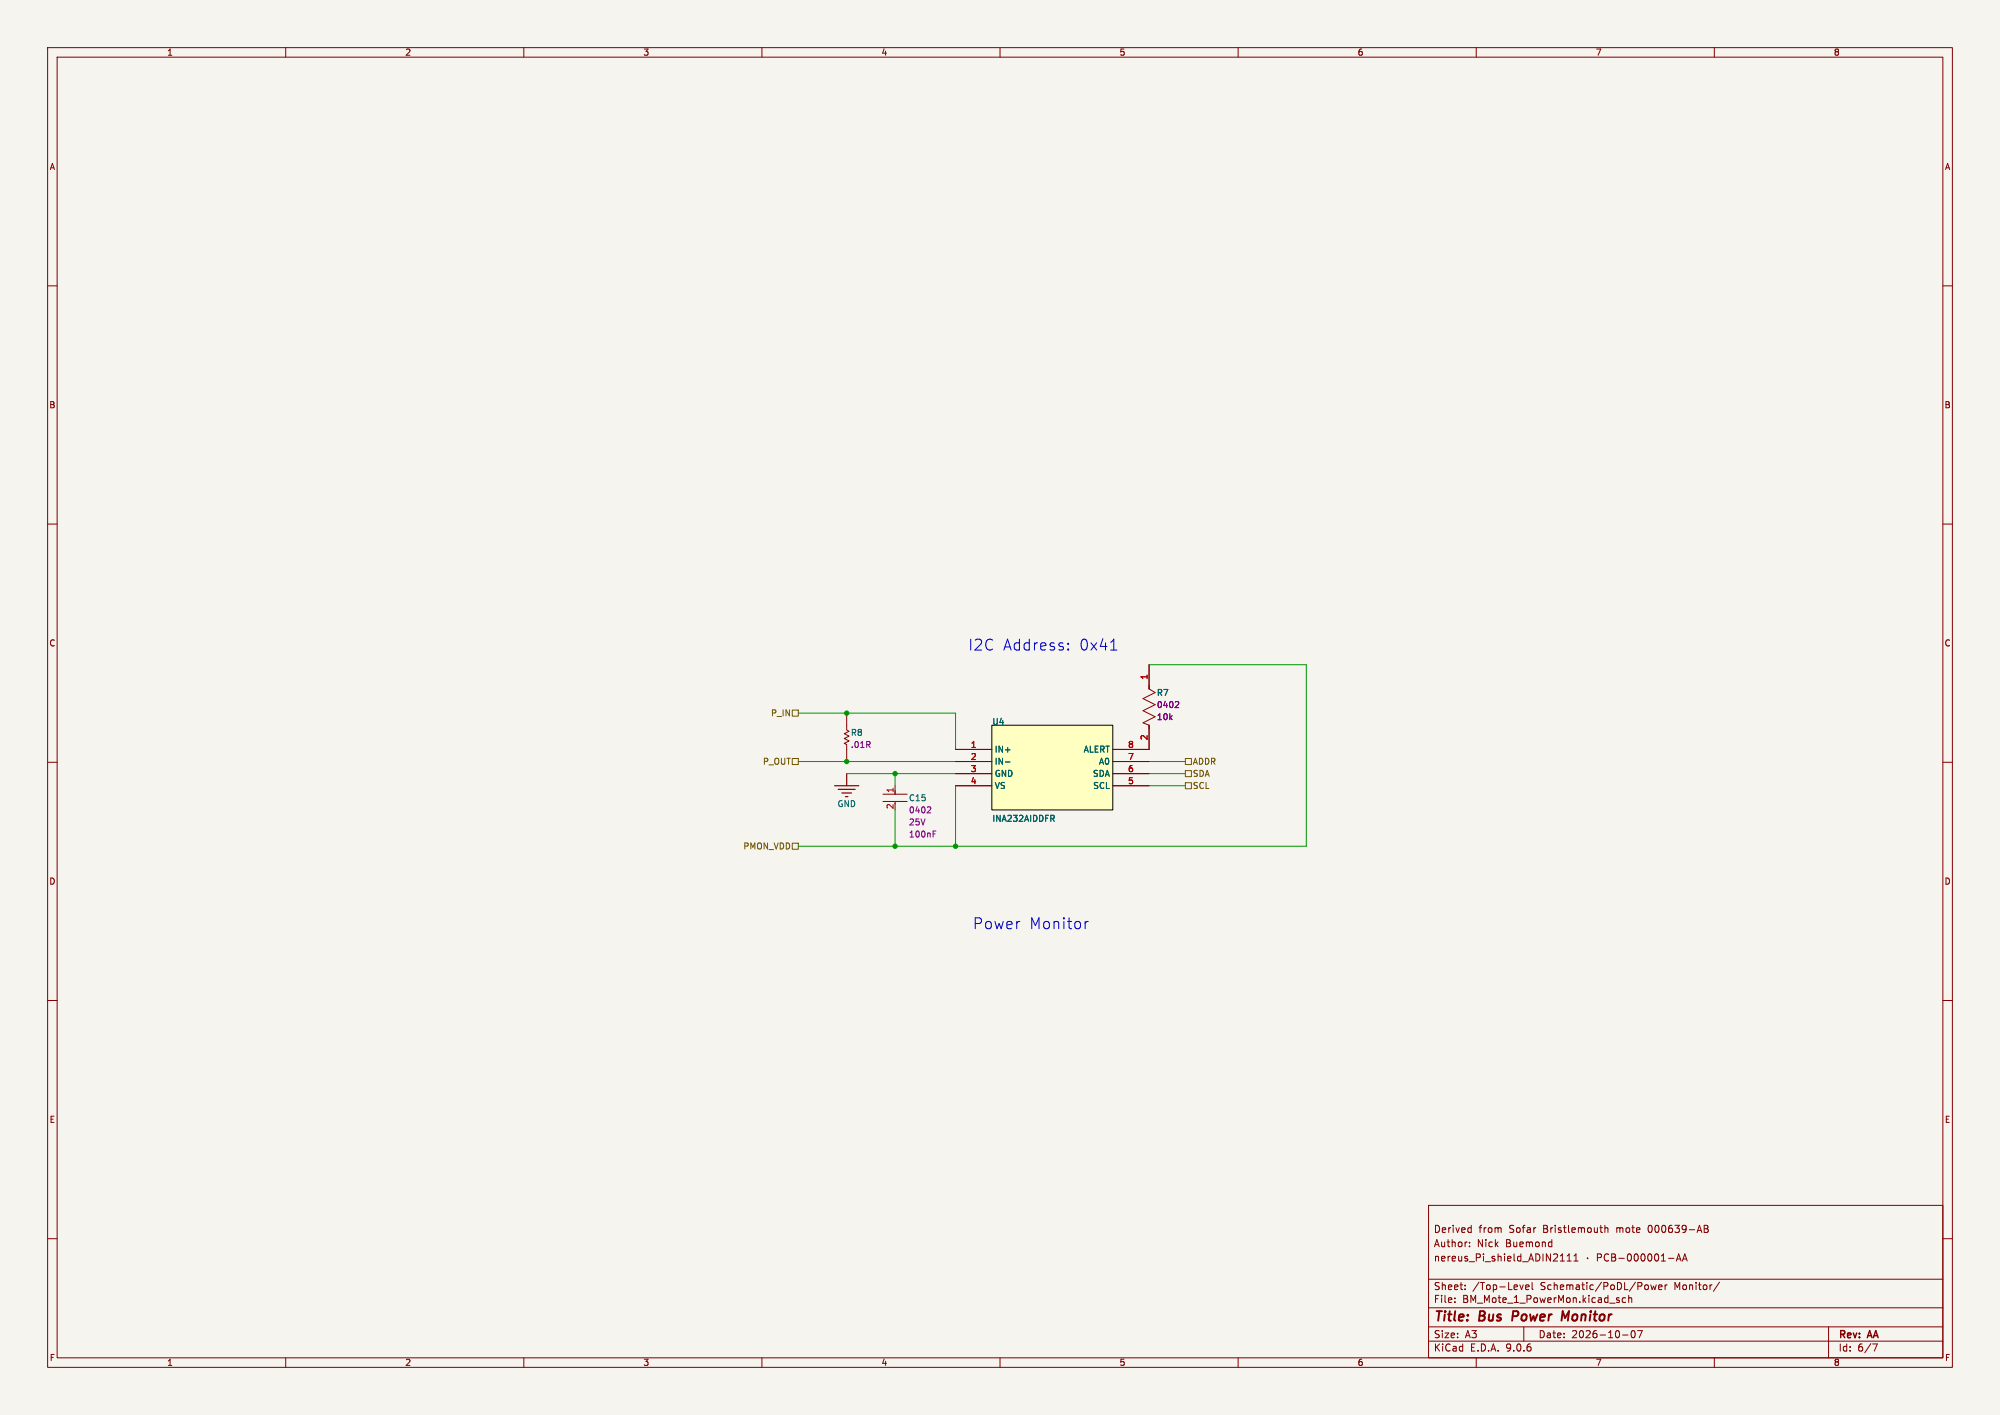
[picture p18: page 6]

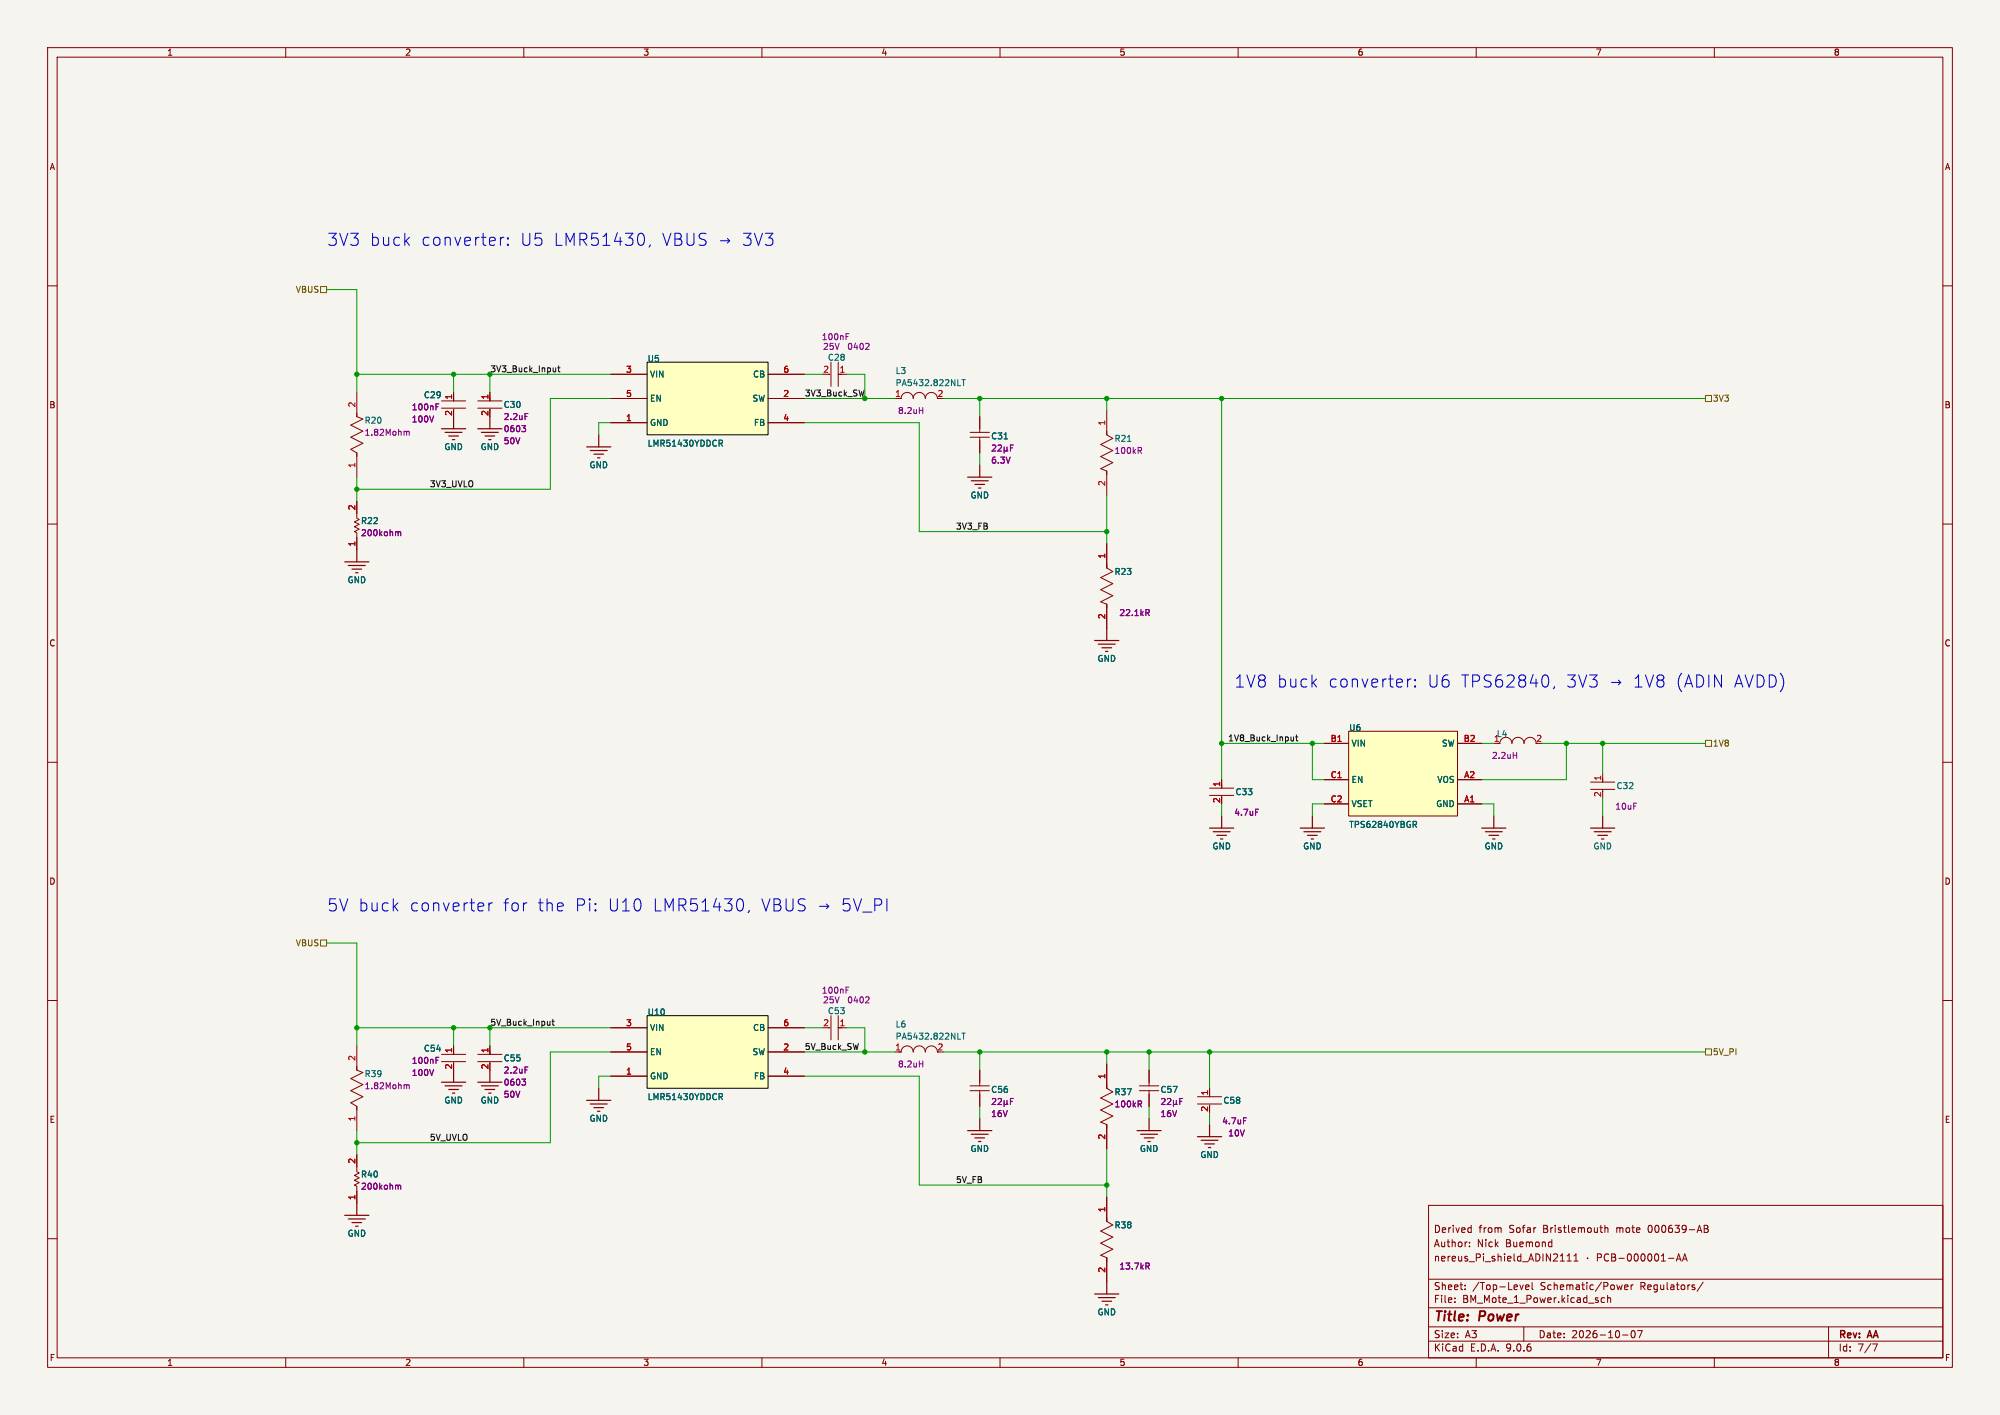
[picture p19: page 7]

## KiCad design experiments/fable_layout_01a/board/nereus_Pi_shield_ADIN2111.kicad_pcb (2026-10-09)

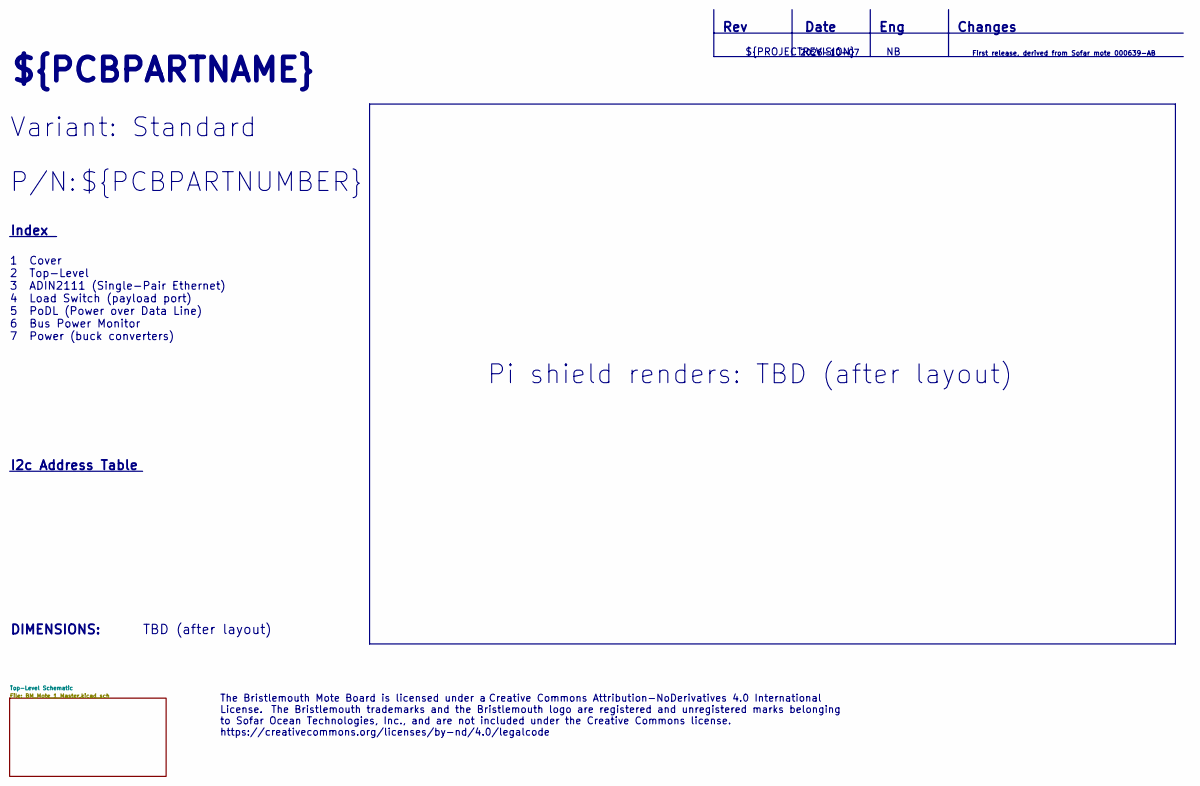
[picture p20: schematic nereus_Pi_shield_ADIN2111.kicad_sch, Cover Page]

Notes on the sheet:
Variant: Standard
Date
${PCBPARTNAME}
Changes
${PCBPARTNUMBER}
First release, derived from Sofar mote 000639-AB
Index
2026-10-07
${PROJECTREVISION}
Rev
I2c Address Table
Eng
TBD (after layout)
P/N:
DIMENSIONS:
The Bristlemouth Mote Board is licensed under a Creative Commons Attribution-NoDerivatives 4.0 International License. The Bristlemouth trademarks and the Bristlemouth logo are registered and unregistered marks belonging to Sofar Ocean Technologies, Inc., and are not included under the Creative Comm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
Pi shield renders: TBD (after layout)
1 Cover 2 Top-Level 3 ADIN2111 (Single-Pair Ethernet) 4 Load Switch (payload port) 5 PoDL (Power over Data Line) 6 Bus Power Monitor 7 Power (buck converters)

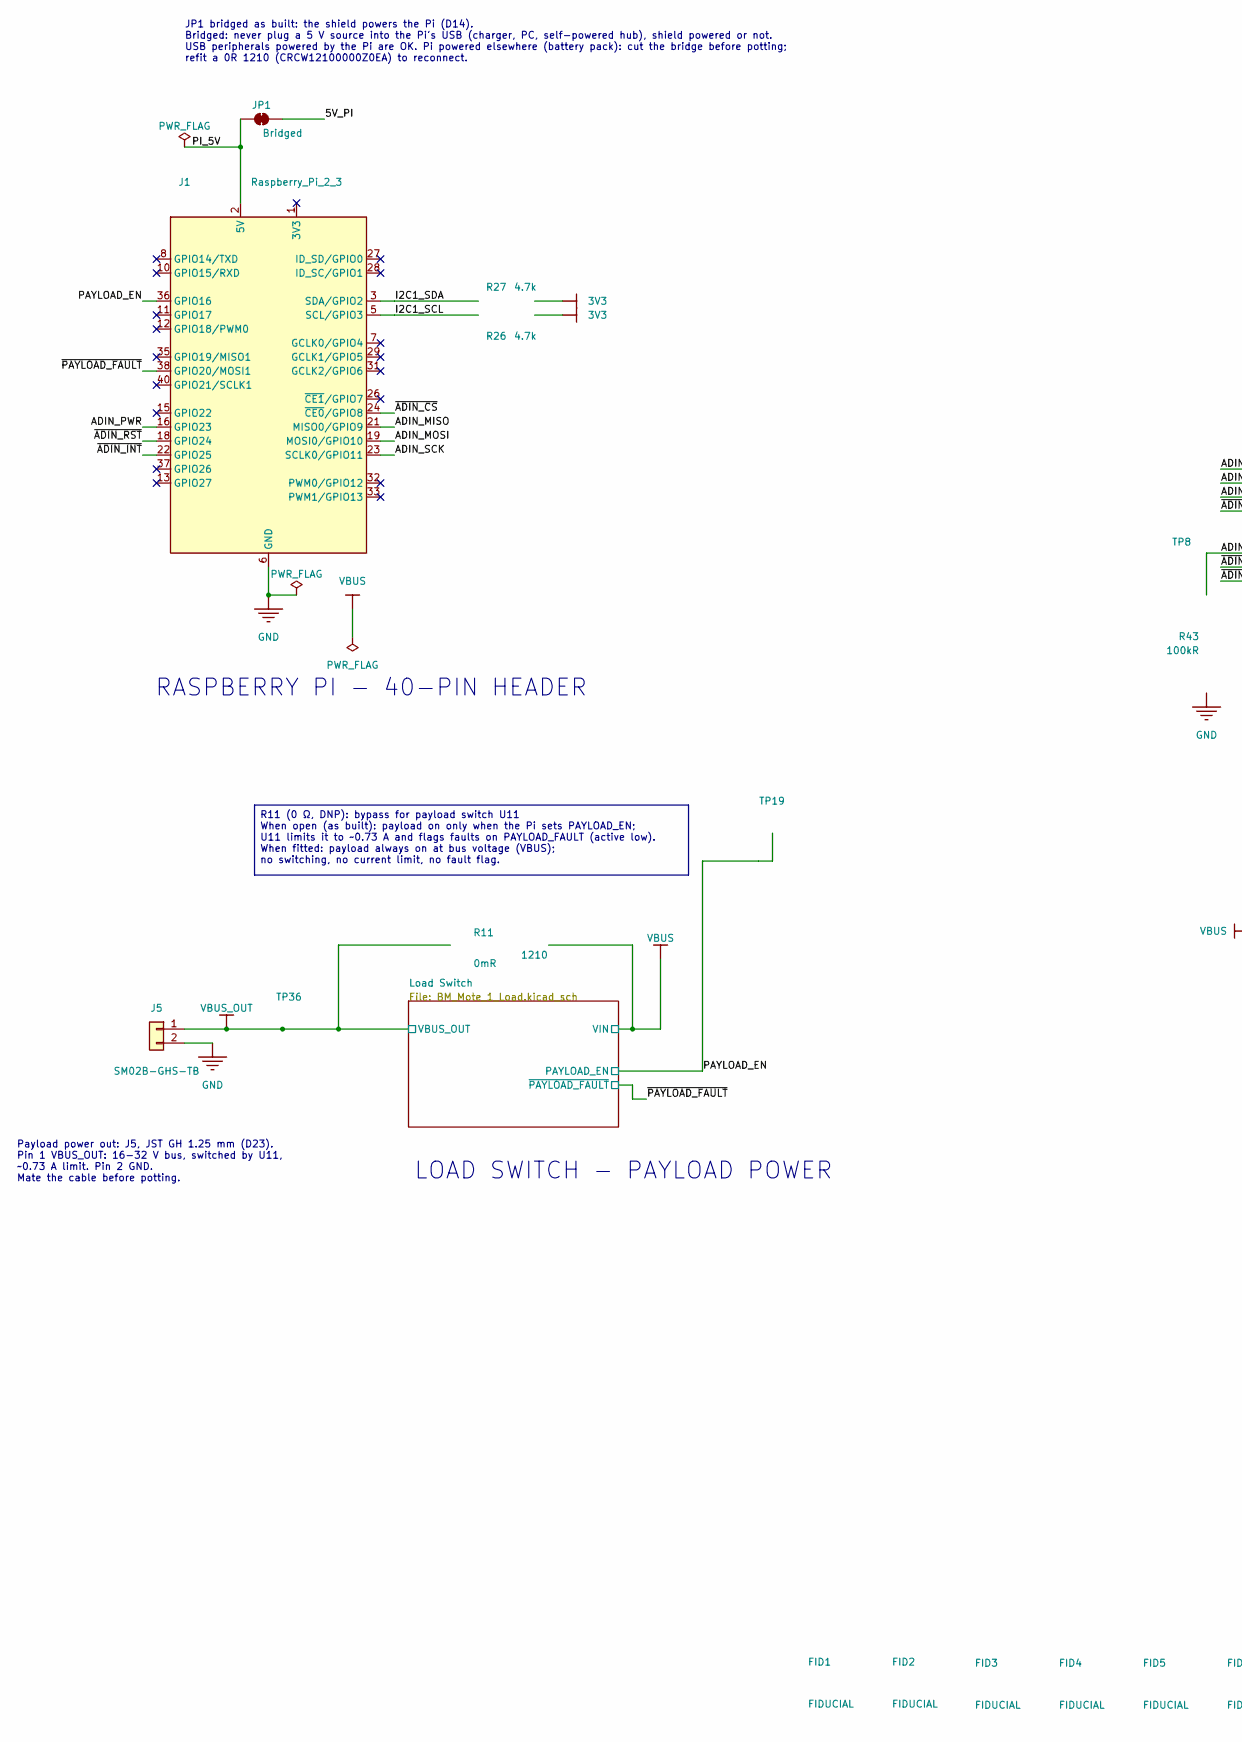
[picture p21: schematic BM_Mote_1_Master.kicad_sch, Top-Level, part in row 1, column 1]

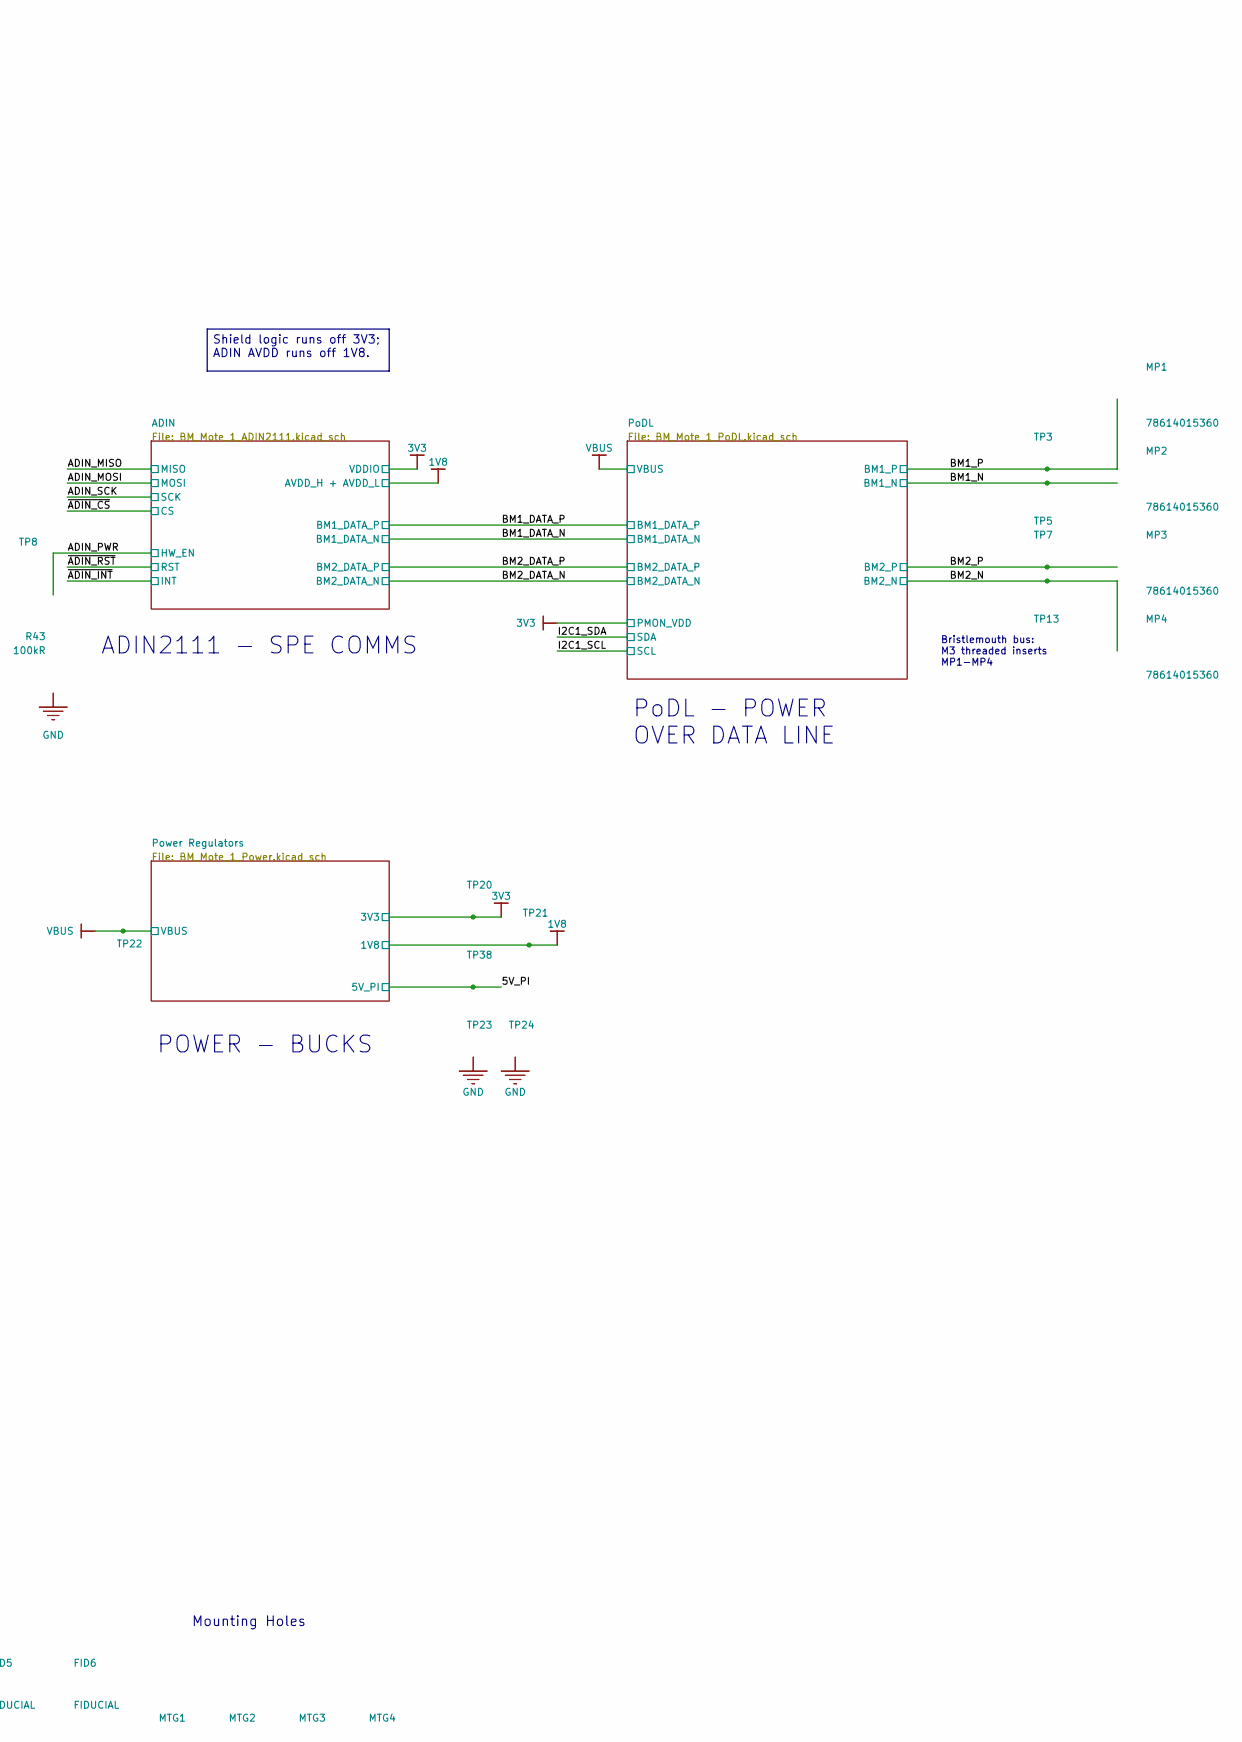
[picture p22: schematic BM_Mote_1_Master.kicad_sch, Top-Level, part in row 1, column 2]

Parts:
FID1, FID2, FID3, FID4, FID5, FID6: FIDUCIAL; FIDUCIAL_075MM
J1: Raspberry_Pi_2_3; PinSocket_2x20_P2.54mm_Vertical
J5: SM02B-GHS-TB; JST_GH_SM02B-GHS-TB_1x02-1MP_P1.25mm_Horizontal; LCSC C189893
JP1: Bridged; SolderJumper-2_R1210_Bridged_NetTie
MP1, MP2, MP3, MP4: 78614015360; 78614015360-Footprint-2; MANUFACTURER PART NUMBER 78614015360
MTG1, MTG2, MTG3, MTG4: Hole_M3
R11: CRCW12100000Z0EA; FP-CRCW1210-e3-IPC_B; POWER RATING 500mW; VOLTAGE RATING 200V; not fitted
R26, R27: ERJ-2RKF4701X; RESC1005X40X25LL05T05; TOLERANCE 1%; VOLTAGE RATING 50 V; PARTNUMBER ERJ-2RKF4701X
R43: RMCF0402FT100K; FP-RMCF0402-IPC_C; TOLERANCE 1%; POWER RATING 62.5mW
TP3, TP5, TP7, TP8, TP13, TP19, TP20, TP21, TP22, TP23, TP24, TP36, TP38: TEST_POINT; PCB_TP_1.5mm; PARTTYPE non BOM

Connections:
1V8: TP21.1; also elsewhere on the board
3V3: R26.2, R27.2, TP20.1; also elsewhere on the board
/Top-Level Schematic/5V_PI: JP1.2 (B), TP38.1; also elsewhere on the board
/Top-Level Schematic/ADIN_MISO: J1.21 (MISO0/GPIO9); also elsewhere on the board
/Top-Level Schematic/ADIN_MOSI: J1.19 (MOSI0/GPIO10); also elsewhere on the board
/Top-Level Schematic/ADIN_PWR: J1.16 (GPIO23), R43.1, TP8.1; also elsewhere on the board
/Top-Level Schematic/ADIN_SCK: J1.23 (SCLK0/GPIO11); also elsewhere on the board
/Top-Level Schematic/BM1_N: TP5.1; also elsewhere on the board
/Top-Level Schematic/BM1_P: TP3.1; also elsewhere on the board
/Top-Level Schematic/BM2_N: TP13.1; also elsewhere on the board
/Top-Level Schematic/BM2_P: TP7.1; also elsewhere on the board
/Top-Level Schematic/I2C1_SCL: J1.5 (SCL/GPIO3), R26.1; also elsewhere on the board
/Top-Level Schematic/I2C1_SDA: J1.3 (SDA/GPIO2), R27.1; also elsewhere on the board
/Top-Level Schematic/PAYLOAD_EN: J1.36 (GPIO16), TP19.1; also elsewhere on the board
/Top-Level Schematic/PI_5V: J1.2 (5V), J1.4 (5V), JP1.1 (A)
/Top-Level Schematic/~ADIN_CS: J1.24 (~CE0/GPIO8); also elsewhere on the board
/Top-Level Schematic/~ADIN_INT: J1.22 (GPIO25); also elsewhere on the board
/Top-Level Schematic/~ADIN_RST: J1.18 (GPIO24); also elsewhere on the board
/Top-Level Schematic/~PAYLOAD_FAULT: J1.38 (GPIO20/MOSI1); also elsewhere on the board
GND: J1.6 (GND), J1.9 (GND), J1.14 (GND), J1.20 (GND), J1.25 (GND), J1.30 (GND), J1.34 (GND), J1.39 (GND), J5.2, R43.2, TP23.1, TP24.1; also elsewhere on the board
VBUS: R11.1, TP22.1; also elsewhere on the board
VBUS_OUT: J5.1, R11.2, TP36.1; also elsewhere on the board

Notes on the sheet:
JP1 bridged as built: the shield powers the Pi (D14). Bridged: never plug a 5 V source into the Pi's USB (charger, PC, self-powered hub), shield powered or not. USB peripherals powered by the Pi are OK. Pi powered elsewhere (battery pack): cut the bridge before potting; refit a 0R 1210 (CRCW1210000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
Payload power out: J5, JST GH 1.25 mm (D23). Pin 1 VBUS_OUT: 16-32 V bus, switched by U11, ~0.73 A limit. Pin 2 GND. Mate the cable before potting.
Shield logic runs off 3V3; ADIN AVDD runs off 1V8.
PoDL - POWER OVER DATA LINE
ADIN2111 - SPE COMMS
Bristlemouth bus: M3 threaded inserts MP1-MP4
R11 (0 Ω, DNP): bypass for payload switch U11 When open (as built): payload on only when the Pi sets PAYLOAD_EN; U11 limits it to ~0.73 A and flags faults on PAYLOAD_FAULT (active low). When fitted: payload always on at bus voltage (VBUS); no switching, no current limit, no fault flag.
Mounting Holes
POWER - BUCKS
RASPBERRY PI - 40-PIN HEADER
LOAD SWITCH - PAYLOAD POWER

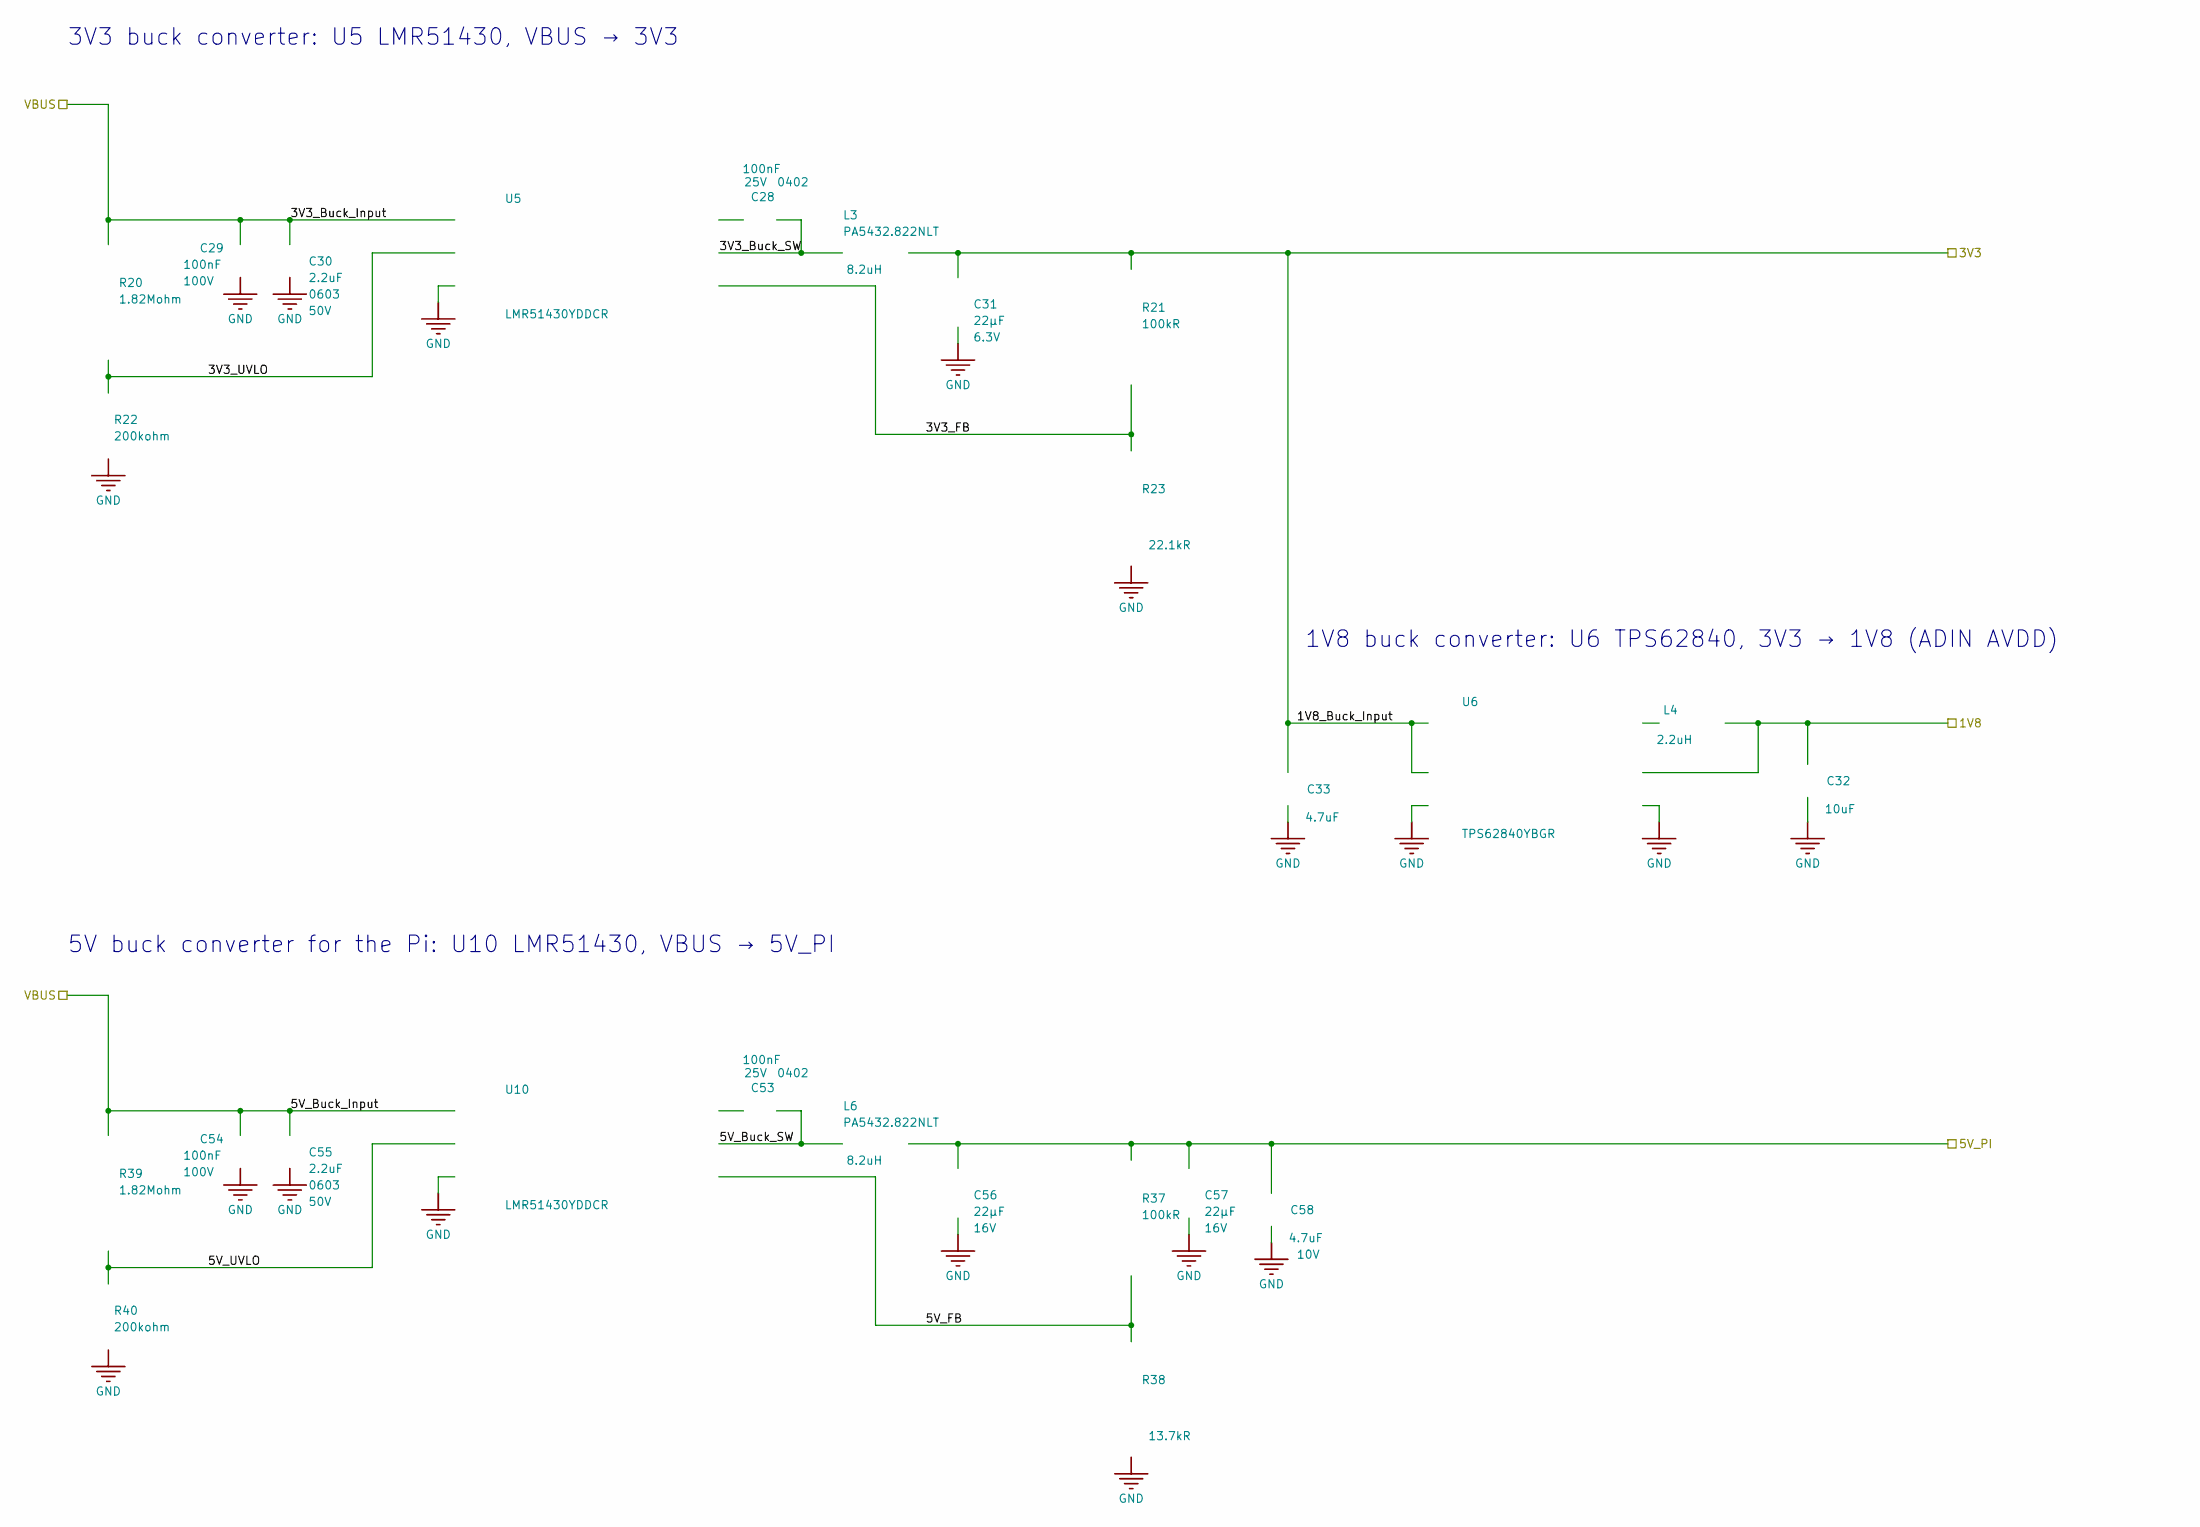
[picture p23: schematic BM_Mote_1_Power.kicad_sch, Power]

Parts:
C28, C53: CL05A104KA5NNNC; FP-CL278-IPC_C; VOLTAGE 25V; VOLTAGE RATING 25V
C29, C54: GRM188R72A104KA35D; FP-GRM188-0_1-e0_2_0_5-IPC_B; VOLTAGE RATING (DC) 100V; VOLTAGE 100V
C30, C55: UMK107BBJ225KA-T; FP-0603-L_1_6_0_2-W_0_8_0-MFG; VOLTAGE RATING 50V; TOLERANCE 10%
C31: C1608X5R0J226M080AC; CAPC1608X100X20ML10; TOLERANCE ±20%; VOLTAGE - RATED 6.3V
C32: GRJ155R60J106ME11D; FP-GRJ155-0_2-MFG; TOLERANCE 20%; VOLTAGE RATING 6.3V
C33: GRM155R60J475ME87D; FP-GRM155-0_15-MFG; TOLERANCE 20%; VOLTAGE 6.3V
C56, C57: GRM21BR61C226ME44L; C_0805_2012Metric; TOLERANCE ±20%; VOLTAGE - RATED 16V
C58: GRM155R61A475MEAAD; C_0402_1005Metric; TOLERANCE 20%; VOLTAGE RATING 10V
L3, L6: PA5432.822NLT; FP-PA5432_472NLT-MFG
L4: DFE201612E-2R2M=P2; FP-DFE201612C-MFG
R20, R39: CRCW04021M82FKED; FP-CRCW0402-e3-MFG; RESISTANCE TOLERANCE 1%; POWER RATING 63mW
R21, R37: RMCF0402FT100K; FP-RMCF0402-IPC_C; TOLERANCE 1%; POWER RATING 62.5mW
R22, R40: RC0402FR-07200KL; RESC1005X40X25LL05T10; PART NUMBER RC0402FR-07200KL
R23: RC0402FR-0722K1L; FP-RC0402-0_4-IPC_B; WORKING VOLTAGE 50V; RESISTANCE TOLERANCE 1%
R38: RC0402FR-0713K7L; FP-RC0402-0_4-IPC_B; WORKING VOLTAGE 50V; RESISTANCE TOLERANCE 1%
U5, U10: LMR51430YDDCR; SOT-23-THIN-6_DDC_TEX; MANUFACTURER_PART_NUMBER LMR51430YDDCR
U6: TPS62840YBGR; FP-YBG0006-MFG

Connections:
1V8: C32.1, L4.2, U6.A2 (VOS); also elsewhere on the board
3V3: C31.2, C33.1, L3.2, R21.1, U6.B1 (VIN), U6.C1 (EN); also elsewhere on the board
/Top-Level Schematic/5V_PI: C56.2, C57.2, C58.1, L6.2, R37.1; also elsewhere on the board
/Top-Level Schematic/Power Regulators/3V3_Buck_SW: C28.1, L3.1, U5.2 (SW)
/Top-Level Schematic/Power Regulators/3V3_FB: R21.2, R23.1, U5.4 (FB)
/Top-Level Schematic/Power Regulators/3V3_UVLO: R20.1, R22.2, U5.5 (EN)
/Top-Level Schematic/Power Regulators/5V_Buck_SW: C53.1, L6.1, U10.2 (SW)
/Top-Level Schematic/Power Regulators/5V_FB: R37.2, R38.1, U10.4 (FB)
/Top-Level Schematic/Power Regulators/5V_UVLO: R39.1, R40.2, U10.5 (EN)
GND: C29.2, C30.2, C31.1, C32.2, C33.2, C54.2, C55.2, C56.1, C57.1, C58.2, R22.1, R23.2, R38.2, R40.1, U5.1 (GND), U6.A1 (GND), U6.C2 (VSET), U10.1 (GND); also elsewhere on the board
unnamed: C28.2, U5.6 (CB)
unnamed: L4.1, U6.B2 (SW)
unnamed: C53.2, U10.6 (CB)
VBUS: C29.1, C30.1, C54.1, C55.1, R20.2, R39.2, U5.3 (VIN), U10.3 (VIN); also elsewhere on the board

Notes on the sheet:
3V3 buck converter: U5 LMR51430, VBUS → 3V3
1V8 buck converter: U6 TPS62840, 3V3 → 1V8 (ADIN AVDD)
5V buck converter for the Pi: U10 LMR51430, VBUS → 5V_PI

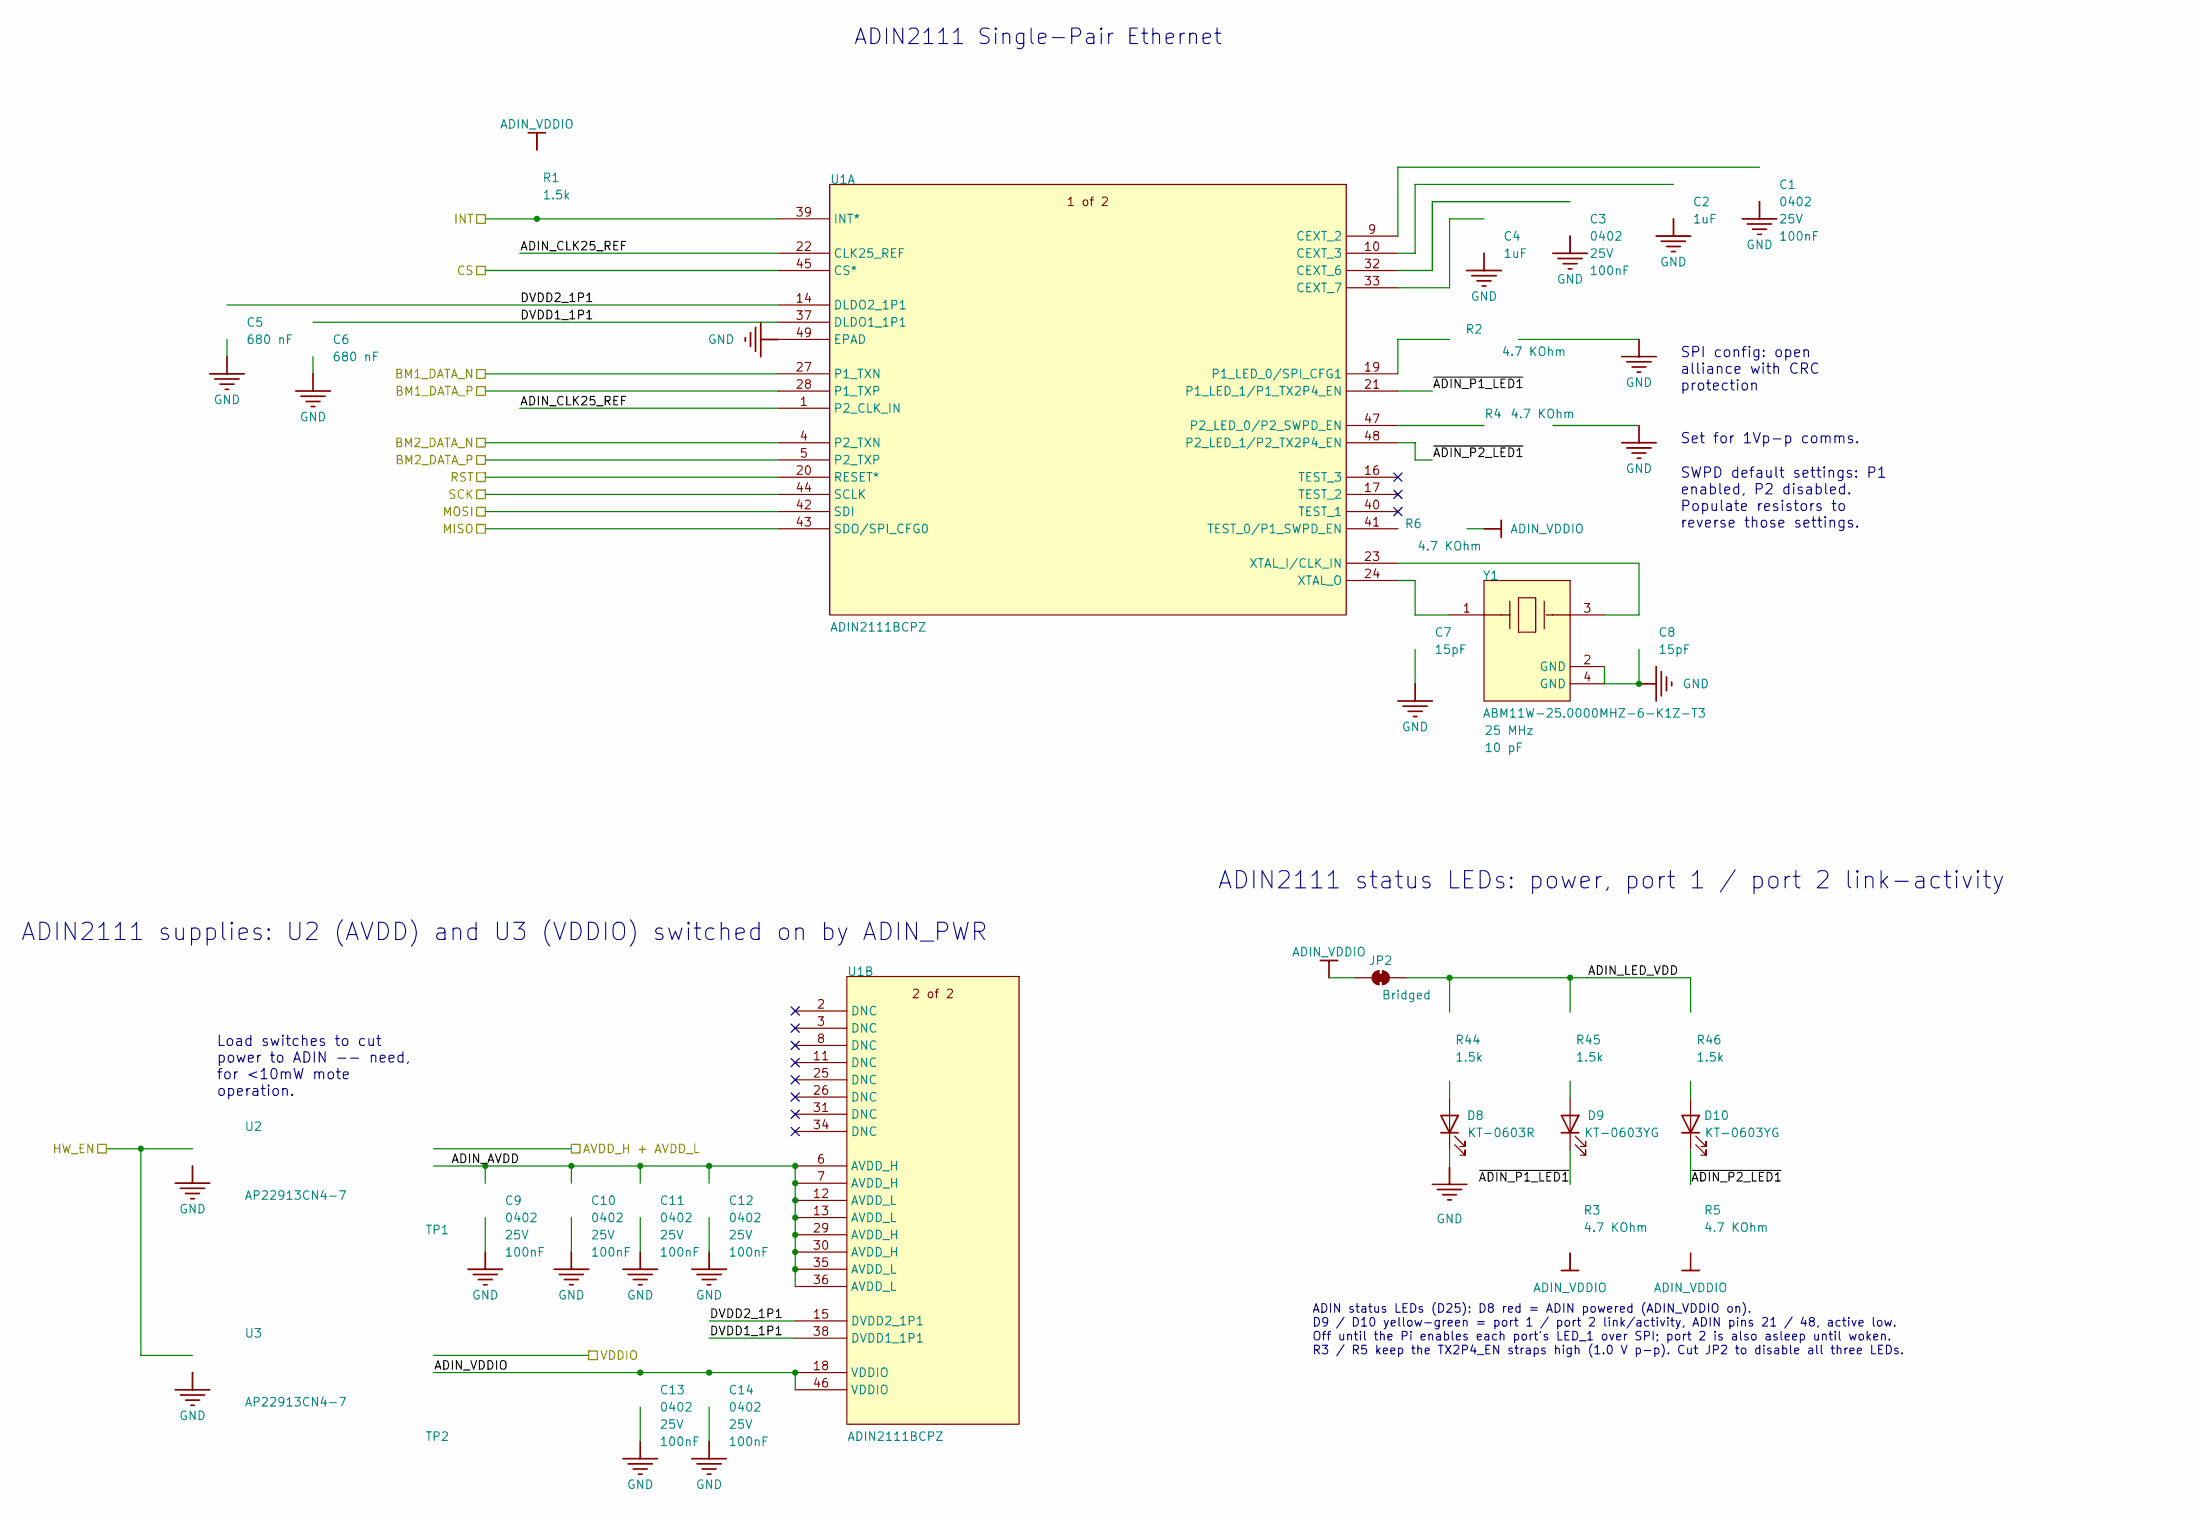
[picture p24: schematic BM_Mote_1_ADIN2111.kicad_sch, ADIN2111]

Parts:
C1, C3, C9, C10, C11, C12, C13, C14: CL05A104KA5NNNC; FP-CL278-IPC_C; VOLTAGE 25V; VOLTAGE RATING 25V
C2, C4: CL05A105KP5NNNC; FP-CL511-IPC_C; TOLERANCE 10%; VOLTAGE RATING 10V
C5, C6: CC0402KRX5R6BB684; FP-CC0402-MFG; TOLERANCE 0.1; VOLTAGE RATING 10 V; MANUFACTURER PART NUMBER CC0402KRX5R6BB684; DIGIKEY DESCRIPTION CAP CER 0.68UF 10V X5R 0402
C7, C8: CC0402JRNPO9BN150; FP-CC0402-0_55-IPC_B; VOLTAGE RATING (DC) 50V; VOLTAGE RATING 50V
D8: KT-0603R; LED_0603_1608Metric; LCSC C2286
D9, D10: KT-0603YG; LED_0603_1608Metric; LCSC C2289
JP2: Bridged; SolderJumper-2_R1210_Bridged_NetTie
R1, R44, R45, R46: RC0402FR-071K5L; RESC1005X40X25ML05T10; PART NUMBER RC0402FR-071K5L
R2, R3, R4, R5, R6: ERJ-2RKF4701X; RESC1005X40X25LL05T05; TOLERANCE 1%; VOLTAGE RATING 50 V; PARTNUMBER ERJ-2RKF4701X
TP1, TP2: TEST_POINT; PCB_TP_1.5mm; PARTTYPE non BOM
U1: ADIN2111BCPZ; ADIN2111BCPZ-Footprint-1
U2, U3: AP22913CN4-7; AP22913CN4-7-Footprint-1
Y1: ABM11W-25.0000MHZ-6-K1Z-T3; FP-ABM11W-MFG

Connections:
1V8: U2.A2 (VIN); also elsewhere on the board
3V3: U3.A2 (VIN); also elsewhere on the board
/Top-Level Schematic/ADIN/ADIN_AVDD: C9.1, C10.1, C11.1, C12.1, TP1.1, U1.6 (AVDD_H), U1.7 (AVDD_H), U1.12 (AVDD_L), U1.13 (AVDD_L), U1.29 (AVDD_H), U1.30 (AVDD_H), U1.35 (AVDD_L), U1.36 (AVDD_L), U2.A1 (VOUT)
/Top-Level Schematic/ADIN/ADIN_CLK25_REF: U1.1 (P2_CLK_IN), U1.22 (CLK25_REF)
/Top-Level Schematic/ADIN/ADIN_LED_VDD: JP2.2 (B), R44.2, R45.2, R46.2
/Top-Level Schematic/ADIN/DVDD1_1P1: C6.1, U1.37 (DLDO1_1P1), U1.38 (DVDD1_1P1)
/Top-Level Schematic/ADIN/DVDD2_1P1: C5.1, U1.14 (DLDO2_1P1), U1.15 (DVDD2_1P1)
/Top-Level Schematic/ADIN/~ADIN_P1_LED1: D9.1 (K), R3.1, U1.21 (P1_LED_1/P1_TX2P4_EN)
/Top-Level Schematic/ADIN/~ADIN_P2_LED1: D10.1 (K), R5.1, U1.48 (P2_LED_1/P2_TX2P4_EN)
/Top-Level Schematic/ADIN_MISO: U1.43 (SDO/SPI_CFG0); also elsewhere on the board
/Top-Level Schematic/ADIN_MOSI: U1.42 (SDI); also elsewhere on the board
/Top-Level Schematic/ADIN_PWR: U2.B2 (ON), U3.B2 (ON); also elsewhere on the board
/Top-Level Schematic/ADIN_SCK: U1.44 (SCLK); also elsewhere on the board
/Top-Level Schematic/BM1_DATA_N: U1.27 (P1_TXN); also elsewhere on the board
/Top-Level Schematic/BM1_DATA_P: U1.28 (P1_TXP); also elsewhere on the board
/Top-Level Schematic/BM2_DATA_N: U1.4 (P2_TXN); also elsewhere on the board
/Top-Level Schematic/BM2_DATA_P: U1.5 (P2_TXP); also elsewhere on the board
/Top-Level Schematic/~ADIN_CS: U1.45 (CS*); also elsewhere on the board
/Top-Level Schematic/~ADIN_INT: R1.1, U1.39 (INT*); also elsewhere on the board
/Top-Level Schematic/~ADIN_RST: U1.20 (RESET*); also elsewhere on the board
ADIN_VDDIO: C13.1, C14.1, JP2.1 (A), R1.2, R3.2, R5.2, R6.2, TP2.1, U1.18 (VDDIO), U1.46 (VDDIO), U3.A1 (VOUT)
GND: C1.2, C2.2, C3.2, C4.2, C5.2, C6.2, C7.2, C8.2, C9.2, C10.2, C11.2, C12.2, C13.2, C14.2, D8.1 (K), R2.2, R4.2, U1.49 (EPAD), U2.B1 (GND), U3.B1 (GND), Y1.2 (GND), Y1.4 (GND); also elsewhere on the board
unnamed: D8.2 (A), R44.1
unnamed: D9.2 (A), R45.1
unnamed: D10.2 (A), R46.1
unnamed: C1.1, U1.9 (CEXT_2)
unnamed: C2.1, U1.10 (CEXT_3)
unnamed: C3.1, U1.32 (CEXT_6)
unnamed: C4.1, U1.33 (CEXT_7)
unnamed: R2.1, U1.19 (P1_LED_0/SPI_CFG1)
unnamed: R4.1, U1.47 (P2_LED_0/P2_SWPD_EN)
unnamed: R6.1, U1.41 (TEST_0/P1_SWPD_EN)
unnamed: C8.1, U1.23 (XTAL_I/CLK_IN), Y1.3
unnamed: C7.1, U1.24 (XTAL_O), Y1.1

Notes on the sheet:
ADIN status LEDs (D25): D8 red = ADIN powered (ADIN_VDDIO on). D9 / D10 yellow-green = port 1 / port 2 link/activity, ADIN pins 21 / 48, active low. Off until the Pi enables each port's LED_1 over SPI; port 2 is also asleep until woken. R3 / R5 keep the TX2P4_EN straps high (1.0 V p-p). Cut JP2 to 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
Set for 1Vp-p comms.
Load switches to cut power to ADIN -- need, for <10mW mote operation.
ADIN2111 Single-Pair Ethernet
SWPD default settings: P1 enabled, P2 disabled. Populate resistors to reverse those settings.
SPI config: open alliance with CRC protection
ADIN2111 supplies: U2 (AVDD) and U3 (VDDIO) switched on by ADIN_PWR
ADIN2111 status LEDs: power, port 1 / port 2 link-activity

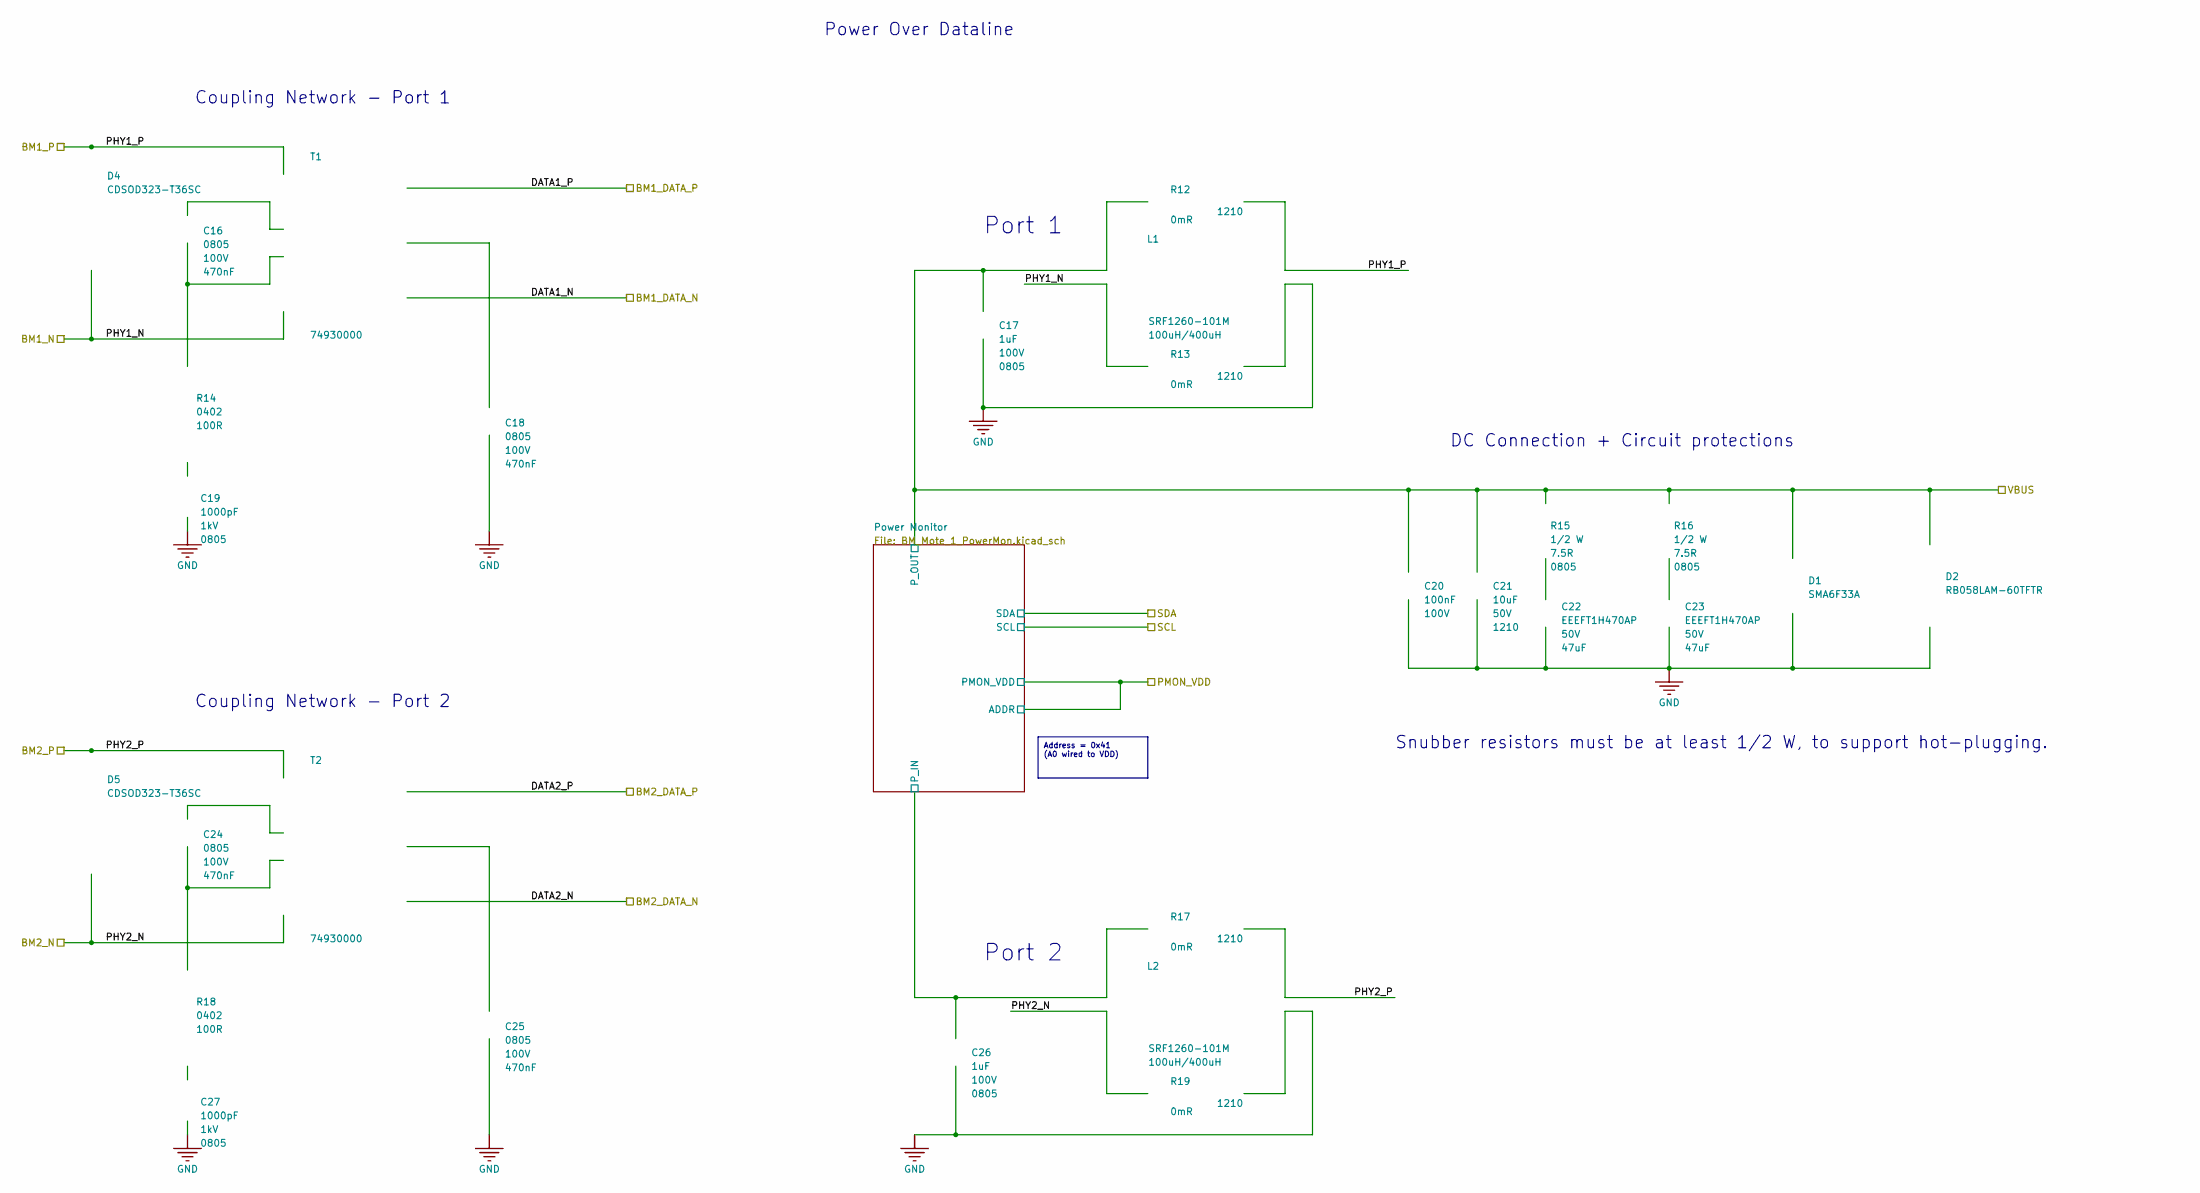
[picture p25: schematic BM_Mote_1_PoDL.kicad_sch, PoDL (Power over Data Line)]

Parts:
C16, C18, C24, C25: 08051C474KAT2A; FP-0805-L_2_01_0_2-W_1_25-MFG; TOLERANCE 10%; VOLTAGE RATING 100V
C17, C26: C2012X7S2A105K125AB; FP-C2012-125-0_2-MFG; VOLTAGE RATING (DC) 100V; VOLTAGE 100V
C19, C27: C0805C102MDRACTU; CAPC2013X145X50LL20T25; VOLTAGE 1kV; PART NUMBER C0805C102MDRACTU
C20: GRM188R72A104KA35D; FP-GRM188-0_1-e0_2_0_5-IPC_B; VOLTAGE RATING (DC) 100V; VOLTAGE 100V
C21: CL32B106KBJNNNE; FP-CL32-IPC_C; VOLTAGE RATING (DC) 50V; VOLTAGE RATING 50V
C22, C23: EEEFT1H470AP; FP-FTD-MFG; VOLTAGE 50V; TOLERANCE 20%
D1: SMA6F33A; SMA6F33A-Footprint-1; VOLTAGE - CLAMPING (MAX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 53.1V; VOLTAGE - REVERSE STAND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 33V; MANUFACTURERPARTNUMBER1 SMA6F33A-M3/H
D2: RB058LAM-60TFTR; FP-PMDTM-MFG
D4, D5: CDSOD323-T36SC; FP-SOD-323-MFG; BREAKDOWN VOLTAGE 40V; CLAMPING VOLTAGE 75V; MANUFACTURER PART NUMBER CDSOD323-T36SC; DIGIKEY DESCRIPTION TVS DIODE 36V 75V SOD323
L1, L2: SRF1260-101M; SRF1260-101M-Footprint-1
R12, R13, R17, R19: CRCW12100000Z0EA; FP-CRCW1210-e3-IPC_B; POWER RATING 500mW; VOLTAGE RATING 200V
R14, R18: RR0510P-101-D; FP-RR0510-IPC_B; RESISTANCE TOLERANCE 0.5%; POWER RATING 63mW
R15, R16: CRCW08057R50FKEAHP; CRCW08057R50FKEAHP-Footprint-1; MANUFACTURERPARTNUMBER CRCW08057R50FKEAHP
T1, T2: 74930000; FP-74930000-MFG

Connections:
/Top-Level Schematic/BM1_DATA_N: T1.2; also elsewhere on the board
/Top-Level Schematic/BM1_DATA_P: T1.1; also elsewhere on the board
/Top-Level Schematic/BM1_N: D4.2, L1.2, R13.2, T1.7; also elsewhere on the board
/Top-Level Schematic/BM1_P: D4.1, L1.3, R12.1, T1.6; also elsewhere on the board
/Top-Level Schematic/BM2_DATA_N: T2.2; also elsewhere on the board
/Top-Level Schematic/BM2_DATA_P: T2.1; also elsewhere on the board
/Top-Level Schematic/BM2_N: D5.2, L2.2, R19.2, T2.7; also elsewhere on the board
/Top-Level Schematic/BM2_P: D5.1, L2.3, R17.1, T2.6; also elsewhere on the board
/Top-Level Schematic/PoDL/Power Monitor/P_IN: C26.1, L2.1, R17.2; also elsewhere on the board
GND: C17.2, C18.1, C19.1, C20.2, C21.2, C22.1 (C), C23.1 (C), C25.1, C26.2, C27.1, D1.1 (ANODE), D2.2 (A), L1.4, L2.4, R13.1, R19.1; also elsewhere on the board
unnamed: C16.1, R14.1, T1.3
unnamed: C16.2, T1.4
unnamed: C18.2, T1.5
unnamed: C19.2, R14.2
unnamed: C22.2 (A), R15.1
unnamed: C23.2 (A), R16.1
unnamed: C24.1, R18.1, T2.3
unnamed: C24.2, T2.4
unnamed: C25.2, T2.5
unnamed: C27.2, R18.2
VBUS: C17.1, C20.1, C21.1, D1.2 (CATHODE), D2.1 (C), L1.1, R12.2, R15.2, R16.2; also elsewhere on the board

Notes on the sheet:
Coupling Network - Port 2
DC Connection + Circuit protections
Snubber resistors must be at least 1/2 W, to support hot-plugging.
Port 2
Coupling Network - Port 1
Port 1
Address = 0x41 (A0 wired to VDD)
Power Over Dataline

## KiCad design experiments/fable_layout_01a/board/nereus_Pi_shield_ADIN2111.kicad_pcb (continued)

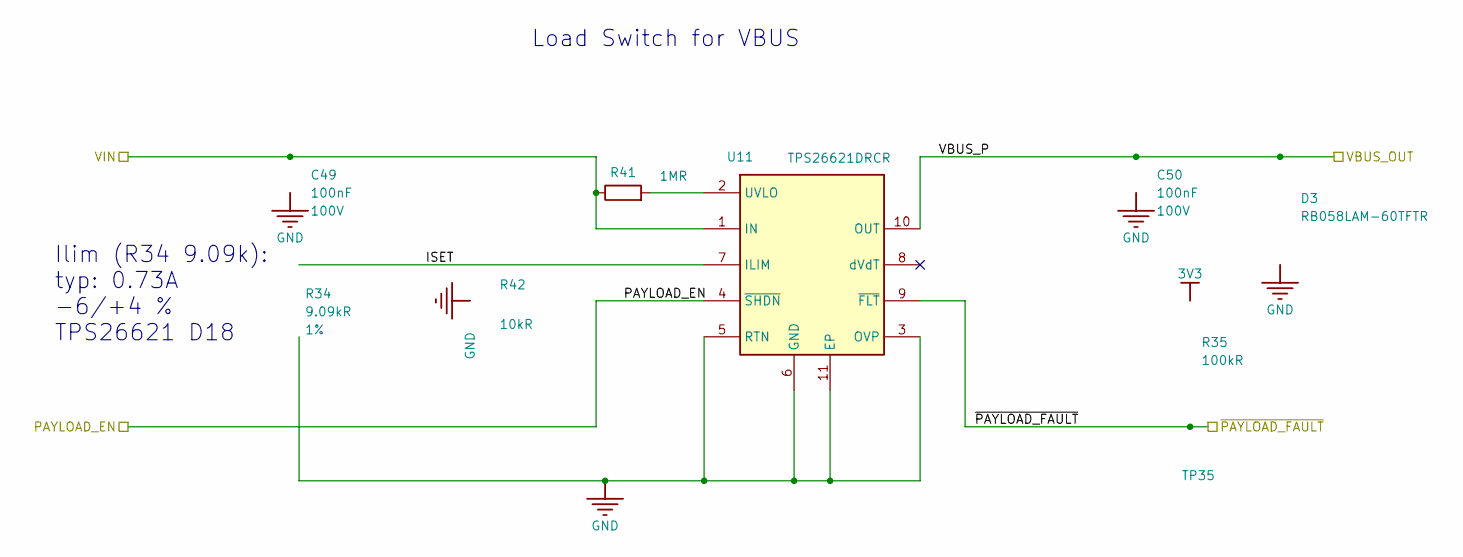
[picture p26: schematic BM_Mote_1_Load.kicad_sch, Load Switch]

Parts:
C49, C50: GRM188R72A104KA35D; FP-GRM188-0_1-e0_2_0_5-IPC_B; VOLTAGE RATING (DC) 100V; VOLTAGE 100V
D3: RB058LAM-60TFTR; FP-PMDTM-MFG
R34: RC0402FR-079K09L; RESC1005X40X25LL05T10; TOLERANCE 1%; PART NUMBER RC0402FR-079K09L
R35: RMCF0402FT100K; FP-RMCF0402-IPC_C; TOLERANCE 1%; POWER RATING 62.5mW
R41: RC0402FR-071ML; R_0402_1005Metric; PART NUMBER RC0402FR-071ML
R42: RMCF0402FT10K0; FP-RMCF0402-IPC_C; TOLERANCE 1%; POWER RATING 62.5mW
TP35: TEST_POINT; PCB_TP_1.5mm; PARTTYPE non BOM
U11: TPS26621DRCR; Texas_DRC0010J; LCSC C1848341

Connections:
3V3: R35.2; also elsewhere on the board
/Top-Level Schematic/Load Switch/ISET: R34.2, U11.7 (ILIM)
/Top-Level Schematic/PAYLOAD_EN: R42.1, U11.4 (~SHDN); also elsewhere on the board
/Top-Level Schematic/~PAYLOAD_FAULT: R35.1, TP35.1, U11.9 (~FLT); also elsewhere on the board
GND: C49.2, C50.2, D3.2 (A), R34.1, R42.2, U11.3 (OVP), U11.5 (RTN), U11.6 (GND), U11.11 (EP); also elsewhere on the board
unnamed: R41.2, U11.2 (UVLO)
VBUS: C49.1, R41.1, U11.1 (IN); also elsewhere on the board
VBUS_OUT: C50.1, D3.1 (C), U11.10 (OUT); also elsewhere on the board

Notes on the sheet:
Load Switch for VBUS
Ilim (R34 9.09k): typ: 0.73A -6/+4 % TPS26621 D18

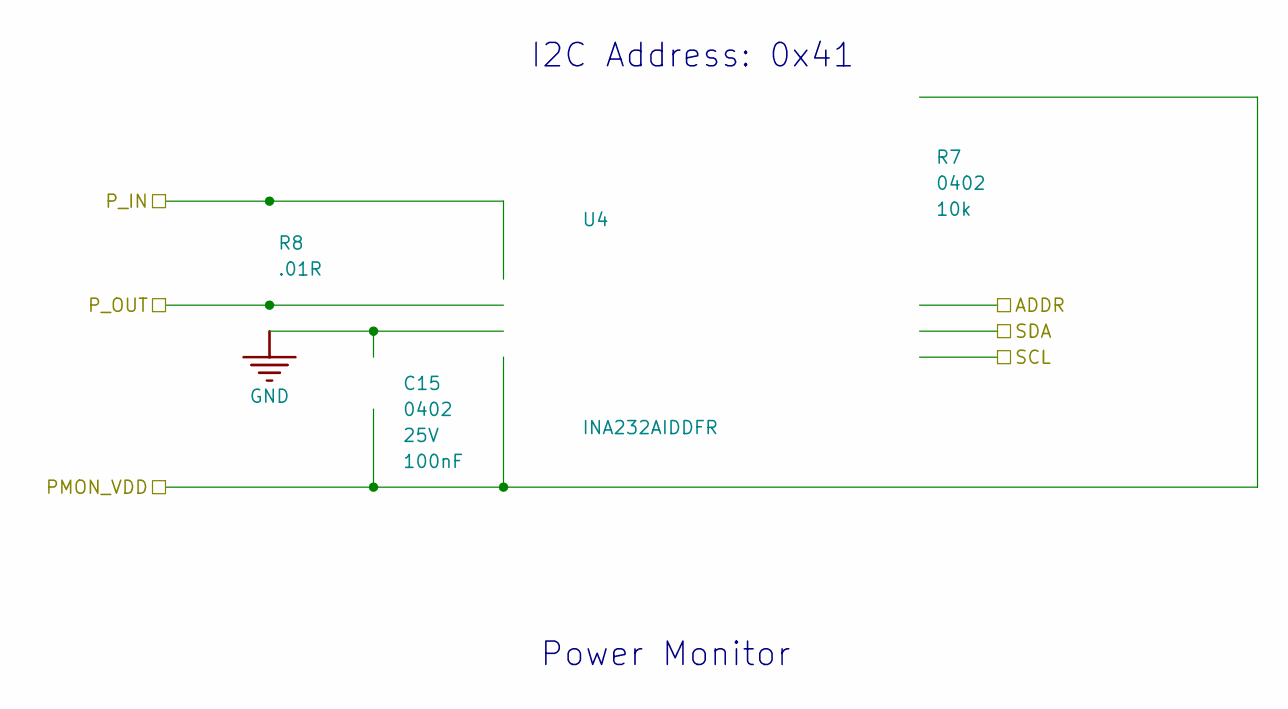
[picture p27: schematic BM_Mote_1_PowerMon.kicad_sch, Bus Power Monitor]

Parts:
C15: CL05A104KA5NNNC; FP-CL278-IPC_C; VOLTAGE 25V; VOLTAGE RATING 25V
R7: RC0402JR-0710KL; FP-RC0402-0_4-IPC_C; RESISTANCE TOLERANCE 5%; POWER RATING 62.5mW
R8: UR73D1JTTD10L0F; RESC1608X60X55ML20T10; MANUFACTURERPARTNUMBER UR73D1JTTD10L0F
U4: INA232AIDDFR; INA232AIDDFR-Footprint-1

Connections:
3V3: C15.2, R7.1, U4.4 (VS), U4.7 (A0); also elsewhere on the board
/Top-Level Schematic/I2C1_SCL: U4.5 (SCL); also elsewhere on the board
/Top-Level Schematic/I2C1_SDA: U4.6 (SDA); also elsewhere on the board
/Top-Level Schematic/PoDL/Power Monitor/P_IN: R8.2, U4.1 (IN+); also elsewhere on the board
GND: C15.1, U4.3 (GND); also elsewhere on the board
unnamed: R7.2, U4.8 (ALERT)
VBUS: R8.1, U4.2 (IN-); also elsewhere on the board

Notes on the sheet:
I2C Address: 0x41
Power Monitor

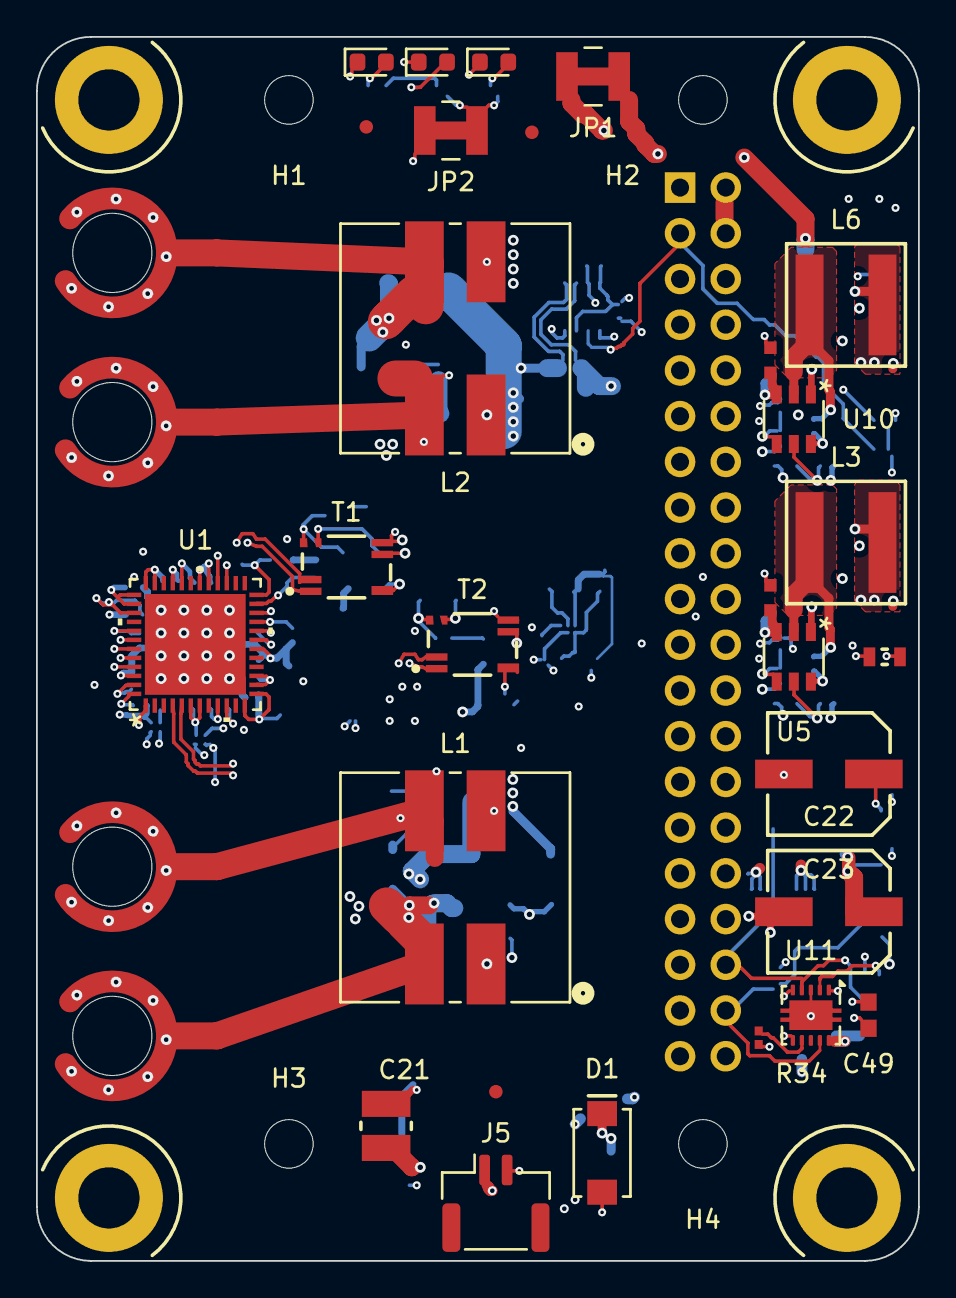
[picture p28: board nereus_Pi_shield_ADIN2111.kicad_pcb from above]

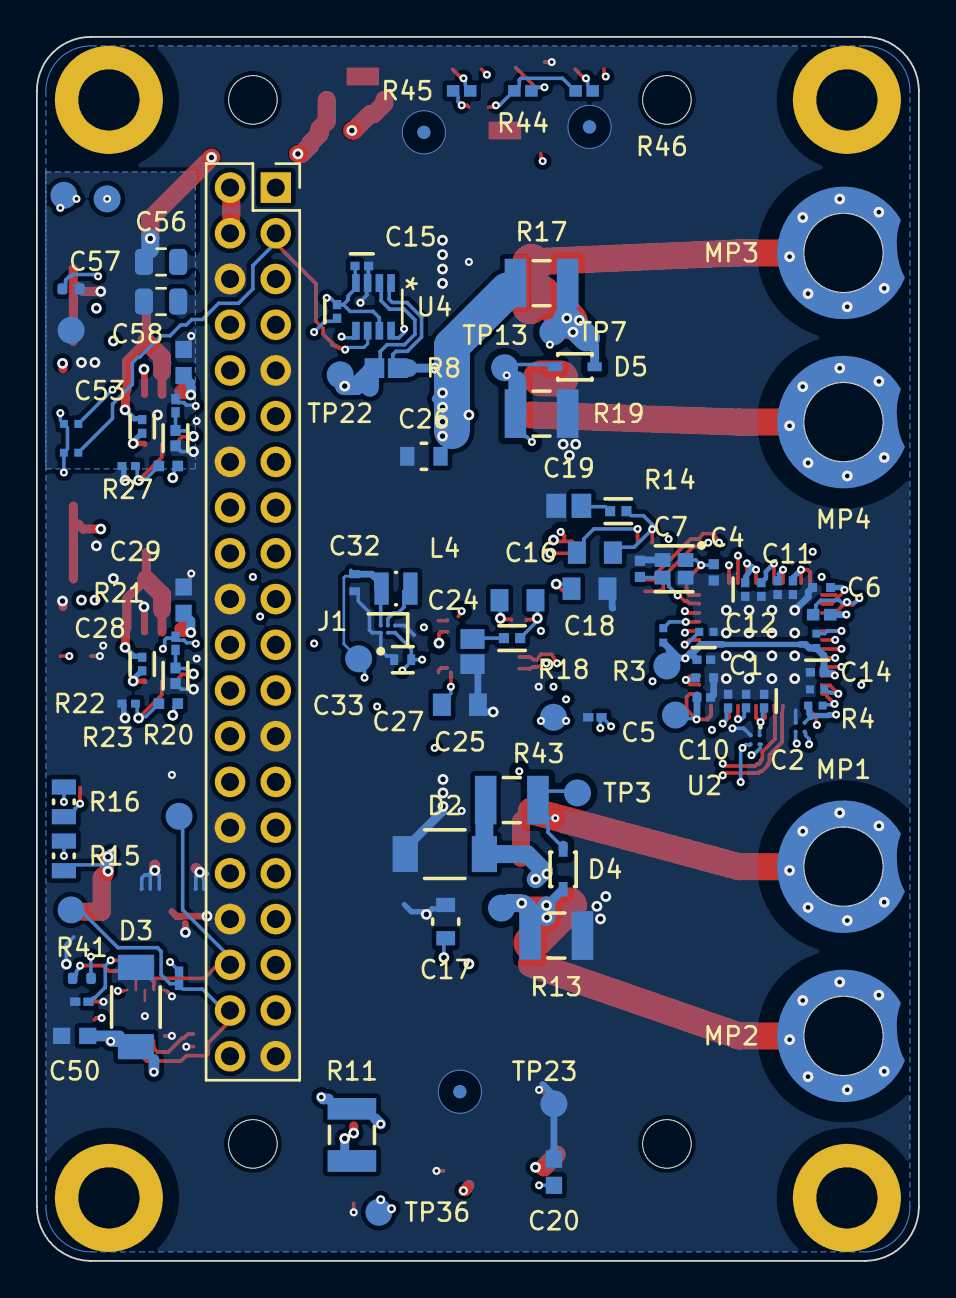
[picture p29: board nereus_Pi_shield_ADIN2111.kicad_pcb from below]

Board: 6 copper layers, 49.0 x 68.0 mm, 138 parts (102 on the bottom side), 69 nets.

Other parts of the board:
H1, H2, H3, H4: M2.5 Pi standoff; MountingHole_2.7mm_M2.5

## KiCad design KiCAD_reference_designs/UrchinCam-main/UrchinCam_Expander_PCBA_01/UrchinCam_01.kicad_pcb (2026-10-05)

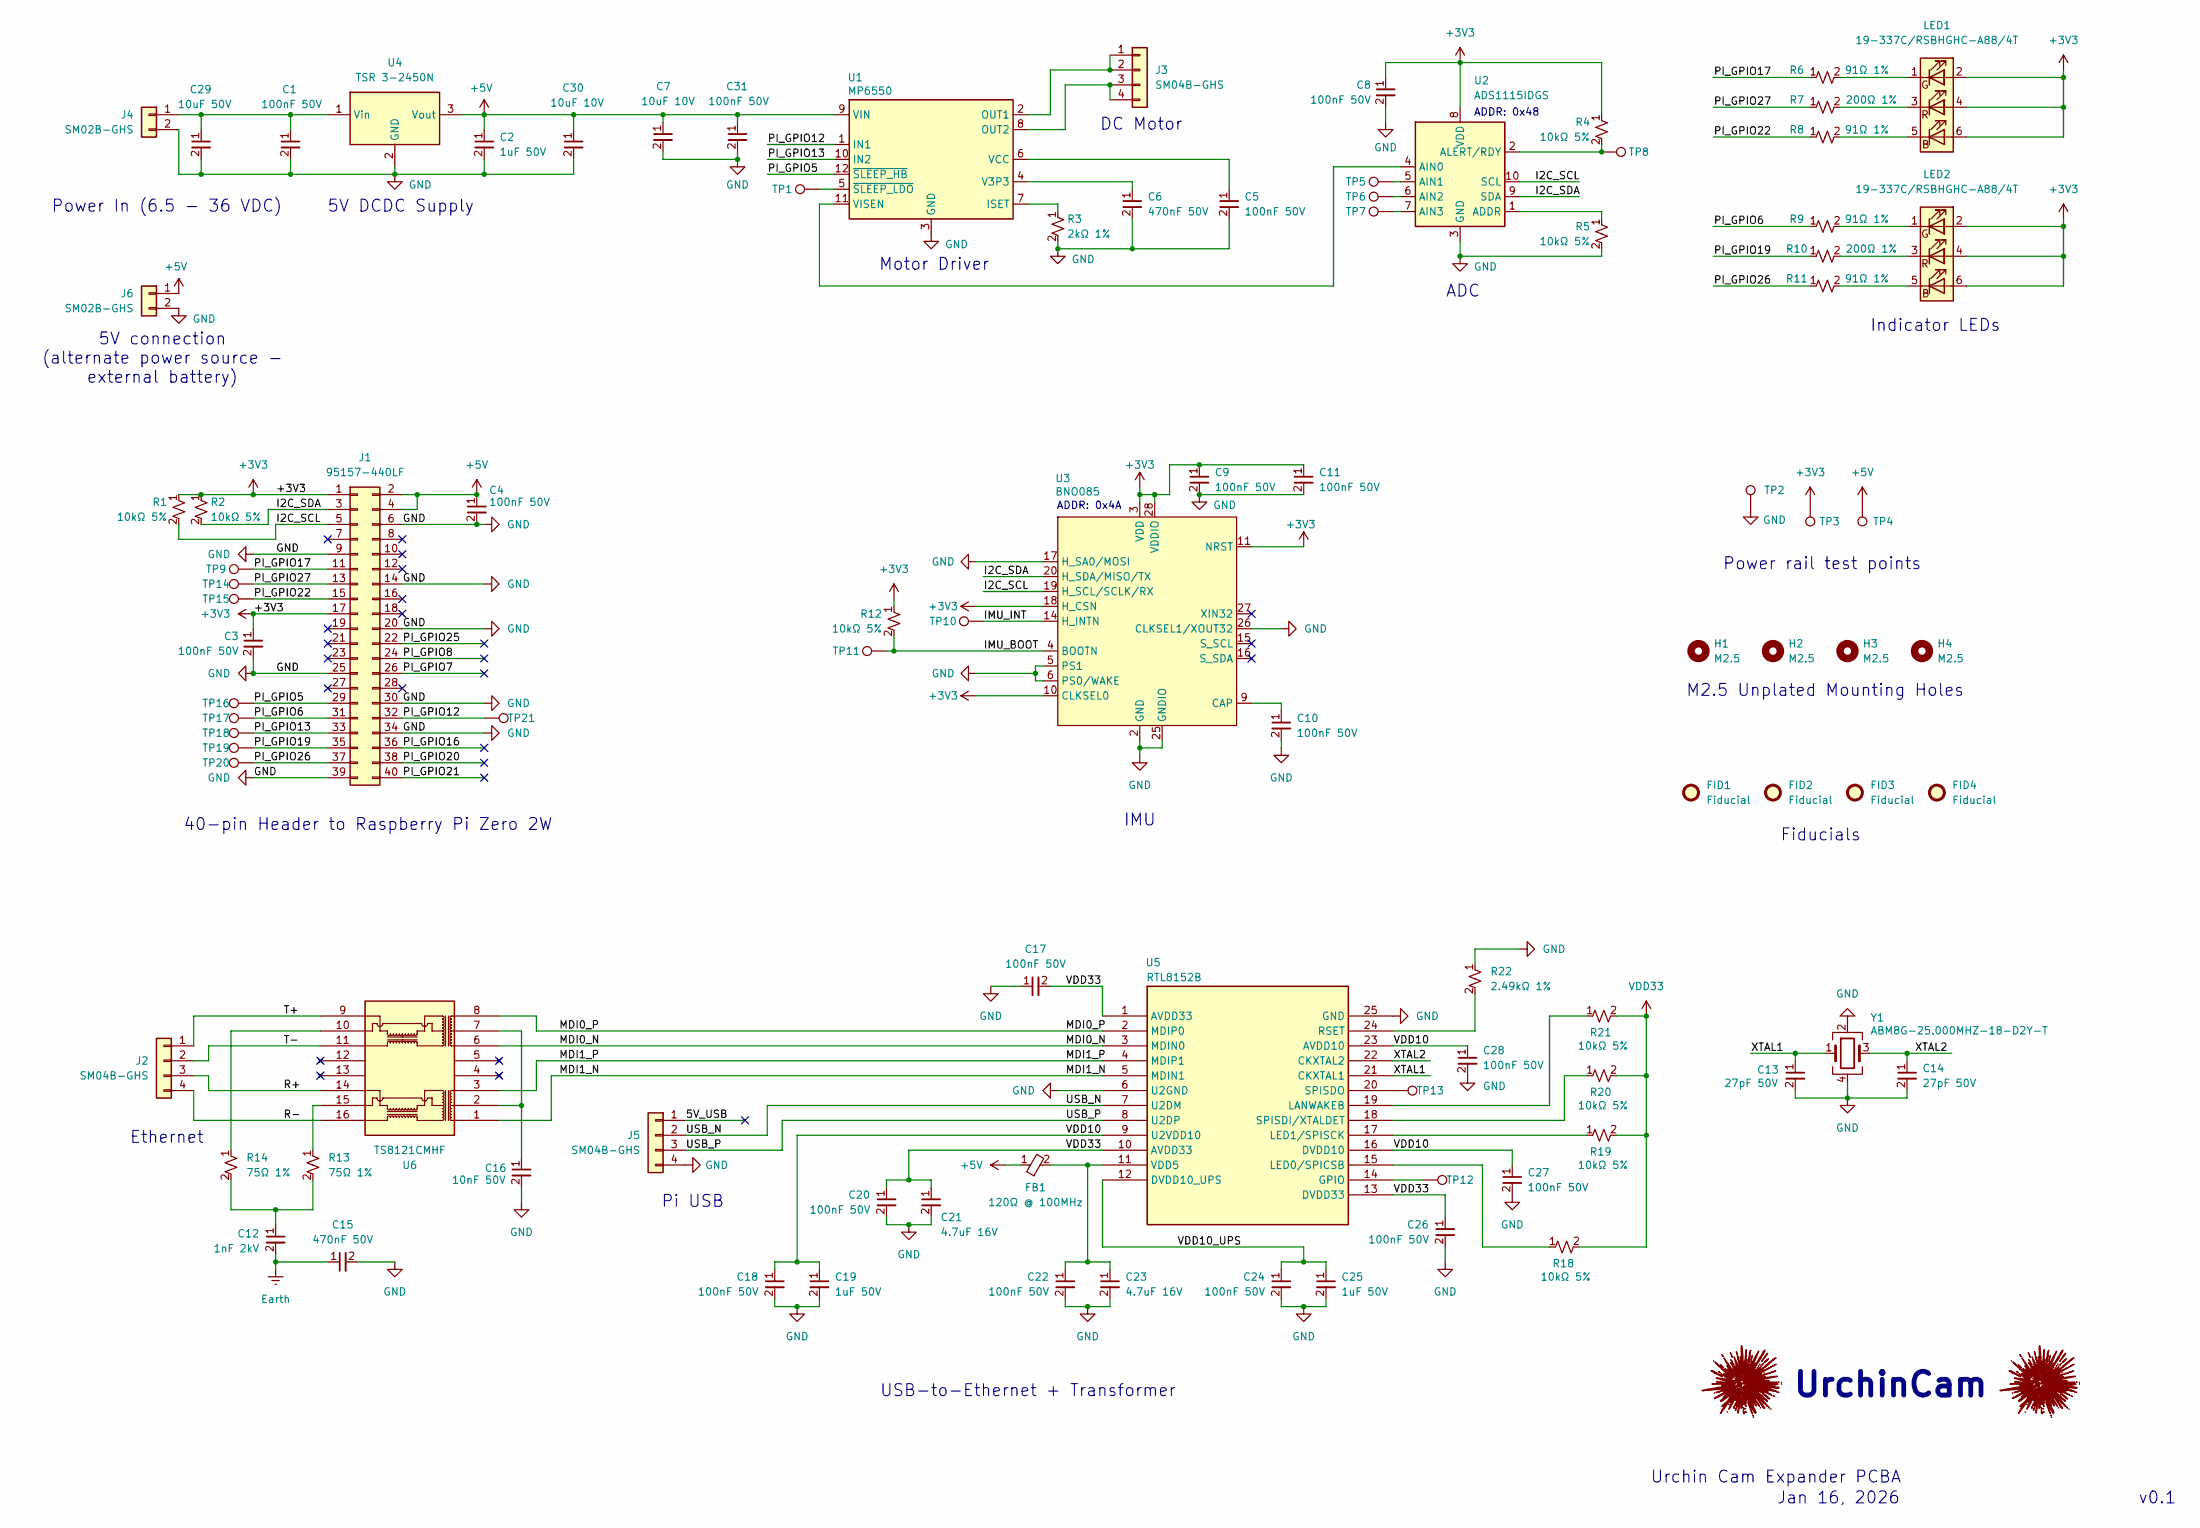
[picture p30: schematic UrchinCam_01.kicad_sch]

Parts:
C1, C3, C4, C5, C8, C9, C10, C11, C17, C18, C20, C22, C24, C26, C27, C28, C31: 100nF 50V; C_0402_1005Metric_Pad0.74x0.62mm_HandSolder
C2, C19, C25: 1uF 50V; C_0402_1005Metric_Pad0.74x0.62mm_HandSolder
C6, C15: 470nF 50V; C_0402_1005Metric_Pad0.74x0.62mm_HandSolder
C7, C30: 10uF 10V; C_0402_1005Metric_Pad0.74x0.62mm_HandSolder
C12: 1nF 2kV; C_1206_3216Metric_Pad1.33x1.80mm_HandSolder
C13, C14: 27pF 50V; C_0402_1005Metric_Pad0.74x0.62mm_HandSolder
C16: 10nF 50V; C_0402_1005Metric_Pad0.74x0.62mm_HandSolder
C21, C23: 4.7uF 16V; C_0402_1005Metric_Pad0.74x0.62mm_HandSolder
C29: 10uF 50V; C_0805_2012Metric_Pad1.18x1.45mm_HandSolder
FB1: 120Ω @ 100MHz; R_0402_1005Metric_Pad0.72x0.64mm_HandSolder
FID1, FID2, FID3, FID4: Fiducial; Fiducial_0.5mm_Mask1mm
H1, H2, H3, H4: M2.5; M2.5_Mounting_Hole_2.9mm_unplated
J1: 95157-440LF; Amphenol_95157-440LF_2x20_P2.54mm_Vertical
J2, J3, J5: SM04B-GHS; JST_GH_SM04B-GHS-TB_1x04-1MP_P1.25mm_Horizontal
J4, J6: SM02B-GHS; JST_GH_SM02B-GHS-TB_1x02-1MP_P1.25mm_Horizontal
LED1, LED2: 19-337C/RSBHGHC-A88/4T; 19-337C RSBHGHC-A88 4T
R1, R2, R4, R5, R12, R18, R19, R20, R21: 10kΩ 5%; R_0402_1005Metric_Pad0.72x0.64mm_HandSolder
R3: 2kΩ 1%; R_0402_1005Metric_Pad0.72x0.64mm_HandSolder
R6, R8, R9, R11: 91Ω 1%; R_0603_1608Metric_Pad0.98x0.95mm_HandSolder
R7, R10: 200Ω 1%; R_0603_1608Metric_Pad0.98x0.95mm_HandSolder
R13, R14: 75Ω 1%; R_0402_1005Metric_Pad0.72x0.64mm_HandSolder
R22: 2.49kΩ 1%; R_0402_1005Metric_Pad0.72x0.64mm_HandSolder
TP1, TP2, TP3, TP4, TP5, TP6, TP7, TP8, TP9, TP10, TP11, TP12, TP13, TP14, TP15, TP16, TP17, TP18, TP19, TP20, TP21: TestPoint; TestPoint_Pad_D1.5mm
U1: MP6550; MP6550GG
U2: ADS1115IDGS; TSSOP-10_3x3mm_P0.5mm
U3: BNO085; LGA-28_5.2x3.8mm_P0.5mm
U4: TSR 3-2450N; Traco_TSR 3-2450N
U5: RTL8152B
U6: TS8121CMHF; TS8121CM HF
Y1: ABM8G-25.000MHZ-18-D2Y-T; Crystal_SMD_3225-4Pin_3.2x2.5mm

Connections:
+3V3: C3.1, C8.1, C9.1, C11.1, J1.1, J1.17, LED1.2 (GA), LED1.4 (RA), LED1.6 (BA), LED2.2 (GA), LED2.4 (RA), LED2.6 (BA), R1.1, R2.1, R4.1, R12.1, TP3.1, U2.8 (VDD), U3.3 (VDD), U3.10 (CLKSEL0), U3.11 (NRST), U3.18 (H_CSN), U3.28 (VDDIO)
+5V: C2.1, C4.1, C7.1, C30.1, C31.1, FB1.1, J1.2, J1.4, J6.1, TP4.1, U1.9 (VIN), U4.3 (Vout)
/5V_USB: J5.1
/I2C_SCL: J1.5, R1.2, U2.10 (SCL), U3.19 (H_SCL/SCLK/RX)
/I2C_SDA: J1.3, R2.2, U2.9 (SDA), U3.20 (H_SDA/MISO/TX)
/IMU_BOOT: R12.2, TP11.1, U3.4 (BOOTN)
/IMU_INT: TP10.1, U3.14 (H_INTN)
/MDI0_N: U5.3 (MDIN0), U6.6
/MDI0_P: U5.2 (MDIP0), U6.8
/MDI1_N: U5.5 (MDIN1), U6.1
/MDI1_P: U5.4 (MDIP1), U6.3
/PI_GPIO5: J1.29, TP16.1, U1.12 (~SLEEP_HB)
/PI_GPIO6: J1.31, R9.1, TP17.1
/PI_GPIO7: J1.26
/PI_GPIO8: J1.24
/PI_GPIO12: J1.32, TP21.1, U1.1 (IN1)
/PI_GPIO13: J1.33, TP18.1, U1.10 (IN2)
/PI_GPIO16: J1.36
/PI_GPIO17: J1.11, R6.1, TP9.1
/PI_GPIO19: J1.35, R10.1, TP19.1
/PI_GPIO20: J1.38
/PI_GPIO21: J1.40
/PI_GPIO22: J1.15, R8.1, TP15.1
/PI_GPIO25: J1.22
/PI_GPIO26: J1.37, R11.1, TP20.1
/PI_GPIO27: J1.13, R7.1, TP14.1
/R+: J2.3, U6.14
/R-: J2.4, U6.16
/T+: J2.1, U6.9
/T-: J2.2, U6.11
/USB_N: J5.2, U5.7 (U2DM)
/USB_P: J5.3, U5.8 (U2DP)
/VDD10: C18.1, C19.1, C27.1, C28.1, U5.9 (U2VDD10), U5.16 (DVDD10), U5.23 (AVDD10)
/VDD10_UPS: C24.1, C25.1, U5.12 (DVDD10_UPS)
/XTAL1: C13.1, U5.21 (CKXTAL1), Y1.1
/XTAL2: C14.1, U5.22 (CKXTAL2), Y1.3
Earth: C12.2, C15.1
GND: C1.2, C2.2, C3.2, C4.2, C5.2, C6.2, C7.2, C8.2, C9.2, C10.2, C11.2, C13.2, C14.2, C15.2, C16.2, C17.1, C18.2, C19.2, C20.2, C21.2, C22.2, C23.2, C24.2, C25.2, C26.2, C27.2, C28.2, C29.2, C30.2, C31.2, J1.6, J1.9, J1.14, J1.20, J1.25, J1.30, J1.34, J1.39, J4.2, J5.4, J6.2, R3.2, R5.2, R22.1, TP2.1, U1.3 (GND), U2.3 (GND), U3.2 (GND), U3.5 (PS1), U3.6 (PS0/WAKE), U3.17 (H_SA0/MOSI), U3.25 (GNDIO), U3.26 (CLKSEL1/XOUT32), U4.2 (GND), U5.6 (U2GND), U5.25 (GND), Y1.2, Y1.4
unnamed: C12.1, R13.2, R14.2
unnamed: C16.1, U6.2, U6.7
unnamed: J3.1, J3.2, U1.2 (OUT1)
unnamed: J3.3, J3.4, U1.8 (OUT2)
unnamed: C1.1, C29.1, J4.1, U4.1 (Vin)
unnamed: LED1.5 (BK), R8.2
unnamed: LED1.1 (GK), R6.2
unnamed: LED1.3 (RK), R7.2
unnamed: LED2.5 (BK), R11.2
unnamed: LED2.1 (GK), R9.2
unnamed: LED2.3 (RK), R10.2
unnamed: R13.1, U6.15
unnamed: R14.1, U6.10
unnamed: R3.1, U1.7 (ISET)
unnamed: C6.1, U1.4 (V3P3)
unnamed: C5.1, U1.6 (VCC)
unnamed: U1.11 (VISEN), U2.4 (AIN0)
unnamed: TP1.1, U1.5 (~SLEEP_LDO)
unnamed: R5.1, U2.1 (ADDR)
unnamed: TP5.1, U2.5 (AIN1)
unnamed: TP6.1, U2.6 (AIN2)
unnamed: TP7.1, U2.7 (AIN3)
unnamed: R4.2, TP8.1, U2.2 (ALERT/RDY)
unnamed: C10.1, U3.9 (CAP)
unnamed: TP12.1, U5.14 (GPIO)
unnamed: R21.1, U5.19 (LANWAKEB)
unnamed: R18.1, U5.15 (LED0/SPICSB)
unnamed: R19.1, U5.17 (LED1/SPISCK)
unnamed: R22.2, U5.24 (RSET)
unnamed: R20.1, U5.18 (SPISDI/XTALDET)
unnamed: TP13.1, U5.20 (SPISDO)
unnamed: C22.1, C23.1, FB1.2, U5.11 (VDD5)
VDD33: C17.2, C20.1, C21.1, C26.1, R18.2, R19.2, R20.2, R21.2, U5.1 (AVDD33), U5.10 (AVDD33), U5.13 (DVDD33)

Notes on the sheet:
Ethernet
Power In (6.5 - 36 VDC)
Motor Driver
UrchinCam
Urchin Cam Expander PCBA
Power rail test points
DC Motor
ADC
M2.5 Unplated Mounting Holes
Pi USB
v0.1
IMU
Indicator LEDs
Jan 16, 2026
ADDR: 0x48
5V connection (alternate power source - external battery)
Fiducials
40-pin Header to Raspberry Pi Zero 2W
USB-to-Ethernet + Transformer
ADDR: 0x4A
5V DCDC Supply

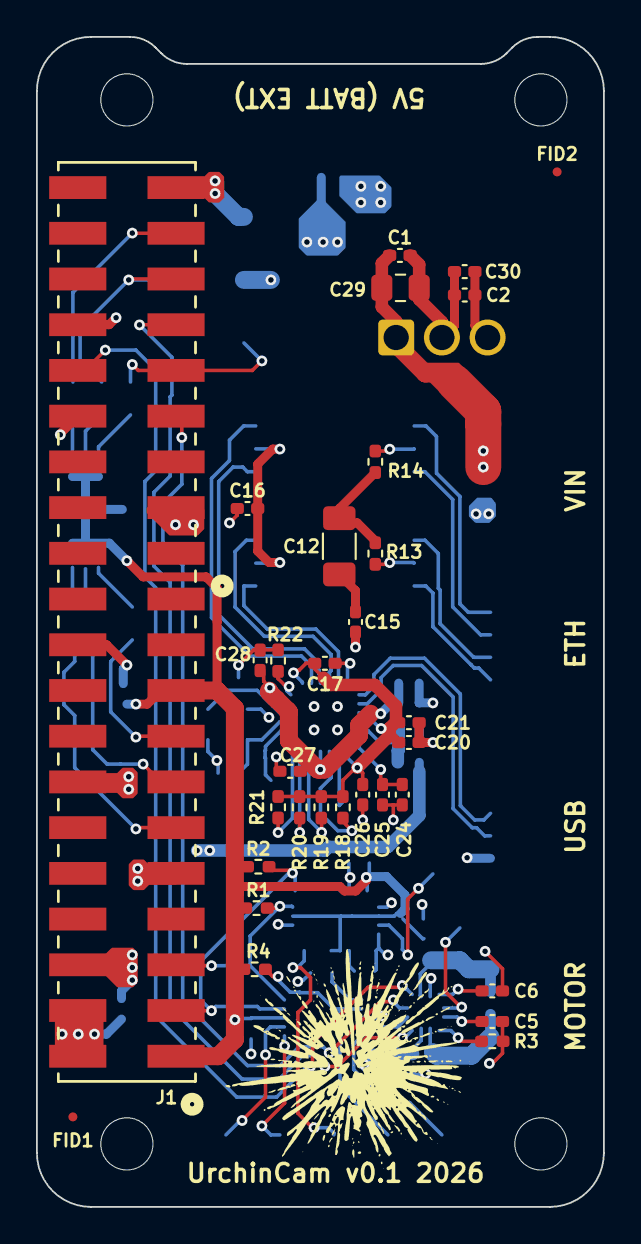
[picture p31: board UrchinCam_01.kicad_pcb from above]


Board: 4 copper layers, 31.5 x 65.0 mm, 95 parts (60 on the bottom side), 64 nets.

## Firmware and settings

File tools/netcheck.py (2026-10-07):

#!/usr/bin/env python3
"""Compare schematic connectivity against the mote's copper.

Reads the mote board (read-only) and a KiCad netlist exported from our
schematic, then compares which pins are joined together. Net names are
ignored (the Altium import renamed them); only parts present in both designs
are compared.

  opens  : a copper net whose pins are split across several schematic nets
  shorts : a schematic net that joins pins from several copper nets
  missing: a pin/pad on a shared part that exists on only one side

Parts listed in the exclusion file (scheduled for deletion) are treated as
already removed from both sides.

Exit code 0 = connectivity matches, 1 = differences, 2 = bad input.
Python standard library only.
"""
import argparse
import collections
import re
import sys
from pathlib import Path

DEFAULT_PCB = "KiCAD_reference_designs/20250409_BM_Mote_000639-AB/BM_Mote_000639-AB.kicad_pcb"
DEFAULT_NETLIST = "docs/design-review/out/netlist.net"
DEFAULT_REPORT = "docs/design-review/netcheck.md"
DEFAULT_EXCLUDE = "docs/design-review/excluded_parts.txt"


def read_exclusions(text):
    """Return {ref: reason} from 'REF  # reason' lines; blank and comment lines ignored."""
    out = {}
    for line in text.splitlines():
        ref, _, reason = line.partition("#")
        if ref.strip():
            out[ref.strip()] = reason.strip()
    return out


def blocks(text, head):
    """Yield every balanced s-expression in text that starts with '(' + head."""
    key = "(" + head
    i = 0
    while True:
        i = text.find(key, i)
        if i < 0:
            return
        depth, j = 0, i
        while True:
            c = text[j]
            if c == '"':
                j += 1
                while text[j] != '"':
                    j += 2 if text[j] == "\\" else 1
            elif c == "(":
                depth += 1
            elif c == ")":
                depth -= 1
                if depth == 0:
                    break
            j += 1
        yield text[i:j + 1]
        i = j + 1


def pcb_connectivity(text):
    """Return ({net name: {"REF.PAD"}}, {"REF.PAD"} for pads with no net)."""
    nets = collections.defaultdict(set)
    no_net = set()
    for fp in blocks(text, "footprint "):
        m = (re.search(r'\(property "Reference" "([^"]+)"', fp)
             or re.search(r'\(fp_text reference "([^"]+)"', fp))
        if not m:
            continue
        ref = m.group(1)
        for pad in blocks(fp, "pad "):
            num = re.match(r'\(pad "([^"]*)"', pad)
            if not num or not num.group(1):
                continue  # mechanical pad without a number
            net = re.search(r'\(net (?:\d+ )?"([^"]*)"\)', pad)
            node = f"{ref}.{num.group(1)}"
            if net and net.group(1):
                nets[net.group(1)].add(node)
            else:
                no_net.add(node)
    return nets, no_net


def netlist_connectivity(text):
    """Return {net name: {"REF.PIN"}} from a kicadsexpr netlist."""
    nets = {}
    for net in blocks(text, "net (code"):
        name = re.search(r'\(name "([^"]*)"\)', net).group(1)
        nets[name] = {f"{r}.{p}" for r, p in
                      re.findall(r'\(node \(ref "([^"]+)"\) \(pin "([^"]+)"\)', net)}
    return nets


def ref_of(node):
    return node.rsplit(".", 1)[0]


def compare(pcb_nets, pcb_no_net, sch_nets, excluded=()):
    pcb_refs = {ref_of(n) for v in pcb_nets.values() for n in v} | {ref_of(n) for n in pcb_no_net}
    sch_refs = {ref_of(n) for v in sch_nets.values() for n in v}
    shared = (pcb_refs & sch_refs) - set(excluded)

    def restrict(nets):
        return {name: frozenset(n for n in nodes if ref_of(n) in shared)
                for name, nodes in nets.items()}

    pcb = {k: v for k, v in restrict(pcb_nets).items() if v}
    sch = {k: v for k, v in restrict(sch_nets).items() if v}
    pcb_of = {n: name for name, nodes in pcb.items() for n in nodes}
    sch_of = {n: name for name, nodes in sch.items() for n in nodes}
    pcb_no_net = {n for n in pcb_no_net if ref_of(n) in shared}

    multi = {k: v for k, v in pcb.items() if len(v) > 1}
    sch_sets = set(sch.values())
    matched = sorted(k for k, v in multi.items() if v in sch_sets)
    opens = {k: v for k, v in multi.items() if v not in sch_sets
             and len({sch_of.get(n) for n in v}) > 1}
    shorts = {k: v for k, v in sch.items()
              if len({pcb_of.get(n, "(no copper net)") for n in v
                      if n in pcb_of or n in pcb_no_net}) > 1}
    all_pcb = set(pcb_of) | pcb_no_net
    return {
        "matched": matched, "multi": multi, "opens": opens, "shorts": shorts,
        "pcb_of": pcb_of, "sch_of": sch_of,
        "pins_not_in_copper": sorted(set(sch_of) - all_pcb),
        "pads_not_in_schematic": sorted(set(pcb_of) - set(sch_of)),
        "only_pcb": sorted(pcb_refs - sch_refs), "only_sch": sorted(sch_refs - pcb_refs),
        # every schematic net that touches a new part, with all its pins: the shield's additions to review
        "new_nets": {name: sorted(nodes) for name, nodes in sch_nets.items()
                     if any(ref_of(n) in sch_refs - pcb_refs for n in nodes)},
        "excluded": sorted(set(excluded) & (pcb_refs | sch_refs)),
        "excluded_missing": sorted(set(excluded) - (pcb_refs | sch_refs)),
    }


def natural(s):
    return [int(t) if t.isdigit() else t for t in re.split(r"(\d+)", s)]


def render(r, pcb_path, netlist_path, reasons=None):
    ok = not (r["opens"] or r["shorts"] or r["pins_not_in_copper"] or r["pads_not_in_schematic"])
    out = ["# Net check — schematic vs mote copper", "",
           f"*Copper: `{pcb_path}` · Schematic netlist: `{netlist_path}`*", "",
           "Generated by `tools/netcheck.py`; don't edit by hand.", "",
           "| Result | Count |", "|---|---|",
           f"| Copper nets (2+ pins on shared parts) | {len(r['multi'])} |",
           f"| Matched exactly | {len(r['matched'])} |",
           f"| Opens (copper net split in schematic) | {len(r['opens'])} |",
           f"| Shorts (schematic joins copper nets) | {len(r['shorts'])} |",
           f"| Schematic pins with no copper pad | {len(r['pins_not_in_copper'])} |",
           f"| Copper pads with no schematic pin | {len(r['pads_not_in_schematic'])} |",
           f"| Parts only in copper (removed) | {len(r['only_pcb'])} |",
           f"| Parts only in schematic (new) | {len(r['only_sch'])} |",
           f"| Parts excluded (scheduled for deletion) | {len(r['excluded'])} |",
           "", f"**Status: {'MATCH' if ok else 'DIFFERENCES'}**", ""]
    if r["excluded"]:
        reasons = reasons or {}
        out += ["## Excluded parts", "", "Treated as already removed (see the exclusion file).", ""]
        out += [f"- {ref} — {reasons.get(ref, '')}".rstrip(" —") for ref in sorted(r["excluded"], key=natural)]
        out.append("")
    if r["excluded_missing"]:
        out += ["## Exclusion list entries no longer in either design", "",
                "Delete these lines from the exclusion file: "
                + ", ".join(sorted(r["excluded_missing"], key=natural)), ""]
    if r["opens"]:
        out += ["## Opens", "", "Pins joined in copper but split in the schematic, "
                "grouped by the schematic net each pin landed on.", ""]
        for name in sorted(r["opens"], key=natural):
            out.append(f"### {name} ({len(r['opens'][name])} pins)")
            groups = collections.defaultdict(list)
            for n in r["opens"][name]:
                groups[r["sch_of"].get(n, "(pin missing)")].append(n)
            for sch_name in sorted(groups, key=lambda g: (-len(groups[g]), g)):
                out.append(f"- `{sch_name}`: {', '.join(sorted(groups[sch_name], key=natural))}")
            out.append("")
    if r["shorts"]:
        out += ["## Shorts", "", "Schematic nets that join pins from different copper nets.", ""]
        for name in sorted(r["shorts"], key=natural):
            groups = collections.defaultdict(list)
            for n in r["shorts"][name]:
                groups[r["pcb_of"].get(n, "(no copper net)")].append(n)
            out.append(f"### `{name}`")
            for pcb_name in sorted(groups):
                out.append(f"- copper `{pcb_name}`: {', '.join(sorted(groups[pcb_name], key=natural))}")
            out.append("")
    for title, key in (("Schematic pins with no copper pad", "pins_not_in_copper"),
                       ("Copper pads with no schematic pin", "pads_not_in_schematic"),
                       ("Parts only in copper (removed)", "only_pcb"),
                       ("Parts only in schematic (new)", "only_sch")):
        if r[key]:
            out += [f"## {title}", "", ", ".join(sorted(r[key], key=natural)), ""]
    if r.get("new_nets"):
        out += ["## Schematic nets with new parts", "",
                "Every schematic net that includes a pin of a part with no pins on the mote's copper (the new "
                "parts, plus MP1–MP4: on the mote board but with unnumbered insert pads, Sofar Q6), with all its "
                "pins. Pins of kept parts on these nets are also checked against the copper above.", "",
                "| Net | Pins |", "|---|---|"]
        loose = sorted((n for n in r["new_nets"] if n.startswith("unconnected-")), key=natural)
        for name in sorted(r["new_nets"], key=natural):
            if name not in loose:
                out.append(f"| `{name}` | {', '.join(sorted(r['new_nets'][name], key=natural))} |")
        if loose:
            pins = sorted({n for name in loose for n in r["new_nets"][name]}, key=natural)
            out.append(f"| *{len(loose)} unconnected-pin nets* | {', '.join(pins)} |")
        out.append("")
    return "\n".join(out), ok


def main(argv=None):
    ap = argparse.ArgumentParser(description=__doc__.splitlines()[0])
    ap.add_argument("--pcb", default=DEFAULT_PCB, help="mote board (read-only)")
    ap.add_argument("--netlist", default=DEFAULT_NETLIST, help="kicadsexpr netlist from our schematic")
    ap.add_argument("--report", default=DEFAULT_REPORT, help="markdown report to write")
    ap.add_argument("--exclude", default=DEFAULT_EXCLUDE,
                    help="parts scheduled for deletion ('' to disable)")
    a = ap.parse_args(argv)
    reasons = {}
    if a.exclude:
        if not Path(a.exclude).is_file():
            print(f"netcheck: exclusion file not found: {a.exclude}\n"
                  f"  hint: pass --exclude '' to run without one", file=sys.stderr)
            return 2
        reasons = read_exclusions(Path(a.exclude).read_text())
    for p in (a.pcb, a.netlist):
        if not Path(p).is_file() or Path(p).stat().st_size == 0:
            print(f"netcheck: missing or empty input: {p}\n"
                  f"  hint: run tools/check.sh to export the netlist first", file=sys.stderr)
            return 2
    pcb_nets, pcb_no_net = pcb_connectivity(Path(a.pcb).read_text())
    sch_nets = netlist_connectivity(Path(a.netlist).read_text())
    if not pcb_nets or not sch_nets:
        print(f"netcheck: parsed no nets (copper {len(pcb_nets)}, schematic {len(sch_nets)}); "
              "is the file format right?", file=sys.stderr)
        return 2
    r = compare(pcb_nets, pcb_no_net, sch_nets, reasons)
    text, ok = render(r, a.pcb, a.netlist, reasons)
    Path(a.report).parent.mkdir(parents=True, exist_ok=True)
    Path(a.report).write_text(text + "\n")
    print(f"netcheck: {len(r['matched'])}/{len(r['multi'])} copper nets matched; "
          f"{len(r['opens'])} opens, {len(r['shorts'])} shorts, "
          f"{len(r['pins_not_in_copper'])}+{len(r['pads_not_in_schematic'])} unpaired pins; "
          f"{len(r['excluded'])} parts excluded → {a.report}")
    return 0 if ok else 1


if __name__ == "__main__":
    sys.exit(main())

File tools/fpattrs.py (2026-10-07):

#!/usr/bin/env python3
"""Set footprint type (attr) and an F.CrtYd courtyard on every footprint in a .pretty library.

Runs on KiCad's bundled Python (pcbnew module, used to read the footprints and compute geometry). The change
is written as plain text inserts (one `(attr ...)` line, four `fp_line`s on F.CrtYd), so the diff is exactly what
was added: KiCad's own writer would also regenerate every uuid. Each written file is re-loaded with pcbnew.

  PY=/Applications/KiCad/KiCad.app/Contents/Frameworks/Python.framework/Versions/Current/bin/python3
  $PY tools/fpattrs.py LIB.pretty            # report what would change
  $PY tools/fpattrs.py LIB.pretty --write    # change and save

Type (KiCad stock-library conventions): fiducials "smd exclude_from_bom"; test pads and mounting holes
"exclude_from_pos_files exclude_from_bom"; everything else with SMD pads "smd". A footprint that already has
a type or a courtyard is left alone for that item.
Courtyard (rectangle on F.CrtYd, 0.05 mm lines), first match wins:
  1. the footprint's own Altium courtyard: four thin (<= 0.05 mm) axis-aligned lines on one User layer forming a
     rectangle that encloses every pad;
  2. otherwise its largest User-layer outline that encloses every pad (Altium mechanical layers carry the
     body/assembly outline there, not on Fab);
  3. otherwise the bounding box of pads, silkscreen and fab plus 0.25 mm (IPC-7351 nominal), rounded out to 0.01 mm.
Pads are never touched.
"""
import re
import sys
import uuid
from pathlib import Path

pcbnew = None        # imported in main(): KiCad's bundled Python only; the text helpers below don't need it

MM = 1_000_000      # pcbnew internal units per mm (nm)
NOT_PLACED = {"PCB_TP_1.5mm", "Hole_M3"}     # bare copper test pad / mounting hole
FIDUCIAL = {"FIDUCIAL_075MM"}
MARGIN = 0.25


def mm(v):
    return v / MM


def want_attr(fp):
    name = fp.GetFPID().GetLibItemName().wx_str()
    if name in FIDUCIAL:
        return pcbnew.FP_SMD | pcbnew.FP_EXCLUDE_FROM_BOM, "smd exclude_from_bom"
    if name in NOT_PLACED:
        return pcbnew.FP_EXCLUDE_FROM_POS_FILES | pcbnew.FP_EXCLUDE_FROM_BOM, "exclude_from_pos_files exclude_from_bom"
    attrs = {p.GetAttribute() for p in fp.Pads()}
    if pcbnew.PAD_ATTRIB_PTH in attrs:
        raise ValueError(f"{name}: plated through-hole pads; classify by hand")
    return pcbnew.FP_SMD, "smd"


def bbox(items):
    """(left, top, right, bottom) in IU over the items' bounding boxes (plain min/max); for drawn shapes
    the stroke half-width is taken off, so the box is the drawn geometry (line centres)."""
    out = []
    for i in items:
        b = i.GetBoundingBox()
        w = i.GetWidth() // 2 if i.GetClass() == "PCB_SHAPE" else 0
        out.append((b.GetLeft() + w, b.GetTop() + w, b.GetRight() - w, b.GetBottom() - w))
    return (min(b[0] for b in out), min(b[1] for b in out), max(b[2] for b in out), max(b[3] for b in out))


def user_outline(fp, pads):
    """The largest User-layer outline (all drawn shapes on one User layer) that encloses the pads."""
    best, best_layer = None, None
    layers = {}
    for s in fp.GraphicalItems():
        if s.GetClass() == "PCB_SHAPE" and pcbnew.LayerName(s.GetLayer()).startswith("User."):
            layers.setdefault(s.GetLayer(), []).append(s)
    for layer, shapes in layers.items():
        b = bbox(shapes)
        if b[0] <= pads[0] and b[1] <= pads[1] and b[2] >= pads[2] and b[3] >= pads[3]:
            if best is None or (b[2] - b[0]) * (b[3] - b[1]) > (best[2] - best[0]) * (best[3] - best[1]):
                best, best_layer = b, pcbnew.LayerName(layer)
    return best, best_layer


def altium_courtyard(fp, pads):
    """Four thin axis-aligned lines on one User layer forming a rectangle that encloses the pads."""
    by_layer = {}
    for s in fp.GraphicalItems():
        if s.GetClass() != "PCB_SHAPE" or s.GetShape() != pcbnew.SHAPE_T_SEGMENT:
            continue
        if not pcbnew.LayerName(s.GetLayer()).startswith("User.") or mm(s.GetWidth()) > 0.051:
            continue
        a, b = s.GetStart(), s.GetEnd()
        if a.x != b.x and a.y != b.y:
            continue
        by_layer.setdefault(s.GetLayer(), []).append((a, b))
    for layer, segs in by_layer.items():
        xs = sorted({p.x for s in segs for p in s})
        ys = sorted({p.y for s in segs for p in s})
        if len(segs) < 4:
            continue
        x0, x1, y0, y1 = xs[0], xs[-1], ys[0], ys[-1]
        edges = {((min(a.x, b.x), min(a.y, b.y)), (max(a.x, b.x), max(a.y, b.y))) for a, b in segs}
        rect = {((x0, y0), (x1, y0)), ((x0, y1), (x1, y1)), ((x0, y0), (x0, y1)), ((x1, y0), (x1, y1))}
        if rect <= edges and x0 <= pads[0] and y0 <= pads[1] and x1 >= pads[2] and y1 >= pads[3]:
            return (x0, y0, x1, y1), pcbnew.LayerName(layer)
    return None, None


def computed_courtyard(fp, pads):
    fab = [s for s in fp.GraphicalItems() if s.GetClass() == "PCB_SHAPE"
           and s.GetLayer() in (pcbnew.F_Fab, pcbnew.B_Fab, pcbnew.F_SilkS)]
    l, t, r, b = pads
    if fab:
        fl, ft, fr, fb = bbox(fab)
        l, t, r, b = min(l, fl), min(t, ft), max(r, fr), max(b, fb)
    m = int(MARGIN * MM)
    step = int(0.01 * MM)
    return ((l - m) // step * step, (t - m) // step * step, -((-(r + m)) // step) * step, -((-(b + m)) // step) * step)


def fmt(iu):
    v = f"{iu / MM:.6f}".rstrip("0").rstrip(".")
    return "0" if v in ("-0", "") else v


def insert_text(text, attr_label, rect):
    """Insert `(attr ...)` before the first graphic/pad item and the courtyard lines before the first pad."""
    lines = text.split("\n")
    if attr_label:
        i = next(k for k, l in enumerate(lines) if re.match(r"^\t\((fp_|pad |model|embedded_fonts)", l))
        lines.insert(i, f"\t(attr {attr_label})")
    if rect:
        x0, y0, x1, y1 = rect
        block = []
        for (ax, ay), (bx, by) in (((x0, y0), (x1, y0)), ((x1, y0), (x1, y1)), ((x1, y1), (x0, y1)), ((x0, y1), (x0, y0))):
            block += ["\t(fp_line", f"\t\t(start {fmt(ax)} {fmt(ay)})", f"\t\t(end {fmt(bx)} {fmt(by)})",
                      "\t\t(stroke", "\t\t\t(width 0.05)", "\t\t\t(type solid)", "\t\t)",
                      '\t\t(layer "F.CrtYd")', f'\t\t(uuid "{uuid.uuid4()}")', "\t)"]
        i = next(k for k, l in enumerate(lines) if l.startswith("\t(pad "))
        lines[i:i] = block
    return "\n".join(lines)
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

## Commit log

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2026-10-05 updated with fix junctions in the schematic
    [BM_Mote_1_ADIN2111.kicad_sch, BM_Mote_1_Load.kicad_sch, BM_Mote_1_Master.kicad_sch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]
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2026-10-05 S0.3–S0.4: net check vs mote copper; baseline recorded; S0 done
    - tools/netcheck.py (stdlib, unit-tested) compares schematic connectivity
    with the mote board's copper, ignoring net names; tools/check.sh runs
    ERC + netlist + PDF + netcheck in one command.
    - Baseline: ERC 90/578; netcheck 42/68 copper nets matched, 26 opens,
    0 shorts (docs/design-review/netcheck.md). The reference schematic shows
    38 opens against its own copper, so the opens come from the import.
    - TRACKER/DESIGN/SPEC/DEV_LOG and the checklist HTML synced; S0 demo passed.
    [netcheck.py, test_netcheck.py]
2026-10-05 S1.1–S1.2: connect 21 pins the Altium import left mid-wire; drop orphan sheets
    - tools/midwire.py finds pins whose end sits mid-wire (Altium connects
    them, KiCad doesn't) and --fix splits the wire there + adds a junction.
    Applied at 21 locations on kept parts. Now in check.sh as a guard.
    - The archived junction-only fix marks the same points but, tested one at a
    time in KiCad 9.0.6, breaks neighbouring connections; not used.
    - Deleted unreferenced BM_Mote_1_Processor/USB sheet files.
    - netcheck: 53/53 copper nets matched, 0 opens, 0 shorts (was 14 opens).
    ERC 90/578 -> 65/590 (+12 off-grid warnings at the new split points).
    - docs/design-review/changelog.md started for the review p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
    [BM_Mote_1_ADIN2111.kicad_sch, BM_Mote_1_Load.kicad_sch, BM_Mote_1_Master.kicad_sch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]
2026-10-05 S1.3–S1.4: number power symbols; verify ADIN_VDDIO and ADIN SPI; S1 docs
    - 65 x "#PWR?" -> #PWR01..#PWR65 (property + instance); ERC/netlist unchanged.
    - ADIN_VDDIO label verified on the right net (pull-ups powered); not changed.
    - ADIN SPI/INT/RST verified to reach the Top-Level sheet from U1 (their
    copper peer was the removed STM32, so netcheck can't see them).
    - Remaining 65 ERC errors classified and assigned to sprints (DESIGN.md);
    changelog, TRACKER, DEV_LOG, SPEC and checklist HTML synced.
    [BM_Mote_1_ADIN2111.kicad_sch, BM_Mote_1_Load.kicad_sch, BM_Mote_1_Master.kicad_sch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]
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2026-10-05 S2.2: place Pi header J1 with GND, PWR_FLAGs and 3V3 no-connect; S2 docs
    - J1 Connector:Raspberry_Pi_2_3 (KiCad 9.0.6 library), footprint
    PinSocket_2x20_P2.54mm_Vertical, at (121.92, 88.9) in clear space.
    - All 8 GND pins on GND (one symbol at the stacked pin point, verified in
    the netlist); NC flag on pins 1/17 (Pi 3V3); PWR_FLAG on GND and VBUS.
    - schedit: wires carrying a label part-way are shortened, not deleted
    (keeps the I2C1 labels; test added). next_ref keeps zero-padding.
    - Changelog, TRACKER, DESIGN (ERC owners), SPEC (I2C pull-up question),
    DEV_LOG and checklist HTML synced.
    [BM_Mote_1_Master.kicad_sch]
2026-10-05 Process: independent read-only Quality Engineer review before Nick's KiCad review
    - .claude/agents/quality-engineer.md (Opus 5.5, high effort, read-only tools
    and rules: no edits, no state-changing git, outputs only to a temp dir).
    - TRACKER nibbles: PR -> QE review (fix loop) -> Nick KiCad review -> merge.
    - D11: shield provides I2C pull-ups (reuse mote R26/R27 4.7k), S5 task.
2026-10-05 S2: address QE round 1 (CHANGES REQUESTED)
    - F1 (MAJOR): ERC owner table corrected (pin_not_connected 41 incl. FID1-6
    and SW_FLAGB/SW_PGOOD sheet pins; #PWR34 added); -27/+38 decomposition
    fixed everywhere. New tools/ercsum.py (+ test) builds ERC tables from the
    report and checks the totals.
    - F2: warnings paragraph updated. F3: stale MEZZANINE text box deleted
    (netlist/ERC unchanged); processor note -> S6. F4: QE agent uses the PR
    baseRefOid. F5/F6: D11 pointers, decision order, "pin 2 (stacked with 4)".
    - QE risks added to S5 (pull-up rail, sequencing, pins 27/28, SW_* pins).
    - QE report saved: docs/design-review/qe/S2.md.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
    [BM_Mote_1_Master.kicad_sch]
2026-10-05 S2: address QE round 2 nits; one standing QE session per sprint
    - N1: SW_FLAGB/SW_PGOOD wording corrected (copper: they never reached P1;
    unconnected on Top-Level since import); S5 reuses R33/R35, TP34/TP35.
    - N2/N3/N6: demo text (-27/+38; 30 J1 errors), "pin 2 (stacked with 4)",
    "PoDL and Power Monitor sheets". N7: S5 duplicates merged, agent-file
    sentence moved. N5: test_ercsum in test commands.
    - N4: ercsum exits 1 without a totals line, lists connector pin numbers;
    3 new tests.
    - Process: standing QE session per sprint (TRACKER, agent file, D10).
    - QE round 2 report + response saved in docs/design-review/qe/S2.md.
    [ercsum.py, test_ercsum.py]
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2026-10-05 S2 close-out: sync checklist viewer and DEV_LOG after PR #5 merge
    The PR #5 close-out commit only carried TRACKER (an HTML text match failed
    but the chained git commands ran anyway). This syncs the viewer status and
    checkpoint, and records the merge in DEV_LOG.
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2026-10-05 S3: fix QE round 1 (README, Q1 deferred, Q3/POWER_PATH/TRACKER wording); QE sends reports directly
    QE round 1 CHANGES REQUESTED (schematic side clean). F1 README matches
    SPEC; F2 Sofar Q1 deferred with the 50 W revision; F3-F5 wording. Report
    saved to docs/design-review/qe/S3.md. Process: the QE sends its report to
    the design session when done (TRACKER rule 3.4, quality-engineer.md).
2026-10-05 S3: QE round 2 APPROVED WITH NITS; fix nits, record report
    PR body, process wiring (QE role file note, PROMPTS §5), DEV_LOG layout,
    TRACKER demo line, qe/S3.md wording. Report saved to qe/S3.md.
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2026-10-05 S4.a: fix QE round 1 (set_properties escaped quotes, C56/C57 stale fields, docs)
    F1: PROP regex accepts escaped chars; set_properties refuses partial
    parses; test added; stale 0603 fields removed from C56/C57. F2 thermal
    item in S4.c + SPEC; F3 demo line; F4-F7 D13/SPEC; F8 C58 one grid right
    with 10V shown. Connectivity and values unchanged. Report in qe/S4.md.
    [BM_Mote_1_Power.kicad_sch]
2026-10-05 S4.a: QE round 2 APPROVED WITH NITS; fix N1-N3, record report
    [BM_Mote_1_Power.kicad_sch]
2026-10-05 S4.b: shield powers the Pi through bridged link JP1 (D14); close S4.a
    Top-Level: JP1 (stock SolderJumper_2_Bridged, not in BOM) joins 5V_PI to
    new net PI_5V (J1 pins 2/4); #FLG03; note. New project footprint
    nereus:R_1210_Bridged_NetTie (R11's 1210 pads + 1 mm copper net tie) in
    nereus.pretty with a project fp-lib-table. midwire.lib_pins fix: symbols
    named like Raspberry_Pi_2_3 were skipped (+ test). ERC 76/629 (-2, J1 pin
    2), netcheck 53/53, existing connections identical.
    [BM_Mote_1_Master.kicad_sch]
2026-10-05 S4.b: fix QE round 1 F2-F6; record F1 back-feed analysis for Nick's decision
    Note cites D14 and covers any USB cable; TRACKER demo line for S4.b;
    footprint renamed nereus:SolderJumper-2_R1210_Bridged_NetTie (matches the
    stock symbol's filter); dead lib_pins branch removed; cut guidance. F1:
    mechanism (Pi USB 5V -> L6 -> U10 HS body diode -> VBUS) in D14 and SPEC,
    pending Nick's call. Report in qe/S4.md.
    [BM_Mote_1_Master.kicad_sch]
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2026-10-05 S4.c: power budget (docs only); close S4.b
    New docs/design-review/power_budget.md from primary sources (RPi docs and
    product brief, TI SLUSEF4A, Pulse P890.B, ADI, IPC-2221). U10 temperature
    is the binding limit; JP1 bridge adequate; Zero range has no undervoltage
    detector. Proposals P-S4c-1 (Pi load <= 1 A) and P-S4c-2 (keep R38) for
    Nick. Footprints split out to S4.d. ERC/netcheck unchanged.
2026-10-05 S4.c: fix QE round 1; record D15-D17; FPF2700 facts; U9 obsolete -> S5
    Budget now against both limits (Bristlemouth v1 12 W per module and 890 mA),
    VBUS behind L1's 0.656 ohm, L1 heat, thermal caveats + psiJT bench check,
    camera figures, 13.5k option. Nick: D15 Pi <= 1 A, D16 keep R38 13.7k, D17
    payload port kept (small payloads). FPF2700 (Fairchild Rev 1.0.3): R34 sets
    ~0.74 A; Sofar Q3 answered. FPF2700MX obsolete (Digi-Key) -> S5: replace
    with a JLC-sourceable part; whole-BOM lifecycle check before S6.
2026-10-05 S4.c: QE round 2 F4 -- R11 fitted bypassed U9; Nick: R11 DNP (D17); N6
    As captured R11 (0 ohm across U9) is fitted, so U9 was bypassed. Nick:
    make R11 DNP so the load switch switches and limits the payload; the
    schematic edit and the U9 replacement go to S5 (with output-cap / hard-
    short criteria up to 32 V). D17, power_budget, SPEC, Q2, TRACKER, viewer.
2026-10-05 S4.c: QE round 3 -- Nick amends SPEC constraint 7 for the payload load switch (D17)
    Constraint 7: power path stays Sofar's except the payload load switch
    (R11 DNP, U9 replaced, R34/R33/R35 re-derived). D12/D17 cross-referenced;
    D14 back-feed wording (N7); viewer status (N8). Report in qe/S4.md.
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2026-10-05 S5.a: fix QE round 1 (R34 PART NUMBER, R42 10k worst-case SHDN, RTN=GND, N6, stale docs)
    [BM_Mote_1_Load.kicad_sch]
2026-10-06 S4.d: footprints findable -- project library Vault (mote.pretty) extracted from the mote board; close S5.a
    43 footprints the schematic uses, extracted read-only from the reference
    board with KiCad 9.0.6 pcbnew (tools/fpextract.py, back-side parts
    flipped, nets cleared), registered as nickname Vault to match the board
    IDs; 118 bare footprint fields -> Vault:<name>. fpextract --verify: 0
    problems (negative-tested). Netlist identical except footprint fields.
    ERC 74/626 -> 74/508 (footprint-link warnings gone). D19.
    [BM_Mote_1_ADIN2111.kicad_sch, BM_Mote_1_Load.kicad_sch, BM_Mote_1_Master.kicad_sch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]
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2026-10-06 S5.b: QE round 1 APPROVED WITH NITS -- DEV_LOG nits fixed, CE0 back-power risk carried to S5.c; record report
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2026-10-06 S5.g: Vault footprint fixes -- PoDL insert pad numbered 1 + visible 3D model; stock 3D models on 7 footprints
    MP1-MP4 (Wurth 78614015360): SMD pad '' -> '1' so a new layout puts BM1/BM2
    nets on the inserts; embedded model opacity 0 -> 1. Stock KiCad models on
    C31, C19/C27, R15/R16, R1, R8, R22/R34/R40 footprints and R10's spare; all
    non-polarised, pads and models on x. U2/U3: no stock WLB0909-4 model.
    fpextract verify declares the pad fix (0 problems; 8 without it). D24.
    [fpextract.py, test_fpextract.py]
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2026-10-06 S5.g: QE round 1 -- revert the insert pad renumber (bus contact is a front copper ring; ask Sofar Q6), generic-height note; record report
    Library change is now 3D only: insert model opacity 0 -> 1 and stock models on
    7 footprints; pads identical to Sofar's board (fpextract verify 0, no exception).
    [fpextract.py, test_fpextract.py]
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2026-10-07 S5.h: QE round 1 APPROVED WITH NITS -- nits fixed; alternates capped at 3
    - R8 ALT NOTE shortened (Nick: at most 3 alternates per part; R8's 7 Sofar
    fields stay untouched, outside bom.csv)
    - J1 SOURCING back to the plan's "2x20" with the multiplication sign (N1);
    C22/C23 DK-figure drop declared in the changelog (N1)
    - S6 item: TP/FID/MTG rows in bom.csv for a JLC order (N2)
    - QE report recorded in docs/design-review/qe/S5.md; TRACKER, viewer, DEV_LOG
    [BM_Mote_1_Master.kicad_sch, BM_Mote_1_PowerMon.kicad_sch, bom.csv]
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2026-10-07 S5.i: QE round 1 APPROVED WITH NITS -- notes fixed; record report; S5 complete
    - F1: R21 group "ample LCSC stock"; C16 group stock figures stated
    - N1: C17/C26 note no longer claims the same part (thickness not confirmed)
    - N2: D26 marked "amended by D27"; N3: C21 note reworded
    - R8 datasheet URLs in bom_alternates.md
    - QE report in docs/design-review/qe/S5.md; TRACKER, viewer, DEV_LOG
    [BM_Mote_1_Load.kicad_sch, BM_Mote_1_Master.kicad_sch, BM_Mote_1_PoDL.kicad_sch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]
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2026-10-07 S6.b: ERC clean -- title block set, 18 errors excluded with reasons (D28)
    - Title block: rev AA on all sheets; PCBPARTNAME, PCBPARTNUMBER
    (PCB-000001-AA), PROJECTREVISION text variables (Nick)
    - 18 ERC exclusions, comment = reason, generated from
    docs/design-review/erc_justifications.csv by tools/ercexclude.py
    (+ tests); check.sh fails if an exclusion goes stale
    - ERC 531/27/504 -> 504/0/504; warnings item-for-item unchanged;
    netlist: revs + text variables only; netcheck 51/51, midwire 0
    - Docs: DESIGN D28 + ERC section, changelog, TRACKER, viewer, DEV_LOG
    [BM_Mote_1_ADIN2111.kicad_sch, BM_Mote_1_Load.kicad_sch, BM_Mote_1_Master.kicad_sch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]
2026-10-07 S6.b: QE round 1 fixes -- ercexclude fails on unjustified errors
    - F1: tools/ercexclude.py exits 1 on unjustified errors too (check.sh gate)
    - F2: MTG reason says grounding stays Nick's board decision
    - N1: two-item errors reported for manual exclusion, not keyed; new test
    - QE report (read from transcript) recorded in qe/S6.md
    [erc_justifications.csv]
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2026-10-07 S6.g round 2: QE nits + Nick's follow-ups (J5 with its switch, R11 note, headers)
    - J5 wired beside the Load Switch on the VBUS_OUT wire (mirrored; its own
    VBUS_OUT symbol removed); layout rule revised (DESIGN)
    - R11 note: open / fitted summary
    - Top-Level headers for J1 and the Load Switch block; Power sheet title
    removed (the converter headers replace it)
    - QE N1: ~{ADIN_P2_LED1} on a jogged stub, clear of pin 47's wire;
    N2: 1V8 header off the feed wire; N3: Sofar Q8 (licence) drafted
    - Same pin partition; ERC 0 errors / 494 warnings (+2 off-grid: the
    jogged stub on U1's off-grid pin 48); netcheck 51/51; midwire 0
    - QE report recorded; docs updated; schematic.pdf re-exported
    Co-Au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
    [BM_Mote_1_ADIN2111.kicad_sch, BM_Mote_1_Master.kicad_sch, BM_Mote_1_Power.kicad_sch]
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2026-10-08 S7.a: layout experiment brief (Fable port of the mote layout) + scoped rule exception (D31)
    experiments/fable_layout_01/: BRIEF.md (46 x 65 mm envelope, fixed placements, blocks to copy, routing rules,
    milestones, pass criteria), KICKOFF.md, tools/render_layers.py. CLAUDE.md / SPEC / TRACKER: an experiment may write its
    own board in experiments/<name>/ only, never merged. SPEC: insert-contact fact corrected (seven vias at r 3.0 mm).
    Sofar Q6 reworded, Q9-Q12 added. TRACKER: S6.g QE done; S7 section. Viewer synced. No schematic change:
    ERC 0/494, ercexclude 18/0/0/0, netcheck 51/51, midwire 0.
2026-10-08 S7.a round 2: QE round-1 fixes (F1-F5, N1-N4)
    F1 plane pullback 3.85-4.78 mm (SPEC, BRIEF). F2 BRIEF section 6 widths apply to new routing; copied copper keeps
    Sofar's widths. F3 notch copied from User.3 with the stated transform; edge exempt from H2's keep-out; listed for Nick.
    F4 render_layers.py strips hierarchical net prefixes. F5 D31: stacking header is the experiment's assumption, D6 stands.
    N1-N4 brief wording. QE report saved to docs/design-review/qe/S7.md.
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2026-10-08 fable layout 01 S7.b round 1: QE F1-F6/N1-N5 fixed in the pipeline; 3V3 closed, 1 open (J1 by design)
    - planes 0.25 + bus netclass 0.35; router hole map (no hole-to-hole / co-located vias)
    - stitching into the filled copper; dangling copper trimmed by DRC's own items (tools/dangling.py)
    - 3V3 escape via lookup fixed and routed; insert copper check; REPORT/LOG rewritten from fresh outputs
    - QE report saved to experiments/fable_layout_01/qe/S7b_round1.md
    [nereus_Pi_shield_ADIN2111.kicad_pcb]
2026-10-08 fable layout 01 S7.b round 2: Kelvin sense traces restored, bus rule as a .kicad_dru enforced by DRC, cross-class clearance in the router
    - SENSE region gains the Kelvin detour (Bottom); traces protected; pad-to-pad check in check_rules
    - bus nets 0.35 from non-bus nets (board rule); router kind map; power fallbacks keep 0.25
    - 1V8 at 0.15 from one bus-leg via, declared and excluded; plane nets pre-stitched
    - DRC 111 (110 Sofar + 1 declared), 0 copper-defect warnings, 1 open (J1 by design)
    - QE round-2 report saved to experiments/fable_layout_01/qe/S7b_round2.md
    [nereus_Pi_shield_ADIN2111.kicad_pcb]
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2026-10-08 fable layout 01 S7.b round 4: QE approved with nits; REPORT nits fixed (1V8 gap 0.225 mm; §1 tidy)
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2026-10-08 fable layout 1.a: BRIEF.md (missing from the first commit) with the JLCPCB DFM sweep as M3 and the north-edge LED question (Q6)
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2026-10-08 fable layout 1.a M1: placement per OPTIONS (blocks moved, LEDs north, JP1 top, strip re-ordered, B18 in the band); check_fixed 0 failures, 0 new courtyard overlaps; renders
    [nereus_Pi_shield_ADIN2111.kicad_pcb]
2026-10-08 fable layout 1.a M2: block copper, planes, routing — stopped short of the bar (3 open links, port-1 pair 1.2 mm over, 12 new-copper DRC errors); REPORT.md with the shortfall table
    Pipeline: snapshot restarts, planes before a pre-route trim of Sofar's lead-outs, exact distance-based router maps,
    pad-field escapes, no fallback classes, coupled-pair router with swap figures, bottom GND pour as the mote.
    M3 (JLCPCB DFM sweep) not started: Nick asked for a wind-down after ~2 h.
    [nereus_Pi_shield_ADIN2111.kicad_pcb]
2026-10-08 fable layout 1.a: QE round 1 report (CHANGES REQUESTED: F1 pair shorts hidden by the exclusion patterns, F2 INT fan-out trimmed); HANDOFF updated
2026-10-09 fable layout 1.a S2 (QE F1): pair emitter fixed — straight pad approach, figures with straight runs, board check of every pair, vias at the ends as the mote; T1/T2 exclusion patterns need the no-net 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
    [m4_route.py]
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2026-10-09 fable layout 1.a S2: M2 at its bar — fan-out first for U2/U3, exact via/hole checks, 5V_PI In3 patch, zone vias over other-layer copper; board + renders + review views; REPORT/LOG/HANDOFF
    DRC 111 errors all Sofar-copied with reasons, 1 unconnected (J1 no-connect), 0 dangling; pairs 9.46/8.80/17.98/18.62 mm; rules 0/0/0; blockcheck 0 missing.
    [nereus_Pi_shield_ADIN2111.kicad_pcb]
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2026-10-09 fable layout 1.a S2.b step 1: JLCPCB limits fetched, cited and encoded (tools/dfm.py, .kicad_pro, .kicad_dru); DFM.md on session 2's board: 22 pass / 9 fail, DRC 118 / 358
2026-10-09 fable layout 1.a S2.b step 2 (WIP): frame 49 x 68 (width west, height south), inserts moved, scripts parametrised, SPI-first order, router straightening, DFM fixes in the pipeline, placement variants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
    [m4_route.py]
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2026-10-09 fable layout 1.a S2.b: QE round 3 fixes (no via in a solder pad: router padvia map, DFM rows 29/30 measured, small-pad 0.2 mm stubs per BRIEF 6, nits) + Nick's decisions from the renders (20 W induct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
    [nereus_Pi_shield_ADIN2111.kicad_pcb]
2026-10-09 fable layout 1.a S2.b: QE round 4 APPROVED WITH NITS, nits fixed (back-layer footprint texts mirrored, DRC summary last on the saved file, DFM row 30 large-pad class listed, U11.1 stub and D31 notes)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
    [nereus_Pi_shield_ADIN2111.kicad_pcb]
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2026-10-15 S8.a: QE round 1 APPROVED WITH NITS, all fixed
    PCBA timeline uses Standard PCBA's >= 4-day floor (10/30 order -> 11/13-11/18+),
    "plan on 11/6-11/13" instead of "11/3 realistic", the PCBA order's dependency
    on Sofar's review (D27), China-time anchor, Y1 look-alike -6-K2Z-T3 (13
    siblings), consignment fee wording, page dates, checklist next step, demo
    uses main...HEAD, J5 SOURCING field ticketed (D32). Report:
    docs/design-review/qe/S8.md.
2026-10-15 S8.a: QE round 2 APPROVED WITH NITS, wording nits fixed
    In short: "Wed 11/18 or later"; 11/30 "holds only just" for an 11/6 PCBA
    order. Checklist: any rejected planned alternate needs global sourcing too.
    DEV_LOG files/next/round 2; Sources date note hedged. Round 2 report in
    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
2026-10-17 S8.a: QE date check fixes (pay window, Sofar 11/30 at risk in the planning case)
    To keep 10/30 possible, pay Sun 10/18 09:00 - Mon 10/19 09:00 PT (Monday in
    China); Monday daytime PT rules out 10/30. In the planning case (parts
    11/9-11/16) boards arrive about 11/24-12/3, so Sofar's 11/30 is at risk.
    Timeline 2 rows now 11/9, 11/16, 11/19. D32/TRACKER/checklist: "planned Mon
    10/19". Buy list unchanged.
2026-10-18 S8.a: record Nick's parts purchase (JLC order DOB202610190524705, $956.05)
    All 7 global-sourcing lines from Digi-Key (shortest lead, lowest price on
    JLC's list), with +2 spares; ready for assembly est. 2026-11-05, so the
    PCBA order is about 11/5 and boards about 11/19-11/24+. Why the total beats
    the estimate (U1 at JLC's $27.76 vs Digi-Key's $15.39). J5 not pre-bought:
    picked from JLC stock at the PCBA order. Purchase record, TRACKER,
    checklist, DEV_LOG.
2026-10-18 S8.a: PR #32 merged; next step is the PCBA order
    TRACKER records the merge (56e1e1a); DEV_LOG and the checklist no longer ask
    for #32's review, and note that the purchase record missed main because it
    was pushed after the merge.
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2026-11-10 nick_raw_routing step 0: fixes before routing (no copper changed)
    - 44 circles and the caption text move from Edge.Cuts to User.Drawings; J1's
    GND and PI_5V pins now reach their pours after the refill
    - MP1<->MP2 and MP3<->MP4 trade places so each insert pad matches the bus
    copper at that spot (Nick 2026-11-10: option 1)
    - MTG1-MTG4 removed; their symbols set to 'not on board' (Master sheet)
    - J5 onto the board at the west edge (119.6, 122.2), opening west; FID1/FID3
    to (118.5, 112.0); TP38 beside C58 at (136.65, 84.85)
    - GND north strip zone priority 0 -> 1
    - zones refilled
    DRC (board's own rules): errors 424 -> 324, open connections 77 -> 63
    (46 -> 41 nets), parity 0. ERC unchanged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
2026-11-10 nick_raw_routing: JLC rule values and stackup
    Settings only, in one commit so it can be reverted on its own (Nick 2026-11-10):
    board constraints (.kicad_pro), two custom rules for through-hole pads
    (.kicad_dru), stackup JLC06161H-3313 + ENIG + 0.1 mm mask web (.kicad_pcb setup
    block). Old and new values with sources: docs/design-review/jlc_rules_2026-11.md
    DRC on the same copper: errors 324 -> 134, open connections 63, parity 0.
    No track, via, footprint or zone changed.
2026-11-10 nick_raw_routing step 0b: J5 becomes two wire pads; J6, fiducials and TP38 placed (no copper changed)
    Nick 2026-11-10:
    - J5: the JST GH connector is replaced by two through-hole wire pads (new
    footprint nereus:WirePads_1x02_P3.81mm_Oval4.2x2.6mm_Drill1.3mm), pad 1
    VBUS_OUT at (119.0, 120.2), pad 2 GND 3.81 mm south, at the west edge.
    Symbol: footprint, value 'Wire pads', not in BOM or position files, part
    fields cleared (Master sheet)
    - J6 one pitch west (x 142.40) and FID1/FID3 at (123.9, 128.6), as on Nick's
    reload_old_mote 7cc5f04; the SPI gap between J6 and J2 is now 6.2 mm
    - TP38 to (133.56, 82.65): J6's west pad took its earlier spot
    DRC (JLC rules): 134 errors (unchanged),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
2026-11-10 nick_raw_routing step 1: ADIN SPI routed on the inner layers, no new via
    SCK and CS on Internal 2, MOSI and MISO on Internal 1, each from its J1 pin
    through J2's first two pin gaps to Sofar's existing via; 0.2 mm tracks.
    J1 pin to U1 pad: SCK 32.7 mm, CS 36.4 mm, MOSI 39.5 mm, MISO 34 mm.
    Also: the PI_3V3 branch on Internal 2 along y 89.5 is removed (it crossed SCK
    and CS; J2 pins 9/11/13 get PI_3V3 back in step 4), the dead top stubs of CS,
    SCK and MOSI are removed, and MOSI's via goes (both tracks meet on Internal 1).
    DRC (JLC rules): 134 errors (unchanged, none on the new copper), open
    connections 63 -> 60 on 38 nets, parity 0. Zones refilled.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

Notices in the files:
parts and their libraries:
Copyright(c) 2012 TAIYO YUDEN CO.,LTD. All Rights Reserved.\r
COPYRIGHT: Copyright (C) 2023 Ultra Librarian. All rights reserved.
